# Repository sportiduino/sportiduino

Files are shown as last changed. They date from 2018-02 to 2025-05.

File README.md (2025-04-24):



Sportiduino logo

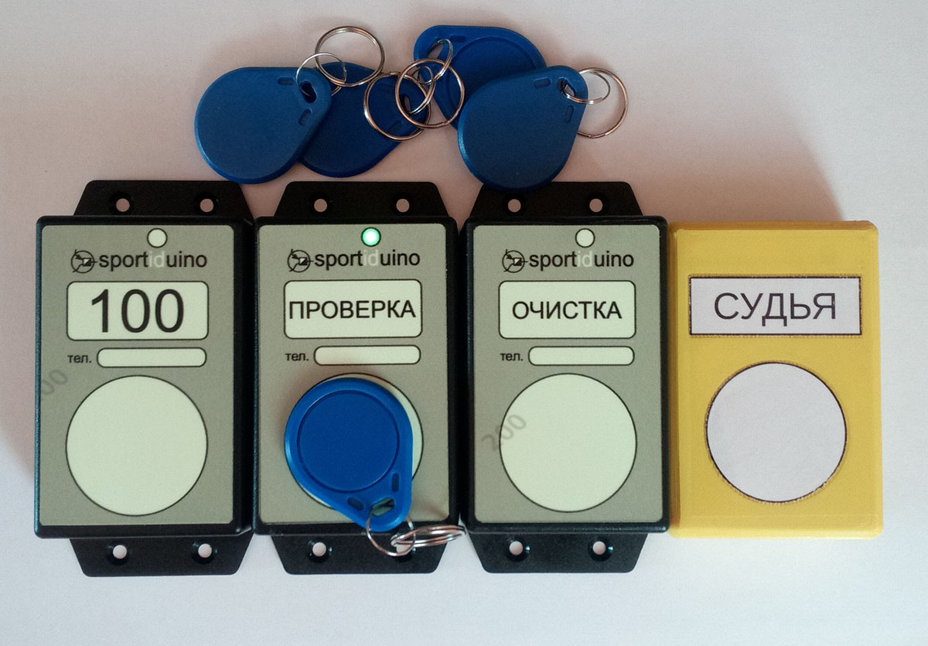
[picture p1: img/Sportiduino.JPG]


[Перейти на русский язык](README.ru.md)

The inexpensive electronic timing system for orienteering, rogaining events, adventure races, trail running and etc.
This resository contains hardware and firmware parts of the timing system.
Links to data processing software are placed [below](#software).

[Download latest release](https://github.com/sportiduino/sportiduino/releases/latest)

[Manual](/docs/en.md)

This project is open and free. Anyone can reproduce it yourself. Just follow the instructions from the Manual.

This development is a hobby.
No guarantees are given, various kinds of problems are possible during reproduction.
Support is also not guaranteed. So, act at your own risk. 

## Version

The version consists of three numbers. The first number indicates the version of the hardware.
If any changes are made to the circuit or to the PCB, this number is incremented by 1.

The second and third numbers indicates the version of the firmware.
If any new function is added to the firmware, the second number is incremented by 1.
If the firmware just fixes bugs, the third number in the version is incremented by 1.
When a new version of the firmware is released with new functions, the third number is reset to 0.

The base station and the master station have their own versions. The release version is the largest of these two numbers.

**The current base station version is 3.11.0**

**The current master station version is 1.11.0**

[Changelog](/CHANGELOG.md)

Build the firmware of the base station with `#define HW_VERS 1` to install the firmware vX.6.X or greater on the PCB v1 or v2.

## Reporting Issues and Asking for Help

Issues and suggested improvements can be posted on [Issues](https://github.com/sportiduino/sportiduino/issues) page.
Please make sure you provide all relevant information about your problem or idea.

We also have our [Telegram chat](https://t.me/Sportiduino) where you can ask any questions about the system.

## Contributing

You can contribute by writing code.
We welcome software for working with the system on a PC via USB and on Android via Bluetooth or NFC.
The data transfer protocol and commands are described in the [Manual](/docs/en/MasterStation.md).
With pleasure we will add a link to your developments working with Sportiduino.

Pull requests, creation of forks, developing any new ideas are welcome.

You can also help by improving documentation and its translation.

# Parts of the system

## Cards

The system uses cards NTAG213/215/216.
Memory of these cards can keep 32, 120 and 216 marks, respectively.

Also it is possible to use Mifare Classic 1K and 4K cards.
Cards 1K are also cheap and come bundled with the RC522 module.
The memory of these chips is enough for 42 marks. They work a little slower than NTAG.

The system automatically detects the type of used cards.

[Read more](/docs/en/Cards.md)

## Base stations

The main components of the station are the ATmega328P-AU microcontroller and the MFRC522 module,
which operates at a frequency of 13.56 MHz, real-time clock DS3231SN.
All powered by 3 AA batteries through the MCP1700T-33 stabilizer.
The capacity of the kit of three alkaline AA batteries should be enough for a year of active use.
Tested at ambient temperatures from -20 to +50 degrees Celcius.

[Read more](/docs/en/BaseStation.md)

## Master station

With the master station you can read and write tags and configure base stations.
It is simpler than the base station.
It consists of Arduino Nano, RFID module, LED and buzzer.
It connects with a PC via USB. 

[Read more](/docs/en/MasterStation.md)

There is also a wireless station with the Bluetooth module. 

## Software

### Prepare cards and stations

#### [SportiduinoPQ](https://github.com/sportiduino/SportiduinoPQ)

PC software (Windows or Linux).

It is written on Python, based on PyQt5 and [SportiduinoPython module](https://github.com/sportiduino/sportiduinoPython).

#### [SportiduinoApp](https://github.com/sportiduino/sportiduinoapp)

Android application for smartphones with NFC.

### For event management

Reading cards is implemented in [SportOrg](https://github.com/sportorg/pysport) and [SportOrgPlus](https://github.com/sembruk/sportorg-plus).

Also you can use software for SPORTident (MeOS, WinOrient, Rogain Manager etc).

***********

This system and its variants have been used in Russia at a number of events
up to approx. 1400 participants and approx. 70 check points.

***********

Available from:  https://github.com/sportiduino/sportiduino

License:         [GNU GPLv3](/LICENSE)

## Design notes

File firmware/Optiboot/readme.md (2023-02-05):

## Building Optiboot for Base station

```sh
cd <Optiboot-local-repo>/optiboot/bootloaders/optiboot

# Bootloader without LED flashes
make AVR_FREQ=8000000L BAUD_RATE=38400 LED_START_FLASHES=0 LED=D4 atmega328
mv optiboot_atmega328.hex optiboot_38400_sportiduino.hex

# Bootloader with LED starting flashes
make AVR_FREQ=8000000L BAUD_RATE=38400 LED_START_FLASHES=3 LED=D4 atmega328
mv optiboot_atmega328.hex optiboot8_38400_sportiduino_led.hex
```

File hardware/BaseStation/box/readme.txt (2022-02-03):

sportiduino-base.FCStd is FreeCAD 3D model of the Base station box for PCB v3b with Li-pol battery and 5.5x2.1mm DC power jack.

Файл sportiduino-base.FCStd — FreeCAD 3D модель корпуса базовой станции для платы v3b с литий-полимерным аккумулятором и разъёмом зарядки 5,5х2,1 мм.

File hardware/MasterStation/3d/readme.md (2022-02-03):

В папке print содержатся 3D-модели корпуса для USB судейской станции.
Данные модели предназначены для печати на 3D-принтере.
Корпус рассчитан на судейскую станцию, собранную без печатной платы.
Arduino Nano подключается к модулю RC522 проводом типа МГТФ-0.12.
Тем же проводом согласно схеме к Arduino Nano подключаются светодиод и буззер.
При сборке станции Arduino Nano крепится внутри корпуса термоклеем на соответствующие площадки.
Модуль RC522 плотно прижимается стойками корпуса и дополнительного крепления не требует. Крышки корпуса после сборки скручиваются саморезами 3.5х16.

В папке src находится проект корпуса в формате opensource редактора FreeCad.

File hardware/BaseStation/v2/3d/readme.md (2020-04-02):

This 3d-model is only to understand the placement of electronics inside a box. Use FreeCad to view. In print catalog there is a 3d model of a substrate for electronics. You can print it and use in an assembly process to fix electronics inside a box.

3д-модель сделана в опен-сорс редакторе FreeCad. Данная 3д-модель служит только для понимания расположения электроники в корпусе G1020BF и понимания как используется пространство корпуса. Эта модель не предназначена для печати на 3д-принтере. Но в папке print содержится файл подложки под модуль RC522. Эта деталь печатается на 3д-принтере. Затем она используется при сборке. Сверху на эту деталь термоклеем крепится модуль RC522. Далее эта подложка с модулем приклеивается внутри корпуса. Конструкция получается более-менее разборной. В случае если надо снять электронику, то термоклей плавится паяльным феном и электроника легко достаётся из корпуса.

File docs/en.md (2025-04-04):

# Sportiduino documentation

This project is devoted to building an electronic timing system for orienteering and similar outdoor sports events on Arduino.

The English translation is rough, there may be some unclear moments. Create an [Issue](https://github.com/sportiduino/sportiduino/issues) if you have any questions.

* [User manual](en/UserManual.md)
* [Cards](en/Cards.md)
* [Base station](en/BaseStation.md)
* [Master station](en/MasterStation.md)
* [Wireless master station](en/WirelessMasterStation.md)
* [Equipment and materials](en/Equipment.md)
* [Arduino IDE setup](en/ArduinoIde.md)
* [Base station assembly](en/BaseStationAssembly.md)
* [Master station assembly](en/MasterStationAssembly.md)
* [Software](en/DataProcessing.md)

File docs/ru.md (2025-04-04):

# Документация Sportiduino

Этот проект посвящен построению системы электронной отметки для спортивного и туристического ориентирования с помощью Arduino.

* [Руководство пользователя](ru/UserManual.md)
* [Чипы отметки](ru/Cards.md)
* [Станция отметки](ru/BaseStation.md)
* [Станция сопряжения](ru/MasterStation.md)
* [Беспроводная станция сопряжения](ru/WirelessMasterStation.md)
* [Оборудование и материалы для сборки](ru/Equipment.md)
* [Настройка Arduino IDE](ru/ArduinoIde.md)
* [Сборка станции отметки](ru/BaseStationAssembly.md)
* [Сборка станции сопряжения](ru/MasterStationAssembly.md)
* [Программы для работы с системой отметки](ru/DataProcessing.md)

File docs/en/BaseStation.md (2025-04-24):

# Base station

### Scheme

The main components of the station: microcontroller ATmega328P-AU, RFID module RC522, real-time clock DS3231SN.
It is powered by 3 x AA batteries via the MCP1700T-33 linear regulator.
The scheme and PCB are made in KiCad program.

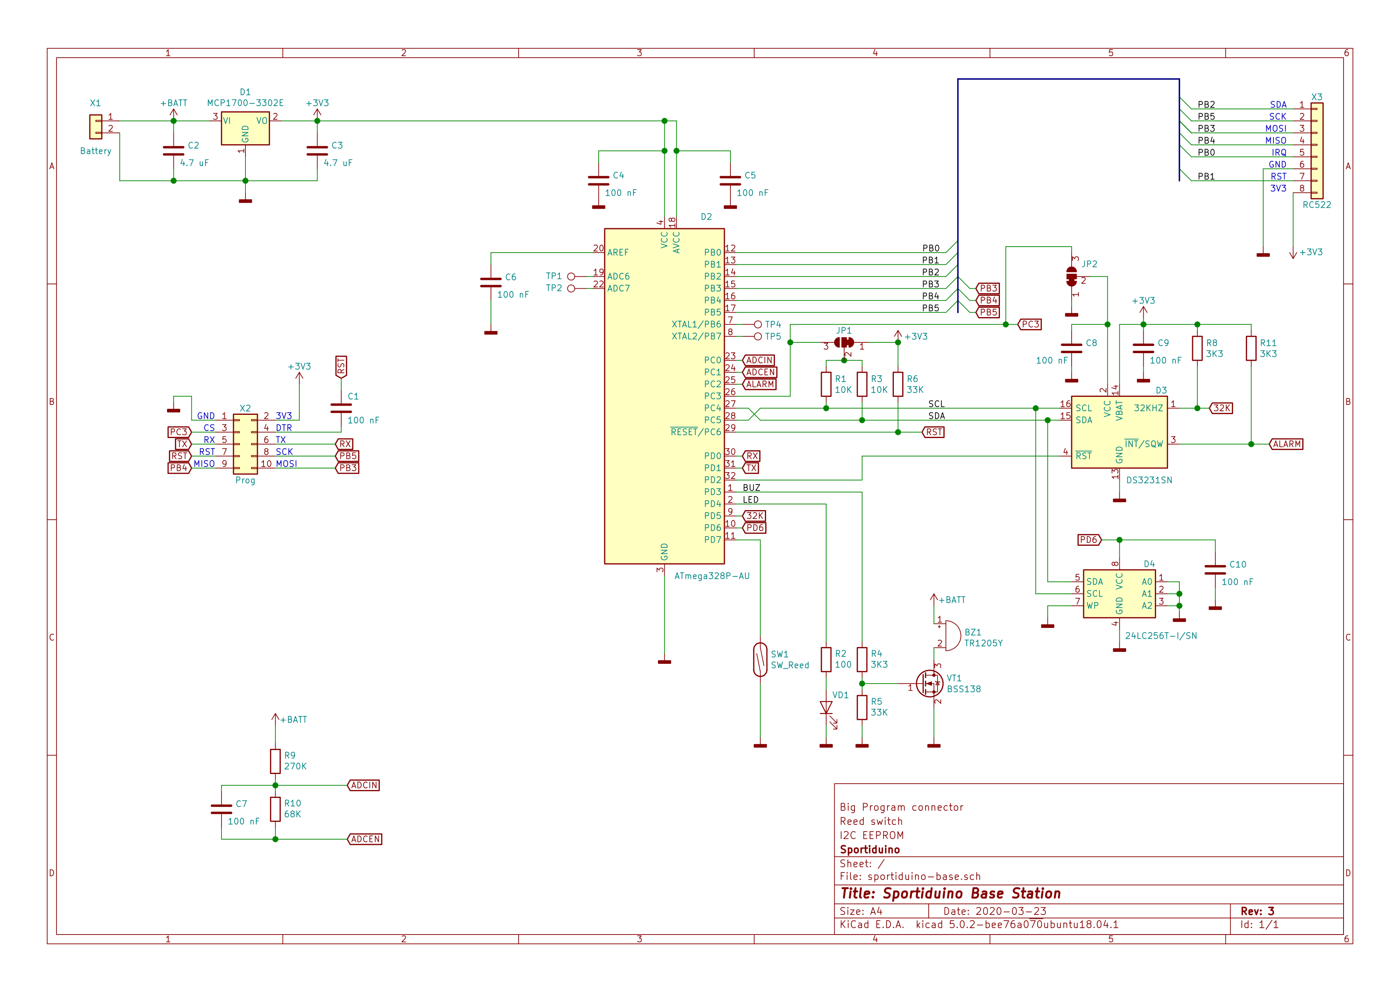
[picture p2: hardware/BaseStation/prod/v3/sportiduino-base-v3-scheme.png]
Scheme


The components are mounted on a printed circuit board.
Connection with an RFID board is via soldered connection with a pin connector.
You can order the manufacture of PCB in China (e.g. [JLCPCB](https://jlcpcb.com/)).

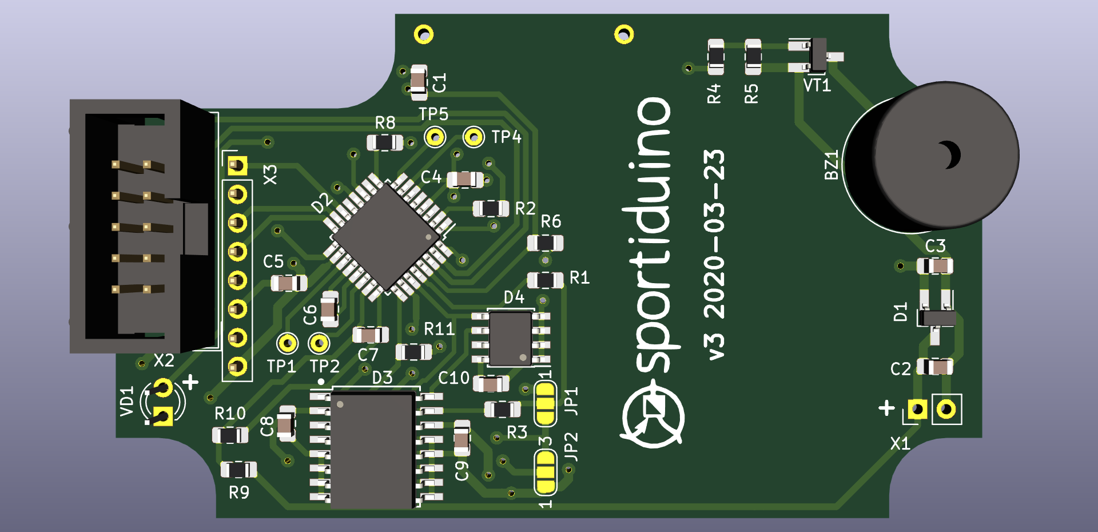
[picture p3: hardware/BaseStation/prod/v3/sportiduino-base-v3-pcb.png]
PCB


To upload firmware to the station one needs another Arduino with ArduinoAsIsp firmware or any 
AVR microcontroller programming device such as Pickit2.

The outer shell is G1020BF.
Moisture protection is achieved by covering all the PCB electronics with a liquid silicone compound.

About the assembly and the initial setting of the station written in [the assembly manual](BaseStationAssembly.md).

### Consumption

By default the station starts in Wait (standby) mode.
In this case, the cards are read once per second.
Total consumption is up to 0.5 mA.
Fully charged batteries last for 160 days.
While RFID module is powered up to 20 mA (up to 40 mA during the read-write) is consumed.

After the first card is brought (by the station installer or the first athlete),
the station goes into the Active mode.
By default after 2 hours of inactivity it returns to the Wait mode.
The time in Active mode can be changed using the Config card.

In the Active mode standby occurs every 250 ms.
Thus during operation an integral consumption of about 1.7 mA can be expected.
Fully charged batteries last for 45 days of continuous operation.

To reduce consumption while waiting for the competition, the Sleep mode is implemented.
Consumption is about 15 µA.
Fully charged batteries last for 5 years.
To achieve this, on the RFID board the LED and pull-up resistors must be accurately removed (see [Base Station Assembly](BaseStationAssembly.md)).

### Initial setting

Station is configured by Master cards (any card can be written as a Master card) or by USB-to-TTL converter.

[More details in the User manual](UserManual.md).

### Station operation algorithm

After power on or reboot the station checks the internal clock setup.
If it is incorrect, it beeps accordingly (see below).
Then it loads from EEPROM the settings (station number, password, etc.).
Then the battery charge is checked.
LED is powered for 3 seconds.
If the charge level is ok or low, it beeps accordingly (see below).
After the init stage the station enters the Wait mode.
In the Wait mode the station wakes up every second and searches for a card (RFID tag).
When a card is found, it goes into Active mode with a card polling every 0.25 seconds.
At the card punch, the station reads the first card block, where the card number or the master card code is stored. 
If it is a master card, its instruction is being processed.
If the card is normal, then the last recorded page is searched for (using binary search) 
and the station number is read from the last record.
If the station number is the same, the station beeps twice.
If the number is different, then the punch is written to the next block after the recorded one.
If successful, the station signal (a beep and a LED blink),
and also records the fact of the punch in the internal EEPROM memory of the station (into the bit corresponding to the card number).
If the station PCB has EEPROM IC, the punch is written in one.

Search and record time depend on the card volume:

- 32 marks - 60 .. 120 ms
- 64 marks - 60 .. 140 ms
- 120 marks - 60 .. 160 ms
- 220 marks - 60 .. 180 ms

Factor in the Wait or Active mode delay - up to 1000 or 250 ms accordingly.

A Fast Punch mode exists.
The last station number is always recorded into the sixth page on a card.
It reduced the card lifetime.

During operation, a watch-dog is running which restarts the station should the system hang up.

### Station configuration 

Using the Config master card, you can set:

- the duration of the Active mode,
- Start as Check mode,
- checking the initialization time of the cards,
- Fast Punch mode,
- antenna gain,
- password.

With Start as Check mode, the Start station (number 240) will only accept cleared cards.

By default all special modes are disabled, the password is 0-0-0.

### The Clearing station

This station clears cards.
To set up the station as Clearing station, you need to specify station number 249.
This station clears all pages of the card except the page with the card number.
The new time is recorded in the initialization time page
which is used to calculate the results, so it is important that the time at the station is correct.

When the card is presented, the LED lights up on the station and blinks during the cleaning (about 4 seconds).
If the cleaning is successful, the station beeps, the LED goes out, the card needs to be removed.
If there was no signal, the cleaning was not completed, you need to repeat the procedure.

### The Check station

To set up the station as the Check station, you need to specify station number 248.
This station does not write any data to the card but only checks it.
If the card contains punches or the time of initialization exceeds the time at the station for more than a month
the station does not beep.
If everything is ok then it beeps once.
The time of checking is approximately the same as the time of punching, so participants can practice the punching at this station.

### Password system

A password system is used to protect against unauthorized resetting of installed stations.

The password consists of three numbers from 0 to 255 (three bytes).
The default password is 0-0-0.
All master cards work only with the correct password in the first data block.
A Config master card is used to send the password to the base station.
The password is stored in the EEPROM memory.

### Signals

Errors:

| Repetitions | Duration in ms | Meaning |
| --- | --- | --- |
| 2 |  80 | DS3231 broken or not connected
| 3 | 100 | The clock is not right
| 4 | 100 | The master card password is wrong
| 5 | 100 | The battery is low
| 4 |  50 | Unknown master card
| 2 | 250 | Master card error
| 2 | 250 | Serial error

Normal behavior:

| Repetitions | Duration in ms | Meaning |
| --- | --- | --- |
| 1 | 1000 | Battery is ok
| 1 |  500 | Card punching, clearing or checking is ok
| 2 |  250 | Card is already punched
| 1 |  250 | Master card read
| 4 |  500 | Sleep mode is enabled
| 1 |  250 | Serial is ok

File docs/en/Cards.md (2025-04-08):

# Cards

The system supports these cards (RFID tags):

- [Mifare Ultralight C](http://www.nxp.com/documents/data_sheet/MF0ICU2.pdf) for 36 punches
- [Mifare Classic 1K](https://www.nxp.com/docs/en/data-sheet/MF1S50YYX_V1.pdf) for 42 punches
- [Mifare Classic 4K](https://www.nxp.com/docs/en/data-sheet/MF1S70YYX_V1.pdf) for 90 punches 
- [NTAG213/215/216](https://www.nxp.com/docs/en/data-sheet/NTAG213_215_216.pdf) for 32/120/216 punches

Card type is detected automatically.
One station can work with various cards simultaneously
without any changes in firmware or hardware.

One is advised to use NTAG213/215/216.

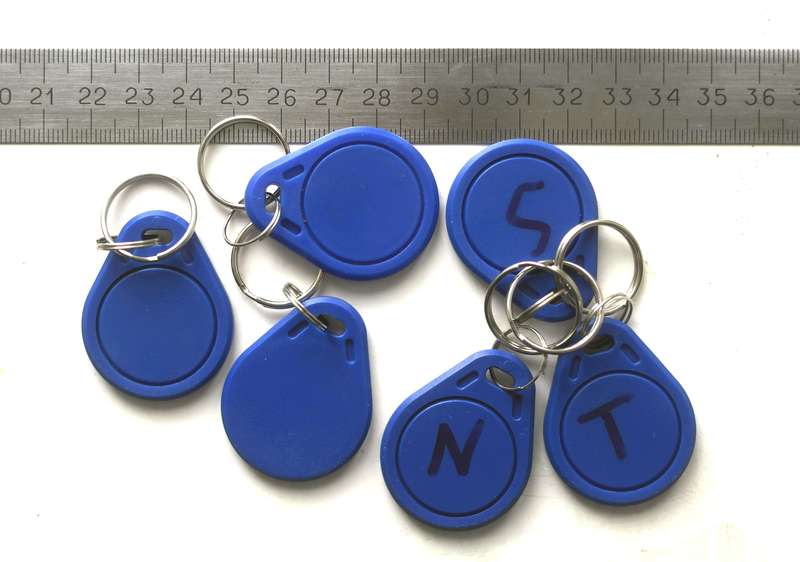
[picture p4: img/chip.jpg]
Key fobs tags


**Important!**
For reliable operation with these cards which have a small antenna area
it is necessary to replace the inductors with the more powerful ones in the RFID RC522 module (see [Base station assembly](BaseStationAssembly.md)).

Mifare Classic 1K cards come bundled with the RC522 module.
The memory of these cards is enough for 42 marks. They work a little slower than NTAG. 
Only a quarter of the Mifare cards memory is used due to page size of 16 bytes (compared with 4 bytes for NTAG).
With more dense recording there is a risk of data loss.
The structure of the record is similar to NTAG.

The memory of the NTAG213/215/216 cards is structurally divided into 45/135/231 pages, each containing 4 bytes.
The first 4 pages contain UID and other service information.
Also the service information is contained in the last 5 pages.
Thus, 36/126/222 pages are available.

### The structure of the records

Page numbers start from 0.
Pages 4-7 are reserved, the rest of the pages are for the punches.
In the 4th page, the first two bytes contain the programmable card number.
In the 4th byte, the station firmware version (e.g. 8 for v3.8.0, 9 for v3.9.1).
On the 5th page, the initialization time of the card in Unixtime UTC format.
Then two pages are reserved.
Each station punch takes a separate page,
the first byte of which contains the station number, in the remaining three bytes - the lower bytes of the current time in Unixtime UTC.
Time is then restored using the initialization time recorded in the 5th page.

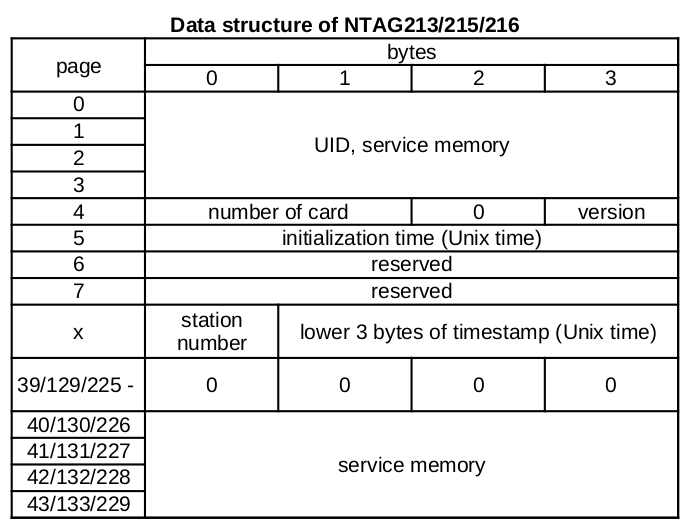
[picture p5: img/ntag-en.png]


Master cards which set up the stations have a different structure.
The station recognizes them by the number 255, recorded in the 3rd byte of the 4th page.
There are 8 different master cards: Time, Number, Sleep, Config, Password, Auth password, Backup and State.
Their structure is below.

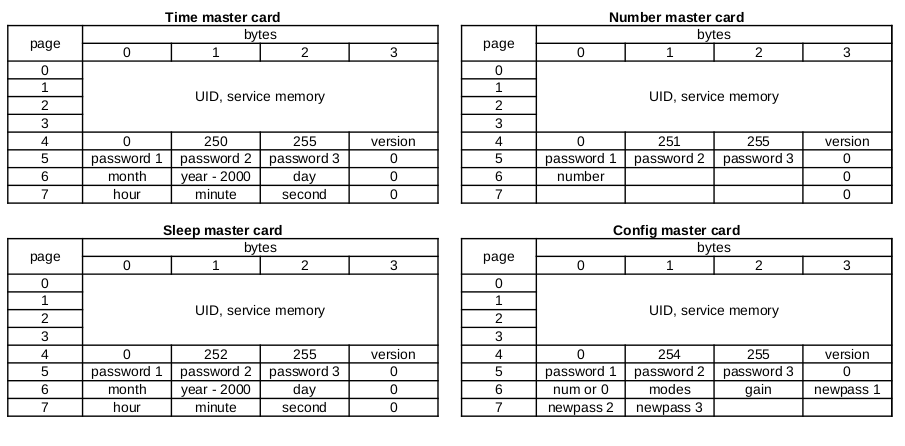
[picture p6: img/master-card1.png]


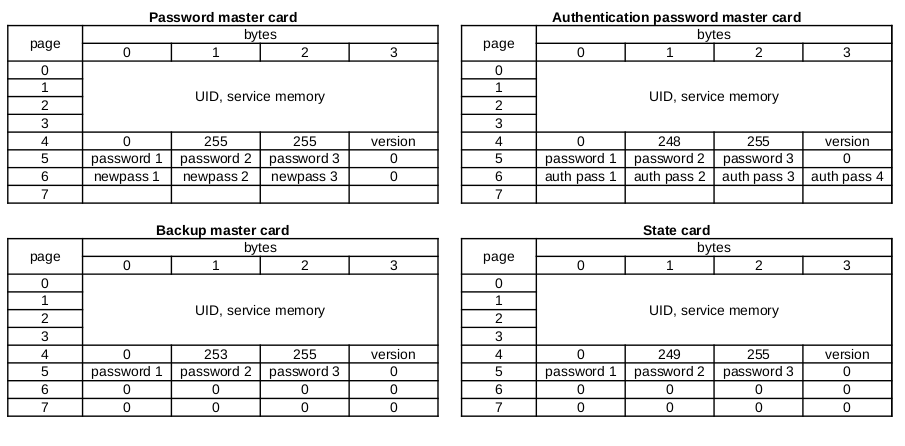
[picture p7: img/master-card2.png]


#### Time Master Card

Writes the date and time to the station (in real time clock).

This card is one-shot.
After reading information from the card, page 4 is erased on it
to prevent accidental reuse.

#### Number Master Card

Writes the number to the station if it is greater than 0.

This card is one-shot.

#### Sleep Master Card

Writes the date and time of waking up to the station and puts it into Sleep mode.
When waking up by timer, the station goes into active mode.

This card is reusable.

#### Config Master Card

Writes the number (if > 0), settings byte, antenna gain (if ≥ 2 and ≤ 7) and new password to the station.

This card is reusable.

#### Password Master Card

Writes the new password to the station.

This card is reusable.

#### Authentication Password Master Card

Writes the password (4 bytes) for Ntag authentication to the station.

This card is reusable.

#### Backup Master Card

The station writes a log of punches to this card.
If the station saves a log with time stamps, then a log for the last 12 days is recorded in ascending order of card numbers.
Since the capacity of the card may not be enough to record the entire time-stamped log.
Then for a complete reading of the log, it is necessary to attach the card to the station several times with an intermediate reading of the contents of the card.

This card is reusable.

#### State Master Card

The station writes to this card:
- firmware version number (3 bytes) to page 4;
- station number, settings byte, antenna gain in page 5;
- battery voltage (mV / 20, 1 byte) and mode (1 byte) in page 6;
- current time in Unix format to page 7;
- wake-up time in Unix format to page 8;

This card is reusable.

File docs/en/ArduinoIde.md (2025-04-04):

# Arduino IDE setup

### Setup location for sketches and url for boards manager

In the menu `Arduino IDE->Preferences` change sketchbook location to `[/path/to/project]/firmware`.

Then add new additional boards manager url
`https://raw.githubusercontent.com/sportiduino/BoardsManagerFiles/master/package_sportiduino_index.json`

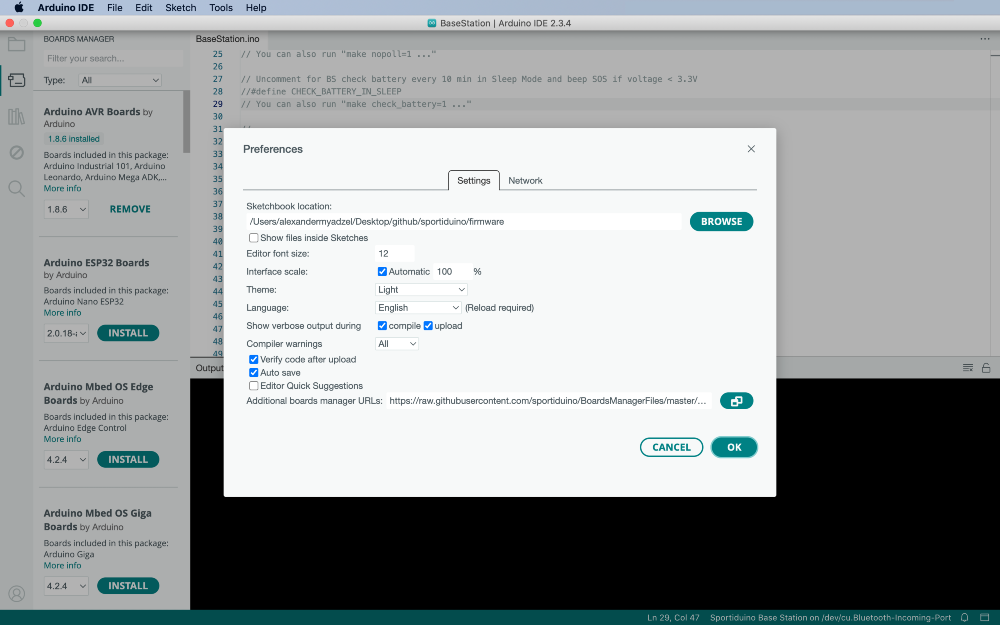
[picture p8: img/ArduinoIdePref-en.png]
Preferences


### Install boards

Select `Boards Manager` in the left panel and type `sportiduino` in the search bar.
Click `Install`.

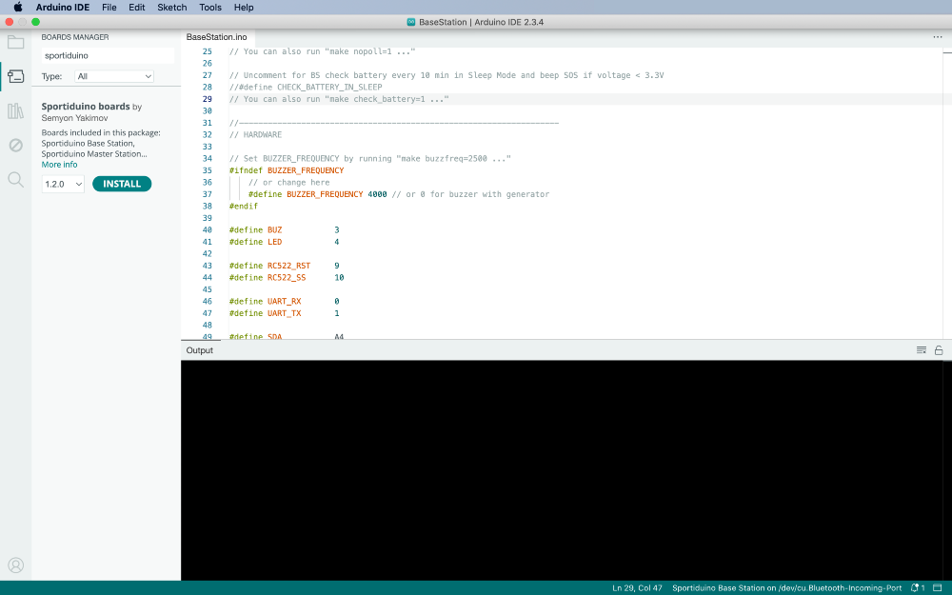
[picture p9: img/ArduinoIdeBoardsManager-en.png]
Boards manager


### Select board to upload firmware

In the menu `Tools` for the base station, select the "Sportiduino Base Station" board.
For the master station, select the "Sportiduino Master Station (Arduino Nano)" board.

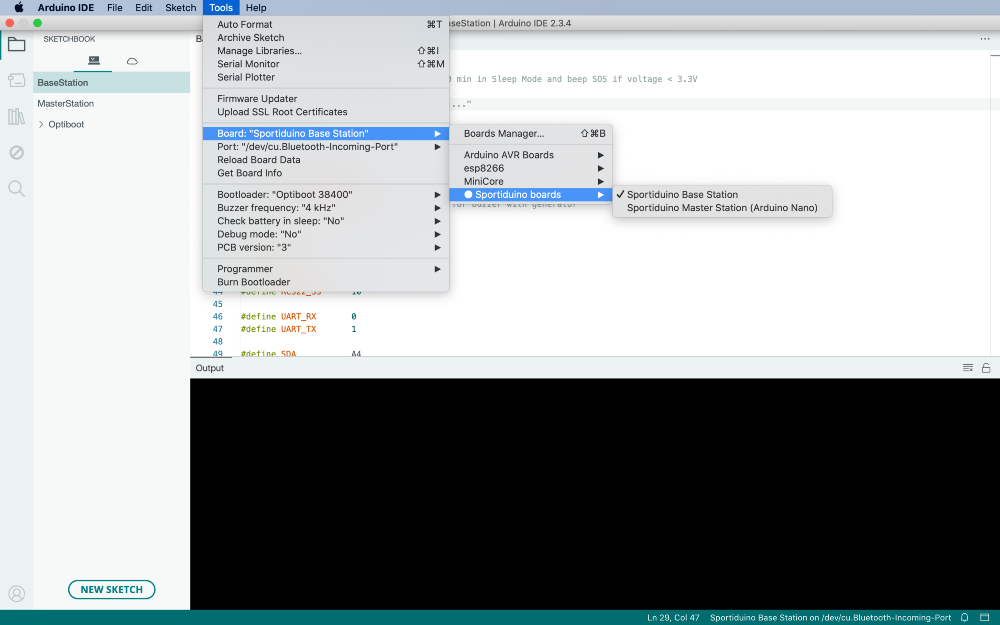
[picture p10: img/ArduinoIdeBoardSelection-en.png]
Board selection


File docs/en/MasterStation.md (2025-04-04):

# Master station

The Master station can be made in various boxes.

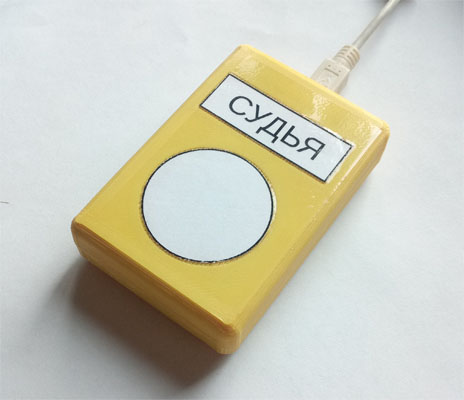
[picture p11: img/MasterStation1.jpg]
Master station in the box made on a 3D printer


or

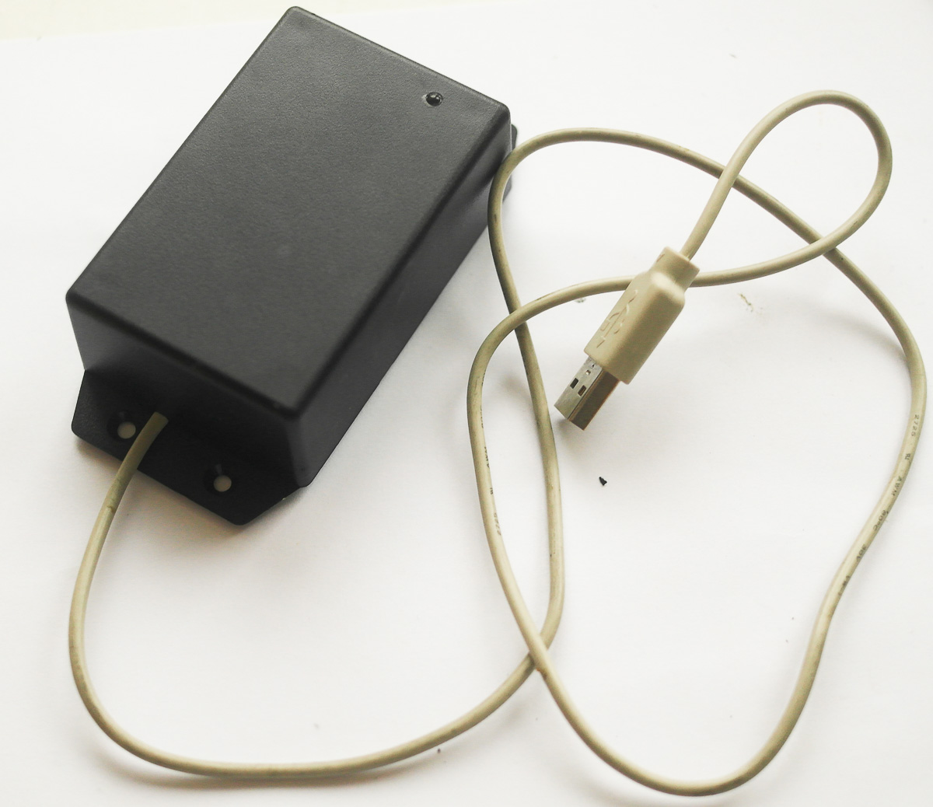
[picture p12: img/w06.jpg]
Master station in the G1020BF box


The circuit and board are available in Upverter ([variant 1](https://upverter.com/AlexanderVolikov/3fc0efdb2586988d/Sportiduino-reading-stantion/) or [variant 2](https://upverter.com/design/syakimov/4f7ec0e2d3b9c4e9/sportiduino-master-station/)).

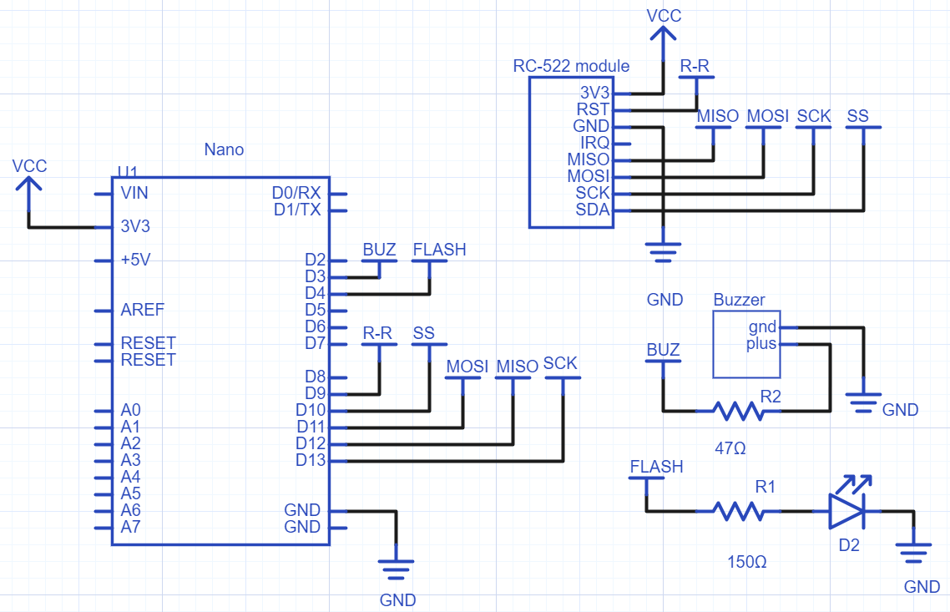
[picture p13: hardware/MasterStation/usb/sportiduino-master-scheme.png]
Scheme


All components of the circuit can be placed on a PCB or soldered to the Arduino by a ordinary wires.
The electronics of the master station can be placed in the Gainta G1020BF box or in a specially designed box that can be printed on a 3D printer.
[More about the assembly](MasterStationAssembly.md).

The station is connected to the computer using a USB port.
The Arduino Nano already has a built-in Serial-to-USB converter, so no additional converters are needed.
The station will be displayed in the connected devices as a COM port or /dev/ttyUSBx in Linux.

### Serial data protocol

The transmission of information between PC and Master Station occurs sequentially by sending up to 32-byte packets.

| | Value | Byte address in the packet |
| --- | --- | --- |
| Start | 0xFE | 0 |
| Function | | 1 |
| The length of the data or packet number + 0x1E | | 2 |
| Data array | | 3..x (x<31) |
| Checksum | x+1 |

The packet starts with byte 0xFE.

The command is specified by the byte with address 1.
Then in byte 2 the data length follows, if the transmitted packet is the last packet or its number + 30, if multipacket transmission is in progress.

Next comes an array of transmitted data up to 28 bytes.

At the end of the packet contains a checksum: the remainder of dividing by 256 the sum of bytes 1..x.
Commands pass only with the correct value of the checksum and start byte.

#### List of commands sent to the station

| Code | Command | Length | Array of data bytes (offset) |
| --- | --- | --- | --- |
| 0x41 | Write the time to the master card | 6 | year-2000 (0), month (1), day (2), hour (3), minute (4), second (5)
| 0x42 | Write the station number to the master card | 1 | number (0)
| 0x44 | Initialize the card | 14 | card number (0-1), current time (2-5), information in 6-7 pages (6-13)
| 0x45 | Write 6,7 pages | 8 | 6-7 pages data (0-7)
| 0x46 | Ask version of the master station | 0 |
| 0x47 | Create Backup master card | 0 |
| 0x48 | Read the Backup master card | 0 |
| 0x4A | Write settings to the master station | 1 | antenna gain (0)
| 0x4B | Read the card | 0 |
| 0x4C | Read raw data from the card | 0 |
| 0x4D | Read settings of the master station | 0 |
| 0x4E | Write a Sleep master card | 6 | year-2000 (0), month (1), day (2), hour (3), minute (4), second (5)
| 0x4F | Set the current password | 3 | password (0-2)
| 0x50 | Create State master card | 0 |
| 0x51 | Read card type | 0 |
| 0x58 | Beep error (three short beeps) | 0 |
| 0x59 | Beep OK (long beep) | 0 |
| 0x5A | Create Config master card | 6 | base station configuration

#### List of station responses

| Code | Command | Length | Array of data bytes (offset) |
| --- | --- | --- | --- |
| 0x61 | Data from Backup master card | N packages | (the first packet is the station number (0)), the number of the marked card 1 (1-2), the number of the marked card 2 (3-4), etc.
| 0x63 | Card punches data | N packages | (the first package - the card number (0-1), information in the 6-7 pages of the card (2-9),) number CP0 (10), time CP0 (11-14), number CP1 (15), time CP1 (16-19), etc.
| 0x65 | Raw data from the card | N packets | page number 4 (0), page 4 bytes (1-4), page number 5 (5), page bytes 5 (6-9), etc.
| 0x66 | Version of the master station firmware | 3 | version (0-2)
| 0x67 | Setting of the master station | 1 | antenna gain (0)
| 0x70 | Card type | 1 | card type(0)
| 0x78 | Error | 2 | error code (0), card type (1)
| 0x79 | OK | 1 | card type (0)

#### Error Codes

| Code | Error |
| --- | --- |
| 0x01 | Serial communication error
| 0x02 | Card writing error
| 0x03 | Card reading error
| 0x04 | EEPROM reading error
| 0x05 | Card not found
| 0x06 | Unknown command

### SPORTident emulation

Firmware of Master station v1.8.0 or greater has support of reading card by the SPORTident data transfer protocol.
All RFID tags are read as SI-Card (192 punch mode).
Communication tested with SPORTident Reader, Rogain Manager, SportOrg, MeOS 3.8.1277 and WinOrient 2.0a (2014 - 2020) software.

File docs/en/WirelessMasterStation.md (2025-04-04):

# Wireless master station

A wireless master station is implemented in the system. Schematic diagram and board is in [Upverter](https://upverter.com/AlexanderVolikov/55b140a993222192/Sportiduino-BTstantion/).

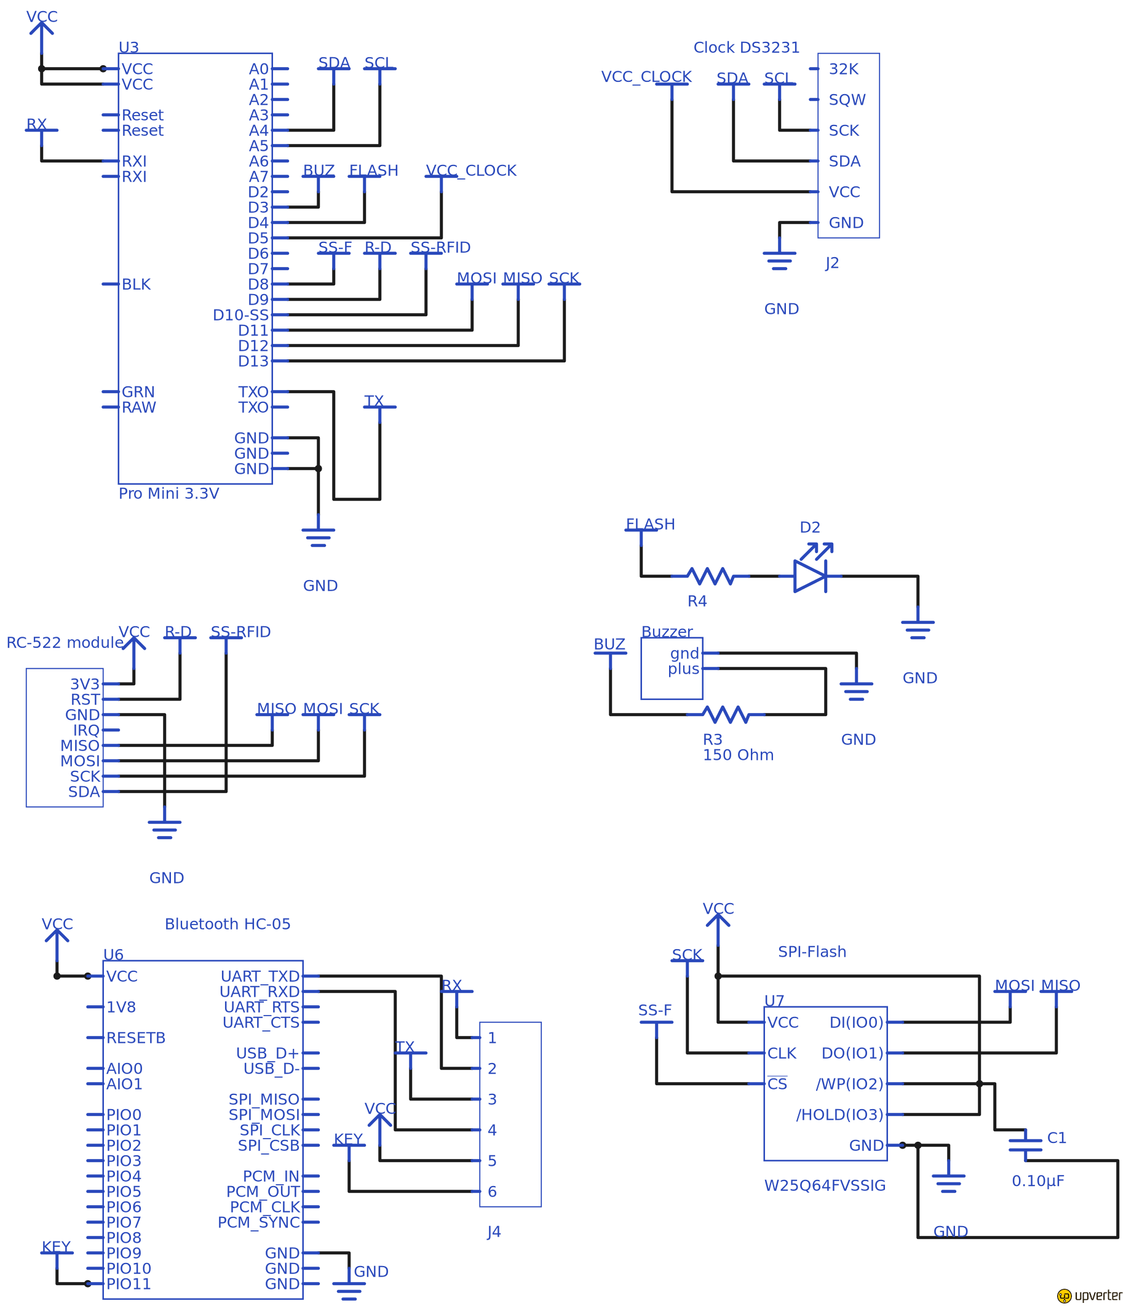
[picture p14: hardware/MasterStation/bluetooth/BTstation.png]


The circuit uses Arduino Pro mini, DS3231, RC522 and Bluetooth HC-05 boards.
In addition, there is space for SPI-flash memory, in this repository it is not used and the space can be left blank, but if someone wants to implement additional functionality, you can use this memory.
Similarly, the DS3231 clock is not used and their space can be left blank.

Gerber for ordering the board is placed in the [`hardware/MasterStation/bluetooth`](https://github.com/sportiduino/sportiduino/tree/master/hardware/MasterStation/bluetooth).

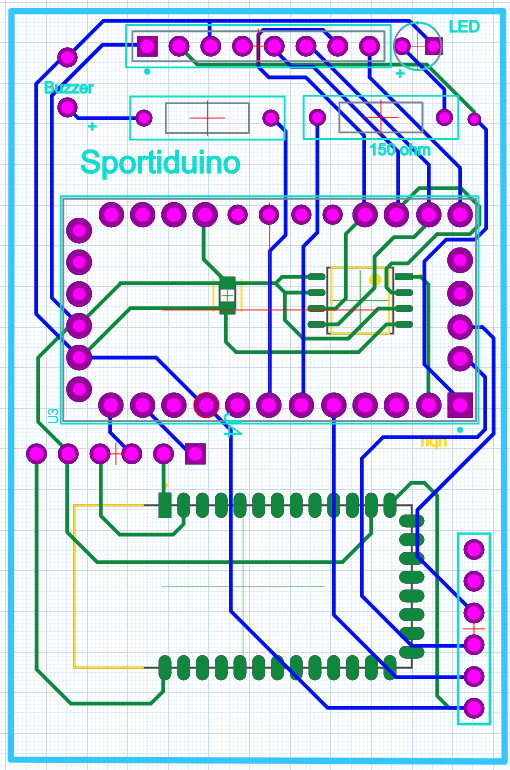
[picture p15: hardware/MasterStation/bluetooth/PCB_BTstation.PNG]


The principle work of the station does not differ from a regular master station,
but the data exchange is via Bluetooth, which allows you to implement the work with the system through Android devices.

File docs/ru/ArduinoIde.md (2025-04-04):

# Настройка Arduino IDE

### Настройка путей для скетчей и менеджера плат

В меню `Файл->Настройки` изменяем размещение папки скетчей на `[Проект]/firmware`.

Далее добавляем в `Дополнительные ссылки для Менеджера плат` после запятой строку
`https://raw.githubusercontent.com/sportiduino/BoardsManagerFiles/master/package_sportiduino_index.json`

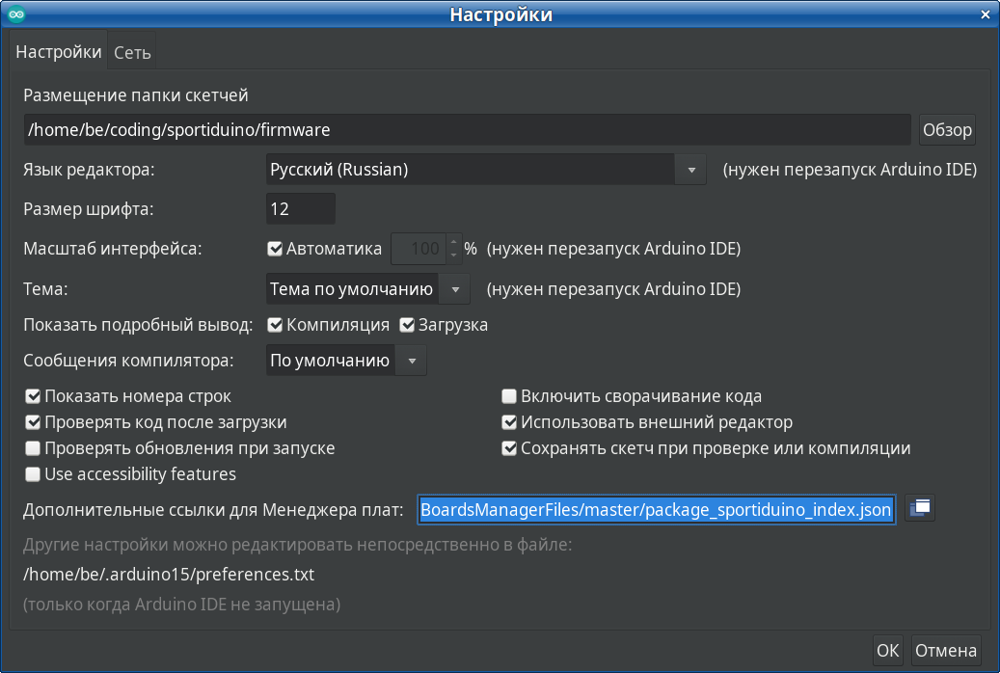
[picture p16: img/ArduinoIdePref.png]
Настройка Arduino IDE


### Установка плат

Открываем `Инструменты->Плата:[...]->Менеджер плат...` и вводим в поиске `sportiduino`.
Нажимаем `Установка`.

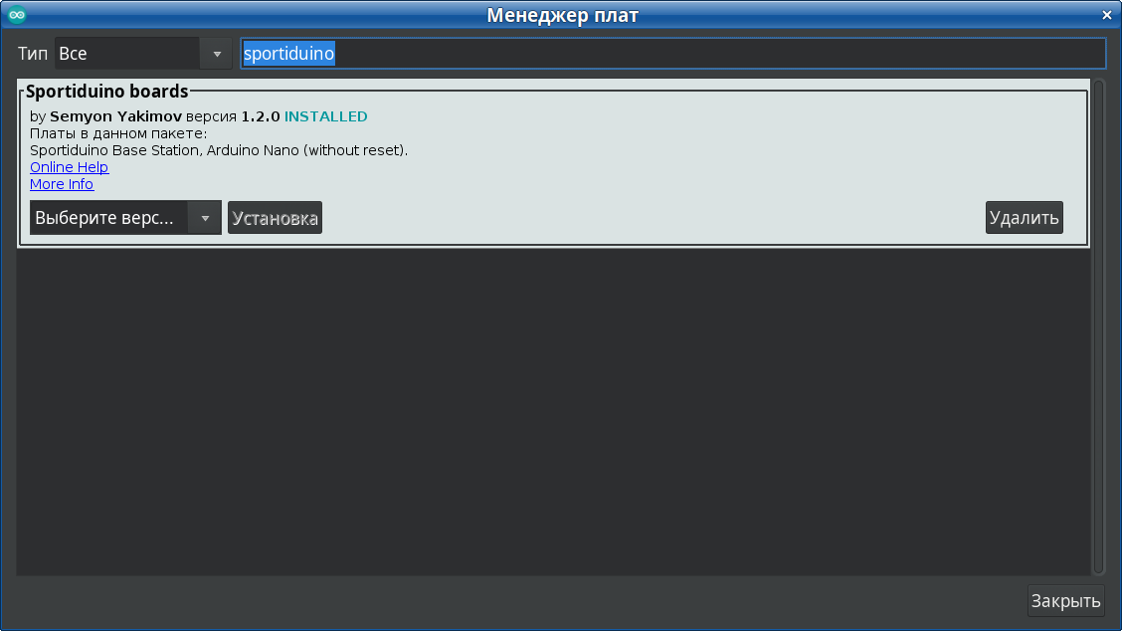
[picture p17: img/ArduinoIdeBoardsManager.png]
Менеджер плат


### Выбор платы для загрузки прошивки

Для станции отметки выбираем плату "Sportiduino Base Station".
Для станции сопряжения выбираем плату "Sportiduino Master Station (Arduino Nano)".

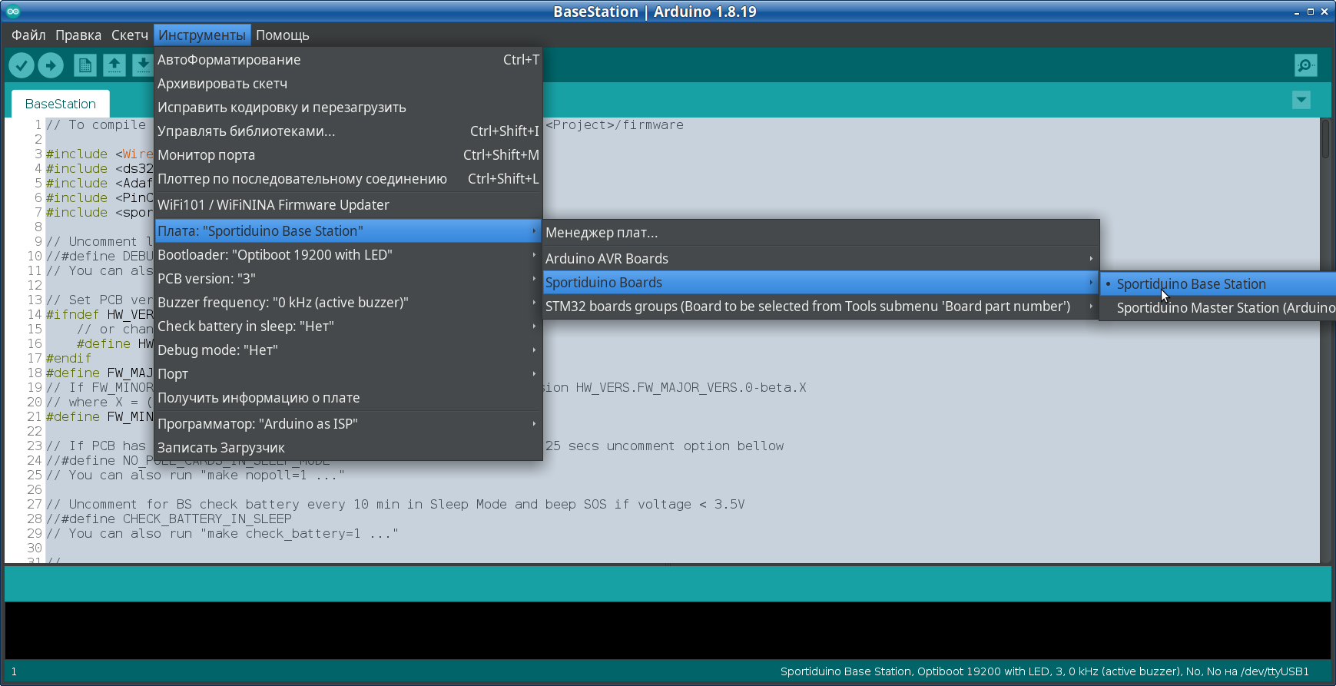
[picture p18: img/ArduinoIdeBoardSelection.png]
Выбор платы


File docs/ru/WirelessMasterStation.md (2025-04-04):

# Беспроводная станция сопряжения

В системе реализована беспроводная станция сопряжения. Принципиальная схема и плата есть в [Upverter](https://upverter.com/AlexanderVolikov/55b140a993222192/Sportiduino-BTstantion/).



В схеме используются модули Arduino Pro mini, DS3231, RC522 и Bluetooth-плата HC-05. Дополнительно есть место для SPI-flash памяти, в данном репозитории она никак не используется и место можно оставить пустым, но если кто-то хочет реализовать дополнительный функционал, можно задействовать эту память. Аналогично, часы DS3231 не задействованы и их место можно оставить пустым.

Gerber-файлы для заказа платы находятся в директории [`hardware/MasterStation/bluetooth`](https://github.com/sportiduino/sportiduino/tree/master/hardware/MasterStation/bluetooth).



Принципиальная работа данной станции не отличается от обычной станции сопряжения, но обмен данных осуществляется через Bluetooth, что позволяет реализовать работу с системой через Android-устройства. Сборка осуществляется, в основном, навесным монтажом и не представляет сложности.

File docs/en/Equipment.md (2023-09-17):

# Equipment and materials

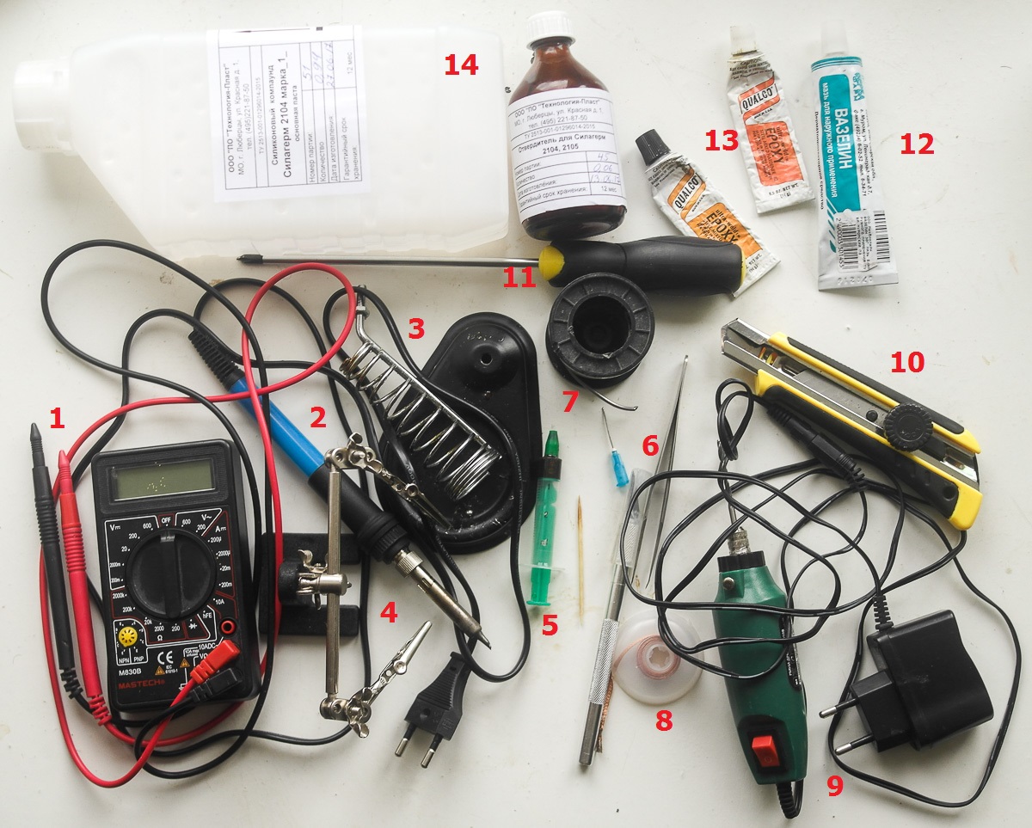
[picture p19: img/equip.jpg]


1. The multimeter. Optional.

2. Soldering iron with temperature regulator or soldering station (e.g. 8586).

3. Stand for soldering iron.

4. "The Third Hand" tool. It is necessary to solder SMD elements.

5. Flux and brush. It is recommended fluxes for SMD (RMA-218, NC-559).

6. Tweezers (is required for soldering small parts), the cut off needle from under a syringe for cleaning the hammered holes, a knife.

7. Solder Sn63Pb37.

8. Braid to remove excess solder, as well as to strip the board in case of resoldering individual elements.

9. Drill, 3 mm for the hole for the LED.

10. Stationery knife for cutting the box.

11. Phillips screwdriver for twisting the box.

12. Vaseline to smear contacts in the battery box against corrosion. Optional.

13. Epoxy adhesive for gluing the LED.

14. Silicon compound. Optional.

To upload bootloader, you will additionally need another Arduino (Nano) or programmer Pickit2.

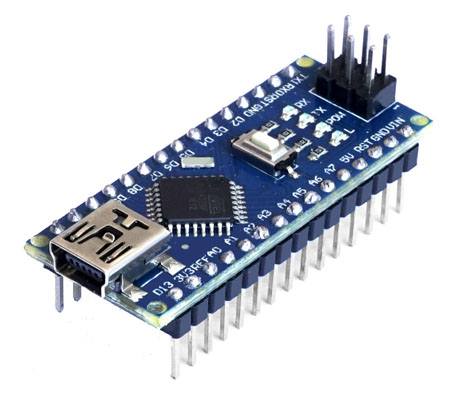
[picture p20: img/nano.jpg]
Arduino Nano


To upload the firmware you need USB-UART converter (USB-to-TTL, USB-SERIAL, etc.).
It is important that one has connected DTR pin (USB-UART with ICs CH340 or CP2102).

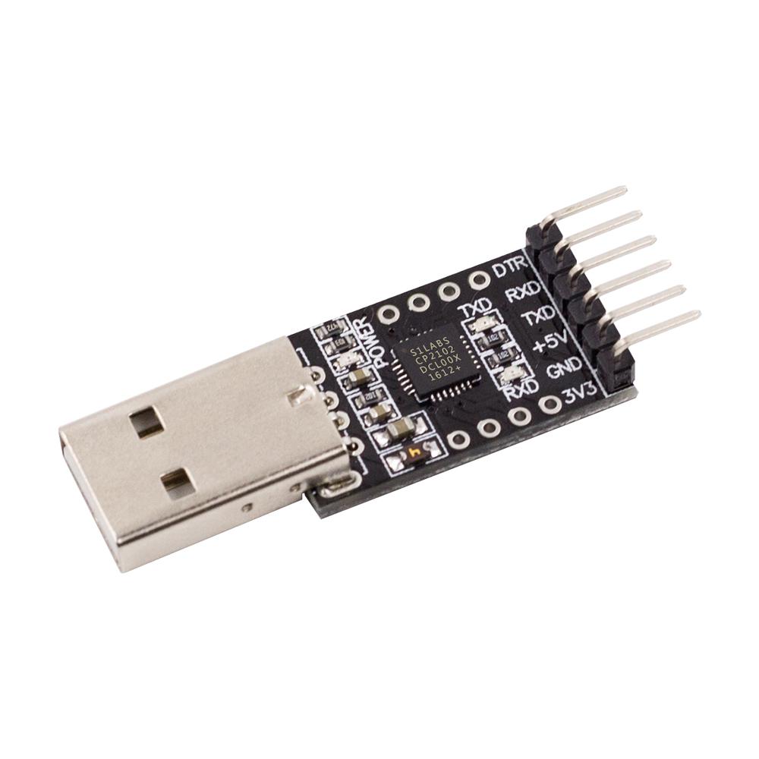
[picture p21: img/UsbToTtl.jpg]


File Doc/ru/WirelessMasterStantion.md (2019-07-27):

В системе реализована беспроводная станция сопряжения. Принципиальная схема и плата есть в [Upverter](https://upverter.com/AlexanderVolikov/55b140a993222192/Sportiduino-BTstantion/)



В схеме используются модули Arduino Pro mini, DS3231, RC522 и Bluettoth плата HC-05. Дополнительно есть место для SPI-flash памяти, в данном репоизитории она никак не используется и место можно оставить пустым, но если кто-то хочет реализовать дополнительный функционал, можно задействовать эту память. Аналогично, часы DS3231 не задействованы и их место можно оставить пустым.

Гербер для заказа платы находит в подпапке bluetooth. Выглядит плата следующим образом:



Принципиальная работа не отличается от простой станции сопряжения, но обмен данных осуществляется через Bluetooth, что позволяет реализовать работу с системой через Android устройства. Сборка осуществляется, в основном, навесным монтажом и не представляет сложности.

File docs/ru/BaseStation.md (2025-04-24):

# Станция отметки

### Варианты станции отметки

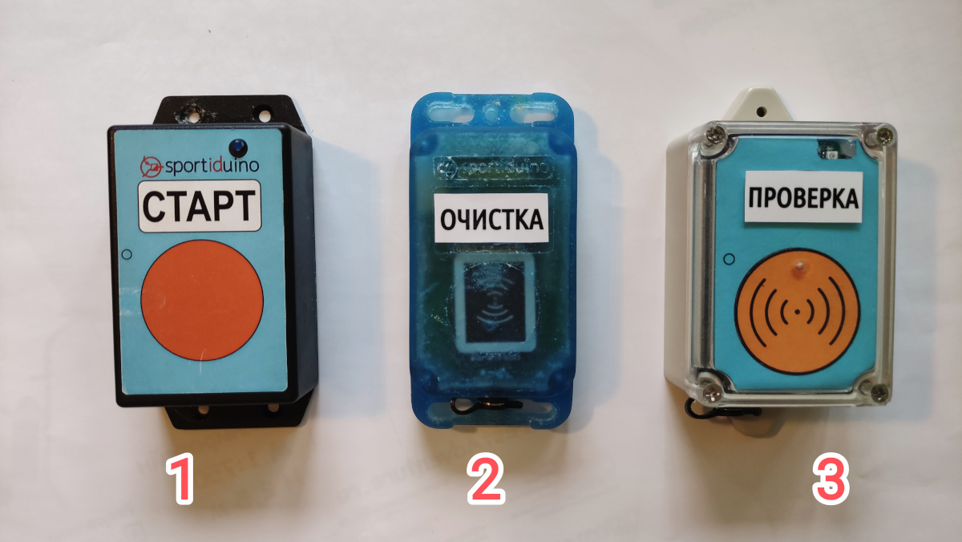
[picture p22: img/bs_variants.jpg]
Варианты станции отметки


#### Станция в корпусе G1020BF (номер 1 на рисунке)

Плата v1, v2, v3 или v3b.
Питание от 3-х батареек АА (ААА), либо литий-полимерного аккумулятора.
Если планируется использовать аккумулятор, то в корпус для плат v1-v3 необходимо установить и подключить плату зарядки
на микросхеме TP4056 (в версии v3b микросхема зарядки уже интегрирована в плату), а также разъём для зарядки 5.5х2.1.

#### Станция в оригинальном корпусе (номер 2 на рисунке)

Плата v3b.
Питание от литий-полимерного аккумулятора емкостью 800-950 мАч (например, 603443 или Robiton&nbsp;LP683440 900 мАч).
Разъём зарядки — 5.5х2.1.

[3D модель корпуса.](/hardware/BaseStation/box/sportiduino-base.FCStd)

Корпуса производятся методом литья в силиконовые формы.
Проверенный двухкомпонентный пластик для литья — Smooth-On&nbsp;TASK&nbsp;9.
Силикон для форм — Полидел&nbsp;MOLD&nbsp;S20.

#### Станция в китайском корпусе 85x58x33 (номер 3 на рисунке)

Плата v3b.
Питание от литий-полимерного аккумулятора емкостью 800-950 мАч (например, 603443 или Robiton&nbsp;LP683440 900 мАч).
Разъём зарядки — 5.5х2.1.
Рекомендуется заменить болты крепления крышки на нержавеющие (подойдут с резьбой М3, длиной 16 мм и диаметром шляпки не более 5,5 мм).

### Схема и монтаж

Основные компоненты станции отметки: микроконтроллер ATmega328P-AU, RFID-модуль RC522-mini или RC522, часы DS3231SN.
Питание через линейный стабилизатор MCP1700T-33.
Схема и плата выполнены в программе KiCad.

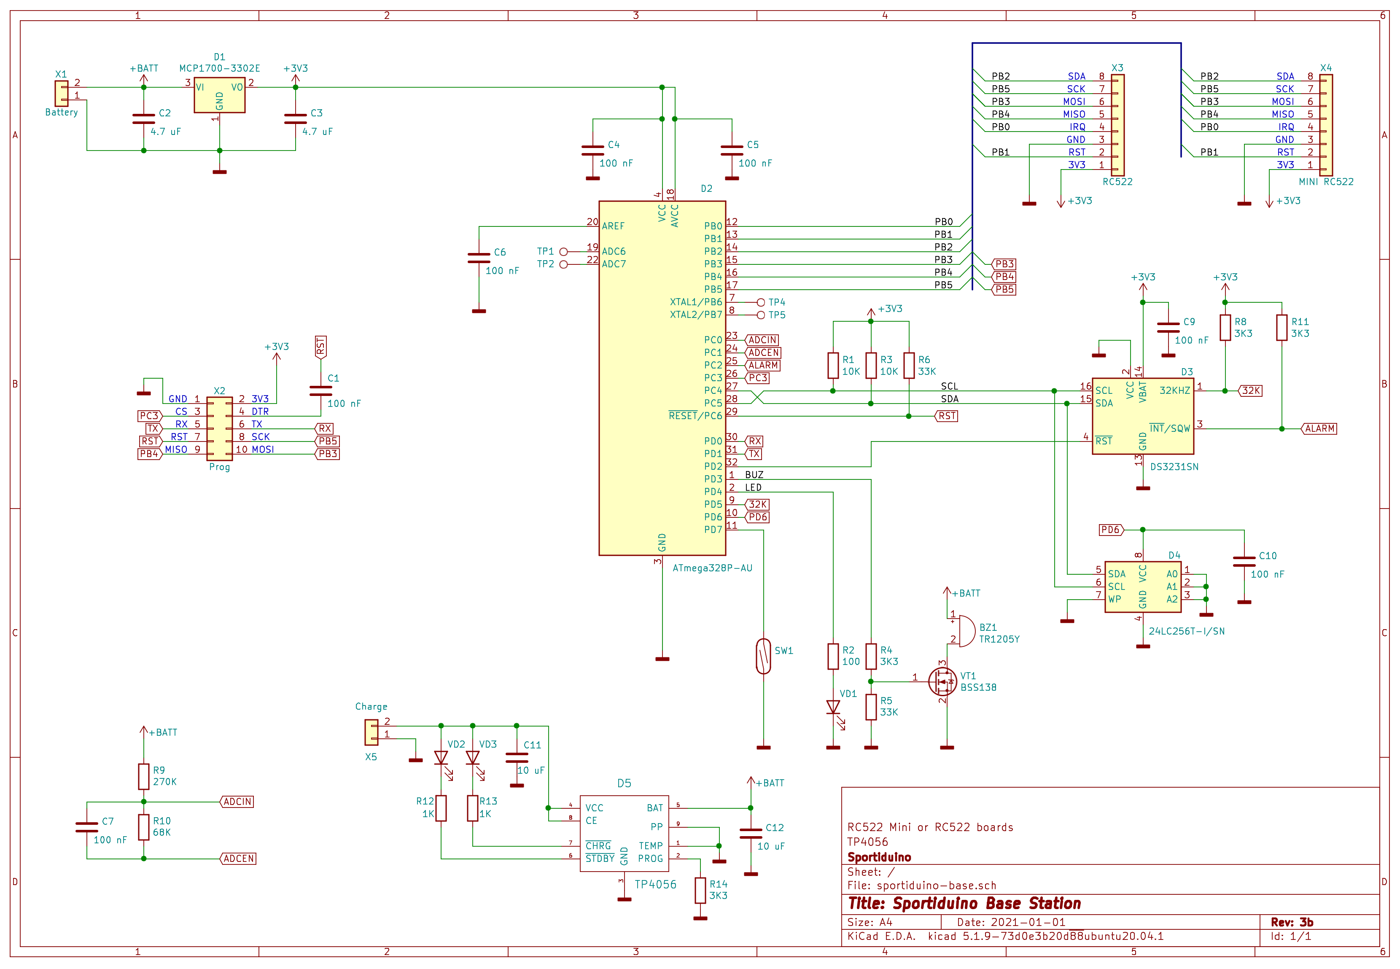
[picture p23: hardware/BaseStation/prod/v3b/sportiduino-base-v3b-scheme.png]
Принципиальная схема платы v3b


Монтаж компонентов производится на печатной плате, с платой RFID соединение пайкой через штыревой разъём.
Можно заказать изготовление плат в Китае. Например, на [JLCPCB](https://jlcpcb.com/).

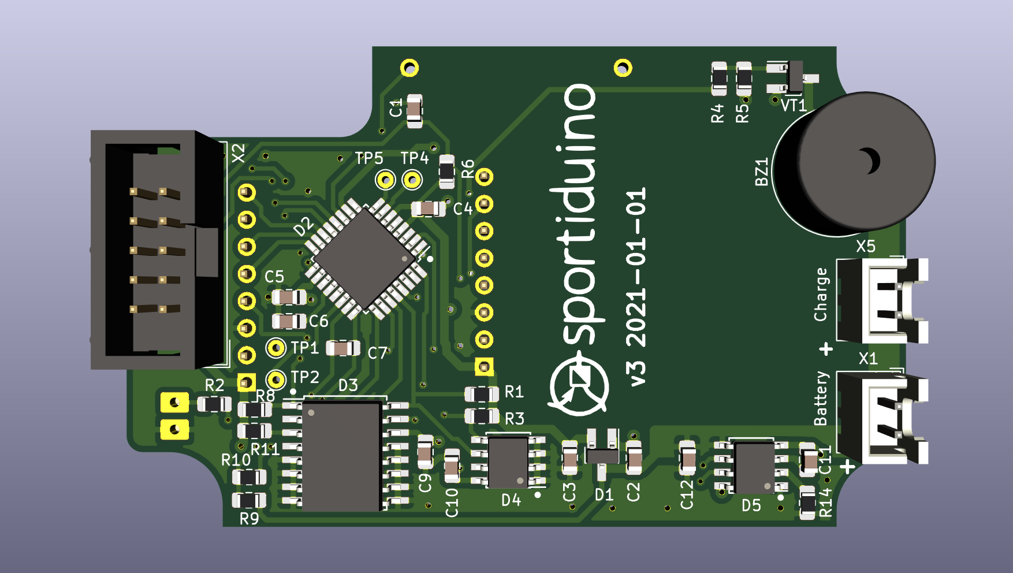
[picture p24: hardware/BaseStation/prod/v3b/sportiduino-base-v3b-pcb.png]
Расположение компонентов на плате v3b


Для прошивки микроконтроллера потребуется Arduino с установленной прошивкой ArduinoAsIsp
или любой программатор для микроконтроллеров AVR, например, Pickit2.

Печатные платы и батарейный отсек размещаются в пластиковом корпусе.
Для защиты электроники от осадков и конденсата внутрь корпуса после сборки заливается компаунд.
Про сборку станции и прошивку более подробно написано в [Инструкции по сборке](BaseStationAssembly.md).

### Потребление

По умолчанию станция запускается в режиме ожидания.
При этом происходит считывание чипов раз в секунду.
Интегральное потребление до 0,5 мА.
Во время работы RFID потребляется до 20 мА (до 40 мА в момент считывания-записи).
Полностью заряженных батарей хватит примерно на 160 дней.

При поднесении чипа (это делает судья-постановщик или первый спортсмен) станция переходит в рабочий режим.
По умолчанию после 2 часов бездействия станция возвращается в режим ожидания.
Рабочее время задаётся с помощью настроек.

В рабочем режиме реализовано вхождение в сон каждые 250 мс.
Таким образом, во время работы можно ожидать интегральное потребление порядка 1,7 мА.
Полностью заряженных батарей хватит примерно на 45 дней непрерывной работы.

Для уменьшения потребления во время хранения станций реализован режим сна (Sleep mode).
В этом режиме станция потребляет около 15 мкА.
Полностью заряженных батарей хватит на 5 лет.

На плате RFID необходимо обязательно выпаять светодиод и подтягивающий резистор к линии RST, иначе потребление будет на порядки больше.

### Настройка

Настройка станции отметки производится мастер-чипами или через преобразователь USB-to-TTL.
См. [Руководство пользователя](UserManual.md).

### Алгоритм работы станции

После подачи питания или перезагрузки станция проверяет настройку часов.
Если часы настроены неправильно, то станция издаёт соответствующий сигнал.
Затем станция загружает из энергонезависимой памяти настройки (номер станции, пароль и др.).
Проверяется уровень заряда батареи (в это время на несколько секунд включается светодиод).
Если уровень заряда соответствует норме, станция издаёт один длинный сигнал. Если уровень низкий, то станция издаёт серию коротких (см. ниже).
После инициализации станция переходит в режим ожидания.
В режиме ожидания станция просыпается каждую секунду и ищет чип.
При обнаружении чипа переходит в рабочий режим с опросом чипа каждые 250 миллисекунд.
При поднесении чипа, станция считывает 1-й блок, где хранится номер чипа или признак мастер-чипа.
Если чип является обычным, то происходит поиск последней записанной страницы и считывание номера станции в последней отметке.
Если номер станции совпадает с последней отметкой, то станция издает двойной сигнал.
Если номер отличный, то производится запись отметки в блок следующий после записанного.
В случае успеха, станция подает одиночный сигнал, а также записывает факт отметки во внутреннюю энергонезависимую память станции (в бит, соответствующий номеру чипа).
Если на плате (v3 или v3b) установлена микросхема внешней энергонезависимой памяти EEPROM, в неё записывается отметка времени и номер чипа.
По умолчанию последняя отметка ищется методом бинарного поиска и его скорость зависит от максимального объема чипа.
Поиск и запись занимает для разного объема:

- 32 отметки - от 60 до 120 мс
- 64 отметки - от 60 до 140 мс
- 120 отметок - от 60 до 160 мс
- 220 отметок - от 60 до 180 мс

Также к этому времени добавляется период опроса.
То есть, в режиме ожидания добавляется от 0 до 1000 мс, в рабочем режиме от 0 до 250 мс.

Для ускорения записи отметки предусмотрен опциональный режим быстрой отметки.
В этом режиме номер последней отметки всегда записывается в 6-ю страницу чипа.
Таким образом не требуется длительный поиск последней страницы.
Но при этом сокращается время службы чипа, потому что 6-я страница чипа будет перезаписываться при каждой отметке.

На протяжении всего времени работы станции запущен сторожевой таймер, который при зависании системы её перезагружает.

### Настройки станции

С помощью мастер-чипа настроек можно задать:

- продолжительность рабочего режима;
- режим проверки на старте;
- режим проверки времени инициализации чипов;
- режим быстрой отметки;
- усиление антенны;
- пароль.

Во включенном режиме проверки на старте станция старта (номер 240) будет принимать только очищенные чипы.

По умолчанию все специальные режимы выключены, пароль — 0-0-0.

### Станция очистки

Для перевода станции в режим очистки нужно задать станции номер 249.
В режиме очистки станция проводит очистку всех страниц чипа кроме страницы с номером чипа.
В страницу времени инициализации записывается новое время,
которое используется при подсчёте результатов, поэтому важно чтобы время на станции было корректным.

При поднесении чипа, на станции загорается светодиод и мигает до тех пор пока не закончится очистка (около 4 секунд).
При успешной очистке станция издает сигнал, светодиод гаснет, чип нужно убрать.
Если сигнала не было, очистка не была завершена, нужно повторить процедуру.

### Станция проверки

Для перевода станции в режим проверки нужно задать станции номер 248.
В режиме проверки станция не записывает данные на чип, а только проверяет его.
Если чип содержит отметки или время инициализации превышает время на станции более чем на 180 дней, станция молчит.
Если всё в порядке, то станция издаёт один короткий сигнал.
Время проверки примерно совпадает со временем отметки поэтому участники могут на этой станции потренировать отметку.

### Система паролей

Для защиты от несанкционированного перепрограммирования установленных станций используется система паролей.

Пароль состоит из трех чисел от 0 до 255 (трех байт).
Пароль по умолчанию — 0-0-0.
Все мастер-чипы содержат пароль, и работают только при условии совпадения паролей на чипе и на станции.
Для передачи пароля на станцию отметки используется мастер-чип настроек.
Пароль станции хранят в энергонезависимой памяти (EEPROM). 

### Сигналы

Ошибки:

| Число сигналов | Продолжительность сигнала, мс | Значение |
| --- | --- | --- |
| 2 |  80 | Микросхема DS3231 неисправна или не подключена
| 3 | 100 | Неверно идут часы
| 4 | 100 | Неверный пароль на мастер-чипе
| 5 | 100 | Низкий заряд батареи
| 4 |  50 | Неизвестный мастер-чип
| 2 | 250 | Ошибка мастер-чипа
| 2 | 250 | Ошибка последовательного интерфейса

Нормальное поведение:

| Число сигналов | Продолжительность сигнала, мс | Значение |
| --- | --- | --- |
| 1 | 1000 | Батарея в норме, конец загрузки станции
| 1 |  500 | Успешная отметка, проверка или очистка
| 2 |  250 | Отметка уже записана на чип
| 1 |  250 | Прочитан мастер-чип
| 4 |  500 | Вход в режим сна
| 1 |  250 | Подтверждение для последовательного интерфейса

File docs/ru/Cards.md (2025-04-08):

# Чипы отметки

Система отметки поддерживает следующие типы чипов:
- [Mifare Ultralight C](http://www.nxp.com/documents/data_sheet/MF0ICU2.pdf) на 36 отметок
- [Mifare Classic 1K](https://www.nxp.com/docs/en/data-sheet/MF1S50YYX_V1.pdf) на 42 отметки
- [Mifare Classic 4K](https://www.nxp.com/docs/en/data-sheet/MF1S70YYX_V1.pdf) на 90 отметок
- [NTAG213/215/216](https://www.nxp.com/docs/en/data-sheet/NTAG213_215_216.pdf) на 32/120/216 отметок

Тип используемых чипов система определяет автоматически и может одновременно работать с разными типами чипов.

Рекомендуется использовать чипы NTAG213/215/216.

Чипы в виде брелков

**Важно!** Для надежной работы с данными чипами, которые обладают небольшой по площади антенной,
необходимо заменить индуктивности на более мощные в плате RFID RC522 (см. [Сборка станции отметки](BaseStationAssembly.md)).

Чипы Mifare Classic 1K идут в комплекте с модулем RC522.
Памяти данных чипов хватает на 42 отметки. Работают чуть медленнее NTAG.
Память чипов Mifare используется лишь на четверть, так как в их структуре реализованы страницы длиной 16 байт.
И при более плотной записи есть риск потери данных. Структура записи аналогичная NTAG.

Память чипов NTAG213/215/216 разделена структурно на 45/135/231 страниц, в каждой из которых содержится по 4 байта.
В первых 4-х страницах содержится UID и другая служебная информация.
Также служебная информация содержится в последних 5 страницах.
Таким образом, для записи остается 36/126/222 страниц.

### Структура данных

Страницы 4-7 зарезервированы, остальные страницы для отметки.
В 4-й странице в первых двух байтах содержится программируемый номер чипа.
В 4-м байте версия прошивки (8 для v3.8.0, 9 для v3.9.1 и т. д.).
В пятой странице время инициализации чипа в формате Unixtime
С помощью него восстанавливается первый байт времени в отметки.
Далее две страницы резерва для реализации дополнительных функций на отдельных стартах.
Запись отметки на станции занимает отдельную страницу,
в первый байт которой записывается номер станции, в остальные три байта - младшие байты текущего времени в Unixtime.

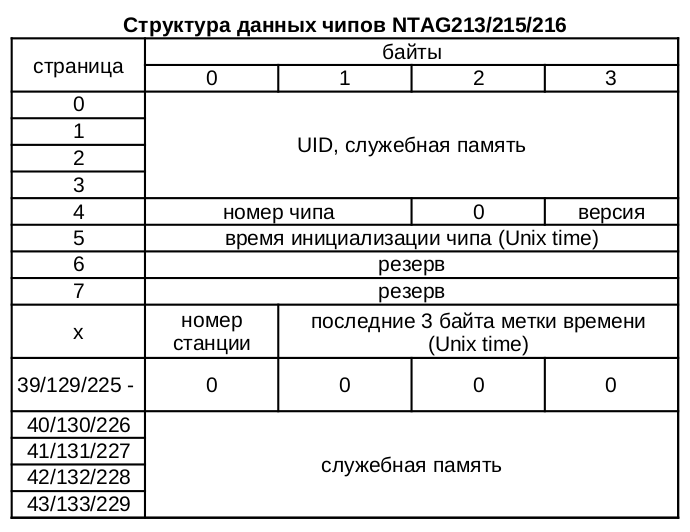
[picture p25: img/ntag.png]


У мастер-чипов для программирования станций структура отличается.
Станция определяет их по числу 255, записанному в третий байт 4-й страницы.
Существует 8 разных мастер-чипов: времени, номера, сна, настроек, пароля, пароля аутентификации, лога и состояния.
Ниже представлена структура мастер-чипов.





#### Мастер-чип установки времени на станции

Записывает дату и время в станцию (в часы реального времени).

Данный чип однократного действия. 
То есть после считывания информации с чипа на нём стирается страница 4
для предотвращения случайного повторного его использования.

#### Мастер-чип установки номера на станции

Записывает номер в станцию, если он больше 0.

Данный чип однократного действия. 

#### Мастер-чип перевода в спящий режим

Записывает в станцию дату и время пробуждения и переводит её в режим сна.
При пробуждении по таймеру станция переходит в активный режим.

Данный чип многократного действия. 

#### Мастер-чип установки настроек

Записывает номер (если > 0), байт настроек, усиление антенны (если ≥ 2 и ≤ 7) и новый пароль в станцию.

Данный чип многократного действия. 

#### Мастер-чип установки пароля

Записывает новый пароль в станцию.

Данный чип многократного действия. 

#### Мастер-чип установки пароля аутентификации

Записывает пароль аутентификации (4 байта) чипов Ntag в станцию.

Данный чип многократного действия.

#### Мастер-чип получения лога

В данный чип станция записывает лог отметок.
Если станция сохраняет лог с временными метками, то записывается лог за последние 12 дней в порядке возрастания номеров чипов.
Так как ёмкости чипа может быть недостаточно для записи всего лога с временными метками,
то для полного считывания лога необходимо несколько раз приложить чип к станции с промежуточным считыванием содержимого чипа.

Данный чип многократного действия. 

#### Мастер-чип чтения состояния станции

В данный чип станция записывает:
- номер версии прошивки (3 байта) в страницу 4;
- номер станции, байт настроек, усиление антенны в страницу 5;
- напряжение батареи (мВ/20, 1 байт) и режим (1 байт) в страницу 6;
- текущее время в формате Unix в страницу 7;
- время пробуждения в формате Unix в страницу 8;

Данный чип многократного действия.

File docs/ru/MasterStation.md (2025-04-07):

# Станция сопряжения

Станция сопряжения может быть выполнена в различных корпусах.

Станция сопряжения в корпусе, распечатанном на 3D-принтере

или

Станция сопряжения в корпусе G1020BF

Схема и плата доступны в Upverter ([вариант 1](https://upverter.com/AlexanderVolikov/3fc0efdb2586988d/Sportiduino-reading-stantion/) и
[вариант 2](https://upverter.com/design/syakimov/4f7ec0e2d3b9c4e9/sportiduino-master-station/)).

Принципиальная схема

Все компоненты схемы можно разместить на печатной плате или припаять к Arduino навесным монтажом обычными проводами (рекомендуется провод МГТФ-0,12).
Электронику мастер-станции можно разместить в корпусе Gainta G1020BF или в специально разработанном корпусе, который можно распечатать на 3D-принтере.
[Подробнее про сборку](MasterStationAssembly.md).

Станция подключается к компьютеру с помощью USB соединения.
В Arduino Nano уже встроен Serial-USB преобразователь, поэтому дополнительных конвертеров не нужно.
Станция отобразится в подключенных устройствах как COM-порт. 

### Протокол передачи данных

Передача и получение информации происходит последовательно с помощью передачи пакетов длиной до 32 байт.
Если размер передаваемых данных больше 28 байт, то данные передаются в нескольких пакетах.

| | Значение | Адрес байта в пакете |
| --- | --- | --- |
| Старт | 0xFE | 0 |
| Функция | | 1 |
| Длина данных или номер пакета+0x1E, если пакетов несколько | | 2 |
| Массив данных | | 3 … x (x<31) |
| Контрольная сумма | | x+1 |

Пакет начинается со стартового байта 0xFE.

Команда задается байтом с адресом 1.
Затем в байте 2 следует длина пакета, если передаваемый пакет последний либо его номер+30, если идёт многопакетная передача.

Далее идёт массив передаваемых данных до 28 байтов.

В конце пакета содержится контрольная сумма: остаток от деления на 256 суммы байтов 1 … x.
В случае неверного значения стартового байта или контрольной суммы пакет отбрасывается.

#### Список команд, передаваемых на станцию

| Код | Команда | Длина | Массив данных по байтам (в скобах адрес в массиве) |
| --- | --- | --- | --- |
| 0x41 | Записать время на мастер-чип | 6 | год-2000(0), месяц(1), день(2), час(3), минута(4), секунда(5)
| 0x42 | Записать номер станции на мастер-чип | 1 | номер(0)
| 0x44 | Инициализировать чип | 14 | номер чипа (0-1), текущее время (2-5), информация в 6-7 страницы (6-13)
| 0x45 | Передать параметры страниц 6 и 7 | 8 | информация в 6-7 страницы (0-7)
| 0x46 | Запрос версии прошивки мастер-станции | 0 |
| 0x47 | Записать мастер-чип лога | 0 |
| 0x48 | Считать мастер-чип лога | 0 |
| 0x4A | Записать настройки станции сопряжения | 1 | усиление антенны(0)
| 0x4B | Считать чип | 0 |
| 0x4C | Считать сырые данные с чипа | 0 |
| 0x4D | Считать настройки станции сопряжения | 0 |
| 0x4E | Записать мастер-чип сна | 6 | год-2000(0), месяц(1), день(2), час(3), минута(4), секунда(5)
| 0x4F | Установить текущий пароль | 3 | пароль (0-2)
| 0x50 | Создать мастер-чип для чтения состояния станции | 0 |
| 0x51 | Считать тип чипа | 0 |
| 0x58 | Сигнал ошибки (три коротких) | 0 |
| 0x59 | Сигнал ОК (длинный) | 0 |
| 0x5A | Записать настройки на мастер-чип | 6 | конфигурация станции

#### Список ответов от станции

| Код | Ответ | Длина | Массив данных по байтам (в скобах адрес в массиве) |
| --- | --- | --- | --- |
| 0x61 | Лог | N пакетов | (первый пакет - номер станции (0)), номер отметившегося чипа 1(1-2), номер отметившегося чипа 2(3-4) и т. д.
| 0x63 | Данные с чипа отметки | N пакетов | (первый пакет - номер чипа (0-1), информация в 6-7 страницах чипа (2-9)), номер КП0 (10), время КП0 (11-14), номер КП1 (15), время КП1 (16-19) и т. д.
| 0x65 | Сырые данные с чипа | N пакетов | номер страницы 4(0), байты страницы 4(1-4), номер страницы 5(5), байты страницы 5(6-9) и т. д.
| 0x66 | Версия прошивки мастер-станции | 3 | версия прошивки(0-2)
| 0x67 | Настройки мастер-станции | 1 | усиление антенны(0)
| 0x70 | Тип чипа | 1 | тип чипа(0)
| 0x78 | Ошибка | 2 | код ошибки(0), тип чипа (1)
| 0x79 | ОК | 1 | тип чипа (0)

#### Коды ошибок

| Код | Ошибка |
| --- | --- |
| 0x01 | Ошибка передачи данных через COM-порт
| 0x02 | Ошибка записи чипа
| 0x03 | Ошибка чтения чипа
| 0x04 | Ошибка чтения EEPROM
| 0x05 | Чип не найден
| 0x06 | Неизвестная команда

### Эмуляция протокола SPORTident

В прошивке станции сопряжения начиная с версии 1.8.0 реализовано чтение чипов по протоколу передачи данных системы отметки SPORTident.
Все чипы определяются как SI-Card 6 (192 отметки).
Проверялась работа станции сопряжения с программами SPORTident Reader, Rogain Manager, SportOrg, MeOS 3.8.1277, WinOrient 2.0a (2011 - 2020).

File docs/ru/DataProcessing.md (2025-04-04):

# Программы для работы с системой отметки

### Запись чипов, настройка станций

#### [SportiduinoPQ](https://github.com/sportiduino/SportiduinoPQ)

Программа для ПК (Windows или Linux).

Написана на Python с использованием PyQt5 и [модуля SportiduinoPython](https://github.com/sportiduino/sportiduinoPython).

#### [SportiduinoApp](https://github.com/sportiduino/sportiduinoapp)

Android приложение для смартфонов с модулем NFC.

### Для проведения соревнований

Чтение чипов реализовано в программах [SportOrg](https://github.com/sportorg/pysport) и [SportOrgPlus](https://github.com/sembruk/sportorg-plus).

Также можно использовать программы для работы со SPORTident (MeOS, WinOrient, Rogain Manager и др.).

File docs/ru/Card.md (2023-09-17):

# Чипы

Система отметки поддерживает следующие типы чипов:
- [Mifare Ultralight C](http://www.nxp.com/documents/data_sheet/MF0ICU2.pdf) на 36 отметок
- [Mifare Classic 1K](https://www.nxp.com/docs/en/data-sheet/MF1S50YYX_V1.pdf) на 42 отметки
- [Mifare Classic 4K](https://www.nxp.com/docs/en/data-sheet/MF1S70YYX_V1.pdf) на 90 отметок
- [NTAG213/215/216](https://www.nxp.com/docs/en/data-sheet/NTAG213_215_216.pdf) на 32/120/216 отметок

Тип используемых чипов система определяет автоматически и может одновременно работать с разными типами чипов.

Рекомендуется использовать чипы NTAG213/215/216.
В виде наклеек данные чипы стоят 6/12/20 рублей, в виде брелков в два раза дороже.

Чипы в виде брелков

**Важно!** Для надежной работы с данными чипами, которые обладают небольшой по площади антенной,
необходимо заменить индуктивности на более мощные в плате RFID RC522 (см. [Сборка станции отметки](BaseStationAssembly.md)).

Чипы Mifare Classic 1K идут в комплекте с модулем RC522.
Памяти данных чипов хватает на 42 отметки. Работают чуть медленнее NTAG.
Память чипов Mifare используется лишь на четверть, так как в их структуре реализованы страницы длиной 16 байт.
И при более плотной записи есть риск потери данных. Структура записи аналогичная NTAG.

Память чипов NTAG213/215/216 разделена структурно на 45/135/231 страниц, в каждой из которых содержится по 4 байта.
В первых 4-х страницах содержится UID и другая служебная информация.
Также служебная информация содержится в последних 5 страницах.
Таким образом, для записи остается 36/126/222 страниц.

### Структура данных

Страницы 4-7 зарезервированы, остальные страницы для отметки.
В 4-ой странице в первых двух байтах содержится программируемый номер чипа.
В 4-ом байте версия прошивки (8 для v3.8.0, 9 для v3.9.1 и т. д.).
В пятой странице время инициализации чипа в формате Unixtime
С помощью него восстанавливается первый байт времени в отметки.
Далее две страницы резерва для реализации дополнительных функций на отдельных стартах.
Запись отметки на станции занимает отдельную страницу,
в первый байт которой записывается номер станции, в остальные три байта - младшие байты текущего времени в Unixtime.



У мастер-чипов для программирования станций структура отличается.
Станция определяет их по числу 255, записанному в третий байт 4-ой страницы.
Существует 6 разных мастер чипов: времени, номера, сна, настроек, лога и информации.
Ниже представлена структура мастер-чипов.



#### Мастер-чип установки времени на станции

Записывает дату и время в станцию (в часы реального времени).

Данный чип однократного действия. 
То есть после считывания информации с чипа на нём стирается страница 4
для предотвращения случайного повторного его использования.

#### Мастер-чип установки номера на станции

Записывает номер в станцию, если он больше 0.

Данный чип однократного действия. 

#### Мастер-чип перевода в спящий режим

Записывает в станцию дату и время пробуждения и переводит её в режим сна.
При пробуждении по таймеру станция переходит в активный режим.

Данный чип многократного действия. 

#### Мастер-чип установки настроек

Записывает номер (если > 0), байт настроек, усиление антенны (если ≥ 2 и ≤ 7) и новый пароль в станцию.

Данный чип многократного действия. 

#### Мастер-чип получения лога

В данный чип станция записывает лог отметок.
Если станция сохраняет лог с временными метками, то записывается лог за последние 12 дней в порядке возрастания номеров чипов.
Так как ёмкости чипа может быть недостаточно для записи всего лога с временными метками,
то для полного считывания лога необходимо несколько раз приложить чип к станции с промежуточным считыванием содержимого чипа.

Данный чип многократного действия. 

#### Мастер-чип чтения состояния станции

В данный чип станция записывает:
- номер версии прошивки (3 байта) в страницу 4;
- номер станции, байт настроек, усиление антенны в страницу 5;
- напряжение батареи (мВ/20, 1 байт) и режим (1 байт) в страницу 6;
- текущее время в формате Unix в страницу 7;
- время пробуждения в формате Unix в страницу 8;

Данный чип многократного действия.

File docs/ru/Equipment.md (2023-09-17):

# Оборудование и материалы для сборки



1. Мультиметр. Опционально.

2. Паяльник с регулятором температуры или паяльная станция (например, 8586).

3. Подставка под паяльник.

4. Подставка для пайки "третья рука". Нужно, чтобы было удобно паять SMD компоненты.

5. Флюс с кисточкой. Рекомендуются флюсы для пайки SMD (RMA-218, NC-559).

6. Пинцет (необходим при пайке мелких деталей), обрезанная игла из под шприца для чистки забитых отверстий при пререпайке, ножик.

7. Припой ПОС-61.

8. Оплётка для удаления лишнего припоя, а также для зачистки платы в случае перепайки отдельных элементов.

9. Сверло на 3 мм и шуруповёрт для сверления в корпусе отверстия под светодиод.

10. Канцелярский нож для обрезки корпуса.

11. Крестовая отвертка для закручивания корпуса.

12. Вазелин для смазывания контактов в батарейном отсеке против коррозии. Опционально.

13. Эпоксидный клей для приклеивания светодиода. Опционально.

14. Силиконовый компаунд. Опционально.

Для прошивки загрузчика (bootloader) дополнительно понадобится плата Arduino Nano или программатор Pickit2.

Arduino Nano
Pickit2

Для загрузки основной прошивки понадобится USB-UART преобразователь (USB-to-TTL, USB-Serial).
Важно, чтобы преобразователь имел подключённый вывод DTR (преобразователь с чипом CH340 или CP2102)



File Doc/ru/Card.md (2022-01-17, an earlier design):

# Чипы

Система отметки поддерживает следующие типы чипов:
- [Mifare Ultralight C](http://www.nxp.com/documents/data_sheet/MF0ICU2.pdf) на 36 отметок
- [Mifare Classic 1K](https://www.nxp.com/docs/en/data-sheet/MF1S50YYX_V1.pdf) на 42 отметки
- [Mifare Classic 4K](https://www.nxp.com/docs/en/data-sheet/MF1S70YYX_V1.pdf) на 90 отметок
- [NTAG213/215/216](https://www.nxp.com/docs/en/data-sheet/NTAG213_215_216.pdf) на 32/120/216 отметок

Тип используемых чипов система определяет автоматически и может одновременно работать с разными типами чипов.

Рекомендуется использовать чипы NTAG213/215/216.
В виде наклеек данные чипы стоят 6/12/20 рублей, в виде брелков в два раза дороже.

Чипы в виде брелков

**Важно!** Для надежной работы с данными чипами, которые обладают небольшой по площади антенной,
необходимо заменить индуктивности на более мощные в плате RFID RC522 (см. [Сборка станции отметки](/Doc/ru/BaseStationAssembly.md)).

Чипы Mifare Classic 1K идут в комплекте с модулем RC522.
Памяти данных чипов хватает на 42 отметки. Работают чуть медленнее NTAG.
Память чипов Mifare используется лишь на четверть, так как в их структуре реализованы страницы длиной 16 байт.
И при более плотной записи есть риск потери данных. Структура записи аналогичная NTAG.

Память чипов NTAG213/215/216 разделена структурно на 45/135/231 страниц, в каждой из которых содержится по 4 байта.
В первых 4-х страницах содержится UID и другая служебная информация.
Также служебная информация содержится в последних 5 страницах.
Таким образом, для записи остается 36/126/222 страниц.

### Структура данных

Страницы 4-7 зарезервированы, остальные страницы для отметки.
В 4-ой странице в первых двух байтах содержится программируемый номер чипа.
В 4-ом байте версия прошивки (8 для v3.8.0, 9 для v3.9.1 и т. д.).
В пятой странице время инициализации чипа в формате Unixtime
С помощью него восстанавливается первый байт времени в отметки.
Далее две страницы резерва для реализации дополнительных функций на отдельных стартах.
Запись отметки на станции занимает отдельную страницу,
в первый байт которой записывается номер станции, в остальные три байта - младшие байты текущего времени в Unixtime.



У мастер-чипов для программирования станций структура отличается.
Станция определяет их по числу 255, записанному в третий байт 4-ой страницы.
Существует 6 разных мастер чипов: времени, номера, сна, настроек, лога и информации.
Ниже представлена структура мастер-чипов.



#### Мастер-чип установки времени на станции

Записывает дату и время в станцию (в часы реального времени).

Данный чип однократного действия. 
То есть после считывания информации с чипа на нём стирается страница 4
для предотвращения случайного повторного его использования.

#### Мастер-чип установки номера на станции

Записывает номер в станцию, если он больше 0.

Данный чип однократного действия. 

#### Мастер-чип перевода в спящий режим

Записывает в станцию дату и время пробуждения и переводит её в режим сна.
При пробуждении по таймеру станция переходит в активный режим.

Данный чип многократного действия. 

#### Мастер-чип установки настроек

Записывает номер (если > 0), байт настроек, усиление антенны (если ≥ 2 и ≤ 7) и новый пароль в станцию.

Данный чип многократного действия. 

#### Мастер-чип получения лога

В данный чип станция записывает лог отметок.
Если станция сохраняет лог с временными метками, то записывается лог за последние 12 дней в порядке возрастания номеров чипов.
Так как ёмкости чипа может быть недостаточно для записи всего лога с временными метками,
то для полного считывания лога необходимо несколько раз приложить чип к станции с промежуточным считыванием содержимого чипа.

Данный чип многократного действия. 

#### Мастер-чип чтения состояния станции

В данный чип станция записывает:
- номер версии прошивки (3 байта) в страницу 4;
- номер станции, байт настроек, усиление антенны в страницу 5;
- напряжение батареи (мВ/20, 1 байт) и режим (1 байт) в страницу 6;
- текущее время в формате Unix в страницу 7;
- время пробуждения в формате Unix в страницу 8;

Данный чип многократного действия.

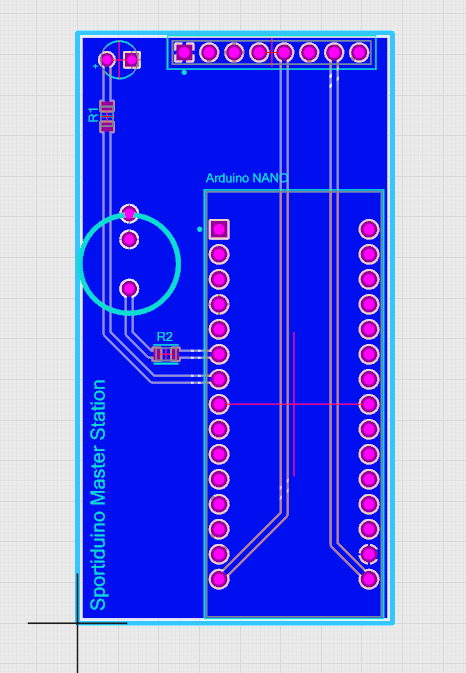
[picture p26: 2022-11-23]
hardware/MasterStation/usb/sportiduino-master-pcb.png

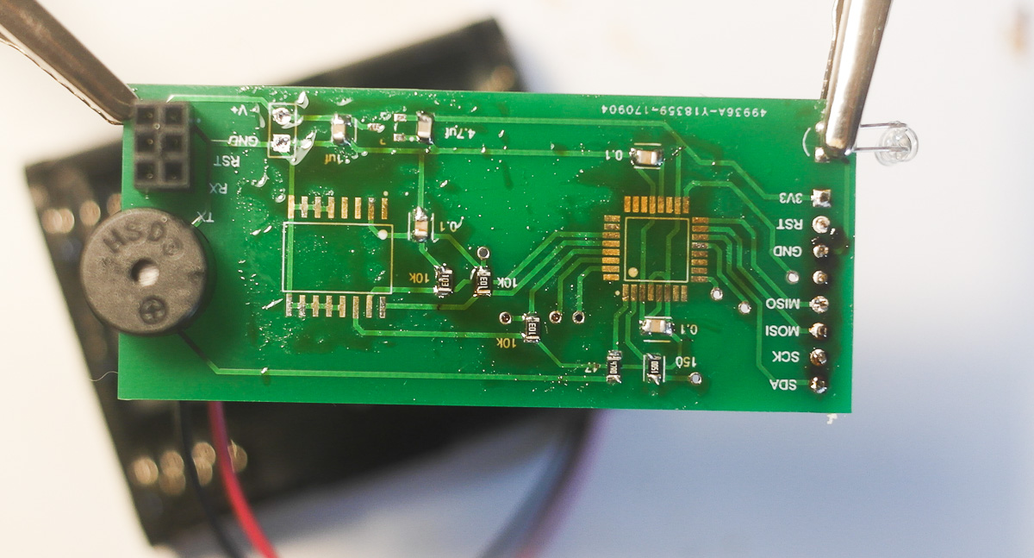
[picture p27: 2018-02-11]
img/s08.jpg

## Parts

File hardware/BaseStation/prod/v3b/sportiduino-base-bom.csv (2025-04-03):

Comment | Designator | Footprint | LCSC
Passive Buzzer 12085 (12x8.5mm) 16 ohm | BZ1 | Passive Buzzer 12085 (12x8.5mm) 16 ohm
10 uF | C11,C12 | Capacitor_SMD:C_0805_2012Metric_Pad1.18x1.45mm_HandSolder
4.7 uF | C2,C3 | Capacitor_SMD:C_0805_2012Metric_Pad1.15x1.40mm_HandSolder
100 nF | C1,C4,C5,C6,C7,C9,C10 | Capacitor_SMD:C_0805_2012Metric_Pad1.15x1.40mm_HandSolder
MCP1700-3302E | D1 | Package_TO_SOT_SMD:SOT-23_Handsoldering
ATmega328P-AU | D2 | Package_QFP:TQFP-32_7x7mm_P0.8mm
DS3231SN | D3 | SOIC-16W_7.5x10.3mm_P1.27mm
24LC256T-I/SN | D4 | SOIC-8_3.9x4.9mm_P1.27mm
TP4056 | D5 | SOP-8-PP
10K | R1,R3 | Resistor_SMD:R_0805_2012Metric_Pad1.15x1.40mm_HandSolder
68K | R10 | Resistor_SMD:R_0805_2012Metric_Pad1.15x1.40mm_HandSolder
1K | R12,R13 | Resistor_SMD:R_0805_2012Metric_Pad1.20x1.40mm_HandSolder
3K | R14 | Resistor_SMD:R_0805_2012Metric_Pad1.20x1.40mm_HandSolder
100 | R2 | Resistor_SMD:R_0805_2012Metric_Pad1.15x1.40mm_HandSolder
3K3 | R4,R8,R11 | Resistor_SMD:R_0805_2012Metric_Pad1.15x1.40mm_HandSolder
33K | R5,R6 | Resistor_SMD:R_0805_2012Metric_Pad1.15x1.40mm_HandSolder
270K | R9 | Resistor_SMD:R_0805_2012Metric_Pad1.15x1.40mm_HandSolder
Reed Switch Normally Open 2x14mm | SW1 | Reed Switch Normally Open 2x14mm
EMPTY | TP1,TP2,TP4,TP5
1210 3528 BLUE 3.5*2.8*1.9mm | VD1 | LED_SMD:LED_1210_3528Metric
0805 GREEN | VD2 | LED_SMD:LED_0805_2012Metric_Pad1.15x1.40mm_HandSolder
0805 RED | VD3 | LED_SMD:LED_0805_2012Metric_Pad1.15x1.40mm_HandSolder
BSS138 | VT1 | SOT-23_Handsoldering
Battery | X1 | Connector_JST:JST_XH_B2B-XH-A_1x02_P2.50mm_Vertical
Prog | X2 | Connector_IDC:IDC-Header_2x05_P2.54mm_Vertical
EMPTY | X3
MINI RC522 | X4 | Connector_PinHeader_2.54mm:PinHeader_1x08_P2.54mm_Vertical
EMPTY | X5

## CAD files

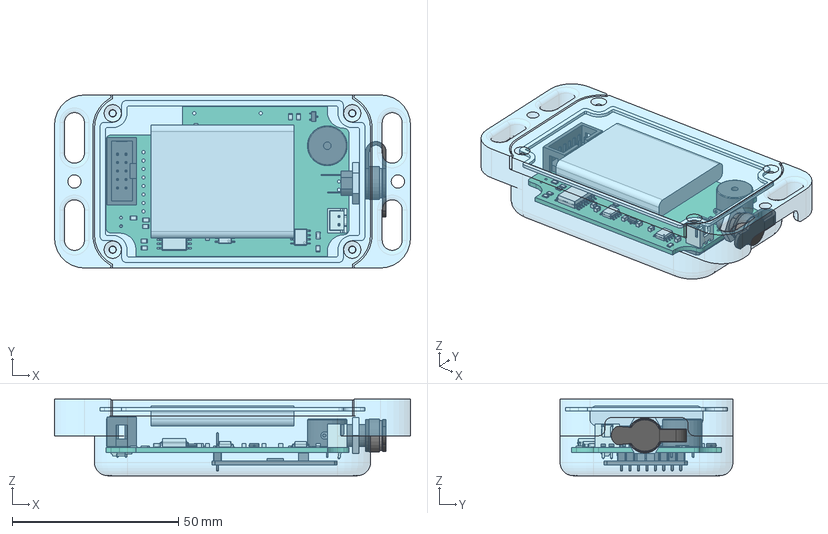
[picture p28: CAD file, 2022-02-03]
hardware/BaseStation/box/sportiduino-base.FCStd
107.0 x 52.0 x 23.0 mm
Pcb_861c
D4_SOIC_8_39x49mm_P127mm_5DF20882
D5_SOIC_8_39x49mm_P127mm_5FF3883E
D2_TQFP_32_7x7mm_P08mm_5DF01D7F
D3_SOIC_16W_75x103mm_P127mm_5FF3C078
X1_JST_B2B_XH_A_5DFEA55E
R14_R_0805_2012Metric_5FF389CF
C12_C_0805_2012Metric_5FF3870A
C11_C_0805_2012Metric_5FF386F9
C1_C_0805_2012Metric_5DEFE525
C6_C_0805_2012Metric_5DFEE111
C7_C_0805_2012Metric_5E413289
BZ1_MagneticBuzzer_ProSignal_ABT_410_RC_5DFE1DD3
C2_C_0805_2012Metric_5DF01F27
C3_C_0805_2012Metric_5DF01EF7
C4_C_0805_2012Metric_5DF01EC7
C5_C_0805_2012Metric_5DF01E97
C9_C_0805_2012Metric_5DF01E37
D1_SOT_23_5DF01DFF
R6_R_0805_2012Metric_5FF3C2A1
R2_R_0805_2012Metric_5DF01C8D
R1_R_0805_2012Metric_5DF01C5D
R4_R_0805_2012Metric_5DF01C2D
R5_R_0805_2012Metric_5DF01BFD
R3_R_0805_2012Metric_5DF01BCD
VT1_SOT_23_5DF01B95
R8_R_0805_2012Metric_5DF01B22
C10_C_0805_2012Metric_5DEFE558
R9_R_0805_2012Metric_5DEFE5B6
R10_R_0805_2012Metric_5DEFE5C7
R11_R_0805_2012Metric_5DFEAD10
X2_IDC_Header_2x05_P254mm_Vertical_5DF215F8
VD1_LED_1210_3225Metric_5FF3CBF2
VD3_LED_0805_2012Metric_5FF2D7A5
VD2_LED_0805_2012Metric_5FF2D792
R13_R_0805_2012Metric_5FF34CE9
R12_R_0805_2012Metric_5FF34CD8
X3_PinHeader_1x08_P254mm_Vertical_5DF01A04
Mini RC522
Заглушка
Nut001
Gasket

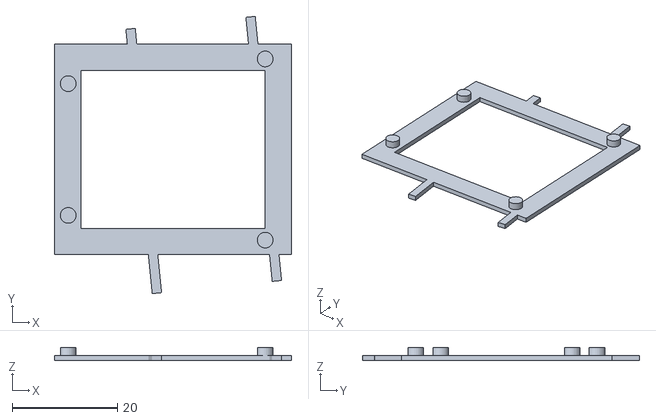
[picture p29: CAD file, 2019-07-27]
hardware/BaseStation/v2/3d/print/sportduino-base-rc522-substrate.stl
45.0 x 52.6 x 2.50

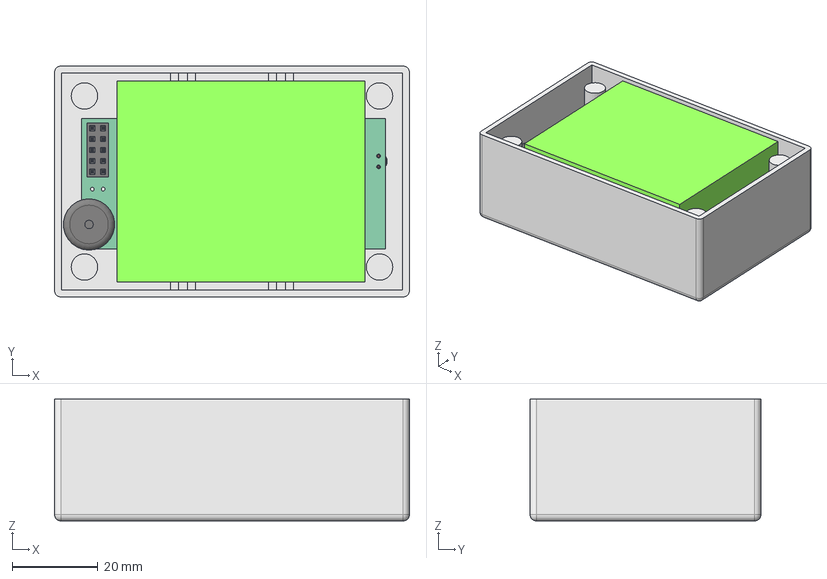
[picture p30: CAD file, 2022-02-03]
hardware/BaseStation/v2/3d/src/sportduino-base.FCStd
83.0 x 54.0 x 28.5 mm
g1020bf-top-lid
Pcb001
X2_PinSocket_2x05_P254mm_Vertical_5DEFE63F
BZ1_Buzzer_12x95RM76_5DFEA26B
C2_C_0805_2012Metric_5DF01F27
C3_C_0805_2012Metric_5DF01EF7
C4_C_0805_2012Metric_5DF01EC7
C5_C_0805_2012Metric_5DF01E97
C6_C_0805_2012Metric_5DFEE111
C9_C_0805_2012Metric_5DF01E37
D1_SOT_23_5DF01DFF
D2_TQFP_32_7x7mm_P08mm_5DF01D7F
D3_SOIC_16W_75x103mm_P127mm_5DF01D01
R6_R_0805_2012Metric_5DF01CBD
R2_R_0805_2012Metric_5DF01C8D
R1_R_0805_2012Metric_5DF01C5D
R4_R_0805_2012Metric_5DF01C2D
R5_R_0805_2012Metric_5DF01BFD
R3_R_0805_2012Metric_5DF01BCD
VT1_SOT_23_5DF01B95
R8_R_0805_2012Metric_5DF01B22
VD1_LED_D3.0mm_5DF01AEE
C1_C_0805_2012Metric_5DEFE525
C7_C_0805_2012Metric_5DF04787
C8_C_0805_2012Metric_5DEFE547
C10_C_0805_2012Metric_5DEFE558
R7_R_0805_2012Metric_5DFECC22
R9_R_0805_2012Metric_5DEFE5B6
R10_R_0805_2012Metric_5DEFE5C7
R11_R_0805_2012Metric_5DFEAD10
VD2_SOT_23_5DEFE61D
REF_D_SMA_5E19B2C2
REF_REF_D_SMA_5E19B321
battery-v2

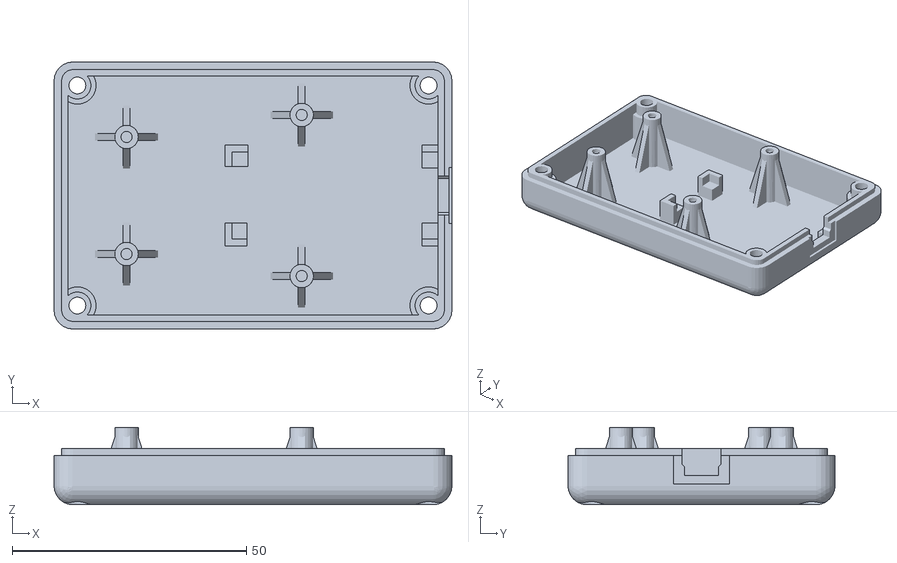
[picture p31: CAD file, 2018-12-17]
hardware/MasterStation/3d/print/sportduino-master-bottom-lid.stl
85.0 x 57.0 x 16.5

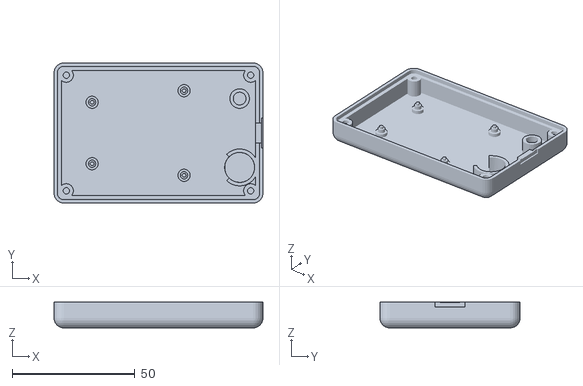
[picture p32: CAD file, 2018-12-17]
hardware/MasterStation/3d/print/sportduino-master-top-lid.stl
85.0 x 57.0 x 10.5

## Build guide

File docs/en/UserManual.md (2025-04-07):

# User manual

This manual contains general information about the system and it is intended for users.
More information about the system including assembling instructions are available on page https://github.com/sportiduino/sportiduino/

[General information](#general-information)

[Instructions for participants](#instructions-for-participants)

[Instructions for course installers](#instructions-for-course-installers)

[Preparing participant cards](#preparing-participant-cards)

[Preparing base stations](#preparing-base-stations)

[Checking base stations](#checking-base-stations)

[Reading cards and preparing results](#Reading-cards-and-preparing-results)

## General information

### Cards

The system supports following types of RFID tags:
- [Mifare Ultralight C](http://www.nxp.com/documents/data_sheet/MF0ICU2.pdf) for 36 punches 
- [Mifare Classic 1K](https://www.nxp.com/docs/en/data-sheet/MF1S50YYX_V1.pdf) for 42 punches 
- [Mifare Classic 4K](https://www.nxp.com/docs/en/data-sheet/MF1S70YYX_V1.pdf) for 90 punches 
- [NTAG213/215/216](https://www.nxp.com/docs/en/data-sheet/NTAG213_215_216.pdf) for 32/120/216 punches

This tags are produced in different form factors (cards).
Cards with small antenna may not work well.
NTAG cards are recommended for use.

### Base stations

Base stations are small boxes with flanges, weighing about 150 grams.
It powered by 3 AA batteries.
Depending on the mode of operation the battery life time is from 45 days to 2 years.
There are no buttons and no other interface at the station.
All information is exchanged contactlessly.
The optimum response area is 0.5 - 2 cm above the station.

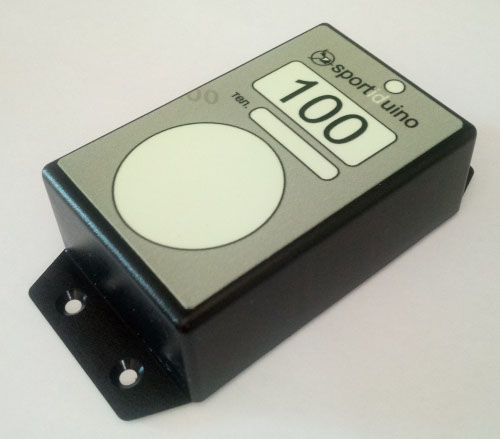
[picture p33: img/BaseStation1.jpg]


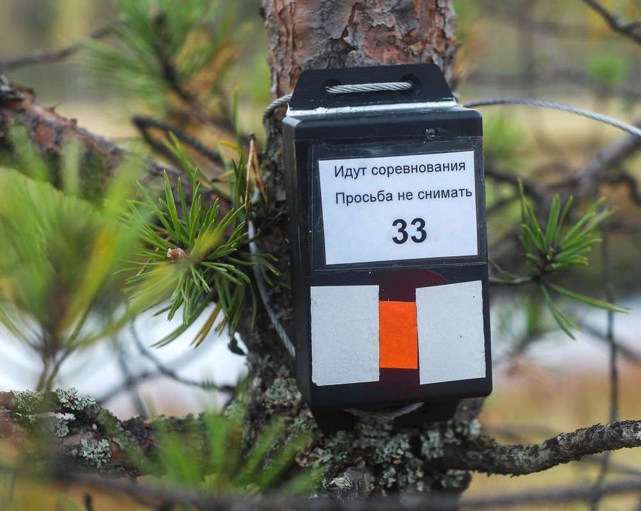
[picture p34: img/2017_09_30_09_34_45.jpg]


A real-time clock IC is installed in the station.
Clock has a small accuracy error,
but the stations are not an accurate time device.
The time needs to be regularly adjusted.

To ensure longer battery life, base stations can operate in three modes:

* **Sleep mode.**
To store stations between competitions.
Card is polled once every 25 seconds. Practically do not consume energy.
Battery will last for more than 2 years.
To enable this mode special Sleep master card are used.
Awakening is carried out by applying any card or card with a magnet for instantaneous operation.
The magnet must be applied to the middle of the left edge of the station front side.
Also at awakening the internal memory is cleared.
* **Wait mode.**
Card is polled every 1 second.
Battery will last for a half of year.
* **Active mode.**
Card is polled every 0.25 seconds.
Fastest punch mode. Battery will last for 45 days.

Base stations, depending on the number assigned to them (from 1 to 255), can perform different functions:

- 1 - 239 — Regular punching station.
When you put down a card, the base station writes new data into it and gives a signal.
When re-presenting the card, the base station does not record the punch again, it just gives a double signal.
In the start/finish checking mode station does not punch and does not signal for cards which don't contain corresponding punches.
- 240 — Start station.
In the start/finish checking mode station does not punch and does not signal if the card is not empty.
In regular mode it works like regular punching stations.
- 245 — Finish station.
Works like a regular punching station.
- 248 — Check station.
If the card is empty and the initialization time is not more than a month behind the current one,
the station picks up once, otherwise it is silent.
The station does not write anything on the card and works as normal in speed so that participants can train in punching.
- 249 — Clear station.
Erases the entire card leaving the number unchanged.
Also it updates the initialization time on the card.
The LED blink all the time of the cleaning procedure.
A beep indicates the success of the procedure.

### Master station

A station with a USB connector for connecting to a computer.
It is needed to configure base stations, write and read cards.



## Instructions for participants

* For punching, you should to bring the card to the center of the white circle on the front side of the station.
* In case of successful punching the station will emit a sound signal and blink once with the LED.
* Optimum response range 0.5 — 2 cm. If the card is far from the station, the punch may not work the first time.
* When punching, you do not need to move the card from side to side, this makes it difficult to read and write the card.
* If you fail to punch remove the card and bring it up again, slowly lowering it to the center of the white circle at the station.
* Time of punching is from 0.06 to 0.4 seconds if the station is in Active mode.
* If you came to the control point (CP) first it may need to be woken up station. The time of punching in this case will be from 0.06 to 1.2 seconds.
* When you try to re-punch, the station will emit two short beeps without recording a new punch.
If you are not sure whether you punched in the first time, it’s worth repeating.
* If you came to the CP at the same time as another participant then you need to punch one at a time.
It is impossible to simultaneously bring two or more cards to the station. In this case the punch will be recorded only on one of the cards.

## Instructions for course installers

To work with stations you should use programs:
* SportiduinoPQ for preparing the participants' cards, setting up the stations.
* SportOrg for reading cards and competition results counting.

SportiduinoPQ can be downloaded [at page](https://github.com/sportiduino/SportiduinoPQ/releases).
In the release there is an portable exe file for Windows that does not require installation.
When the program is running, the entire log is saved to the log subfolder.

The SportOrg program is available at https://github.com/sportorg/pysport
There is also a user manual.

### Connecting the master station

To connect the station, click the `Connect` button.
If the connection is successful the message `Master station is connected` is displayed in the log area.

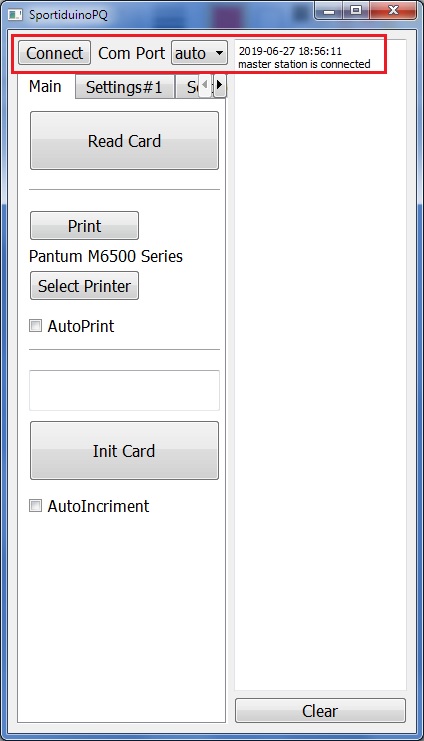
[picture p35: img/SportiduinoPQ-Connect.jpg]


If you cannot connect the station, check the connection.
Problems may arise if used another device connected via serial port.
In this case open Device Manager in Control Panel of Windows, find out the Com port number assigned to the station and select it instead of "auto".
Also for station based on Arduino Nano with CHG340 chips you should install the appropriate driver.

### Preparing participant cards

Empty cards must be initialized (write the number and the current time).
To do this in the `Main` tab, you should enter the card number.
Next bring the card to the station and press the `Init Card` button.
Depending on the card type the initialization process takes from 3 to 7 seconds.
If successful the station will beep once.
If the `Autoincrement` box is checked the number in the input field will increase by 1.
If the process failed (series of short beeps) try the procedure again.

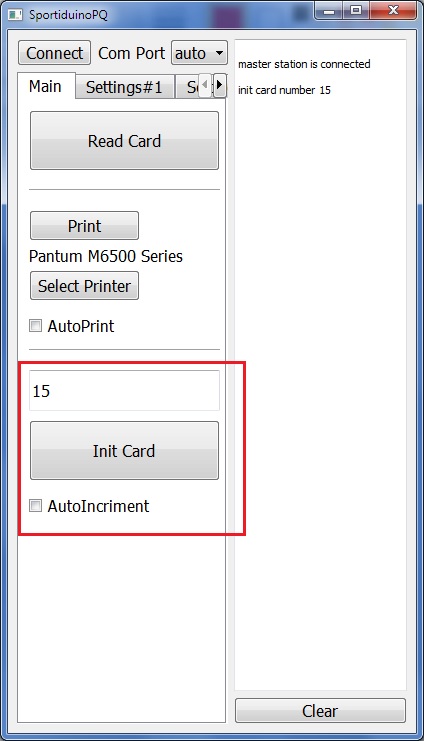
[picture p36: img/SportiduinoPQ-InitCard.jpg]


The card number can be set in the range from 1 to 65535.
But base stations will not backup punches for cards with the number over 4000.
Therefore it is recommended to limit numbers up to 4000.

During initialization in addition to the card number the initialization time is also recorded.
This time is necessary for the reading of the card.
If more than six months have passed since the initialization or cleaning the data will be incorrect.
Therefore it is recommended to initialize the cards not long before the competition.

Already initialized cards can be cleared at Clear station with keeping the card number.

## Preparing base stations

### Quick preparing base stations

For quick preparing the base station by UART using USB-to-TTL converter.

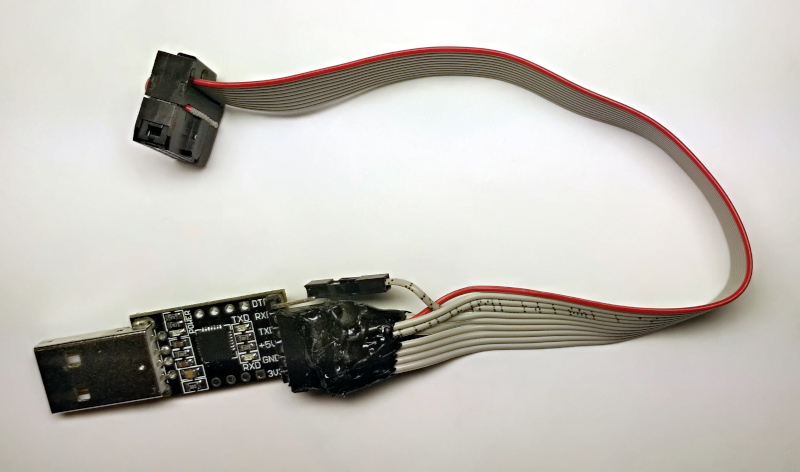
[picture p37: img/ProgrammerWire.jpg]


Connect it to the base station Prog connector. DTR pin must be disconnected.

If the station is sleeping, then it is not necessary to wake up it.
In the SportduinoPQ program, in the `Config` tab, in the `Config by UART` section
set the number of serial port corresponding the USB-to-TTL converter and click the `Write` button.
The current time and all other settings will be recorded in the base station.

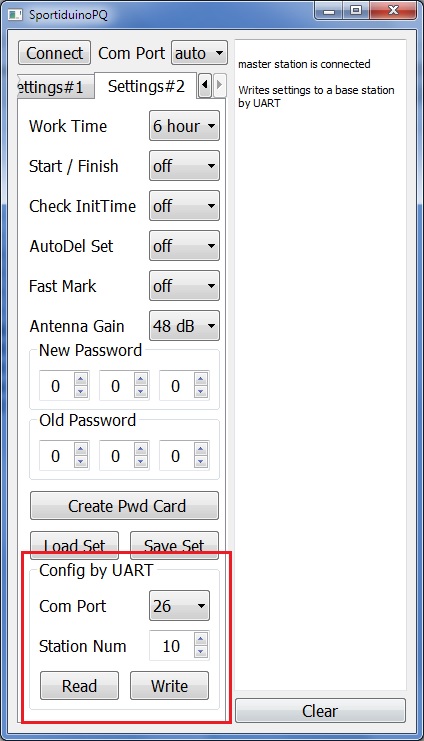
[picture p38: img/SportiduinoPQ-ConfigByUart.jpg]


To make sure that the settings are recorded correctly click on the `Read` button.
After that the current station settings will appear on the screen.
The station will remain in current mode.

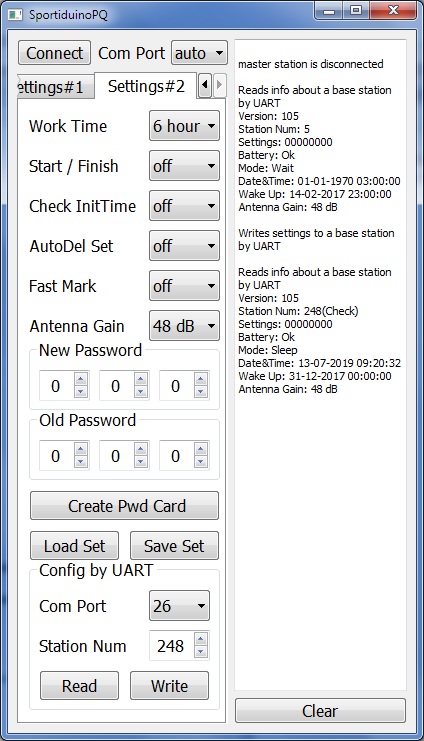
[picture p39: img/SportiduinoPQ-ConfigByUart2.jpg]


**Warning!**
Set the current password correctly in the SportduinoPQ program.
After the station is assembled the default password is 0-0-0.
If you do not correctly set the password, the base station will not accept settings from the master card.
You can reset password by writing new settings by UART.

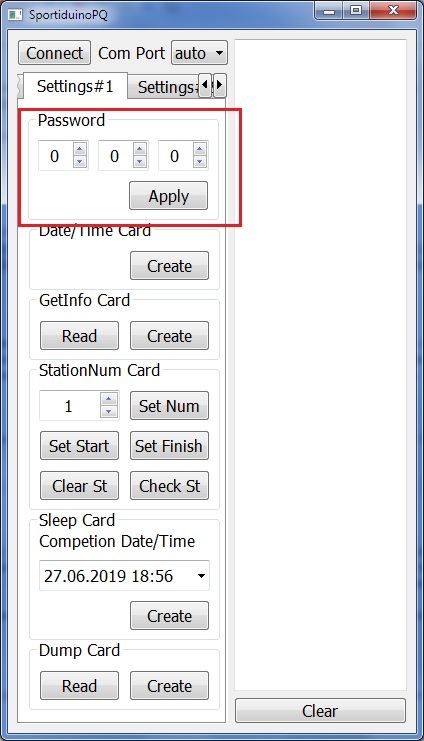
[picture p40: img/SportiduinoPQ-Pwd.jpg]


### Master cards

Another and main way to set up a station is master cards.
The master card is an ordinary card with settings written to it or commands for transmitting them to the base station.
To record a master card you need to bring it to the master station and press the appropriate button on the `Card` tab.
It is recommended to select the cards specifically for using as master and mark it
to avoid getting it in a heap of participants' cards.

To set up the stations, if they are in Sleep mode, you must wake up them first.
To do this, bring any card for up to 30 seconds.
After 3 seconds of LED lighting the station will beep once (the battery Ok) or beep 4 times (the battery is low).

### Station time setting

To set the time you need to bring card to the master station and click `Create` in the `Date/Time Card` section in the `Card` tab.

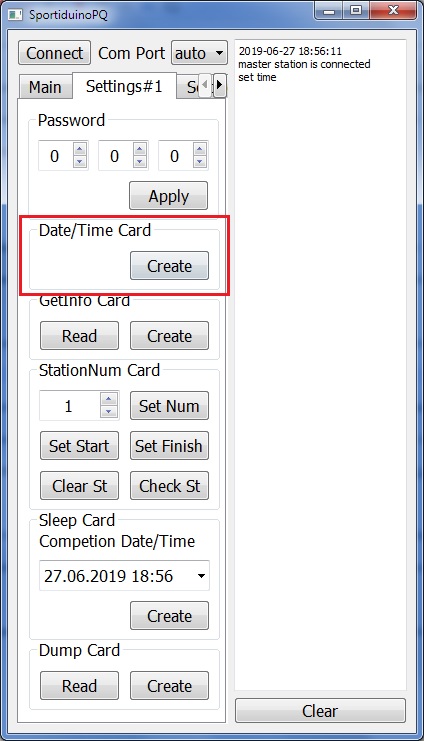
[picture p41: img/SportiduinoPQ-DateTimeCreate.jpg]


The station will beep 4 times.
After the third signal bring the card to the base station.
The station will beep once.
If the last beep of the master station and the beep of the base station have merged into one then the time is set accurately.
Process the time setting in the Active mode due to the shorter card poll period.

The accuracy of the clock is 1 second per week.
For the Start and Finish stations it is recommended to update the time on the day of the competition.

### Assigning Station Number

In the SportiduinoPQ program in the `Card` tab set the station number (from 1 to 239),
bring the card to the master station and press the `Set Num` button.
Then bring this card to the base station.
The station will beep once.

There are separate buttons for special stations (Start, Finish, Clear and Check).

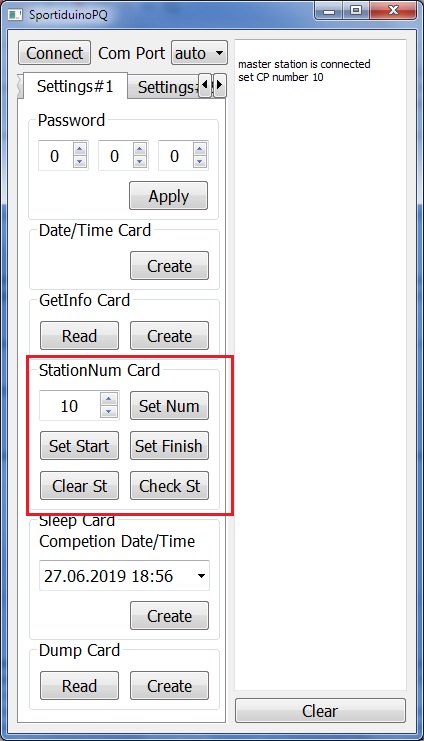
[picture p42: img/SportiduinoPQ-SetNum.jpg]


### Put stations into Sleep mode

After the competition it is recommended to put all stations into Sleep mode to extend battery life.
To do this bring the cart to the master station.
In the SportiduinoPQ program in the `Card` tab click `Create` in the `Sleep Card` section.
Then bring the created master card to the base station.
The station will beep 4 times and will go into Sleep mode.
To awakening stations you need to bring a participant card to it for up to 30 seconds.

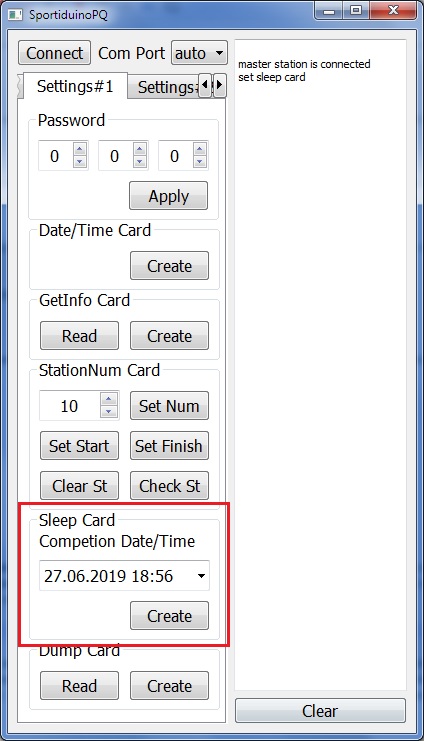
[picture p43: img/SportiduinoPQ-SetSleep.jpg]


When creating a Sleep card you can specify the date the station automatically wakes up in the `Wake Up Time` field.
At this time the base station will automatically switch to Active mode and the first participant will not have to wait a second for punching.
If you want to put the base stations into Sleep mode for a long time then set any past date and time.

### Other base station settings

The duration of the Active mode, additional checks and antenna gain of the base station can be set on the tab `Config`,
and record to the station using the master card.

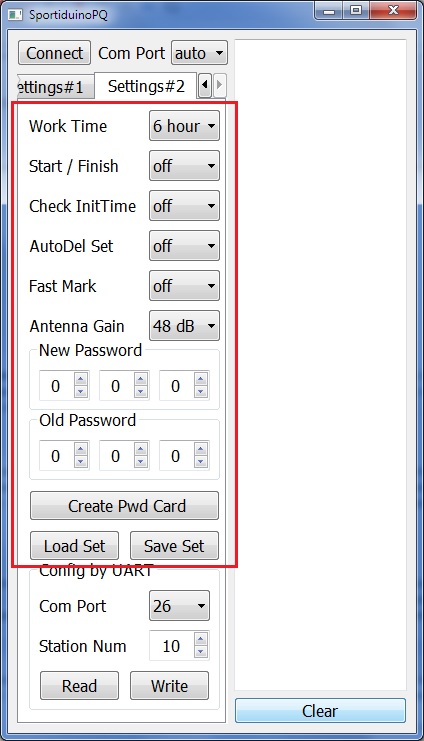
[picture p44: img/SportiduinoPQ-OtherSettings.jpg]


Using passwords protects unauthorized change of the stations settings.
After the build, the default password is 0-0-0.
If you set a new password and forget it then to reset the password you will need to update the settings by UART.
It is recommended that you keep your password in a safe place.

Settings details:
- `Active Time` — the working time in active mode.
If during this time no one punch at the station the station will go to the Waiting mode.
- `Start as Check` — enables checking no punches before start on participants' cards.
- `Check InitTime` — enables checking the initialization time of card.
- `Fast Punch` — enables quick punching mode.
This reduces the time spent by the participant when the base station records the punch on the participant's card.
But it also reduces the resource life of the cards and its will fail faster.
- `Antenna Gain` - gain of MFRC522 module.

### Reading Station Backup Memory

During the work, the base station reads punches to the internal memory.
It is true only for cards with numbers up to 4000.
Using this function, it is possible to recover of the data in case of card lost, check of controversial situations, and also in the search for lost participants.

To read the backup you need to create the master card.
Bring the card to the master station and in the SportiduinoPQ program click `Create` button in the `Dump Card` section in the `Card` tab.
Then bring the master card to the base station.
The process is long, you need to carefully keep the card in the optimal recording area above the center of the white circle.
After successful bring the card to the master station and click `Read` button in the `Dump Card` section.
The result will be displayed in the log area.

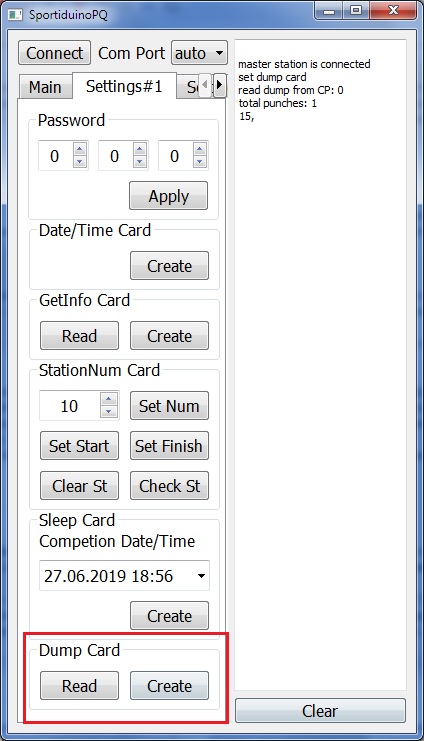
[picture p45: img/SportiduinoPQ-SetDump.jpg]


### Checking base stations

To check the settings of the base station, the battery charge level and its current operation mode
create the State master card in the SportiduinoPQ program.
In the `Card` tab click `Create` button in the `State Card` section and after that bring the created master card to the base station.
If the base station is in Sleep mode, you will need to wait for 30 seconds.
The base station will turn on the LED for 3 seconds and beep once,
after that the master card should be removed.
If the base station was in Sleep mode, then it will remain so in it, it does not need to be transferred again to Sleep mode.
If within 30 seconds the base station does not respond to the card then it is broken or the battery is low or the master card should be recreated.
After the base station has recorded the information on the master card
bring the master card to the master station and in the SportidunoPQ program click `Read` in the `State Card` section.
After that all information about the base station will be displayed in the log area.
Also the field values in all tabs of the SportiduinoPQ will changed in accordance with the current settings of the base station.

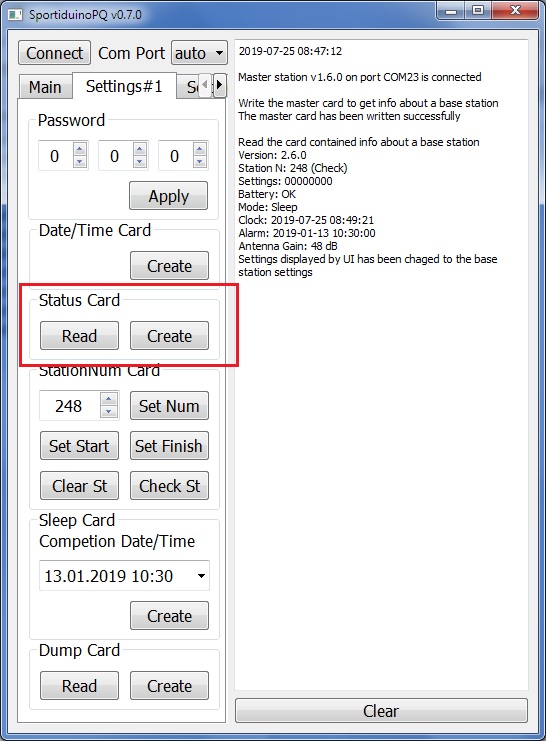
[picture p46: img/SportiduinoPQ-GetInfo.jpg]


## Reading cards and preparing results

It is recommended to use the SportOrg program for reading cards and generating results.
The peculiarity of using this program is that it is necessary to use the Start station (240) and the Finish station (245),
otherwise an error will occur when reading.

You can also use SportiduinoPQ to quickly view punches from cards.
To do this bring the card to the station and in the `Main` tab, click `Read Card` button. 
The result will be displayed in the log area.

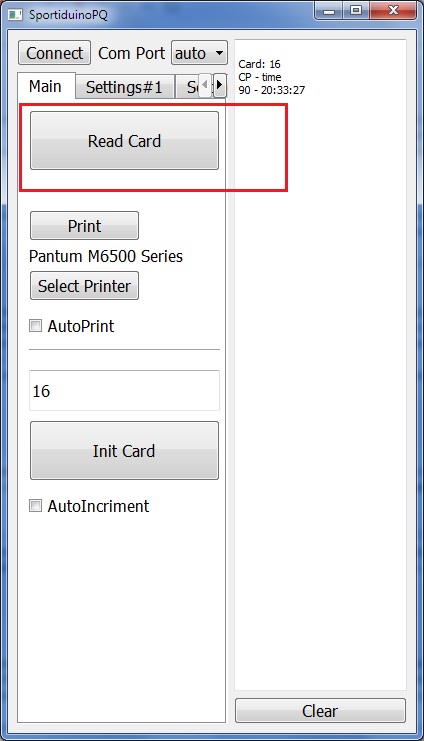
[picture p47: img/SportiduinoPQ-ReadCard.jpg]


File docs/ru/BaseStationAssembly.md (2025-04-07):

# Сборка станции отметки

Инструкция по сборке станции v3 с питанием от 3-х элементов АА (ААА) в корпусе Gainta G1020BF
(архивные инструкции для версий плат [v2](https://github.com/sportiduino/sportiduino/blob/v2.6.3/Doc/ru/BaseStationAssembly.md) и [v1](https://github.com/sportiduino/sportiduino/blob/1.3.7/Doc/ru/BaseStationAssembly.md)).

### Компоненты станции отметки

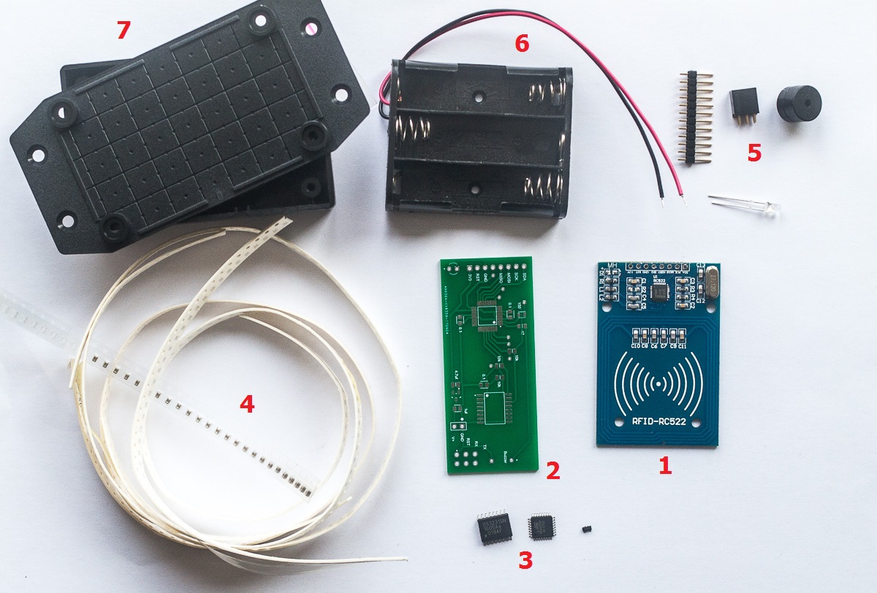
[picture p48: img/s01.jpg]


1. RFID-модуль RC522.
2. Печатная плата. Можно заказать через [EasyEDA](https://easyeda.com/order), [JLCPCB](https://jlcpcb.com/) или AliExpress.
Gerber-файлы находятся в папке `hardware/BaseStation/prod/v3`. *На фото представлена печатная плата версии 1.*
3. Микросхемы
   - Микроконтроллер ATmega328P-AU 
   - Часы DS3231SN 
   - Память 24LC256T-I/SN (опционально, нет на фото)
   - Стабилизатор напряжения MCP1700T-33. 
   - Транзистор BSS138 в корпусе SOT-23.
4. Пассивные компоненты в формате 0805. 
   - Резистор 100 Ом, 1 шт.
   - Резистор 3,3 кОм, 2 шт.
   - Резистор 10 кОм, 2 шт.
   - Резистор 33 кОм, 2 шт.
   - Резистор 68 кОм, 1 шт.
   - Резистор 270 кОм, 1 шт.
   - Конденсатор 0,1 мкФ, 7 шт.
   - Конденсатор 4,7 мкФ, 2 шт.
   - Индуктивность 2,2 мкГн, ток насыщения > 500 mA (например, LQH32MN2R2K), 2 шт, опционально.
5. Выводные компоненты
   - Разъём 8 контактов PLS-8 на плату ("гребёнка"). Идёт в комплекте с RFID-платой.
   - Разъём 10 контактов BH-10 (DS1013-10S или IDC-10MS). Можно заменить любой вилкой на плату 2x5 с шагом 2,54 мм.
   - Разъём 2 контакта JST XH с шагом 2,54 мм, вилка на плату.
   - Светодиод 3 мм.
   - Пассивный зуммер 12085 16 Ом, TR1205Y или HCM1203A.
   - Геркон замыкающий 2x14 мм (опционально, нет на фото).
6. Батарейный отсек 3xAA или 3xAAA (тогда корпус будет закрываться проще).
7. Корпус Gainta G1020BF.

Оборудование, которое пригодится при сборке, приведено [на отдельной странице](Equipment.md).

### Подготовка RFID-модуля

У модуля необходимо выпаять светодиод D1 и резисторы R1 и R2, иначе потребление тока во время его работы будет выше.

Также рекомендуется заменить индуктивности L1 и L2 на аналогичные 2,2 мкГн,
но с большим рабочим током для усиления антенны. Например, Murata LQH32MN2R2K (Спасибо за совет Александру Якимову).

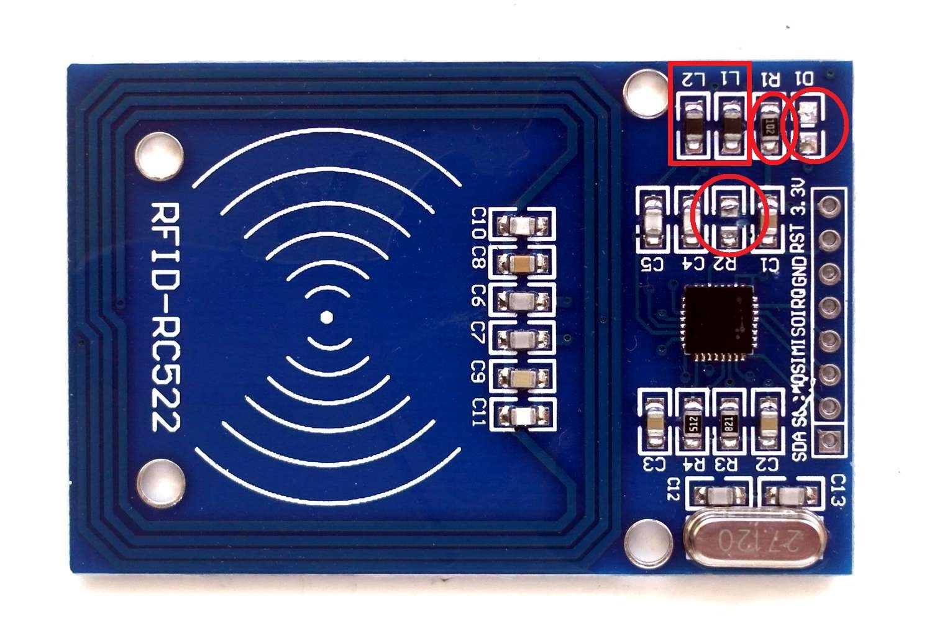
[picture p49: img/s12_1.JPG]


### Пайка основной платы

Принципиальная схема

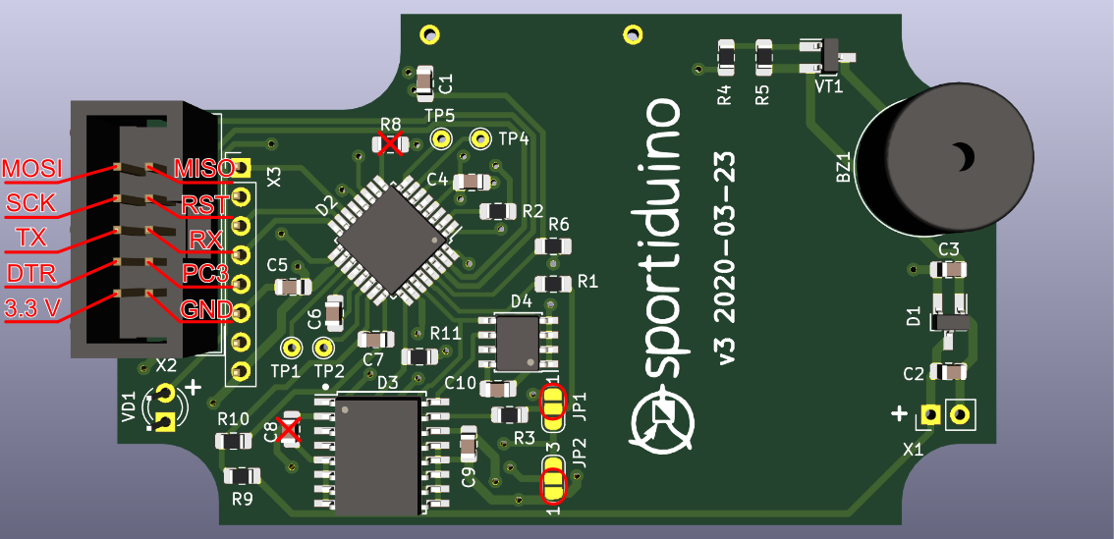
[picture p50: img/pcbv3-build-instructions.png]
Расположение компонентов


Обильно промазываем флюсом все места будущей пайки.
Далее припаиваем микросхемы.
После микросхем припаиваем транзистор, стабилизатор напряжения, резисторы и конденсаторы.
Резистор R8 и конденсатор C8 можно не припаивать, так как они сейчас не используются и зарезервирован для будущих версий.
Контактные площадки JP1 и JP2 замыкаем каплей припоя или перемычками, как показано на принципиальной схеме (контакты 1 и 2).
В конце припаиваем светодиод, зуммер, "гребёнку" и батарейный отсек.
Светодиод припаиваем с обратной стороны платы.
Вместо выводного светодиода можно припаять SMD-светодиод от RFID-модуля.
Модуль RC522 пока не припаиваем.

**Внимание!** Не перепутайте при пайке полярность у светодиода и зуммера.

### Программатор

Для загрузки на микроконтроллер bootloader потребуется программатор.
Если у вас нет программатора, то его можно сделать из Arduino Nano.

#### Программатор из Arduino Nano

Для его изготовления потребуется шлейф на 10 проводов длиной 25 см и разъём IDC-10F (DS1016-10).
Вместо этого разъёма можно использовать любой другой типа розетка 2x5 с шагом 2,54 мм.

На конце шлейфа устанавливается разъём.
Другой конец шлейфа припаиваем к плате Arduino Nano в соответствии со схемой.
При этом пока не устанавливаем конденсатор 10 мкФ 16В.

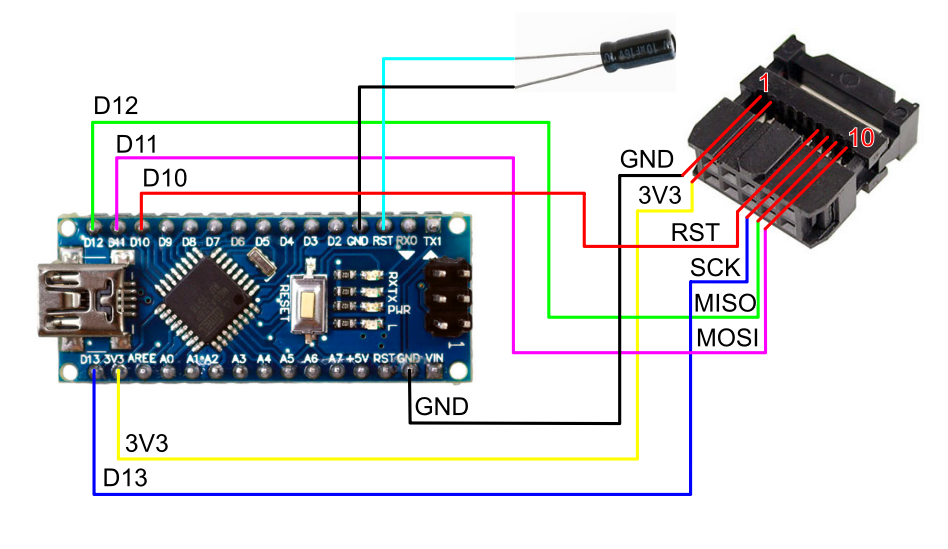
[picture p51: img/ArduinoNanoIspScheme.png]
Схема программатора из Arduino Nano


Далее подключаем Arduino Nano к ПК через USB и запускаем Arduino IDE.
Открываем скетч ArduinoISP из примеров Arduino (Файл->Примеры->ArduinoISP).
Далее в меню `Инструменты` выбираем плату `Arduino Nano`, процессор `ATmega328P (Old Bootloader)` и соответствующий порт.

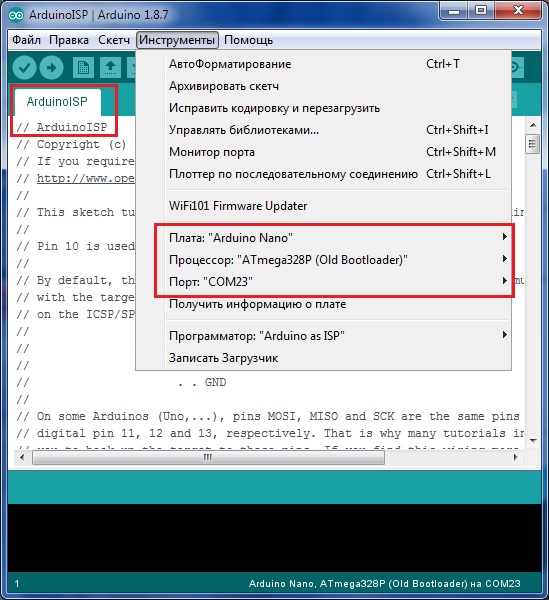
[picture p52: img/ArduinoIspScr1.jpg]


Выполняем Скетч->Загрузка.
После этого припаиваем конденсатор на 10 мкФ 16В между GND и RST как на схеме выше.
Если не припаять конденсатор, то при программировании постоянно будет появляться сообщение об ошибке:
`avrdude: stk500_getsync() attempt 1 of 10: not in sync: resp=0x15`.
Программатор готов.

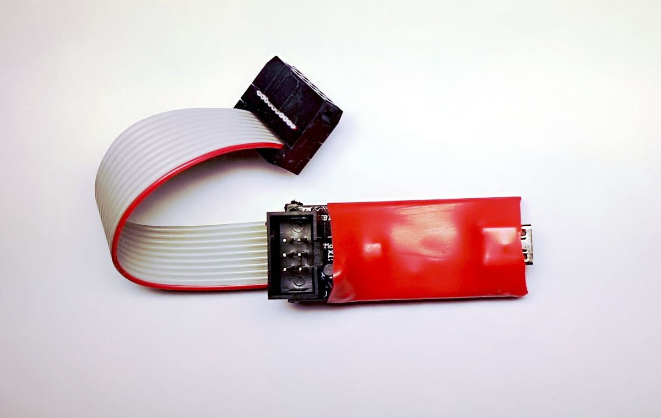
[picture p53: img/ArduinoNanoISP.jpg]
Программатор из Arduino Nano


### Преобразователь USB-UART

Для загрузки на микроконтроллер основной прошивки потребуется USB-UART преобразователь.
У преобразователя обязательно должен быть сигнал DTR.
Для его подключения к плате станции также нужен шлейф на 10 проводов и разъём IDC-10F.

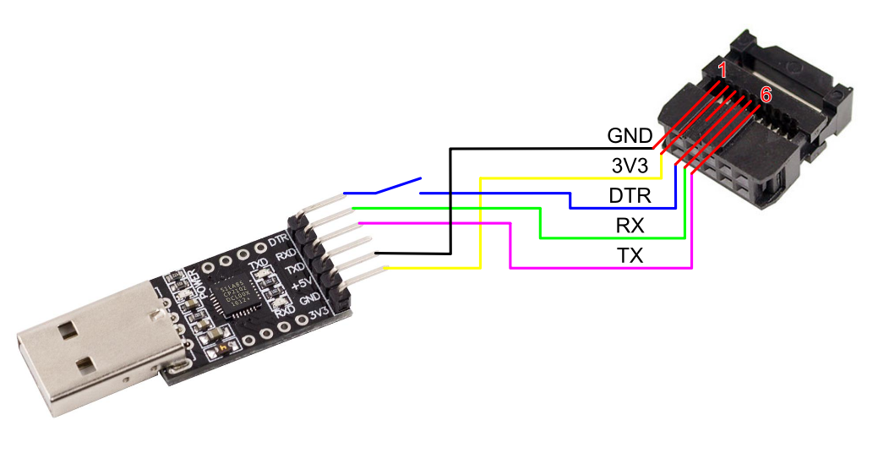
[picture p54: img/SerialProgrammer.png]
Схема подключения USB-UART


Если помимо загрузки прошивки преобразователь будет использоваться также для настройки станции и для чтения её состояния,
то при подключении шлейфа к преобразователю нужно предусмотреть возможность отключения проводника от вывода DTR.

Преобразователь USB-UART

### Прошивка микроконтроллера

Выполняем предварительную [настройку Arduino IDE](ArduinoIde.md).

В Arduino IDE открываем скетч BaseStation (Файл->Папка со скетчами->BaseStation).
В меню Инструменты->Плата выбираем `Sportiduino Base Station`.
Далее в меню Инструменты->Программатор выбираем `Arduino as ISP`. 



Рекомендуется выбрать загрузчик "Optiboot 19200 with LED" в меню Инструменты.

Если на плате установлен активный зуммер, то выбираем "Buzzer frequency: 0 kHz (active buzzer)" в меню Инструменты->Программатор.

Подключаем наш программатор к плате Sportiduino и вставляем батарейки в батарейный отсек для более стабильной записи загрузчика и прошивки.

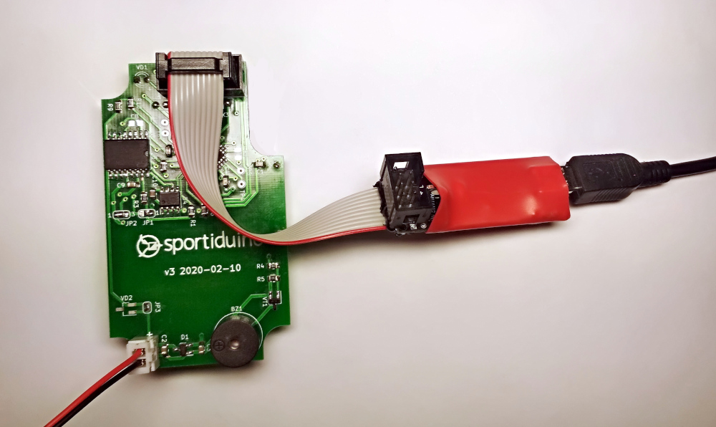
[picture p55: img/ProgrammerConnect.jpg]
Подключение программатора


Выполняем Инструменты->Записать загрузчик.
Если появилось сообщение об ошибке в логе, то проверяем сборку программатора и его подключение к плате, проверяем сборку самой платы.
Если всё прошло успешно, то отключаем программатор.

Подключаем преобразователь USB-UART.

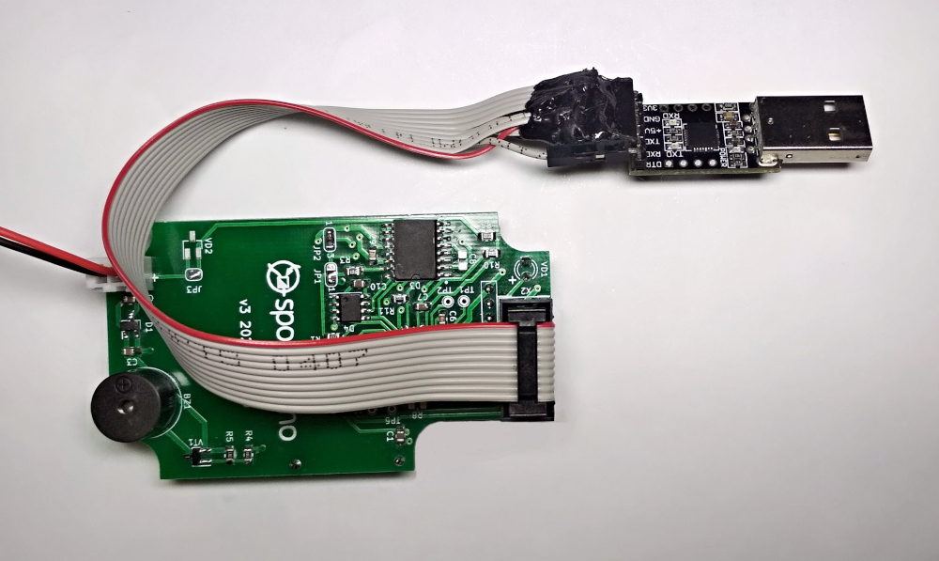
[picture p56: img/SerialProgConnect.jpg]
Подключение преобразователя USB-UART


Выполняем Скетч->Загрузить.
После завершения загрузки станция должна подать три коротких сигнала и через 3 секунды один длинный.
Если этого не произошло, то необходимо проверить пайку платы.

### Пайка RFID-модуля и проверка

После прошивки микроконтроллера припаиваем RFID-модуль и геркон (опционально) к нашей плате.

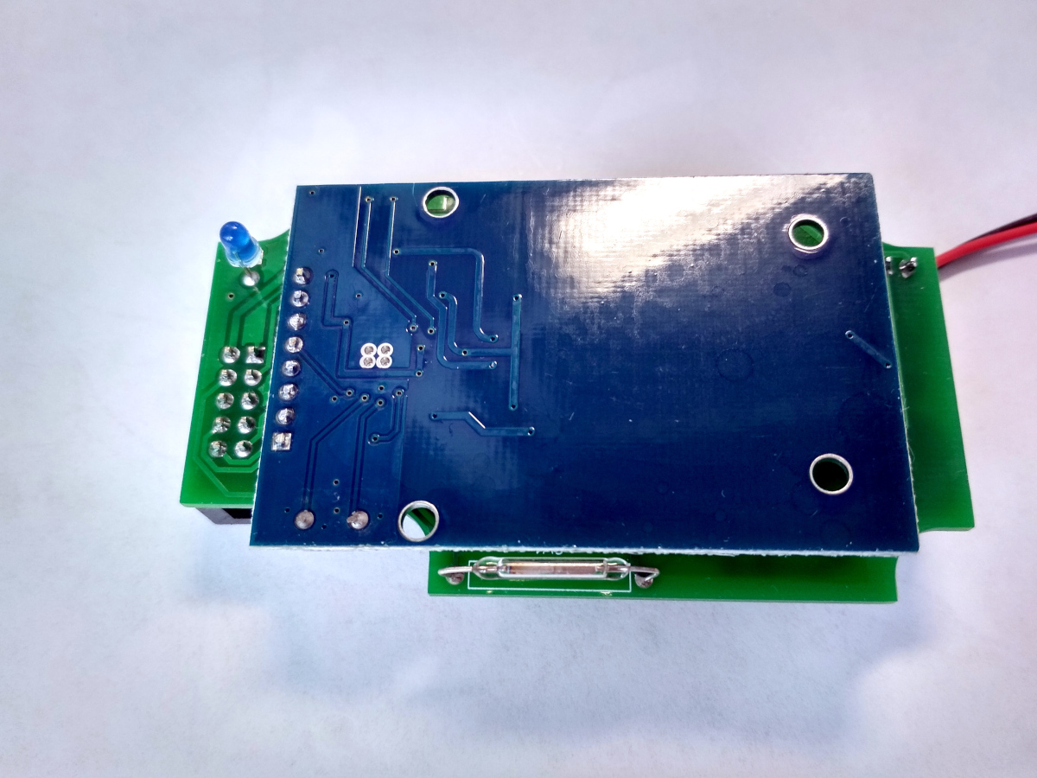
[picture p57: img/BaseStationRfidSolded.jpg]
Плата с припаянным RFID-модулем и герконом
 

Затем проверяем работу станции.
Предварительно стоит записать мастер-чипы номера станции, времени и несколько обычных чипов.
После подачи питания станция подаст три коротких сигнала, что говорит о том, что часы не выставлены.
Затем через несколько секунд будет длинный сигнал, сигнализирующий, что питание в норме и программа вошла в цикл работы.
По умолчанию станция работает в режиме ожидания и проверяет наличие чипа в рабочей зоне раз в секунду.
Приложите мастер-чип номера станции. Станция запишет новый номер и теперь уже способна реагировать на обычные чипы.
Далее необходимо настроить часы.
Подносим мастер-чип времени и после установки подносим второй обычный чип.
Считываем его на станции сопряжения и убеждаемся в корректной работе.

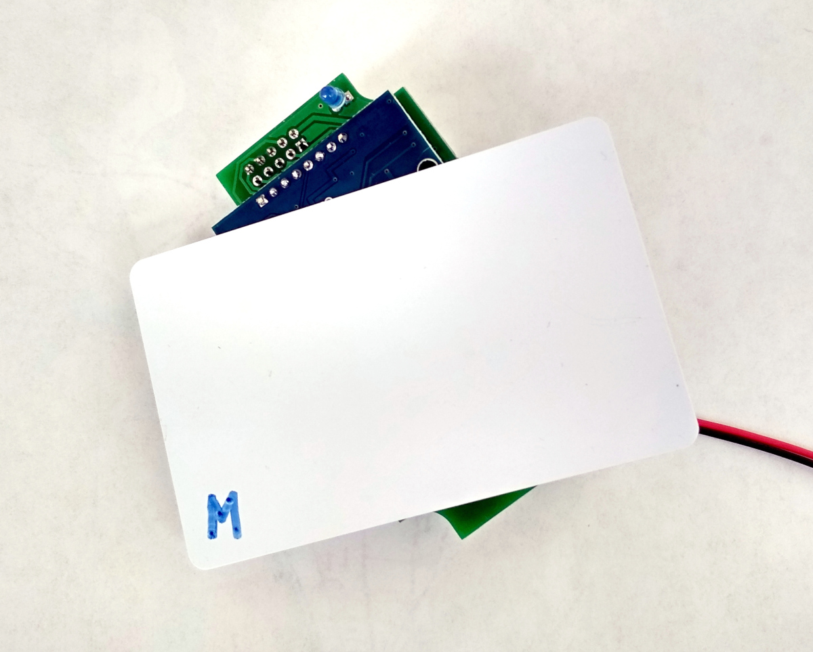
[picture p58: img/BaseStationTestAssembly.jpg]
Проверка работы старции


Для проверки работоспособности геркона нужно подготовить специальный чип,
который будет использоваться для быстрого пробуждения станций.
Для этого приклеиваем магнит с краю чипа.

Усыпляем станцию чипом сна и пробуждаем чипом с магнитом.

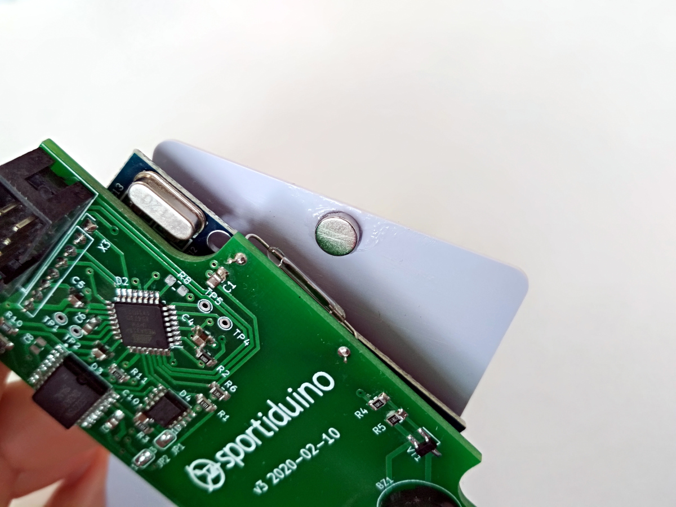
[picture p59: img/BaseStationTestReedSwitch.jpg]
Проверка работы геркона


Если станция прошла проверку, то плату желательно отмыть от остатков флюса изопропиловым спиртом
или специальным средством (например, FluxOff).
Если плата не работает, то нужно проверить прежде всего пайку микросхем и соединение с RFID-модулем.

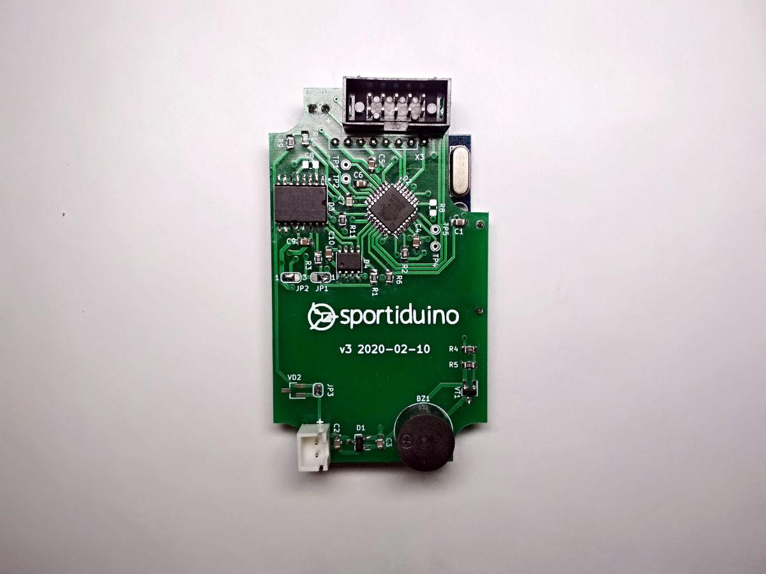
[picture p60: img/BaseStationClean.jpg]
Готовая плата после отмывки


### Установка в корпус

В корпусе сначала нужно просверлить отверстие для светодиода 3 мм.
Координаты отверстия показаны на рисунке ниже.
Чтобы влага не попадала внутрь через это отверстие,
его необходимо заклеить с обратной стороны скотчем, а с другой стороны залить термо- или эпоксидным клеем.

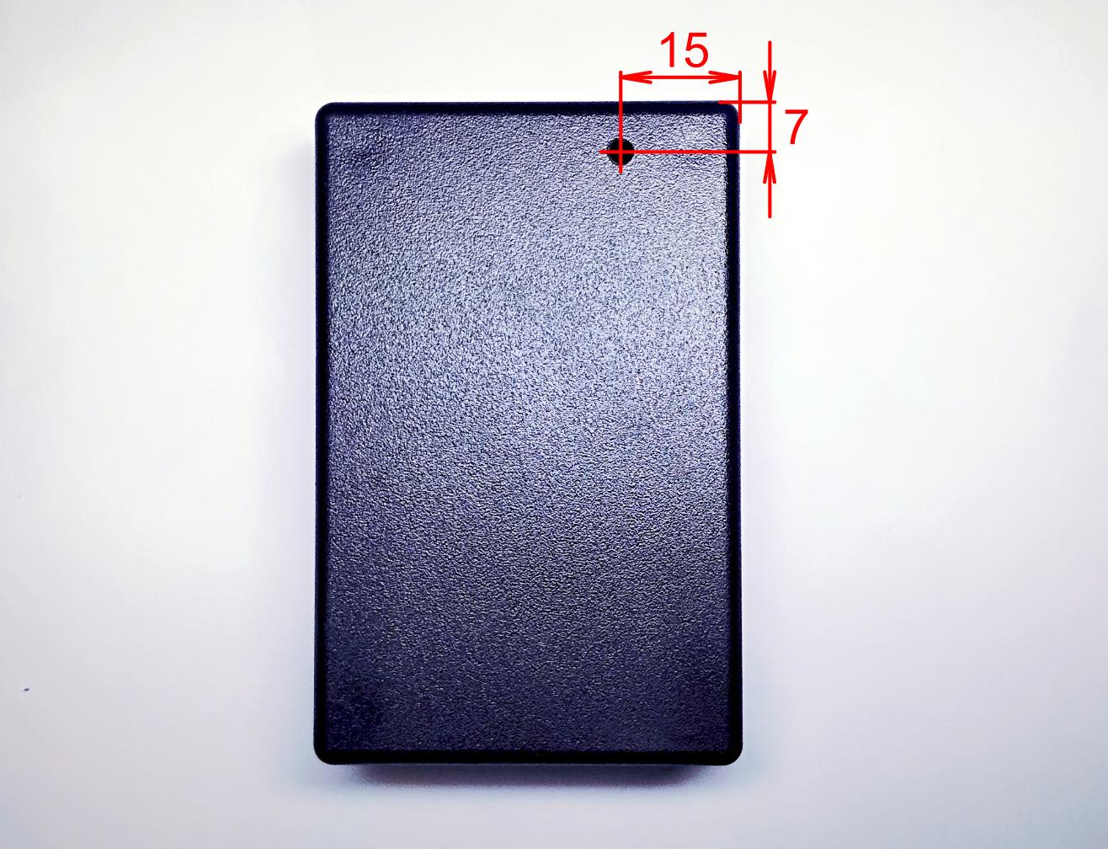
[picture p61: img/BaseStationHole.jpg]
Положение отверстия


Далее можно приклеить батарейный отсек к крышке корпуса.

После этого устанавливаем плату так, чтобы светодиод попадал в центр просверленного отверстия.

Закрепляем плату термоклеем.
*На фото плата версии 2.*

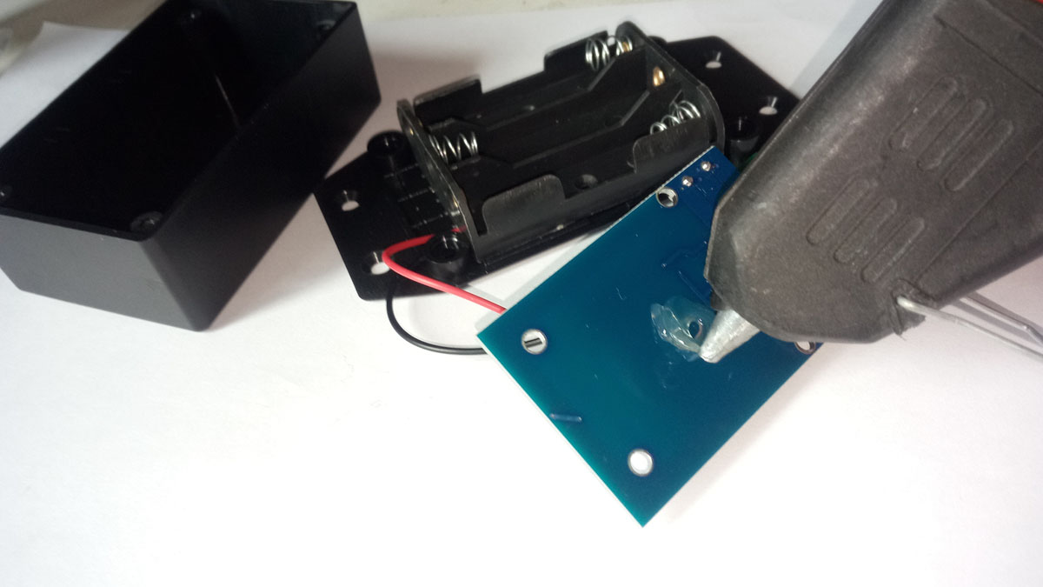
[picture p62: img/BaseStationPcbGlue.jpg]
Закрепляем плату термоклеем


Плата в корпусе

После этого можно залить корпус компаундом.
Или можно обойтись и без него. Например, если промазать стык корпуса силиконовым герметиком или приклеить крышку к корпусу.

*На фотографиях ниже показана плата версии 1.*

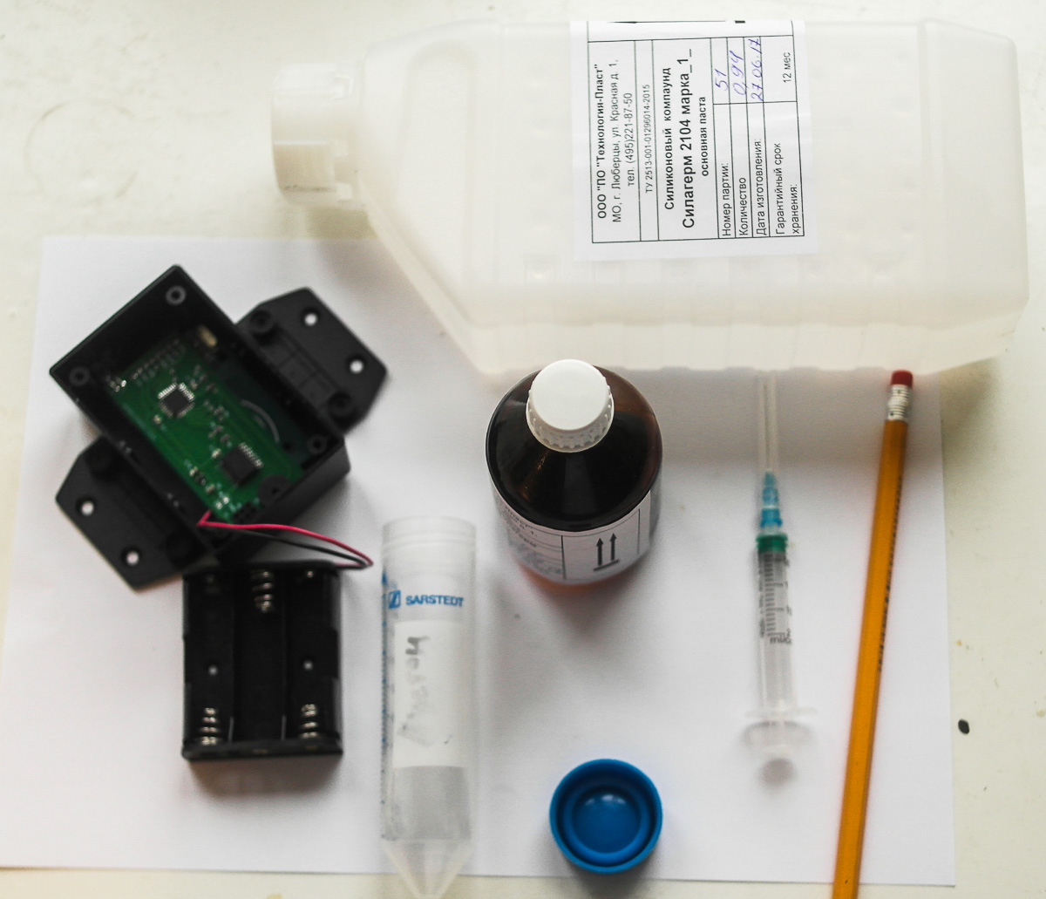
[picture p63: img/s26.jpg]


На 1 станцию отмеряем 30 мл компаунда

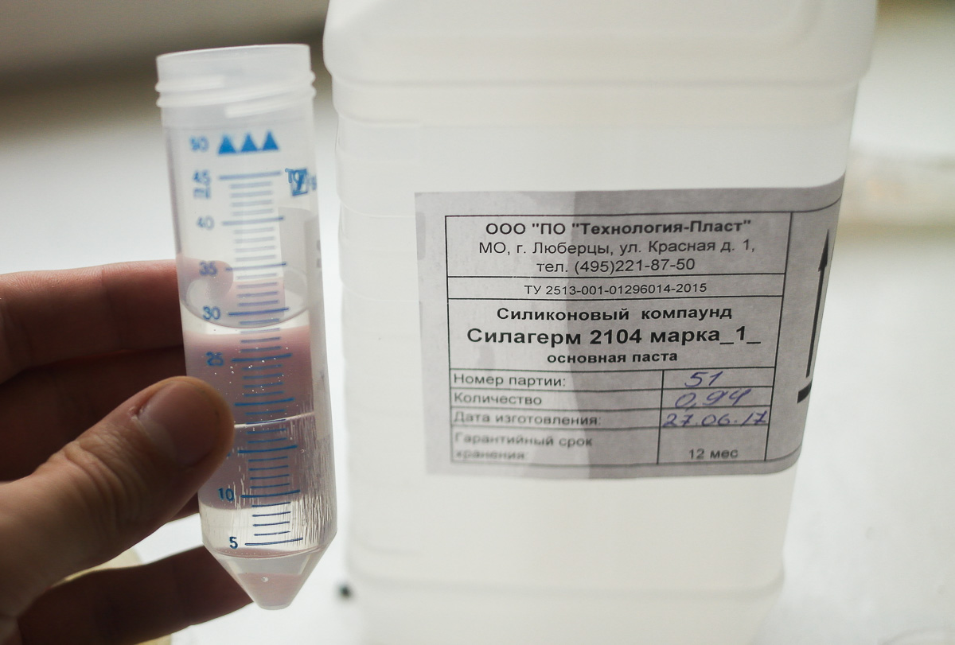
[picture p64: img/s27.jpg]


и 1 мл отвердителя. Перемешиваем отвердитель с компаундом.

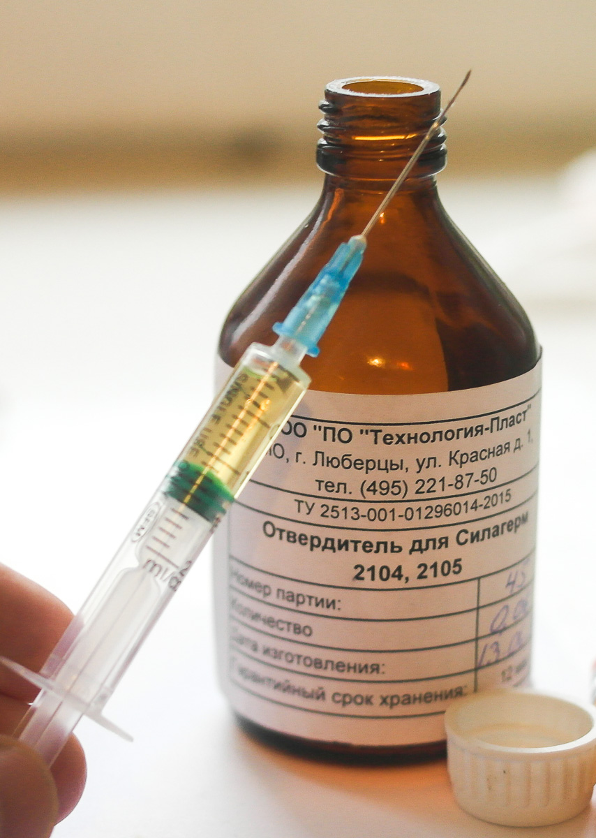
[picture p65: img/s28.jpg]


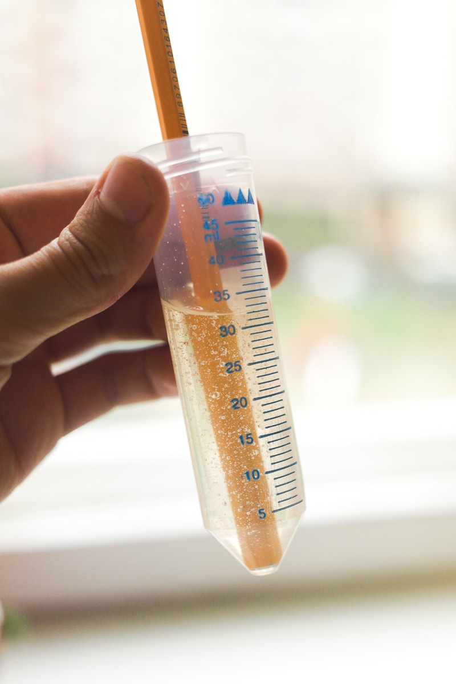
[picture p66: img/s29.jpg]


И заливаем нашу плату.
Должно получиться так, что все контакты залиты силиконом.
Выходят только разъём для программирования и зуммер.

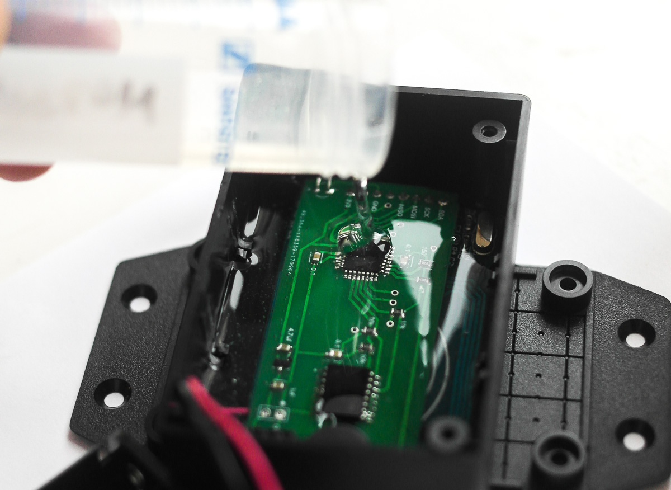
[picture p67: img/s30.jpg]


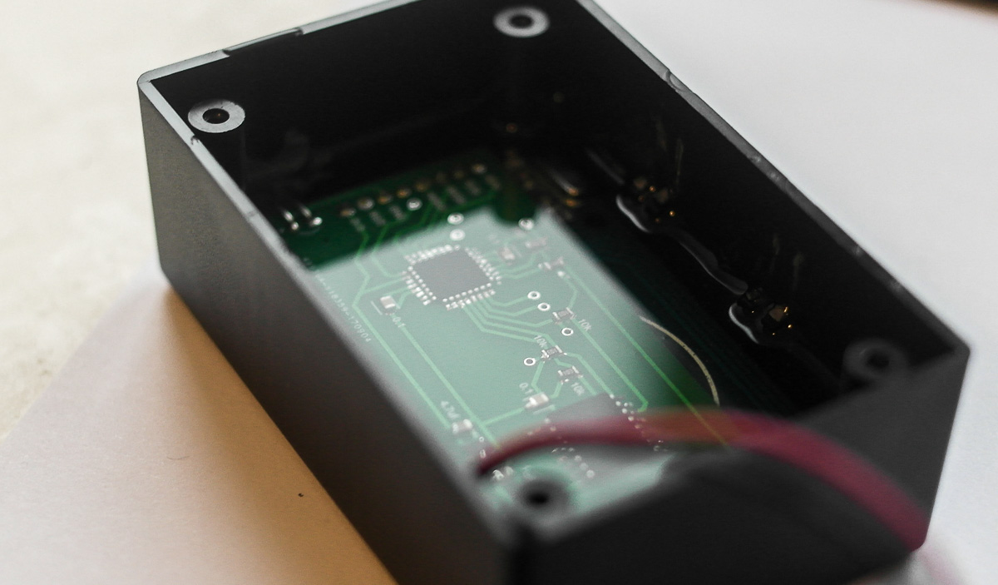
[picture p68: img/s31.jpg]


Через сутки компаунд полностью затвердевает.
При этом все детали хорошо видно. В случае необходимости ремонта компаунд можно легко частично удалить.

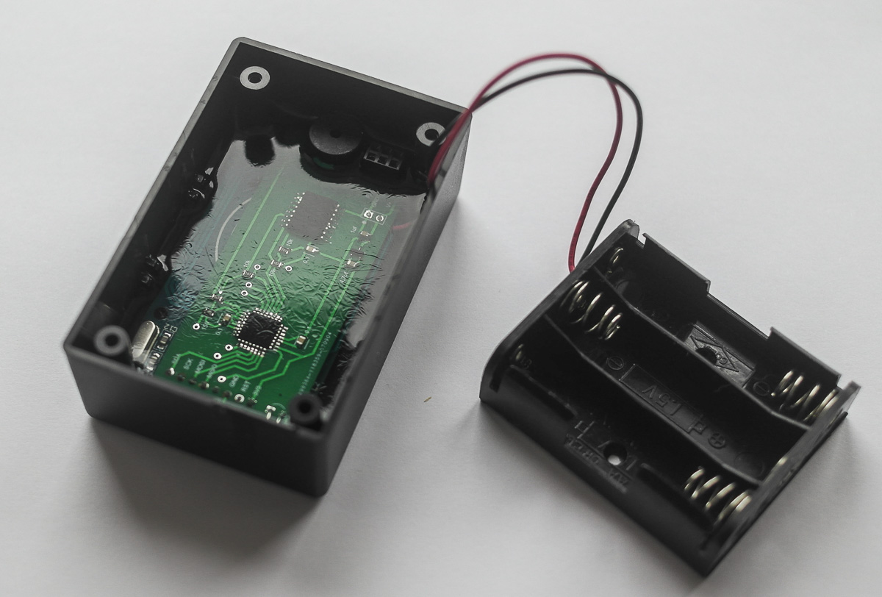
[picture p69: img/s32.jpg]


Батарейный отсек промазываем вазелином или другим густым гидрофобным маслом и вставляем батарейки.

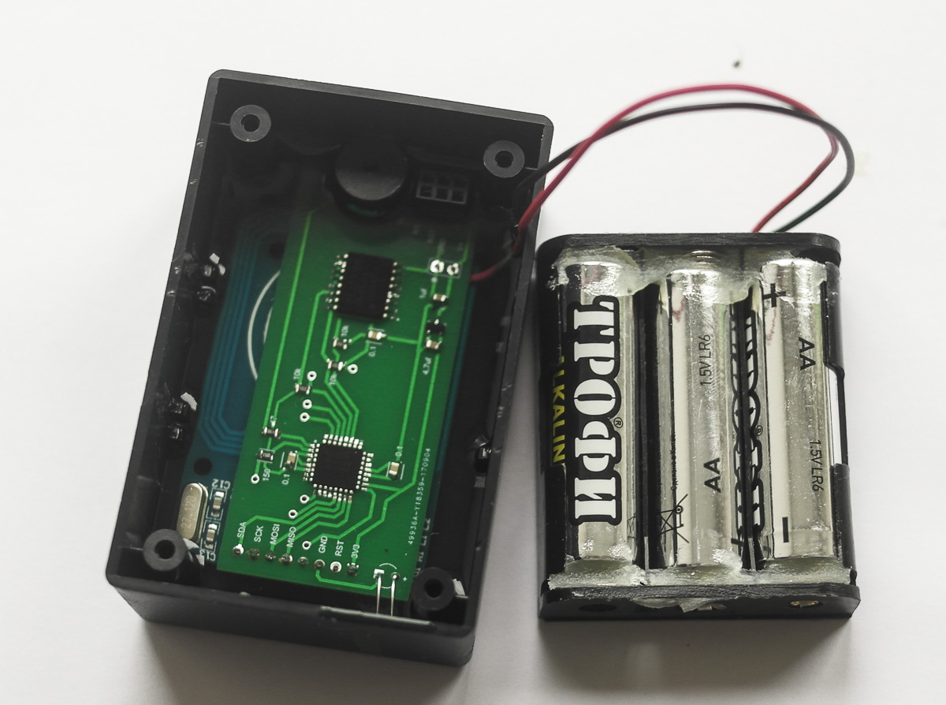
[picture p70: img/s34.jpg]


И закручиваем наш корпус. Детали лежат туго, может понадобиться небольшое усилие, чтобы закрыть корпус.

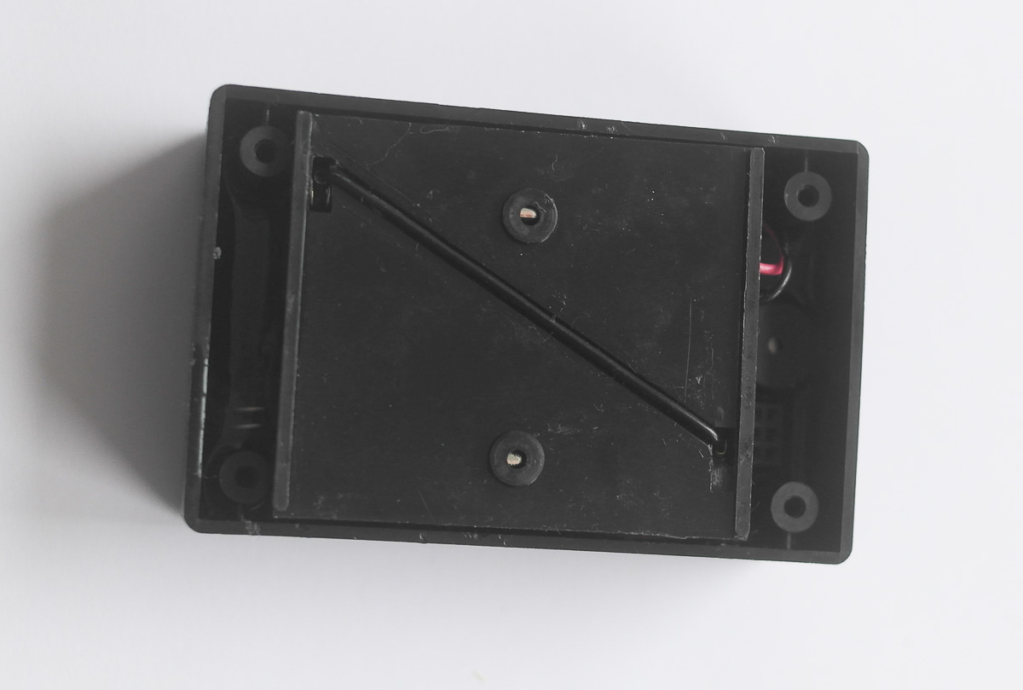
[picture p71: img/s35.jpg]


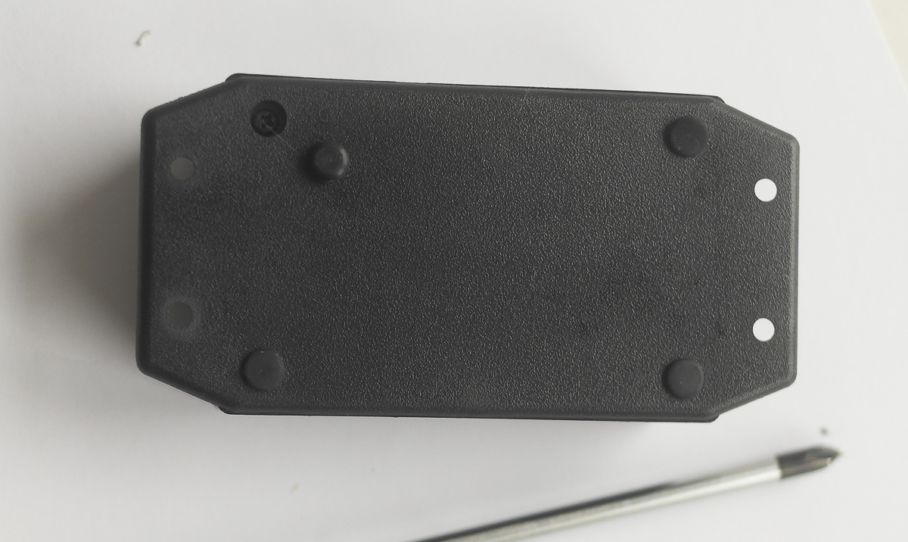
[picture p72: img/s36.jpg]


Печатаем на принтере наклейки из папки `hardware/BaseStation/2d`.
Наклейки выполнены в программе Inkscape.
Можно заказать печать наклеек на светоотражающей или светонакопительной плёнке.
Приклеиваем наклейку и сверху ламинируем её скотчем, если наклейка из простой бумаги.
Станция готова!





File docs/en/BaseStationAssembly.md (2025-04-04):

# Base station assembly

This instruction for assembling Base station v3.

### Base station components



1. RFID module RC522.
2. PCB. Can be ordered via [EasyEDA](https://easyeda.com/order), [JLCPCB](https://jlcpcb.com/) or AliExpress.
Gerber files are placed in the folder `hardware/BaseStation/prod/v3`.
*It is not in the photo PCB v1.*
3. Chips
   - Microcontroller ATmega328P-AU.
   - DS3231SN clock.
   - Memory 24LC256T-I/SN (optional, not in the photo).
   - Voltage regulator MCP1700T-33.
   - Transistor BSS138 SOT-23.
4. Passive components in the 0805 format.
   - Resistor 100 ohm, 1 pc.
   - Resistor 3.3 kOhm, 2 pcs.
   - Resistor 10 kOhm, 2 pcs.
   - Resistor 33 kOhm, 2 pcs.
   - Resistor 68 kOhm, 1 pc.
   - Resistor 270 kOhm, 1 pc.
   - Capacitor 0.1 uF, 7 pcs.
   - Capacitor 4.7 uF, 2 pcs.
   - Inductor 2.2 uH, max current > 500 mA (e.g. LQH32MN2R2K) 2 pcs, optional.
5. Through-hole components
   - Connector 8 pins PLS-8. Come with RFID board.
   - Connector 10 pins BH-10 (aka DS1013-10S or IDC-10MS). It can be replaced by any male connector 2x5 pins 2.54 mm.
   - Connector 2 pins JST XH 2.54 mm.
   - LED 3 mm. Any color for your choice.
   - Passive buzzer 12085 16 ohm, TR1205Y or HCM1203A.
   - Reed switch normally open 2x14 mm (optional, not in the photo).
   - Connector 1x2 pins 2.54 mm for battery (optional, not in the photo).
6. Battery box 3xAA or 3xAAA.
7. The Gainta G1020BF case.

Equipment which is useful for assembly is given [on a separate page](Equipment.md)

### RFID module preparing

Remove LED D1, resistors R1 and R2 to reduce module power consumption.

Replace inductors L1 and L2 by similar 2.2 uH, but with a large operating current to increase the antenna power (e.g. Murata LQH32MN2R2K).



### Soldering the main board

Scheme

PCB with instructions

Grease flux all places of future soldering.
Next solder chips.
After chips solder the transistor, voltage stabilizer, resistors and capacitors.
Resistor R8 and capacitor C8 can not be soldered, since they are not used now and reserved for future versions.
Contact pads JP1 and JP2 are closed with a drop of solder or jumpers, as shown in the circuit scheme (pins 1 and 2).
At the end solder buzzer, RFID connector and battery box (or connector 1x2 pins).
Solder a LED on the back of the board.
Instead of the output LED, you can solder the SMD LED from the RFID module.
The RC522 module is not soldered yet.

**Warning!** Do not confuse the polarity of the LED and the buzzer when soldering.

### Programmer

To upload the bootloader to the microcontroller, you need a programmer.
If you do not have a programmer then it can be made from Arduino Nano.

#### Arduino Nano based programmer 

To make it, you will need a flat cable for 10 wires 25 cm long and an IDC-10F connector (aka DS1016-10).
Instead of this connector, you can use any other type of 2x5 pin 2.54 mm female connector.

A connector is installed at the end of the cable.
Solder the other end of the cable to the Arduino Nano board in accordance with the scheme below.
We do not yet install a 10 μF 16V capacitor.

Arduino Nano programmer scheme

Connect the Arduino Nano to the PC via USB and launch the Arduino IDE.
Open the ArduinoISP sketch from Arduino examples (File -> Examples -> ArduinoISP).
In the `Tools` menu, select the `Arduino Nano` board, the `ATmega328P (Old Bootloader)` processor, and the corresponding port.



Perform Sketch -> Upload.
After that, solder the 10 uF 16V capacitor between GND and RST as in the scheme above.
If the capacitor is not soldered, an error message will constantly appear during programming:
`avrdude: stk500_getsync() attempt 1 of 10: not in sync: resp=0x15`.
The programmer is ready.

Arduino Nano Programmer

### Serial programmer

To upload the main firmware to the microcontroller, a USB-UART converter is required.
The converter must have a DTR pin.
To connect it to the station board, you also need a 10-wire flat cable and IDC-10F connector.

Serial programmer scheme

If the converter will also be used to configure the station and to read its state
then necessary to provide the possibility of disconnecting the DTR pin.

Serial programmer

### Arduino IDE Setting

In the File->Settings menu change the location of the sketch folder to `path/to/project/firmware`.

Next, create a description of Sportiduino board.
Open the file `path/to/Arduino/hardware/arduino/avr/boards.txt`
and add file `path/to/project/firmware/boards.txt` contents to the end of this file.

After that copy files \*.hex from the folder `path/to/project/firmware/Optiboot` to the folder `path/to/Arduino/hardware/arduino/avr/bootloaders/optiboot`.

Restart the Arduino IDE. In the Tools->Board menu our Sportiduino board should appear.

### Bootloader and firmware upload

In Arduino IDE, open the BaseStation sketch (File->Sketchbook->BaseStation).
In the Tools->Board menu select `Sportiduino`.
Next in the Tools->Programmer menu select `Arduino as ISP`.



Connect programmer to the board. Power on board.

Programmer connection

Execute Tools->Burn Bootloader.
If an error message appears in the log then check the assembly of the programmer and its connection to the board, check the assembly of the board itself.
If everything went well then turn off the programmer.

Connect the serial programmer.

Serial programmer connection

Execute Sketch->Upload.
After the upload is complete the station should beeps three times and beeps one long time after 3 seconds.
If this does not happen then check the soldering of the board.

### Soldering RFID to the board and testing 

After uploading the firmware to the microcontroller solder the RFID module and the reed switch (optional) to the board.

PCB with RFID and reed switch 

Then test the operation of the station.
Create master cards of the station number, time, and several regular cards.
After power-up, the station will give three short beeps, which indicates that the clock is not set.
Then after a few seconds there will be a long beep, indicating that the power is normal and the program has entered the work loop.
By default, the station operates in Wait mode and checks for the presence of a chip in the working area once per second.
Bring the Station number master card to the station.
The station will record a new number and is now able to respond to regular cards.
Next, configure the clock.
Bring the Time master card and after beep bring the second regular card.
Read it at the master station and make sure that base station clock works correctly.

Station testing

If the station passed the test, then the board can be washed off the flux residues, for example, in a bath with isopropyl alcohol.
If the board does not work then check first the soldering of chips and the connection to the RFID module.

Готовая плата после отмывки

### Installation in the case

In the case drill a 3 mm diameter hole for a LED.
The hole coordinates are shown in the figure below.
To prevent moisture from entering through this hole,
it must be sealed with adhesive tape on the reverse side, and on the other hand, filled with hot or epoxy glue.

Hole coordinates

Next, glue the battery box to the cover of the case (optional).

After that install the board so that the LED falls into the center of the drilled hole.

Fix the board with hot glue.
*In the photo show the PCB v2.*

Fix the board with hot glue

PCB in case

After that fill the compound (optional).
Or blur the joint of the housing with a silicone sealant, or glue the cover to the case.

*In the photos below show the PCB v1.*



At a station measure 30 ml of compound



and 1 ml of hardener. Mix the hardener with the compound.





And fill the board.
Silicone should fill all contacts.
There are only programmer connector and buzzer.





In a day the compound solidifies completely.
In this case, all the details can be seen, in which case the compound can easily be removed for repairing.



The battery box is smeared with petroleum jelly or other thick hydrophobic thick oil and insert batteries.
 


Close the case with the cover.
Parts lie tight, you may need a little effort to close the case.





Print stickers form the folder `hardware/BaseStation/2d`.
Glue the sticker on top of the station.

The station is ready!





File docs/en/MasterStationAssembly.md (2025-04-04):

# Master station assembly

### Master station components



1. RFID module RC522.
2. Arduino Nano.
You can connect directly to the computer.
There are variations on which chip USB-Serial is implemented: more expensive FT232RL or cheaper CHG340.
To connect the second you need to install the driver on Windows.
3. The PCB for soldering ([variant 1](https://upverter.com/AlexanderVolikov/3fc0efdb2586988d/Sportiduino-reading-stantion/) or
[variant 2](https://upverter.com/design/syakimov/4f7ec0e2d3b9c4e9/sportiduino-master-station/)).
You can order the manufacture of PCB in China (e.g. [JLCPCB](https://jlcpcb.com/)).
It is advisable to order boards for the master station simultaneously with the PCB for the base stations.
4. Pins, LED and buzzer. 
5. The case is Gainta 1020BF or 1015. Sold in Russia. 
6. USB-lace.
USB type depends on the port used in Arduino Nano (micro- or mini-USB).

### Arduino Nano preparation

First solder Arduino Nano.
ISP (2x3 connector) can not be soldered.



#### Arduino Nano preparation for SPORTident emulation

Remove capacitor at line DTR-Reset from Arduino Nano board.
It is located next to the USB controller chip.
After that burn fixed Optiboot bootloader (optiboot8_atmega328_38400_without_reset.hex)
using the ISP programmer.

### Station with PCB variant 1 and the G1020BF case

Solder Arduino Nano in the main board.
Also in the main board we solder a 1x8 connector, a angle-bent LED,
a buzzer and resistors 0805 47 ohm (to the buzzer) and 150 ohm (to the LED).



Solder the RFID module.
Then connect the master station via a USB wire to the computer.
 


Open the Arduino IDE program on the computer (see [Arduino IDE Setting](BaseStationAssembly.md#Arduino-IDE-Setting)).
In the settings specify the board type `Arduino Nano`, processor `ATmega328P (Old Bootloader)`
(`ATmega328P (without reset)` for SPORTident emulation).
Select the appropriate serial port and upload MasterStation sketch onto the board.

For USB cable cut off a s small groove in the case.
The LED is greased with epoxy glue.
 


After that close the case.
The master station is ready for use.



### Station without PCB

The master station can be assembled without a PCB.
The LED, buzzer and RFID module are soldered by wiring to the Arduino Nano according to the scheme.



The station case is designed for 3D-printing.
Files for 3D-printer placed in the folder `hardware/MasterStation/3d/print`.







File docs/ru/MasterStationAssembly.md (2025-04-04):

# Сборка станции сопряжения

Компоненты станции сопряжения



1. RFID-модуль RC522.
2. Arduino Nano.
Можно подключать напрямую к компьютеру.
Платы от разных производителей различаются чипом USB интерфейса: более дорогой FT232RL или более дешевый CHG340.
Для подключения второго нужно установить драйвера в Windows.
3. Плата для спайки ([вариант 1](https://upverter.com/AlexanderVolikov/3fc0efdb2586988d/Sportiduino-reading-stantion/) и
[вариант 2](https://upverter.com/design/syakimov/4f7ec0e2d3b9c4e9/sportiduino-master-station/)).
Можно заказать изготовление плат в Китае. Например, на [JLCPCB](https://jlcpcb.com/).
Целесообразно заказывать платы для станции сопряжения одновременно с платами для станций отметки. 
4. Штыревой разъём "гребёнка", светодиод и зуммер (электромагнитный или прьезоизлучатель).
5. Корпус Gainta 1020BF или 1015. Продаются в России.
6. USB-шнур.

### Подготовка Arduino Nano

Если гребёнки идут отдельно от платы, впаиваем их.
Разъём ISP (2x3) можно не паять. 



#### Доработка Arduino Nano для режима эмуляции SPORTident

Необходимо удалить с платы Arduino Nano конденсатор на линии DTR-Reset.
Он расположен рядом с микросхемой контроллера USB.
После этого нужно залить на плату доработанный загрузчик Optiboot (optiboot8_atmega328_38400_without_reset.hex)
с помощью программатора.

### Вариант 1 с печатной платой в корпусе Gainta 1020BF

Впаиваем Arduino Nano в основную плату.
Также в основную плату впаиваем разъём 1x8, согнутый углом светодиод,
зуммер и резисторы типоразмера 0805 на 47 Ом (к зуммеру) и 150 Ом (к светодиоду).



Затем припаиваем модуль RFID. Подключаем через провод USB к компьютеру.



Открываем программу Arduino IDE на компьютере (см. [Настройка Arduino IDE](ArduinoIde.md)). 

В меню `Инструменты->Плата` выбираем плату `Sportiduino Master Station`.

Для активного зуммера изменяем частоту на 0 кГц ("Buzzer frequency: 0 kHz (active buzzer)").

Выбираем нужный COM-порт и заливаем скетч MasterStation на плату (Файл->Папка со скетчами->MasterStation).



**Важно!** Без конденсатора на линии DTR-Reset не работает привычная процедура заливки прошивки.
Обязательно нужно обновить загрузчик с помощью программатора (`Инструменты->Записать Загрузчик`).
Обновлённый загрузчик ждёт 2 секунды после подачи питания по USB на плату, после чего загружает основную прошивку.
То есть для обновления прошивки (заливки скетча) нужно:
- отключить-подключить плату к USB;
- сразу после подать команду на обновление прошивки.

Примеряем корпус. Для провода вырезается небольшая канавка в корпусе. Светодиод промазывается эпоксидным клеем.



После чего корпус закрывается крышкой и готов к использованию.



### Вариант станции без печатной платы

Можно собрать станцию сопряжения без печатной платы. Светодиод, зуммер и RFID-модуль припаиваются проводками к Arduino Nano согласно схеме.



Рекомендуется использовать провод типа МГТФ-0,12.
Далее для такого варианта сборки разработан свой корпус, который можно распечатать на 3D-принтере.
Файлы для печати корпуса на 3D-принтере находятся в папке `hardware/MasterStation/3d/print`.







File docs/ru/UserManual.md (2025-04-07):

# Руководство пользователя

Данная инструкция имеет общий характер и предназначена для пользователей системы отметки.

* [Общая информация](#общая-информация)
* [Инструкция для участников](#инструкция-для-участников)
* [Инструкция для организатора](#инструкция-для-организатора)
    * [Подключение мастер-станции](#подключение-мастер-станции)
    * [Подготовка чипов участников](#подготовка-чипов-участников)
    * [Чтение чипов и формирование результатов](#чтение-чипов-и-формирование-результатов)
    * [Подготовка базовых станций](#подготовка-базовых-станций)
    * [Настройка мастер-станции](#настройка-мастер-станции)

## Общая информация

### Чипы

Поддерживаемые типы чипов:
- [Mifare Ultralight C](http://www.nxp.com/documents/data_sheet/MF0ICU2.pdf) на 36 отметок
- [Mifare Classic 1K](https://www.nxp.com/docs/en/data-sheet/MF1S50YYX_V1.pdf) на 42 отметки
- [Mifare Classic 4K](https://www.nxp.com/docs/en/data-sheet/MF1S70YYX_V1.pdf) на 90 отметок
- [NTAG213/215/216](https://www.nxp.com/docs/en/data-sheet/NTAG213_215_216.pdf) на 32/120/216 отметок

Данные типы чипов производятся в разном форм-факторе.
Рекомендуются для использования чипы NTAG как более ёмкие.

### Базовые станции

Базовая станция представляет собой электронное изделие в небольшом корпусе с фланцами.
Вес одной станции от 100 до 150 грамм.
Питание от литий-полимерного аккумулятора 900 мАч.
В старых версиях питание от 3 батареек АА, в зависимости от режима работы батареек хватает от 45 дней до 2 лет.
Кнопок и другого интерфейса на станции нет.
Весь обмен информацией и запись чипов происходит в бесконтактном режиме
по стандарту бесконтактных пассивных карт ближнего радиуса действия ISO 14443A.
Оптимальная зона срабатывания 0,5 — 2 см над станцией.



В станции установлена микросхема часов реального времени, обладающая малой погрешностью хода,
но станции не являются прибором точного времени, время нужно регулярно корректировать.

Для обеспечения более длительной работы от батареи базовые станции могут работать в трех режимах:

* **Спящий режим.**
Для хранения станций между соревнованиями.
Опрос чипа происходит раз в 25 секунд. Практически не потребляют энергию.
Батарей AA хватит более чем на 2 года.
Для перевода в данный режим используются специально записанные мастер-чипы.
Вывод осуществляется прикладыванием любого чипа или чипа с магнитом для мгновенного срабатывания.
Магнит при этом нужно прикладывать к середине левого края лицевой стороны станции.
Также при выводе из сна происходит очистка внутренней памяти.
* **Режим ожидания.**
Опрос чипа раз в 1 секунду. Батарей хватит примерно на полгода.
* **Рабочий режим.**
Опрос чипа раз в 0,25 секунд. Самый быстрый режим отметки. Батарей AA хватит на 45 дней.

Базовые станции в зависимости от заданного им номера (от 1 до 255) могут выполнять разные функции:

- **Обычные станции отметки** с номерами 1 - 239.
При поднесении чипа записывают в него отметку и подают сигнал.
При повторном поднесении чипа не производят запись, подают двойной сигнал.
- **Станция старта (номер 240)**.
В режиме проверки станцией старта/финиша не производят отметку и не сигналят, если чип не пустой.
В обычном режиме записывает отметку как обычные базовые станции.
- **Станция финиша (номер 245)**.
Записывает отметку как обычная базовая станция.
- **Станция проверки (номер 248)**.
Если чип пустой и время его инициализации/очистки не отстает более чем на месяц от текущего, станция подаёт одиночный сигнал, иначе – молчит.
Станция ничего не записывает на чип и работает по скорости как обычная, так что на ней участники могут потренироваться в отметке перед стартом.
- **Станция очистки (номер 249)**.
Стирает все данные на чипе, оставляя неизменным номер, а также обновляет время инициализации на чипе.
При поднесении чипа загорается светодиод и мигает все время процедуры очистки, звуковой сигнал говорит об успешности процедуры.

### Мастер-станция

Также называется станцией сопряжения или станцией считывания.
Это станция с разъемом mini USB для подключения к компьютеру.
Нужна для настройки базовых станций, записи и считывания чипов.



## Инструкция для участников

С данной инструкцией очень желательно ознакомить участников до начала соревнований.

* Для отметки нужно поднести чип к центру цветного круга на лицевой стороне станции.
* В случае успешной отметки станция издаст звуковой сигнал и мигнёт один раз светодиодом.
* Оптимальный диапазон срабатывания 0,5 — 2 см. Если чип находится дальше, отметка может сработать не с первого раза.
* При отметке не нужно двигать чип из стороны в сторону, это затрудняет чтение и запись чипа.
* Если не получилось отметиться, уберите чип и вновь поднесите его к центру цветного круга на станции.
* Время отметки составляет от 0,06 до 0,4 секунды, если станция находится в рабочем режиме.
* Если вы пришли на контрольный пункт (КП) первым, станция может находиться в режиме сна, время отметки в таком случае составит до 1,2 секунды.
* При попытке повторной отметки станция издаст два коротких сигнала без записи новой отметки.
Если вы не уверены, что отметка записалась с первого раза, приложите чип повторно.
* Если вы пришли на КП одновременно с другим участником, то отмечаться нужно по очереди.
Нельзя одновременно приложить к станции отметки два и более чипа, в этом случае отметка будет записана только на один из чипов.

## Инструкция для организатора

Для работы со станциями необходимо использовать программы:
* [SportiduinoPQ](https://github.com/sportiduino/SportiduinoPQ/releases) для подготовки чипов участников и настройки станций;
* [SportiduinoApp](https://github.com/sportiduino/SportiduinoApp/releases) для тех же целей на Android-смартфоне с NFC;
* [SportOrgPlus](https://github.com/sembruk/sportorg-plus/blob/master/docs/index.md) для чтения чипов и подсчёта результатов соревнований.

Программу SportiduinoPQ можно скачать [на странице релизов](https://github.com/sportiduino/SportiduinoPQ/releases).
В релизе присутствует портативный исполняемый EXE файл для Windows, не требующий установки.
При работе программы весь лог сохраняется в подпапку log.

Программа SportOrgPlus является адаптацией [SportOrg](https://sportorg.readthedocs.io/ru/latest/),
и предназначена для подсчёта результатов соревнований как по ориентированию, так и по рогейну.

*Далее описана процедура работы со станциями и чипами с помощью программы SportiduinoPQ.*

### Подключение мастер-станции

_Перед первым подключением мастер-станции в ОС Windows нужно поставить драйвер.
[Установщик драйвера](http://wiki.amperka.ru/_media/articles:driver-ch340:ch340ser-wimdows.zip) для станции на микросхеме CH340._

Подключить мастер-станцию по USB.
Запустить программу SportiduinoPQ.

Для подключения станции нужно нажать кнопку `Подключить` (`Connect`).



Если подключение удалось, в логе отобразится `Подключена станция сопряжения <...>`, станция подаст звуковой сигнал.



Если подключить станцию не удаётся, проверьте правильность соединения.
Проблемы могут возникнуть, если в системе есть другое подобное устройство, не являющееся станцией.
В таком случае нужно через Диспетчер устройств в Панели управления Windows выяснить номер Com порта, присваиваемый станции и выбрать его вместо "авто".
Также для станции на Arduino Nano с чипом CHG340 необходимо установить соответствующий драйвер.

### Подготовка чипов участников

Пустые чипы необходимо инициализировать (записать на них номер и текущее время).
Для этого во вкладке `Осн` (`Main`) надо ввести номер чипа в поле `Чип №`.
Далее поднести чип к станции и нажать кнопку `Подготовить чип` (`Init Card`).
Процесс инициализации занимает в зависимости от чипа от 3 до 7 секунд.
В случае успеха станция издаст один сигнал.
Если стоит галочка `Автоувеличение` (`Autoincrement`), то число в поле ввода увеличится на 1.
Если процесс прошел неудачно (несколько коротких сигнала), попробуйте повторить процедуру.



Номер чипа можно задать в диапазоне от 1 до 65535.

При инициализации помимо номера чипа записывается время инициализации,
которое необходимо для последующего считывания чипа.
Если с момента инициализации или очистки прошло более полугода, данные будут некорректными.
Поэтому желательно инициализировать чипы незадолго до соревнований.

Уже ранее инициализированные чипы можно очистить с сохранением номера на станции очистки.

### Чтение чипов и формирование результатов

Для чтения чипов и формирования результатов рекомендуется использовать программы SportOrgPlus или SportOrg.

Для быстрого просмотра результатов по отдельным чипам можно также использовать SportiduinoPQ.
Для этого поднести чип к станции и во вкладке `Осн` (`Main`) нажать `Прочитать чип` (`Read Card`).
Результат отобразится в окне лога.



### Подготовка базовых станций

Краткий порядок действий для подготовки станции к соревнованиям:

1. Разбудить станцию.
1. Наклеить стикер с номером, записать номер на станции, если ещё не записан.
1. Настроить время на станции, если оно не настроено или настраивалось давно.
1. Считать состояние станции для проверки заряда батареи (опционально).
1. Отправить станции в сон с временем пробуждения перед стартом первых участников.

#### Пробуждение станции

Для настройки станций, если они находятся в состоянии сна, необходимо их разбудить.
Для моментального пробуждения станции нужно приложить чип с магнитом.
Если такого нет, нужно приложить любой чип участника на время до 30 секунд.
При пробуждении загорится светодиод на 3 секунды,
после чего станция подаст длинный сигнал (батарея в норме) или серию коротких (необходимо зарядить).



#### Мастер-чипы

Станции настраиваются с помощью так называемых мастер-чипов.
Мастер-чип – это чип с записанными на него настройками или командами для передачи их на базовую станцию.
Чтобы записать мастер-чип, нужно поднести его к мастер-станции и нажать нужную кнопку на вкладке `Чип` (`Card`) в зависимости от задачи.
Рекомендуется отобрать несколько чипов для использования в качестве мастер-чипов и пометить их,
чтобы избежать их смешивания с чипами участников или использовать чипы другого цвета или форм-фактора.

Перед подготовкой мастер-чипов установите текущий пароль в программе SportduinoPQ.
После сборки станции имеют пароль по умолчанию 0-0-0.
Если вы неправильно установите пароль, то базовая станция не примет настройки с мастер-чипа.

Введённый пароль сохраняется между сеансами работы SportduinoPQ,
таким образом для работы с одним комплектом станций пароль понадобиться указать только один раз.



#### Присвоение номера станции

В программе SportiduinoPQ на вкладке `Чип` (`Card`) указать номер станции (от 1 до 239),
поднести чип к мастер-станции и нажать кнопку `Создать`.
После чего данный чип поднести к станции.
Станция издаст один длинный сигнал подтверждения. 

Для задания специальных станций выделены отдельные кнопки.



#### Настройка времени станции

Для настройки времени нужно приложить любой чип к мастер-станции и нажать `Создать` (`Create`) в разделе `Мастер-чип "Часы"` (`Date/Time Card`) на вкладке `Чип` (`Card`).



Станция подаст четыре сигнала с интервалом в секунду.
После третьего сигнала нужно приложить чип к базовой станции.
При этом станция издаст длинный сигнал.
Если последний сигнал мастер-станции и сигнал базовой станции слились в один, то время настроено достаточно точно.
Настройку времени лучше проводить в активном режиме станции в виду более короткого периода опроса чипов.

*Погрешность хода часов составляет порядка 1 секунды в неделю.
Для критически важных станций старта и финиша рекомендуется обновлять время в день соревнований.*

#### Перевод станций в спящий режим

После соревнований нужно перевести все станции в спящий режим для продления работы от батарей.
Для этого нужно поднести чип к мастер-станции.
В программе SportiduinoPQ на вкладке `Чип` (`Card`) нажать `Создать` в разделе `Мастер-чип "Сон"` (`Sleep Card`).
Затем поднести созданный мастер-чип к базовой станции.
Станция подаст 4 сигнала и войдёт в спящий режим.



При создании мастер-чипа для перевода базовой станции в режим сна,
вы можете указать дату автоматического пробуждения станции в поле `Время пробуждения`.
В это время базовая станция автоматически перейдёт в активный режим и отметка у первого участника сработает быстрее.
Если вы хотите перевести базовые станции в режим сна для хранения, то укажите любую прошедшую дату и время.

#### Изменение пароля

Использование паролей защищает станции от возможности несанкционированного их перепрограммирования.
После сборки пароль по умолчанию 0-0-0.



**Внимание!**
*Если вы установите новый пароль и забудете его, то для сброса пароля понадобится разборка станции и перезапись настроек по UART.
Рекомендуется сохранить пароль в надёжном месте.*

#### Другие настройки базовой станции

Продолжительность активного режима, дополнительные проверки и усиление антенны базовой станции можно задать на вкладке `Конф.` (`Config`),
и записать на станцию с помощью мастер-чипа.



Настройки подробнее:
- `Актив. время (ч)` — время работы в активном режиме (1, 2, 4, 8, 16, 32, "никогда" или "всегда").
Если в течение этого времени на станции никто не отметится, то станция перейдёт в режим ожидания (не в сон).
Если указано "никогда", станция находится в режиме ожидания с опросом 1 секунда и не переходи в активный режим.
Если указано "всегда", станция находится в активном режиме и самостоятельно не переходит в режим ожидания или сна.
- `Старт как Проверка` — включает проверку на станции старта отсутствие отметок в чипе.
Если отметки есть (чип не очищен), станция не отмечает старт и не подаёт сигнал.
- `Пров. вр. чипа` — включает проверку времени инициализации чипа участника.
Если после инициализации чипа прошло больше 180 дней, станция не делает отметку и не подаёт сигнал.
- `Автосон` — включает переход станции в режим сна через 48 часов после последней отметки.
- `Быст. отметка` — включает запись метки быстрой отметки в чип на станции очистки.
- `Усил. антенны` — коэффициент усиления антенны модуля MFRC522.

Усиление антенны по умолчанию 33 дБ.
Если задать максимальное усиление, то в некоторых станциях чипы перестают отмечаться при поднесении их вплотную.
Для станций с этой проблемой нужно постепенно уменьшать усиление до достижения оптимального срабатывания.

#### Снятие лога станции

В ходе работы базовая станция ведет лог – записывает номера чипов и время отметки.
С использованием этой функции возможно восстановление данных в случае утери чипов, проверки спорных ситуаций, а также в поиске сошедших или потерявшихся участников.

Для снятия лога нужно записать мастер-чип.
Для этого поднести чип к мастер-станции и в программе SportiduinoPQ нажать `Создать` в разделе `Мастер-чип "Лог отм."` (`Dump Card`) на вкладке `Чип` (`Card`).
После чего поднести мастер-чип к базовой станции.
Процесс займёт до 10 сек, нужно неподвижно держать чип в оптимальной области записи (0,5 — 2 см над центром круга антенны).
После успешного снятия лога поднести чип к мастер-станции и нажать `Читать` в разделе `Мастер-чип "Лог отм."` (`Dump Card`).
Результат появится в логе программы.



#### Чтение состояния станции

Чтобы проверить настройки базовой станции, уровень заряда батареи, время и текущий режим её работы,
создайте в программе SportiduinoPQ мастер-чип для чтения состояния станции.

Для этого во вкладке `Чип` (`Card`) нажмите `Создать` в разделе `Мастер-чип Состояние` (`State Card`).
После этого поднесите созданный мастер-чип к базовой станции.
Если базовая станция находится в режиме сна, то нужно будет подождать в течение 30 секунд (или использовать чип с магнитом).
Базовая станция включит светодиод на 3 секунды и издаст одиночный звуковой сигнал, после чего мастер-чип следует убрать.
Если базовая станция находилась в режиме сна, то она в нём останется, её не нужно переводить заново в режим сна.
Если в течение 30 секунд базовая станция не реагирует на чип, то либо она неисправна, либо батарея разряжена, либо следует пересоздать мастер-чип.
После того как базовая станция записала информацию на мастер-чип, приложите мастер-чип к станции сопряжения и в программе SportidunoPQ нажмите `Читать` в том же разделе.
После этого в логе отобразится вся информация о базовой станции.
Также изменятся значения полей во всех вкладках SportiduinoPQ в соответствии с текущими настройками базовой станции.



#### Быстрая подготовка базовой станции

До того, как базовая станция закрыта в корпусе возможна быстрая подготовка станции по UART с использованием преобразователя USB-to-TTL.



Подключите преобразователь к разъёму Prog базовой станции (без подключения DTR).

Не имеет значение находится станция в активном режиме или режиме сна.
Если станция спит, то будить её не надо.
В программе SportduinoPQ во вкладке `Конф.` (`Config`) в разделе `Настройка по UART` (`Config by UART`)
установите номер COM-порта преобразователя USB-to-TTL и нажмите кнопку `Записать` (`Write`).
При этом в базовую станцию будет записано текущее время и все остальные настройки.



Чтобы убедиться, что настройки записались правильно нажмите на кнопку `Читать` (`Read`).
После чего на экране появятся текущие настройки станции. При этом режим станции не изменится.



### Настройка мастер-станции

Во вкладке `МС` (`MS`) доступны для изменения следующие опции:
* `Усил. антенны` — усиление антенны RFID модуля станции; значение по умолчанию 33 дБ;
* `Часовой пояс` — необходимо указать часовой пояс для корректной работы мастер-станции в режиме эмуляции SPORTident (например, с программой Winorient).



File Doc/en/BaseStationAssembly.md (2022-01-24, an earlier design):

# Base Station Assembly

This instruction for assembling Base station v3.

### Base station components



1. RFID module RC522.
2. PCB. Can be ordered via [EasyEDA](https://easyeda.com/order) or [JLCPCB](https://jlcpcb.com/).
Gerber files are placed in the folder `hardware/BaseStation/prod/v3`.
*It is not in the photo PCB v1.*
3. Chips
   - Microcontroller ATmega328P-AU.
   - DS3231SN clock.
   - Memory 24LC256T-I/SN (optional, not in the photo).
   - Voltage regulator MCP1700T-33.
   - Transistor BSS138 SOT-23.
4. Passive components in the 0805 format.
   - Resistor 100 ohm, 1 pc.
   - Resistor 3.3 kOhm, 2 pcs.
   - Resistor 10 kOhm, 2 pcs.
   - Resistor 33 kOhm, 2 pcs.
   - Resistor 68 kOhm, 1 pc.
   - Resistor 270 kOhm, 1 pc.
   - Capacitor 0.1 uF, 7 pcs.
   - Capacitor 4.7 uF, 2 pcs.
   - Inductor 2.2 uH, max current > 500 mA (e.g. LQH32MN2R2K) 2 pcs, optional.
5. Through-hole components
   - PLS-8 pins. Come with RFID board.
   - Connector BH-10 (aka DS1013-10S or IDC-10MS). It can be replaced by any male connector 2x5 pins 2.54 mm.
   - LED 3 mm. Any color for your choice.
   - Passive buzzer 12085 16 ohm, TR1205Y or HCM1203A.
   - Reed switch normally open 2x14 mm (optional, not in the photo).
   - Connector 1x2 pins 2.54 mm for battery (optional, not in the photo).
6. Battery box 3xAA or 3xAAA.
7. The Gainta G1020BF case.

Equipment which is useful for assembly is given [on a separate page](/Doc/en/Equipment.md)

### RFID module preparing

Remove LED D1, resistors R1 and R2 to reduce module power consumption.

Replace inductors L1 and L2 by similar 2.2 uH, but with a large operating current to increase the antenna power (e.g. Murata LQH32MN2R2K).



### Soldering the main board

Scheme

PCB with instructions

Grease flux all places of future soldering.
Next solder chips.
After chips solder the transistor, voltage stabilizer, resistors and capacitors.
Resistor R8 and capacitor C8 can not be soldered, since they are not used now and reserved for future versions.
Contact pads JP1 and JP2 are closed with a drop of solder or jumpers, as shown in the circuit scheme (pins 1 and 2).
At the end solder buzzer, RFID connector and battery box (or connector 1x2 pins).
Solder a LED on the back of the board.
Instead of the output LED, you can solder the SMD LED from the RFID module.
The RC-522 module is not soldered yet.

**Warning!** Do not confuse the polarity of the LED and the buzzer when soldering.

### Programmer

To upload the bootloader to the microcontroller, you need a programmer.
If you do not have a programmer then it can be made from Arduino Nano.

#### Arduino Nano based programmer 

To make it, you will need a flat cable for 10 wires 25 cm long and an IDC-10F connector (aka DS1016-10).
Instead of this connector, you can use any other type of 2x5 pin 2.54 mm female connector.

A connector is installed at the end of the cable.
Solder the other end of the cable to the Arduino Nano board in accordance with the scheme below.
We do not yet install a 10 μF 16V capacitor.

Arduino Nano programmer scheme

Connect the Arduino Nano to the PC via USB and launch the Arduino IDE.
Open the ArduinoISP sketch from Arduino examples (File -> Examples -> ArduinoISP).
In the `Tools` menu, select the `Arduino Nano` board, the `ATmega328P (Old Bootloader)` processor, and the corresponding port.



Perform Sketch -> Upload.
After that, solder the 10 uF 16V capacitor between GND and RST as in the scheme above.
If the capacitor is not soldered, an error message will constantly appear during programming:
`avrdude: stk500_getsync() attempt 1 of 10: not in sync: resp=0x15`.
The programmer is ready.

Arduino Nano Programmer

### Serial programmer

To upload the main firmware to the microcontroller, a USB-UART converter is required.
The converter must have a DTR pin.
To connect it to the station board, you also need a 10-wire flat cable and IDC-10F connector.

Serial programmer scheme

If the converter will also be used to configure the station and to read its state
then necessary to provide the possibility of disconnecting the DTR pin.

Serial programmer

### Arduino IDE Setting

In the File->Settings menu change the location of the sketch folder to `path/to/project/firmware`.

Next, create a description of Sportiduino board.
Open the file `path/to/Arduino/hardware/arduino/avr/boards.txt`
and add file `path/to/project/firmware/boards.txt` contents to the end of this file.

After that copy files \*.hex from the folder `path/to/project/firmware/Optiboot` to the folder `path/to/Arduino/hardware/arduino/avr/bootloaders/optiboot`.

Restart the Arduino IDE. In the Tools->Board menu our Sportiduino board should appear.

### Bootloader and firmware upload

In Arduino IDE, open the BaseStation sketch (File->Sketchbook->BaseStation).
In the Tools->Board menu select `Sportiduino`.
Next in the Tools->Programmer menu select `Arduino as ISP`.



Connect programmer to the board. Power on board.

Programmer connection

Execute Tools->Burn Bootloader.
If an error message appears in the log then check the assembly of the programmer and its connection to the board, check the assembly of the board itself.
If everything went well then turn off the programmer.

Connect the serial programmer.

Serial programmer connection

Execute Sketch->Upload.
After the upload is complete the station should beeps three times and beeps one long time after 3 seconds.
If this does not happen then check the soldering of the board.

### Soldering RFID to the board and testing 

After uploading the firmware to the microcontroller solder the RFID module and the reed switch (optional) to the board.

PCB with RFID and reed switch 

Then test the operation of the station.
Create master cards of the station number, time, and several regular cards.
After power-up, the station will give three short beeps, which indicates that the clock is not set.
Then after a few seconds there will be a long beep, indicating that the power is normal and the program has entered the work loop.
By default, the station operates in Wait mode and checks for the presence of a chip in the working area once per second.
Bring the Station number master card to the station.
The station will record a new number and is now able to respond to regular cards.
Next, configure the clock.
Bring the Time master card and after beep bring the second regular card.
Read it at the master station and make sure that base station clock works correctly.

Station testing

If the station passed the test, then the board can be washed off the flux residues, for example, in a bath with isopropyl alcohol.
If the board does not work then check first the soldering of chips and the connection to the RFID module.

Готовая плата после отмывки

### Installation in the case

In the case drill a 3 mm diameter hole for a LED.
The hole coordinates are shown in the figure below.
To prevent moisture from entering through this hole,
it must be sealed with adhesive tape on the reverse side, and on the other hand, filled with hot or epoxy glue.

Hole coordinates

Next, glue the battery box to the cover of the case (optional).

After that install the board so that the LED falls into the center of the drilled hole.

Fix the board with hot glue.
*In the photo show the PCB v2.*

Fix the board with hot glue

PCB in case

After that fill the compound (optional).
Or blur the joint of the housing with a silicone sealant, or glue the cover to the case.

*In the photos below show the PCB v1.*



At a station measure 30 ml of compound



and 1 ml of hardener. Mix the hardener with the compound.





And fill the board.
Silicone should fill all contacts.
There are only programmer connector and buzzer.





In a day the compound solidifies completely.
In this case, all the details can be seen, in which case the compound can easily be removed for repairing.



The battery box is smeared with petroleum jelly or other thick hydrophobic thick oil and insert batteries.
 


Close the case with the cover.
Parts lie tight, you may need a little effort to close the case.





Print stickers form the folder `hardware/BaseStation/2d`.
Glue the sticker on top of the station.

The station is ready!





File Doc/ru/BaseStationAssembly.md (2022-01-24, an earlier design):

# Сборка станции отметки

Данная инструкция для сборки станции версии 3.

[Сборка станции отметки v2](https://github.com/sportiduino/sportiduino/blob/v2.6.3/Doc/ru/BaseStationAssembly.md)

[Сборка станции отметки v1](https://github.com/sportiduino/sportiduino/blob/1.3.7/Doc/ru/BaseStationAssembly.md)

### Компоненты станции отметки



1. RFID-модуль RC522.
2. Печатная плата. Можно заказать через [EasyEDA](https://easyeda.com/order) или [JLCPCB](https://jlcpcb.com/).
Gerber файлы находятся в папке `hardware/BaseStation/prod/v3`. *На фото представлена печатная плата версии 1.*
3. Микросхемы
   - Микроконтроллер ATmega328P-AU 
   - Часы DS3231SN 
   - Память 24LC256T-I/SN (опционально, нет на фото)
   - Стабилизатор напряжения MCP1700T-33. 
   - Транзистор BSS138 в корпусе SOT-23.
4. Пассивные компоненты в формате 0805. 
   - Резистор 100 Ом, 1 шт.
   - Резистор 3,3 кОм, 2 шт.
   - Резистор 10 кОм, 2 шт.
   - Резистор 33 кОм, 2 шт.
   - Резистор 68 кОм, 1 шт.
   - Резистор 270 кОм, 1 шт.
   - Конденсатор 0,1 мкФ, 7 шт.
   - Конденсатор 4,7 мкФ, 2 шт.
   - Индуктивность 2,2 мкГн, ток насыщения > 500 mA (например, LQH32MN2R2K), 2 шт, опционально.
5. Выводные компоненты
   - Разъём PLS-8 на плату ("гребёнка"). Идёт в комплекте с RFID-платой.
   - Разъём BH-10 (DS1013-10S или IDC-10MS). Можно заменить любой вилкой на плату 2x5 с шагом 2,54 мм.
   - Светодиод 3 мм.
   - Пассивный зуммер 12085 16 Ом, TR1205Y или HCM1203A.
   - Геркон замыкающий 2x14 мм (опционально, нет на фото).
6. Батарейный отсек 3xAA или 3xAAA (тогда корпус будет закрываться проще).
7. Корпус Gainta G1020BF.

Оборудование, которое пригодится при сборке, приведено [на отдельной странице](/Doc/ru/Equipment.md).

### Подготовка RFID-модуля

У модуля необходимо выпаять светодиод D1 и резисторы R1 и R2,
иначе потребление тока во время его работы будет выше.

Также рекомендуется заменить индуктивности L1 и L2 на аналогичные 2,2 мкГн,
но с большим рабочим током для увеличения мощности антенны. Например, Murata LQH32MN2R2K (Спасибо за совет Александру Якимову).



### Пайка основной платы

Принципиальная схема

Расположение компонентов

Обильно промазываем флюсом все места будущей пайки.
Далее припаиваем микросхемы.
После микросхем припаиваем транзистор, стабилизатор напряжения, резисторы и конденсаторы.
Резистор R8 и конденсатор C8 можно не припаивать, так как они сейчас не используются и зарезервирован для будущих версий.
Контактные площадки JP1 и JP2 замыкаем каплей припоя или перемычками, как показано на принципиальной схеме (контакты 1 и 2).
В конце припаиваем светодиод, зуммер, "гребёнку" и батарейный отсек.
Светодиод припаиваем с обратной стороны платы.
Вместо выводного светодиода можно припаять SMD-светодиод от RFID-модуля.
Модуль RC-522 пока не припаиваем.

**Внимание!** Не перепутайте при пайке полярность у светодиода и зуммера.

### Программатор

Для загрузки на микроконтроллер bootloader потребуется программатор.
Если у вас нет программатора, то его можно сделать из Arduino Nano.

#### Программатор из Arduino Nano

Для его изготовления потребуется шлейф на 10 проводов длиной 25 см и разъём IDC-10F (DS1016-10).
Вместо этого разъёма можно использовать любой другой типа розетка 2x5 с шагом 2,54 мм.

На конце шлейфа устанавливается разъём.
Другой конец шлейфа припаиваем к плате Arduino Nano в соответствии со схемой.
При этом пока не устанавливаем конденсатор 10 мкФ 16В.

Схема программатора из Arduino Nano

Далее подключаем Arduino Nano к ПК через USB и запускаем Arduino IDE.
Открываем скетч ArduinoISP из примеров Arduino (Файл->Примеры->ArduinoISP).
Далее в меню `Инструменты` выбираем плату `Arduino Nano`, процессор `ATmega328P (Old Bootloader)` и соответствующий порт.



Выполняем Скетч->Загрузка.
После этого припаиваем конденсатор на 10 мкФ 16В между GND и RST как на схеме выше.
Если не припаять конденсатор, то при программировании постоянно будет появляться сообщение об ошибке:
`avrdude: stk500_getsync() attempt 1 of 10: not in sync: resp=0x15`.
Программатор готов.

Программатор из Arduino Nano

### Преобразователь USB-UART

Для загрузки на микроконтроллер основной прошивки потребуется USB-UART преобразователь.
У преобразователя обязательно должен быть сигнал DTR.
Для его подключения к плате станции также нужен шлейф на 10 проводов и разъём IDC-10F.

Схема подключения USB-UART

Если помимо загрузки прошивки преобразователь будет использоваться также для настройки станции и для чтения её состояния,
то при подключении шлейфа к преобразователю нужно предусмотреть возможность отключения проводника от вывода DTR.

Преобразователь USB-UART

### Настройка Arduino IDE

В меню Файл->Настройки изменяем размещение папки скетчей на `[Проект]/firmware`.

Далее нам необходимо создать описание нашей платы Sportiduino.
Для этого открываем файл `[Program Files]\Arduino\hardware\arduino\avr\boards.txt`
и добавляем в конец файла содержимое файла `[Проект]\firmware\boards.txt`

После этого копируем файлы \*.hex из папки `[Проект]\firmware\Optiboot` в папку `[Program Files]\Arduino\hardware\arduino\avr\bootloaders\optiboot`.

Перезапускаем Arduino IDE. В меню Инструменты->Плата должна появиться наша плата Sportiduino.

### Прошивка микроконтроллера

В Arduino IDE открываем скетч BaseStation (Файл->Папка со скетчами->BaseStation).
В меню Инструменты->Плата устанавливаем `Sportiduino`. Далее в меню Инструменты->Программатор выбираем `Arduino as ISP`. 



Подключаем наш программатор к плате Sportiduino.
Вставляем батарейки.

Подключение программатора

Выполняем Инструменты->Записать загрузчик.
Если появилось сообщение об ошибке в логе, то проверяем сборку программатора и его подключение к плате, проверяем сборку самой платы.
Если всё прошло успешно, то отключаем программатор.

Подключаем преобразователь USB-UART.

Подключение преобразователя USB-UART

Выполняем Скетч->Загрузить.
После завершения загрузки станция должна подать три коротких сигнала и через 3 секунды один длинный.
Если этого не произошло, то необходимо проверить пайку платы.

### Пайка RFID-модуля и проверка

После прошивки микроконтроллера припаиваем RFID-модуль и геркон (опционально) к нашей плате.

Плата с припаянным RFID-модулем и герконом 

Затем проверяем работу станции.
Предварительно стоит записать мастер-чипы номера станции, времени и несколько обычных чипов.
После подачи питания станция подаст три коротких сигнала, что говорит о том, что часы не выставлены.
Затем через несколько секунд будет длинный сигнал, сигнализирующий, что питание в норме и программа вошла в цикл работы.
По умолчанию станция работает в режиме ожидания и проверяет наличие чипа в рабочей зоне раз в секунду.
Приложите мастер-чип номера станции. Станция запишет новый номер и теперь уже способна реагировать на обычные чипы.
Далее необходимо настроить часы.
Подносим мастер-чип времени и после установки подносим второй обычный чип.
Считываем его на станции сопряжения и убеждаемся в корректной работе.

Проверка работы старции

Для проверки работоспособности геркона нужно подготовить специальный чип,
который будет использоваться для быстрого пробуждения станций.
Для этого приклееваем магнит с краю чипа.

Усыпляем станцию чипом сна и пробуждаем чипом с магнитом.

Проверка работы геркона

Если станция прошла проверку, то плату можно отмывать от остатков флюса, например, в ванне с изопропиловым спиртом или специальным средством (например, FluxOff).
Если плата не работает, то нужно проверить прежде всего пайку микросхем и соединение с RFID-модулем.

Готовая плата после отмывки

### Установка в корпус

В корпусе сначала нужно просверлить отверстие для светодиода 3 мм.
Координаты отверстия показаны на рисунке ниже.
Чтобы влага не попадала внутрь через это отверстие,
его необходимо заклеить с обратной стороны скотчем, а с другой стороны залить термо- или эпоксидным клеем.

Положение отверстия

Далее можно приклеить батарейный отсек к крышке корпуса.

После этого устанавливаем плату так, чтобы светодиод попадал в центр просверленного отверстия.

Закрепляем плату термоклеем.
*На фото плата версии 2.*

Закрепляем плату термоклеем

Плата в корпусе

После этого можно залить корпус компаундом.
Или можно обойтись и без него. Например, если промазать стык корпуса силиконовым герметиком или приклеить крышку к корпусу.

*На фотографиях ниже показана плата версии 1.*



На 1 станцию отмеряем 30 мл компаунда



и 1 мл отвердителя. Перемешиваем отвердитель с компаундом.





И заливаем нашу плату.
Должно получиться так, что все контакты залиты силиконом.
Выходят только разъём для программирования и зуммер.





Через сутки компаунд полностью затвердевает.
При этом все детали хорошо видно. В случае необходимости ремонта компаунд можно легко частично удалить.



Батарейный отсек промазываем вазелином или другим густым гидрофобным маслом и вставляем батарейки.



И закручиваем наш корпус. Детали лежат туго, может понадобиться небольшое усилие, чтобы закрыть корпус.





Печатаем на принтере наклейки из папки `hardware/BaseStation/2d`.
Наклейки выполнены в программе Inkscape.
Можно заказать печать наклеек на светоотражающей или светонакопительной плёнке.
Приклеиваем наклейку и сверху ламинируем её скотчем, если наклейка из простой бумаги.
Станция готова!





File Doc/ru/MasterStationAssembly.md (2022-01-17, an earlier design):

# Сборка станции сопряжения

Компоненты станции сопряжения



1. RFID-модуль RC522.
2. Arduino Nano.
Можно подключать напрямую к компьютеру.
Платы от разных производителей различаются чипом USB интерфейса: более дорогой FT232RL или более дешевый CHG340.
Для подключения второго нужно установить драйвера в Windows.
3. Плата для спайки ([вариант 1](https://upverter.com/AlexanderVolikov/3fc0efdb2586988d/Sportiduino-reading-stantion/) и
[вариант 2](https://upverter.com/design/syakimov/4f7ec0e2d3b9c4e9/sportiduino-master-station/)).
Можно заказать изготовление плат в Китае. Например, на [JLCPCB](https://jlcpcb.com/).
Стоимость зависит от партии, минимальное число 5.
Целесообразно заказывать платы для станции сопряжения одновременно с платами для станций отметки. 
4. Штыревой разъём "гребёнка", светодиод и зуммер (электромагнитный или прьезоизлучатель).
5. Корпус Gainta 1020BF или 1015. Продаются в России.
6. USB-шнур.

### Подготовка Arduino Nano

Если гребёнки идут отдельно от платы, впаиваем их.
Разъём ISP (2x3) можно не паять. 



#### Доработка Arduino Nano для режима эмуляции SPORTident

Необходимо удалить с платы Arduino Nano конденсатор на линии DTR-Reset.
Он расположен рядом с микросхемой контроллера USB.
После этого нужно залить на плату доработанный загрузчик Optiboot (optiboot8_atmega328_38400_without_reset.hex)
с помощью программатора.

### Вариант 1 с печатной платой в корпусе Gainta 1020BF

Впаиваем Arduino Nano в основную плату.
Также в основную плату впаиваем разъём 1x8, согнутый углом светодиод,
зуммер и резисторы типоразмера 0805 на 47 Ом (к зуммеру) и 150 Ом (к светодиоду).



Затем припаиваем модуль RFID. Подключаем через провод USB к компьютеру.



Открываем программу Arduino IDE на компьютере (см. [Настройка Arduino IDE](/Doc/ru/BaseStationAssembly.md#Настройка-Arduino-IDE)). 
В настройках указываем тип платы `Arduino Nano`, процессор `ATmega328P (Old Bootloader)`
(или `ATmega328P (without reset)` для режима эмуляции SPORTident).
Выбираем нужный COM порт и заливаем скетч MasterStation на плату (Файл->Папка со скетчами->MasterStation).

**Важно!** Без конденсатора на линии DTR-Reset не работает привычная процедура заливки прошивки.
Обязательно нужно обновить загрузчик на `ATmega328P (without reset)`.
Он ждёт 2 секунды после подачи питания по USB на плату, после чего загружает основную прошивку.
То есть для обновления прошивки (заливки скетча) нужно:
- отключить-подключить плату к USB;
- сразу после подать команду на обновление прошивки.

Примеряем корпус. Для провода вырезается небольшая канавка в корпусе. Светодиод промазывается эпоксидным клеем.



После чего корпус закрывается крышкой и готов к использованию.



### Вариант станции без печатной платы

Можно собрать станцию сопряжения без печатной платы. Светодиод, зуммер и RFID-модуль припаиваются проводками к Arduino Nano согласно схеме.



Рекомендуется использовать провод типа МГТФ-0,12.
Далее для такого варианта сборки разработан свой корпус, который можно распечатать на 3D-принтере.
Файлы для печати корпуса на 3D-принтере находятся в папке `hardware/MasterStation/3d/print`.







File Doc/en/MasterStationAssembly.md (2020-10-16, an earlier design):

# Master Station Assembly

### Master station components



1. RFID module RC522.
2. Arduino Nano.
You can connect directly to the computer.
There are variations on which chip USB-Serial is implemented: more expensive FT232RL or cheaper CHG340.
To connect the second you need to install the driver on Windows.
3. The PCB for soldering ([variant 1](https://upverter.com/AlexanderVolikov/3fc0efdb2586988d/Sportiduino-reading-stantion/) or
[variant 2](https://upverter.com/design/syakimov/4f7ec0e2d3b9c4e9/sportiduino-master-station/)).
You can order the manufacture of PCB in China (e.g. [JLCPCB](https://jlcpcb.com/)).
The cost depends on the lot, the minimum number is 5.
It is advisable to order boards for the master station simultaneously with the PCB for the base stations.
4. Pins, LED and buzzer. 
5. The case is Gainta 1020BF or 1015. Sold in Russia. 
6. USB-lace.
USB type depends on the port used in Arduino Nano (micro- or mini-USB).

### Arduino Nano preparation

First solder Arduino Nano.
ISP (2x3 connector) can not be soldered.



#### Arduino Nano preparation for SPORTident emulation

Remove capacitor at line DTR-Reset from Arduino Nano board.
It is located next to the USB controller chip.
After that burn fixed Optiboot bootloader (optiboot8_atmega328_38400_without_reset.hex)
using the ISP programmer.

### Station with PCB variant 1 and the G1020BF case

Solder Arduino Nano in the main board.
Also in the main board we solder a 1x8 connector, a angle-bent LED,
a buzzer and resistors 0805 47 ohm (to the buzzer) and 150 ohm (to the LED).



Solder the RFID module.
Then connect the master station via a USB wire to the computer.
 


Open the Arduino IDE program on the computer (see [Arduino IDE Setting](/Doc/en/BaseStationAssembly.md#Arduino-IDE-Setting)).
In the settings specify the board type `Arduino Nano`, processor `ATmega328P (Old Bootloader)`
(`ATmega328P (without reset)` for SPORTident emulation).
Select the appropriate serial port and upload MasterStation sketch onto the board.

For USB cable cut off a s small groove in the case.
The LED is greased with epoxy glue.
 


After that close the case.
The master station is ready for use.



### Station without PCB

The master station can be assembled without a PCB.
The LED, buzzer and RFID module are soldered by wiring to the Arduino Nano according to the scheme.



The station case is designed for 3D-printing.
Files for 3D-printer placed in the folder `hardware/MasterStation/3d/print`.







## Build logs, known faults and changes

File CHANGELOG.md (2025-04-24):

## v3.11.0 - 2025-04-24

- Added write and read protection for NTAG 21x cards by 4 bytes password.
- Documentation update

Base station firmware **v3.11.0**:
- Reduced clearing time for NTAG cards by about 2 times
- Check RTC IC on waking up from sleep (beep 2 times if error)
- Card expiration time now is 180 days after initialization or clearing
- Don't wake up by Sleep master card
- Don't wait at measuring battery voltage when writing State master card
- Blink LED at reed switch triggering

Master station firmware **v1.11.0**:
- Added NTAG authentication password to config
- Fixed reading a card as empty in the SPORTident emulation mode

For working with this firmware version use [SportiduinoPQ](https://github.com/sportiduino/sportiduinopq/releases/latest) >= 0.13, [SportiduinoApp](https://github.com/sportiduino/sportiduinoapp/releases/latest) >= 1.6 and [SportOrgPlus](https://github.com/sembruk/sportorg-plus/releases/latest).

[All changes](https://github.com/sportiduino/sportiduino/compare/v3.10.0...v3.11.0)

---

- Добавлена защита паролем (4 байта) от записи и чтения для NTAG 213/215/216
- Обновлена документация

Прошивка базовой станции **v3.11.0**:
- Сокращено время очистки чипов NTAG 21x до 2-х раз
- Проверка RTC IC при пробуждении станции (двойной короткий сигнал в случае ошибки)
- Срок действия чипа увеличен до 180 дней после инициализации или очистки
- Выключено пробуждение по чипу сна
- Не ждать при измерении напряжения аккумулятора при записи чипа состояния
- Мигание светодиода при срабатывании геркона

Прошивка станции сопряжения **v1.11.0**:
- Добавлена пароль аутентификации NTAG в настройки
- Исправлено ошибочное чтение чипа как пустого в режиме эмуляции SPORTident

Для работы с данной версией прошивок используйте [SportiduinoPQ](https://github.com/sportiduino/sportiduinopq/releases/latest) >= 0.13, [SportiduinoApp](https://github.com/sportiduino/sportiduinoapp/releases/latest) >= 1.6 и [SportOrgPlus](https://github.com/sembruk/sportorg-plus/releases/latest).

[Все изменения](https://github.com/sportiduino/sportiduino/compare/v3.10.0...v3.11.0)

## v3.10.0 - 2022-05-17

Base station firmware **v3.10.0**:
- Added Password master card
- New format of punches log (store timestamp for cards numbers 1...65535, maximum 4000 records)
- Wake up from Sleep mode if RTC alarm doesn't work
- New fast punch mode
- Check battery every ~10 min in Sleep Mode (disabled by default) if voltage < 3.5V beep SOS

Master station firmware **v1.9.0**:
- Write Password master card
- Read Log master card of new format

Added 3D model of the custom box for Base station

For working with this firmware version use [SportiduinoPQ](https://github.com/sportiduino/sportiduinopq/releases/latest) >= 0.11, [SportiduinoApp](https://github.com/sportiduino/sportiduinoapp/releases/latest) >= 1.2 and [SportOrgPlus](https://github.com/sembruk/sportorg-plus/releases/latest).

---

Прошивка базовой станции **v3.10.0**:
- Добавлен мастер-чип пароля
- Новый формат лога отметок (записывается время для чипов от 1 до 65535, максимум 4000 записей)
- Реализован выход из спящего режима, даже если будильник RTC не сработает
- Новый режим быстрой отметки
- Проверка аккумулятора каждые ~10 минут в спящем режиме (по умолчанию отключено), если напряжение < 3,5 В, станция подаёт сигнал SOS

Прошивка станции сопряжения **v1.9.0**:
- Добавлена поддержка мастер-чипа пароля
- Добавлена поддержка мастер-чипа лога отметок нового формата

Добавлена 3D модель корпуса для базовой станции. 

Для работы с данной версией прошивок используйте [SportiduinoPQ](https://github.com/sportiduino/sportiduinopq/releases/latest) >= 0.11, [SportiduinoApp](https://github.com/sportiduino/sportiduinoapp/releases/latest) >= 1.2 и [SportOrgPlus](https://github.com/sembruk/sportorg-plus/releases/latest).

[All changes/Все изменения](https://github.com/sportiduino/sportiduino/compare/v3.9.0...v3.10.0)

## MS-v1.8.4

- Fix SPORTident emulation for card reading

## MS-v1.8.3

- Disable autosend all SI-Card 6 pages for MeOS

## MS-v1.8.2

- SPORTident legacy protocol emulation for WinOrient 2014

## MS-v1.8.1

- Fix beep pause for time card

## [3.9.0] - 2021-05-14
Base station PCB v3b (2021-01-01):
- Added TP4056 with leds for Li-ion battery charging
- RC522 mini or RC522 boards
- Change board length to 73 mm

Base station firmware:
- Autosleep option in Config (go to sleep after ~48h in Wait Mode)
- Docs update

## [3.8.0] - 2020-11-25
Master station firmware:
- Emulation of SPORTident serial protocol ([GH-90](https://github.com/sportiduino/sportiduino/issues/90))
- Change baudrate to 38400 (SportiduinoPQ v0.9 and SportOrg v1.5.0+ >= [bf6c804](https://github.com/sportorg/pysport/commit/bf6c804))

Base station firmware:
- Fix card clearing ([GH-99](https://github.com/sportiduino/sportiduino/issues/99)) and checking ([GH-96](https://github.com/sportiduino/sportiduino/issues/96))
- Check Station: write punch to EEPROM ([GH-95](https://github.com/sportiduino/sportiduino/issues/95))

## [3.7.0] - 2020-04-13
New base station PCB:
- Added battery voltage measurement circuit (GH-63)
- Added EEPROM IC for backuping punches (GH-69)
- Added reed switch for wake up (GH-75)
- New 10-pin slot for programming (GH-68)
- Fixed increased power consumption by DS3231 (GH-61)

Firmware bug fixes and improvements:
- Decreased power consumption (GH-61)
- Fix overwriting last mark in full card (GH-84)
- Signal battery state at wake-up (GH-81)
- Card clearing accelerated
- New 3-bytes version format
- Deinitialize time and station number master cards by BS
- Simplified signal system
- Don't check password at serial BS communication
- Added makefiles for building and firmware uploading
- Refactoring

## [2.6.3] - 2020-01-20
- Fix NTAG cards detection (GH-73)
- Fix increased power consumption in sleep mode for PCB v2 (GH-61)

## [2.6.2] - 2019-12-12
- Fix increased power consumption in sleep mode for PCB v1 (GH-61)
- Changed default antenna gain to 33 dB

## [2.6.1] - 2019-08-26
- Fixed working with SportOrg
- Changed algorithm to work with Serial in BaseStation
- Added wake-up function for BaseStation v1

## [2.6.0] - 2019-07-26
- Base station - DS3231-Pin3 (Interrupt) has been connected to MCU-Pin26 (PC3)
- Base station - DS3231-Pin4 (Reset) has been connected to MCU-Pin32 (PD2)
- Base station - DS3231-Pin2 (VCC) has been disconnected from MCU-Pin9 (PD5) and connected to +3V3 directly (as single-supply scheme from datasheet)
- Base station - DS3231-Pin1 (32 kHz) has been connected to MCU-Pin9 (PD5)
- Base station - RC522-IRQ has been connected to MCU-Pin10 (PD6)
- Base station - BC847 (bipolar) has been changed to BSS138 (mosfet)
- Base station - The value of I2C pull-up resistors has been reduced from 10 kOm to 3.3 kOm
- Base station - New pcb board design
- Firmware of a base station has been fully refactored
- Firmware of a master station has been fully refactored
- Added wake-up function
- Added an ability to config a base station by UART
- Added GetInfo master-chip
- Added fast-mark setting
- Added antenna-gain setting
- Added an ability to determine a participant card type. And now the system can work with various card types simalteniously
- Designed a box for a master station to print on 3d-printer

## [1.4.2] - 2018-10-23
Delete antenna gain from setting-byte

## [1.4.1] - 2018-10-17
Mark beep change, reduce power for master station

## [1.4.0] - 2018-10-03
Added the ability to reduce the power of the antenna to choose the optimal range of the station

## [1.3.8] - 2018-06-25
### Added the program for work with the system
- The program is available at [separete rep](https://github.com/sportiduino/SportiduinoPQ). It is
based on [a python module](https://github.com/sportiduino/sportiduinoPython) and also on the PyQt package for creating window applications

## [1.3.7] - 2018-06-25
### Fix dump uploading
- Fix dump uploading

## [1.3.6] - 2018-06-23
### Mifare Bug fixes
- Fix setting bag fix for Mifare Base Station

## [1.3.5] - 2018-06-19
### Bug fixes
- The Check station signals the master chips
- The Clear station can clear a repeatedly non-empty chip with the same number
- Resetting the station settings with entering to sleep mode is configurable

## [1.3.4] - 2018-06-13
### Some changes
- reset station config with sleep entering
- fix sounds
- remove auto reading mode at master station

## [1.3.3] - 2018-06-10
### Added the capacitor to the battery power of the clock
- In some parts of the station, a problem arose with the hours rushing for 2-5 minutes per day. It turned out that the problem consists in unstabilized power supply, the output capacitor after the stabilizer does not cope. We need to add one more closer to clock. In new gerber files that problem is fixed. In older boards, the bug is easily corrected by soldering the capacitor directly to the clock's power outputs.

## [1.3.2] - 2018-06-08
### Add check station
- To simplify the procedure for checking the chips before the start, a check station mode was added. Also Since it does not record anything on the chip, participants can be trained in the marking chip on the base station

## [1.3.1] - 2018-06-06
### Speeded up the mark, changes in the settings of the base stations
- Due to optimization of chip reading, the time of the mark is reduced by 40 ms
- Added the ability to limit the maximum possible number of marks on the chip and, thereby, further reduce the time of the mark at the base stations
- In the cleaning station mode, the problem of re-cleaning the chip is solved.

## [1.3.0] - 2018-04-11
### Bug fix and new features
- Bug fix with set settings to station
- Add clear station mode
- Sound of the station is amplified by adding transistor to scheme
- Firmware for working with Mifare Classic S50 cards moved to the main repository

## [1.2.0] - 2018-02-17
### Changed the master station communication protocol
- The fixed packet up to 32 bytes is changed to a variable length packet with a maximum length of 32 bytes.
- Added functions to request the firmware version of the master station
- Added the function of transferring the station to automatic regime of cards reading

## [1.1.0] - 2018-02-13
### Delete regime station-page, bug fix
- To unify the work with the system, the mode in which the label was written to the page equal to the station number was deleted. A sequential mode is left with the search for the last blank page.
- Fixed the bug that occurs when initializing ntag 213 card
- Fixed the bug that occurs with transmitting log from base station

## [1.0.0] - 2018-02-11
### First stable version

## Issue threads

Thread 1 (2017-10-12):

Сделать перевернутый режим работы - у спортсменов станции, на кп метки

alexandervolikov, 2017-10-12:

Evgen-F, 2020-09-03:
Почему отказались от данной идеи?

alexandervolikov, 2020-09-03:
> Почему отказались от данной идеи?

Получается не очень удобно в современных реалях. Станции довольно массивные для ношения.

Evgen-F, 2020-09-03:
> > Почему отказались от данной идеи?
>
> Получается не очень удобно в современных реалях. Станции довольно массивные для ношения.

Тем не менее в определенных случаях оно имеет смысл. Мне например на тренировках в черте города значительно спокойнее повесить метки NTAG/MiFare на контрольные пункты - они нафиг никому не сдались, а в качестве чипов использовать станции - не такие они и большие выходят. Зато вероятность убытков от кражи станции стремится к нулю, и появляется возможность использовать эту систему электронной отметки на каждой тренировке.

mforis, 2020-09-03:
Оно то может и так, но участник может упасть и разбить базу, пусть вероятность мала, но так может быть. Да и от вибрации может что-нибудь повредиться. Я думаю, стоило бы подумать над бесконтактными базами, например, на финиш, чтобы участник просто пробегал через финишную арку и отметка уже в чипе.

Closed 2018-01-08.

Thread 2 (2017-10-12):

Сделать более легкособираемый вариант станции

alexandervolikov, 2017-10-12:
На материнской плате собирается навесным монтажом из блоков: Arduino pro mini, Ds3231, RC522.
Большая герметичная коробка, например, G203CMF

burunduk, 2017-11-21:
Про вариант: У китайцев популярна плата часов с батарейкой CR2032 и штырями.
это не увеличит автономность?

alexandervolikov, 2017-11-22:
Да, причем в плате с часами и батарейкой есть уже епром на 4к. Её и буду использовать для данного варианта. Платы для сборки из модулей уже приехали, скоро соберу, выложу что получилось.

alexandervolikov, 2019-01-11:
Поэкспериментировав, решил отказаться от этой идеи. С учетом необходимых доработок готовых плат (удаление лишних диодов и пр.), большего объема пайки (каждую ножку платы), проще и быстрее использоваться отдельные микросхемы как это реализовано сейчас в основном варианте.

Closed 2019-01-11.

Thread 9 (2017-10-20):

Заливка прошивки в Atmega.

mforis, 2017-10-20:

mforis, 2017-10-20:
Можно ли залить прошивку через Arduino Uno без программатора?

alexandervolikov, 2017-10-20:
Наверное, как-то это можно осуществить, если сделать прошивку совмещенную с буатлоадером, который умеет обрабатывать корректно прерывания от watchdog. Если заливать как есть просто через ArduinoAsISP, то она не работает, уходит в bootloop.

mforis, 2017-10-20:
Блииииннн... Очень плохо... Необходимо где-то срочно искать программатор...

mforis, 2017-10-20:
А что у вас за программатор?

alexandervolikov, 2017-10-20:
Я пользуюсь самым дешевым USB TTL-UART на чипе CHG340
https://ru.aliexpress.com/store/product/CH340G-5V-USB-to-TTL-UART-Serial-Converter/1950989_32524218818.html

Сейчас глянул, да можно обойтись и Arduino UNO для заливки прошивки, но из UNO нужно вытащить чип Atmega, если это возможно и замкнуть Reset на землю (https://forum.arduino.cc/index.php?topic=146258.0)
Тогда Arduino UNO превраиться в USB to UART и можно залить прошивку.

Но перед этим всё-равно надо залить правильный буатлодер - Optiboot
(https://github.com/Optiboot/optiboot)
пользуясь ArduinoAsISP на UNO.

mforis, 2017-10-20:
Александр, еще вопрос, а если у меня копия Arduino Uno с чипом CH340G? Могу ли я сразу прошить или тоже необходимо выполнять указания выше. Спасибо и извините за назойливость)))

alexandervolikov, 2017-10-20:
Сначала  залить прошивку ArduinoAsISP на Arduino UNO
(File - Examlpes - ArduinoAsISP). На Arduino UNO разместить конденсатор 10 мкФ между RST и GND. Подключить к программируемой плате пины 11,12,13 к MOSI, MISO, SCK соответственно. Пин 10 подключить к RST программируемой платы и запитать плату.

Далее установить Optiboot в IDE:
вставить URL-адресс:
https://github.com/Optiboot/optiboot/releases/download/v6.2/package_optiboot_optiboot-additional_index.json
в  "Additional Boards Manager URLs" в File-Prefernces
После этого прошивки станут ддоступны через меню Tools-Board
Для прошивки  нужно выбрать:
Board: Optiboot on 32 pins
Processor: ATmega328p
CPU Speed: 8Mhz (int)
Programmer: Arduino As ISP

Нажать Burn bootloader
Если всё нормально, появиться надпись
Done burning boatloader
Если нет, то где допущена ошибка, проверить правильность подключения, пайки и т.п.

Дальше отключаем UNO от программируемой платы. В IDE меняем программатор на "AVRISP mkII". Замыкаем на UNO пины  RST и GND. Подключаемм UNO к программируемой плате: RX-TX, TX-RX. Вроде как, если использовать UNO в качестве USB-UART, то пин RST на программируемой плате придётся нажимать (заземление для перезагрузки платы) вручную. Говорят, это нужно сделать в нужный момент во время загрузки прошивки, который определяется опытным путем.
С отдельным USB-UART, в котором есть DTR проще. Стоит он недорого, в том числе и в России.

alexandervolikov, 2017-10-20:
Но, если хочется залить прошивку просто для теста. То можно из Stantion.ino удалить строчки:
sleep(work);
//Power down regime: sleep 24 s
  if (deepsleep) {
    for (uint8_t i = 0; i<3; i++){
      sleep8s();
    }
  }
Это отключит вход в энергосберегающие режимы, будет кушать значительно больше батарейку, но проверить функциональность можно. И залить через ArduinoAsISP.

mforis, 2017-10-20:
Спасибо ОГРОМНОЕ! Если не сложно закиньте эту инструкцию в Wiki.

mforis, 2017-10-22:
Нашел у себя Arduino Nano с чипом CH340G, как с помощью неё прошить Atmega? По той же инструкции или как-то по другому?

alexandervolikov, 2017-10-22:
Да, с Arduino Nano всё тоже самое. Только нужно ещё нужно установить драйвера на Windows для схемы CHG340, чтобы Windows видела эти устройства.
Да, с платой версии 0.41 всё будет работать. Сейчас и в прошивке по-умолчанию внешняя eeprom выключена, за включение/выключение отвечает строчка:
const boolean extEeprom = false;

mforis, 2017-11-19:
Александр, пришли мне Atmegи и я впаял, начал заливать бутлоадер, но он не прошивается с такой ошибкой. Как решить проблему???
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

alexandervolikov, 2017-11-19:
Вероятно, схема плохо пропаялась. Проверьте с лупой или тестером все контакты.

mforis, 2017-11-19:
Блин, я всё уже по пять раз проверил, даже вторую плату собрал, но такая-же фигня...

alexandervolikov, 2017-11-19:
А конденсатор 10 мкФ на uno между rst и gnd стоит?

mforis, 2017-11-19:
Да, сейчас взял Нано, и выбило другую ошибку...
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

alexandervolikov, 2017-11-19:
У меня такая ошибка, обычно, выходит когда я плохо припаял. Казалось бы, всё делал четко и последовательно, все контакты пропаяны, но ошибка. Тогда ещё раз проходился паяльников по контактам и оно начинало работать. Худший вариант что может быть не так: атмега сгорела, например, если передержать паяльник на контактах.

Можете сделать следующее: снять с uno (или nano) конденсатор. Загрузить вот эту прошивку:
https://yadi.sk/d/aYVpiodu3PqAwH
И открыть Serial-port в IDE Arduino при подключенной программируемой плате. Это прошивка проводит диагностику и должна выдать то, что видит на SPI контактах.

mforis, 2017-11-19:
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

mforis, 2017-11-19:
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

mforis, 2017-11-19:
Капец как я расстроился, нифига не получается, ничего не работает! И не могу понять в чем косяк.
Пайку проверил, пропоял еще раз и ничего...

alexandervolikov, 2017-11-19:
Да, соединения с микроконтроллером нет. А как Вы соединялись платы? Можете прислать фото?
Не расстраивайтесь, я тоже бывало по нескольку часов сидел над платами в поисках ошибки

mforis, 2017-11-19:
Да, сейчас скину фотки....

mforis, 2017-11-19:
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

mforis, 2017-11-19:
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

alexandervolikov, 2017-11-19:
У Вас rst контроллера не подключен, это тот который уходит в другой конец платы (там где два ряда по три дырки, сейчас он у Вас не распаян). Тот rst, который подключен к Вас относится к rc522 и при прошивке он не задействован.
Если не получится, еще можно попробовать прошить при 5в (переставить в uno соответствующий штырек )

alexandervolikov, 2017-11-19:
Вот сравните с моими фото при прошивке
https://user-images.githubusercontent.com/32615135/32993556-0f472c92-cd6b-11e7-958f-a5bdd66cdeda.jpg
https://raw.githubusercontent.com/alexandervolikov/sportiduino/master/Images/s11.jpg

mforis, 2017-11-19:
Всё бут прошил!
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

mforis, 2017-11-19:
Теперь проблема с заливкой скетча, когда нажимать ресет и где? На ардруине?
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

alexandervolikov, 2017-11-19:
Нет, нажимать нужно на програмируемой плате. Для этого в нужный момент нужно заземлить и отпустить контакт rst (тот же который в двух рядах по три дырки). Сам таким путем никогда не прошивал, поэтому тонкостей не знаю, но читал, что момент нажатия подбирается опытным путем, нужно некоторое число попыток.

alexandervolikov, 2017-11-19:
Момент засеките по прогрессу загрузке в окне ардуино внизу справа, должно быть около 80% заполнения этой полосы. Когда скетч уже откомпилируется

mforis, 2017-11-19:
Хорошо, спасибо. Завтра буду продолжать программирование плат.

mforis, 2017-11-20:
После нажатия заземление RST процесс зависает....
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

mforis, 2017-11-20:
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

alexandervolikov, 2017-11-20:
Попробуйте сделать вот по этой инструкции:
https://www.youtube.com/watch?v=jk-uq3dlvKs
Только выбрав нужную прошивку и программатор.

alexandervolikov, 2017-11-20:
То есть, задача такая же как прошить Arduino Pro Mini. В сети есть инструкции.

mforis, 2017-11-20:
Пока залить скетч не получается....😢

alexandervolikov, 2017-11-20:
Есть так же вероятность, что Rx Tx плохо пропаяны. Ещё также важно подключение попарно Rx-Tx, Tx-Rx. Возможно стоит питание подвести от 5 вольт при прошивке (у меня где-то платы 3 из 50 прошиваются только таким образом)
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
alexandervolikov, 2017-11-20:
Да, кстати, сейчас посмотрел фотографии, что Вы присылали выше. На тех фотографиях у Вас подключен неправильный Reset. Выше я уже писал, что при прошивке микроконтроллера нужно использовать контакт, который находится в разъемах два ряда по три дырки. Reset, который находится ближе к микроконтроллеру относится к плате RC522.

mforis, 2017-11-20:
А может проблема этом?
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

alexandervolikov, 2017-11-20:
Не думаю. У меня при прошивке буатлоадера пишет тоже самое.

mforis, 2017-11-20:
Ясно. Буду капать дальше...

mforis, 2017-11-20:
А в плате RX слева и TX справа? А то шелкография не очень понятна...

alexandervolikov, 2017-11-20:
Rx - ближний к микросхеме контакт, Tx - дальний

mforis, 2017-11-20:
Самое интересное, что бут шьётся без "Б", а скетчи не хотят...

mforis, 2017-11-20:
Уже и МК выпаивал... И чего только не делал...

alexandervolikov, 2017-11-20:
А пришлите фото как Вы с выпаянной МК подключаете платы между собой

mforis, 2017-11-20:
Заработало!!!!!!!!!!!!!!!!!!!

mforis, 2017-11-20:
Прошивал по этой инструкции, только с конденсатором.
https://youtu.be/Rz1tFghOoiQ

alexandervolikov, 2017-11-20:
Поздравляю! :-)

mforis, 2017-11-20:
И опять новая проблема.... База запускается пикает три раза, через какое-то время пикает еще раз... И  всё больше от неё нет реакции...

alexandervolikov, 2017-11-20:
Предварительно стоит записать мастер-чипы номера станции (240 например), обновления времени и пару обычных чипов. После вставления батареек станция три раза пикнет, что говорит и том, что часы выставлены не верно. Затем через 5 секунд будет длинный сигнал, сигнализирующий, что программа вошла в цикл работы. По умолчанию это режим сна, поэтому станция среагирует на чип устаноки номера станции только через 25 секунд после её поднесения, но можно сразу положить станцию на чип перед вставкой батарей. Станция запишет новый номер ,перезагрузится, и теперь уже способна реагировать на обычные чипы. Подносим чип, ждем до 25 секунд, станция переходит в рабочий режим. Но часы по-прежнему сбиты. В рабочем цикле подносим мастер-чип времени и после перезагрузки подносим второй обычный чип. Считываем его на станции сопряжения и убеждаемся в корректной работе. Если всё так, то станцию можно отмывать. Если нет, то нужно поискать возможные ошибки, прежде всего, в спайке модуля RFID.

alexandervolikov, 2017-11-21:
Принципиальную работу модуля ещё можно проверить, если залить туда прошивку из примера DumpInfo библиотеки RC522:
https://github.com/alexandervolikov/sportiduino/blob/master/Libraries/RFID/examples/DumpInfo/DumpInfo.ino

mforis, 2017-11-21:
При подносе мастер чипа база 6 раз пикает, потом пикает  быстро 3 раза и начинает бысро пикать в чем проблема?

alexandervolikov, 2017-11-21:
Возможно, бутлоадер не тот. Вы заливали при прошивке optibut 32pin 8mhz?

mforis, 2017-11-21:
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

mforis, 2017-11-21:
А кстати, вы есть в ВК? Может там будет удобнее общаться?

alexandervolikov, 2017-11-21:
Да, вроде всё верно. Просто признаки - беспрерывное пикание может указывать на то, что вотчдог работает некорректно. Не знаю в чём проблема. А можете скинуть фото спаянной схемы?
В вк я есть, но там общаться не очень удобно. Лучше здесь или по почте:
ab.volikov@gmail.com

mforis, 2017-11-21:
А может это следствие моего метода прошивки?

alexandervolikov, 2017-11-21:
Не, не думаю.
А какую версию прошивки Вы загружали?

mforis, 2017-11-21:
0.43

mforis, 2017-11-21:
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

alexandervolikov, 2017-11-22:
Посмотрел видео по методу заливки прошивки. Да, дело в этом. Таким образом вместе с заливкой прошивки стирается буатлоадер. Поэтому функции связанные с вотчдогом перестают нормально работать.
Так что, предлагаю просто купить и подождать Serial-TTL конвертер. Только нужно обязательно с работающим DTR пином брать. По ссылке выше от Robotdyn работающий.

Если хочется протестировать как всё работает, то можно залить прошивку методом, который у Вас получился. Только в цикле loop оставить лишь одну функцию - rfid():

void loop ()
{
 rfid();
}

Все функции, связанные с вотчдогом в таком случае будут отключены. Всё даже быстрее будет работать, но и энергопотребления будет большим. Комплекта пальчиковых батареек хватит лишь примерно на 5 дней.

mforis, 2017-12-01:
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
Раздобыл такой конвертер, сегодня буду пробовать опять прошить.
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

mforis, 2017-12-01:
Одну базу собрал полностью, ещё 4 прошил, осталось ещё 5))) И буду проводить испытания, а там если всё ок буду заказывать новую партию деталей.
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

Closed 2017-10-20.

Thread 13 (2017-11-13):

Баг с записью чипов

alexandervolikov, 2017-11-13:
С некоторым шансом при плохих условиях прикладывания чипа станция пишет отметку не в последнюю пустую страницу а в какую-то промежуточную.
Вероятно, при считывании с какой-то пустой страницы, на станцию приходит, что она не пустая.
Из-за этого явления возникают критические ошибки с перезаписью уже существующих данных на страницы.
Возможно, при очистке нужно писать в страницы не нули, а какую-то контрольную информацию.
А пока прошивками 0.42.x пользоваться нельзя.

mforis, 2017-11-14:
Скиньте пожалуйста, самую стабильную на данный момент прошивку.

alexandervolikov, 2017-11-14:
Точно стабильная - это 0.37. На ней проводились соревнования, и всё было хорошо. Но она рассчитана на 46 отметок
https://github.com/alexandervolikov/sportiduino/tree/fbe66d3bbb6a0b0fddf518feaf086d0d8c350f17
Если важно именно 92 отметки, то, вероятно, последняя устойчивая версия - 0.41. До введения бинарного поиска.
https://github.com/alexandervolikov/sportiduino/tree/7e51d193c366d96c4dc2d69648cfd7573fe4ffbb

mforis, 2017-11-14:
Спасибо, пока достаточно 46 отметок. Со дня-на-день придут МК и до соберу и буду прошивать. Уже не терпится провести полевые испытания))) фотки:
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

alexandervolikov, 2017-11-15:
Отлично! Если что, пишите. А баг я постараюсь в скором времени ликвидировать.

alexandervolikov, 2017-11-19:
Баг исправил. Проблема возникла из-за того, что функция поиска последней страницы в случае неудачного поиска (если чип был приложен плохо) не вызывала выход из функции записи чипов, в результате чего станция могла записать метку в страницу, которую считала у предыдущего чипа.
Сейчас исправлено. Также решил отказаться от 92 меток и записывать на Mifare Classic только 46 меток, по числу страниц, чтобы повысить надежность записи.

Closed 2017-11-19.

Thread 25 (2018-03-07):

Ошибка при прошивке.

mforis, 2018-03-07:
При попытке залить прошивку версии 0.43.1 выбивает вот такую ошибку: Arduino: 1.8.5 (Windows 7), Плата:"Optiboot on 32-pin cpus, 8MHz (int), ATmega328p"

C:\Users\РњРђРљРЎР?Рњ Р¤РћР Р?РЎР¬\Desktop\sportiduino-master Р’РµСЂСЃРёСЏ 0.43\Mark stantion\Arduino_Scetches\Stantion\Stantion.ino:20:24: warning: multi-line comment [-Wcomment]

In file included from C:\Users\РњРђРљРЎР?Рњ Р¤РћР Р?РЎР¬\Desktop\sportiduino-master Р’РµСЂСЃРёСЏ 0.43\Mark stantion\Arduino_Scetches\Stantion\Stantion.ino:7:0:

C:\Program Files (x86)\Arduino\libraries\RFID/MFRC522.h:408:10: warning: extra qualification 'MFRC522::' on member 'MIFARE_Ultralight_Key' [-fpermissive]

     void MFRC522::MIFARE_Ultralight_Key (byte *arr);

          ^

In file included from C:\Users\РњРђРљРЎР?Рњ Р¤РћР Р?РЎР¬\Desktop\sportiduino-master Р’РµСЂСЃРёСЏ 0.43\Mark stantion\Arduino_Scetches\Stantion\Stantion.ino:8:0:

C:\Program Files (x86)\Arduino\hardware\arduino\avr\libraries\EEPROM\src/EEPROM.h:43:30: warning: type qualifiers ignored on function return type [-Wignored-qualifiers]

     operator const uint8_t() const       { return **this; }

                              ^

C:\Program Files (x86)\Arduino\hardware\arduino\avr\libraries\EEPROM\src/EEPROM.h:92:26: warning: type qualifiers ignored on function return type [-Wignored-qualifiers]

     operator const int() const          { return index; }

                          ^

C:\Users\РњРђРљРЎР?Рњ Р¤РћР Р?РЎР¬\Desktop\sportiduino-master Р’РµСЂСЃРёСЏ 0.43\Mark stantion\Arduino_Scetches\Stantion\Stantion.ino: In function 'void setup()':

Stantion:88: error: 'struct ts' has no member named 'unixtime'

C:\Users\РњРђРљРЎР?Рњ Р¤РћР Р?РЎР¬\Desktop\sportiduino-master Р’РµСЂСЃРёСЏ 0.43\Mark stantion\Arduino_Scetches\Stantion\Stantion.ino: In function 'void i2cEepromWriteTime(unsigned int)':

Stantion:301: error: 'struct ts' has no member named 'unixtime'

C:\Users\РњРђРљРЎР?Рњ Р¤РћР Р?РЎР¬\Desktop\sportiduino-master Р’РµСЂСЃРёСЏ 0.43\Mark stantion\Arduino_Scetches\Stantion\Stantion.ino: In function 'uint32_t i2cEepromReadTime(unsigned int)':

C:\Users\РњРђРљРЎР?Рњ Р¤РћР Р?РЎР¬\Desktop\sportiduino-master Р’РµСЂСЃРёСЏ 0.43\Mark stantion\Arduino_Scetches\Stantion\Stantion.ino:340:41: warning: ISO C++ says that these are ambiguous, even though the worst conversion for the first is better than the worst conversion for the second:

In file included from C:\Users\РњРђРљРЎР?Рњ Р¤РћР Р?РЎР¬\Desktop\sportiduino-master Р’РµСЂСЃРёСЏ 0.43\Mark stantion\Arduino_Scetches\Stantion\Stantion.ino:4:0:

C:\Program Files (x86)\Arduino\hardware\arduino\avr\libraries\Wire\src/Wire.h:64:13: note: candidate 1: uint8_t TwoWire::requestFrom(int, int)

     uint8_t requestFrom(int, int);

             ^

C:\Program Files (x86)\Arduino\hardware\arduino\avr\libraries\Wire\src/Wire.h:61:13: note: candidate 2: uint8_t TwoWire::requestFrom(uint8_t, uint8_t)

     uint8_t requestFrom(uint8_t, uint8_t);

             ^

C:\Users\РњРђРљРЎР?Рњ Р¤РћР Р?РЎР¬\Desktop\sportiduino-master Р’РµСЂСЃРёСЏ 0.43\Mark stantion\Arduino_Scetches\Stantion\Stantion.ino: In function 'uint8_t coun(uint8_t, uint8_t)':

C:\Users\РњРђРљРЎР?Рњ Р¤РћР Р?РЎР¬\Desktop\sportiduino-master Р’РµСЂСЃРёСЏ 0.43\Mark stantion\Arduino_Scetches\Stantion\Stantion.ino:667:9: warning: statement has no effect [-Wunused-value]

C:\Users\РњРђРљРЎР?Рњ Р¤РћР Р?РЎР¬\Desktop\sportiduino-master Р’РµСЂСЃРёСЏ 0.43\Mark stantion\Arduino_Scetches\Stantion\Stantion.ino: In function 'void checkTime()':

Stantion:700: error: 'struct ts' has no member named 'unixtime'

Stantion:700: error: 'struct ts' has no member named 'unixtime'

C:\Users\РњРђРљРЎР?Рњ Р¤РћР Р?РЎР¬\Desktop\sportiduino-master Р’РµСЂСЃРёСЏ 0.43\Mark stantion\Arduino_Scetches\Stantion\Stantion.ino: In function 'void rfid()':

Stantion:866: error: 'struct ts' has no member named 'unixtime'

C:\Users\РњРђРљРЎР?Рњ Р¤РћР Р?РЎР¬\Desktop\sportiduino-master Р’РµСЂСЃРёСЏ 0.43\Mark stantion\Arduino_Scetches\Stantion\Stantion.ino:724:12: warning: unused variable 'code' [-Wunused-variable]

C:\Users\РњРђРљРЎР?Рњ Р¤РћР Р?РЎР¬\Desktop\sportiduino-master Р’РµСЂСЃРёСЏ 0.43\Mark stantion\Arduino_Scetches\Stantion\Stantion.ino: In function 'bool writeTime(int)':

Stantion:1060: error: 'struct ts' has no member named 'unixtime'

Stantion:1069: error: 'struct ts' has no member named 'unixtime'

C:\Users\РњРђРљРЎР?Рњ Р¤РћР Р?РЎР¬\Desktop\sportiduino-master Р’РµСЂСЃРёСЏ 0.43\Mark stantion\Arduino_Scetches\Stantion\Stantion.ino:1050:8: warning: unused variable 'ok' [-Wunused-variable]

C:\Users\РњРђРљРЎР?Рњ Р¤РћР Р?РЎР¬\Desktop\sportiduino-master Р’РµСЂСЃРёСЏ 0.43\Mark stantion\Arduino_Scetches\Stantion\Stantion.ino:1051:11: warning: unused variable 'syndrome' [-Wunused-variable]

C:\Users\РњРђРљРЎР?Рњ Р¤РћР Р?РЎР¬\Desktop\sportiduino-master Р’РµСЂСЃРёСЏ 0.43\Mark stantion\Arduino_Scetches\Stantion\Stantion.ino:1052:12: warning: unused variable 'decode' [-Wunused-variable]

exit status 1
'struct ts' has no member named 'unixtime'
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

alexandervolikov, 2018-03-07:
Похоже, что не установлена библиотека ds3231.
Попробуйте скопировать библиотеку https://github.com/alexandervolikov/sportiduino/tree/master/Libraries/ds3231-master
в папку где они у Вас хранятся, например в
C:\Users\username\Documents\Arduino\libraries

alexandervolikov, 2018-03-07:
Похоже, что вообще все библиотеки слетели и из нужно заново подключить.
Библиотеку Хамминга я удалил из репоизтория, прилагаю.
[Hamming.zip](https://github.com/alexandervolikov/sportiduino/files/1789495/Hamming.zip)

alexandervolikov, 2018-03-07:
Добавил поддержку чипов Mifare S50. Написал отдельные прошивки для работы с ними. Для мастер станции и базовых станций соответственно.

Работают чуть медленнее. Число отметок до 42. Но полностью поддерживается разрабатываемым программным обеспечением. Потом ещё внесу это в основной репозиторий. А пока просто прилагаю тут. Лучше пользоваться данными версиями чем 0.43.1.

[SportiduinoMifare.zip](https://github.com/alexandervolikov/sportiduino/files/1790580/SportiduinoMifare.zip)

sembruk, 2018-03-07:
Есть смысл оформить это в виде ветки. Могу сделать.

alexandervolikov, 2018-03-07:
Да, давай, если не затруднит.

sembruk, 2018-03-07:
Вот
https://github.com/alexandervolikov/sportiduino/tree/mifare_s50

mforis, 2018-03-08:
Ооо, круто, сегодня прошью свои базы на новую прошивку)))

mforis, 2018-03-08:
Как залить прошивку без выпаивания RFID-модуля?

alexandervolikov, 2018-03-08:
Точно так же. Подключить rx, tx, rst usb-uart, запитать, прошить. Модуль rc522 не влияет на этот процесс, его выпаивать не надо.

mforis, 2018-03-08:
Такая проблема, прошил я значит базы на новую прошивку. Но при поднесении любого мастер чипа станция издает три очень быстрых сигнала. В чем проблема?

mforis, 2018-03-08:
Очень срочно нужна помощь!!!

alexandervolikov, 2018-03-08:
Возможно, дело в установленных паролях мастер чипов. Нужно выставить 0, как по умолчанию после прошивки. Но не уверен. Сейчас возможности проверить и протестировать нет, только после праздников.

mforis, 2018-03-08:
//master chips number in the first three bytes of the chip in the first page
const uint8_t timeMaster = 250;
const uint8_t numberMaster = 251;
const uint8_t sleepMaster = 252;
const uint8_t dumpMaster = 253;
const uint8_t passMaster = 254;

Что означают эти строки?

sembruk, 2018-03-08:
Коды мастер чипов
https://github.com/alexandervolikov/sportiduino/blob/master/Doc/ru/Card.md

mforis, 2018-03-08:
Мг... Станции без проблем берут обычные чипы, но с мастер чипами какие-то проблемы... Самое интересное, что в воскресенье мне нужно будет проводить соревнования с ними... А я тут обновление прошивки затеял... Завтра попробую что-нибудь, а если нет прошью прошивку версии 0.43.1

sembruk, 2018-03-08:
Нужно проверить, что в ячейках для пароля на мастер чипе нули. Для этого нужно прочитать сырые (raw) данные с чипа. Формат ячеек по ссылке ранее.

sembruk, 2018-03-08:
Или ещё есть мысль, что в пароль на станции просочился мусор из EEPROM от прошлой прошивки. Если так, то стирание EEPROM должно помочь. Это можно сделать с помощью Ардуинки в режиме программатора. Про переходник USB-UART не могу сказать.

mforis, 2018-03-08:
Проверил, в там пароли - нули. А как произвести стирание EEPROM, опишите пожалуйста процесс. После стирания придется заново прошивать базы?

sembruk, 2018-03-08:
https://www.arduino.cc/en/Tutorial/EEPROMClear
Вот нашел ввриант. Залить спецпрошивку, которая сотрет eeprom.

sembruk, 2018-03-08:
Железа у меня сейчас нет, проверить не могу.

alexandervolikov, 2018-03-09:
Нашел источник проблемы. Вот с этой прошивкой должно работать. Железа, чтобы проверить, сейчас тоже нет.
[BaseStation.zip](https://github.com/alexandervolikov/sportiduino/files/1795907/BaseStation.zip)

mforis, 2018-03-09:
Отлично, спасибо. Приду домой проверю, после отпишусь)

mforis, 2018-03-09:
Так, вроде бы всё работает, но как сделать, что-бы после отметки ФИНИШ (245), остальные базы уже не реагировали на этот чип, до отчистки?

mforis, 2018-03-09:
Что-то мне эта новая версия софта не очень нравиться... Время за которое участник прошел дистанцию не отображается, не удобно

mforis, 2018-03-09:
Убив два часа, я понял что зря обновил свои станции, правду говорят: - "Старый друг - лучше новых двух.", так и получилось. Я несколько раз до дыр прочитал инструкцию к программе, но так ничего и не понял! Старая версия в сто раз лучше!

Closed 2018-03-12.

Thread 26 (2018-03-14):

Поднять скорость обмена по UART до 115200

sembruk, 2018-03-14:
Проверил. Работает.

alexandervolikov, 2018-03-15:
Тоже пробовал. У меня почему-то не работает. Но да это вроде и не особо принципиально, скорость передачи ограничена скоростью чтения чипа - порядка 20 мс на чтение одной страницы чипа, то есть, порядка 2000 бауд.

sembruk, 2018-03-16:
Да, в таком случае смысла поднимать скорость пока нет.

Closed 2018-03-20.

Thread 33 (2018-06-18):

Нюансы в прошивке 1.3.4

mforis, 2018-06-18:
Доброго времени суток! Обновил я прошивки в своих базах, но нашел некоторые недороботки(по моему мнению):
1. Станция проверки не выполняет свою функцию. Например, я взял чип, чтобы "усыпить" базы, через компьютер его не очищаю, очищаю с помощью базы очистки - всё прошло успешно, прикладываю к базе проверки - успешно, выдаю участнику и опа - чип не отмечается на старте.
2. К примеру, я очистил чип базой очистки, решил проверить работоспособность базовых станций, прикладываю чип к базе очистке - очистка не происходит!
3. Зачем при входе в сон сбрасывать настройки, ведь неудобно, перед каждыми соревнованиями выставлять, что-бы старт был обязательным.

mforis, 2018-06-19:
Хорошо, с этим понятно. Но вот заметил ещё одну проблему, одна из баз, среди ночи начала издавать периодические длинные сигнала, до тех пор, пока не отключил питание.  ли это быть потому, что я временно заменил стабилизатора на AMS1117?

alexandervolikov, 2018-06-19:
Обновил прошивки. в 1.3.5. постарался исправить всё это. Но пока не тестировал.

На счёт издавания длинных сигналов - это станция зависает и перезагружается по кругу. Да, возможно, какие-то проблемы с питанием.

mforis, 2018-06-19:
Александр, еще такой вопрос, а можно ли подпаять электролит к часам? или только керамика?

alexandervolikov, 2018-06-19:
Думаю, что можно. Удобно smd конденсатор впаивать, там по сути между соседними ножками, вот как я впаивал
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

mforis, 2018-06-19:
Протестировал версию 1.3.5.
1. Настройки не сбивается.
2. Мастер-чипы по прежнему работают некорректно.
3. С базой очистки всё идеально!
4. При прикладывании чипа к базе проверки она издает три сигнала и так на все чипы, в т. ч. мастер-чипы, только- что очищенные и (или) инициализированные.

mforis, 2018-06-20:
Да, нет, обновлял время несколько раз.

alexandervolikov, 2018-06-20:
Да, не учёл один ньюанс для Mifare карт. Сейчас поправил, протестировал, вроде работает корректно.

mforis, 2018-06-20:
Ведь можно же обновить прошивку только в базе проверки, чтобы все не прошивать?

alexandervolikov, 2018-06-20:
Да, конечно. Если использовать станции как базовые, ничего не поменялось с 1.3.0.

mforis, 2018-06-22:
Александр, не могли бы вы скинуть мне файл settings.csv? А то поменял setst на 44, а настройки всё равно сбиваются...

mforis, 2018-06-22:
Хотя... Оказалось, что проблема только в одной базе, наверное не обновил прошивку

mforis, 2018-06-22:
Блин, нет, всё-же скиньте

alexandervolikov, 2018-06-22:
Вот. Только 44 для Mifare тоже что и 12.
[settings.zip](https://github.com/alexandervolikov/sportiduino/files/2129038/settings.zip)

mforis, 2018-06-23:
К сожалению, не помогло. Может проблема в прошивке?

alexandervolikov, 2018-06-23:
Да, проверил, действительно, не работает. Попробую разобраться в чем дело.
А пока просто используйте для базовых станций пошивку 1.3.0, а для станции очистки и проверки 1.3.5.

alexandervolikov, 2018-06-23:
Нашёл источник ошибки. Исправил в 1.3.6. Протестировал, работает, настройки не сбрасываются.
Также для Mifare не работает проверка времени инициализации чипа в режиме базовой станции.

Closed 2018-06-19.

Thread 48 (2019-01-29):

Non-blocking i2c

fimich1, 2019-01-29:
Библиотека не может быть запущена, потому что пробелы в названии не допускаются
нужно к, примеру так: Non-blocking_i2c

alexandervolikov, 2019-01-29:
Эту библиотеку не совсем обычная. Нужно скопировать папку "Wire" из ней сюда:
C:\Program Files (x86)\Arduino\hardware\arduino\avr\libraries\

fimich1, 2019-01-29:
Перепрошить уже прошитую станцию удается только после заново залитого бутлоадера. По другому - никак не удалось. Возможно ли в PQ кнопку спец режима для перепрошивки сделать?

alexandervolikov, 2019-01-29:
Прошить станцию можно только в течение 5 секунд после подачи питания. После чего она входит в цикл с режимами сна, в которых прошивка невозможна.
Для этого в ардуино нажимаем прошить, ждём пока пройдёт компиляция (где-то 3/4 полосы загрузки) и до загрузки втыкаем usb-uart и питанием в порт.

mars2860, 2019-01-29:
А я бы отказался от UART-бутлоадера. Не вижу в нём смысла. Вот если бы можно было залить новую прошивку на мастер-чип и обновить станцию - тогда да. А так проще купить себе программатор простой Pickit2 или usbasp и шить новую прошивку без бутлоадера.

fimich1, 2019-01-29:
---Прошить станцию можно только в течение 5 секунд после подачи питания. После чего она ---входит в цикл с режимами сна, в которых прошивка невозможна.
Для этого в ардуино нажимаем прошить, ждём пока пройдёт компиляция (где-то 3/4 полосы загрузки) и до загрузки втыкаем usb-uart и питанием в порт.

вот именно этим способом на своем компе прошить ни разу не удалось, пробовал много

halny123, 2019-01-29:
Изначально у меня тоже была проблема с прошивкой .
Как я ее решил написал тут https://github.com/halny123/sportiduino/tree/master/NRFstation
в разделе О ПРОШИВКЕ.
Теперь шьется без проблем в любой момент.
А чем прошиваете и схема подключения станция - USB-UART какая можно узнать ? И какой преобразователь  USB-UART ?

fimich1, 2019-01-29:
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
Все подключено как у Александра, и первый раз все шьется и работает. Не срабатывает именно если нужно перепрошить. 75% компиляции скетча может не смог поймать... Если залить оптибут через ардуино (у меня уно) то все стирается и прошивается. Но если станция залита компаундом, то заново влить бутлоадер еже без расковырки никак. В общем будет проблема в будущем, как придет время менять прошивку.
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

alexandervolikov, 2019-01-29:
Попробуйте прошить, подключив пин DTR вместо RST (они вроде как раз и отличаются наличием дополнительного конденсатора).
Ну а так да, ещё от схемы в USB-UART зависит гладкость процесса. Я в итоге перешел на схему CP2102, с ним шьётся лучше.

halny123, 2019-01-29:
По первой фото, если у Вас плата Алексея, то насколько я вижу ПЕРЕПУТАНО питание!!!
Не погорел ли после этого стабилизатор 3,3В ?
И остальное подключение не верно.

UART - цвет - Плата Sportiduino
GND -  красный - +5V                    ОШИБКА !!!
+5v -  коричневый - GND              ОШИБКА !!!
RXD    - серый  -RX                         ОШИБКА - нужно взять сигнал с TXD UART
 DTR  - фиолетовый  -TX                 ОШИБКА - нужно взять сигнал с RXD UART
reset - черный - Reset                     ОШИБКА - нужно взять сигнал с DTR  UART

еще у меня китайская плата преобразователя формирует на DTR низкий уровень постоянно при программировании, а должен формироваться импульс сброса. Поэтому проверьте во время программирования какой уровень на ножке Reset . Если там присутствует постоянный 0 то последовательно с линией сброса паяем конденсатор 0,1мк.

И еще на какой скорости происходит программирование ?

fimich1, 2019-01-29:
Фото под таким углом просто, подключено правильно, так как первый раз прошивка проходит: (done)/ станция сигналит. Тут же пытаюсь прошить второй раз - отключаю, нажимаю шить - жду секунд 5 (75 процентов у меня нет, сначала 0 потом сразу 100) - нет
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

. DTR вместо RST пробовал, станция не сигналит второй раз после подачи питания, но все равно не шьется. Конденсатор межу RST и GND тоже не привел к успеху, правда он 10мкф.
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

halny123, 2019-01-29:
Давайте попробуем сначала:
Мне кажется мы запутались в терминологии есть два этапа прошивки.
1-й этап -  Загрузка бутлоадера через програматор по SPI интерфейсу - то что у вас на второй картинке, где конденсатор. НО ОН ТАМ НЕНУЖЕН !!
На этом этапе загружается прошивка которая в дальнейшем позволить прошивать МК через UART интерфейс.
Дальше то что делаю я !!!!!
ДЕЙСТВИЯ ОТЛИЧАЮТСЯ ОТ ОПИСАННЫХ АЛЕКСЕЕМ ИЗ ЗА РАЗНЫХ СБОРОК БУТЛОАДЕРОВ !!!

(Можете взять мою прошивку бутлоадера
https://github.com/halny123/sportiduino/blob/master/NRFstation/Bootloader_Optiboot/bootloaders/myoptiboot/optiboot_atmega328_8M_38K400_D4_3flash.hex
если прошивка пройдет удачно то после подачи питания станция 3раза мигнет светодиодом
 )
Давайте пройдем этот этап.
Прошиваем, подаем питание - и видим мигание 3 раза светодиодом.

Если все будет так переходим ко второму этапу.

2-й этап
Прошивка через UART
Для нее нужно правильно настроить среду Ардуино (но это после прохождения 1-ого этапа)

fimich1, 2019-01-29:
Да, картинки не в той последовательности загрузились. Если сначала то так:
1 этап нармально проходит
2 этап нормально проходит.
Станции работают.
В качестве эксперимента предполагаю что в будущем нужно будет поменять прошивку.
Пытаюсь ещё раз прошить. Только 2 этап, так как станция, допустим, залита компаундом.
Вот этот второй этап не проходит.

alexandervolikov, 2019-01-29:
Ещё как вариант. Можно попробовать прошивать станцию во время её работы в "рабочем режиме".  Должно пройти и с залитой компаундом платой. Принцип тот, что в каждом цикле станция засыпает на 250 мс, но время поиска страницы для отметки в начале чипа составляет порядка 160 мс + время сигнала, что чип уже отмечен 1000 мс. Поэтому с вероятностью  80% мы попадаем в режим, когда станция может прошиться.
1. Подсоединить станцию к компьютеру через USB-UART
2. Перевести станцию в рабочий режим - поднести пустой чип.
3. Положить чип под станцию так, чтобы она пробовала сделать туда повторную отметку. Пускай пикает.
4. Пробовать прошить. Если не получилось - повторить.

halny123, 2019-01-29:
Думаю это не выход. Если сигнал сброса правильно формируется то не важно в каком режиме находится станция, после сброса  управление передастся бутлоадеру, а он подождет некоторое время данных от UART.
Изначально нужно смотреть формируется ли сброс правильно.

fimich1, 2019-02-01:
вариант с мигающим чипом не прошел, альтернативный оптибут пробую

halny123, 2019-02-01:
Мой оптибут требует настройки среды Arduino !!!! Я у себя описал какой.
Если нужно подскажу что непонятно.
Но хотелось бы все таки узнать, формируется ли у вас сигнал сброса ?
Что происходит на плате SportIduino на выводе Reset  , до - во время попытки программирования ?
Изначально там должен висеть высокий уровень 3,3В во время начала программирования формируется кратковременно импульс сброса - 0В. Есть ли это ?

fimich1, 2019-02-04:
----На Reset станции подключаем DTR UART. Измерить напряжение на ножке Reset на станции до прошивки и во время прошивки.
Результаты озвучить > до прошивки 3.3.V, во время прошивки 0,   если подключал не DTR a RST то там был логический 1 все время.

---Проверить подключение RX-TX на плате станции и UART. Если правильно подписано все то должно подключаться перекрестно. Но на всякий случай поменять местами и проверить повторно.
> менял конечно

---Ситуация с непрошивкой наблюдается на 1-ой станцией или нескольких ?
> все станции. были сначала на mifare, пришли чипы - перепрошил только опять подключив через spi

fimich1, 2019-02-04:
осцилографа нет..04.02.2019, 11:26, "Виталий" <notifications@github.com>:На DTR видим формируется сигнал низкого уровня при прошивке, но  постоянный, а должен быть импульс - это хорошо но требует доработки.
На RST мы не увидели ничего если измеряли цифровым мультиметром - импульс достаточно короткий цифровой прибор может не успевать отработать.  Поэтому пока делать вывод формируется на нем сброс или нет не можем (пока не посмотрим осцилографом).
Далее делаем небольшую доработку схемы:
(UART) DTR -----||-----Reset (Sportiduino)
^ Конденсатор 0.1мк
Таким образом формируем короткий импульс сброса МК во время начала программирования.
Пробуем прошивать.
Если не получилось повторяем с инверсией RX-TX
Если не получается то дальше мои предложения будут пробовать мой оптибут под скорость 38к.
А можно ссылку на файлик который прошиваете через SPI первый раз ?

—You are receiving this because you authored the thread.Reply to this email directly, view it on GitHub, or mute the thread.

-- С уважением,Ефим Долгов,Оренбург,

sembruk, 2020-01-15:
> Библиотека не может быть запущена, потому что пробелы в названии не допускаются
> нужно к, примеру так: Non-blocking_i2c

Исправлено в v2.6.2

Closed 2020-01-15.

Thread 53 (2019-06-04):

Версионирование

askn80, 2019-06-04:
Добрый день!
Прошу помощи:
11 апреля качал здесь gerber-файлы для станций отметки, сейчас по ним изготовлены платы - архив файлов и фото см. по адресу https://cloud.mail.ru/public/3gr6/3nRrjCe8S
В самом архиве gerber-файлы датированы 9 января 2019 года.
Сейчас здесь не могу найти уже ни этих файлов, ни того, что было с ними связано.
А для сборки нужны схема и pcb.

mars2860, 2019-06-04:
Всё на [месте](https://github.com/alexandervolikov/sportiduino/tree/master/Base%20station/hardware/prod)
Также почитайте [тему](https://github.com/alexandervolikov/sportiduino/issues/51)

askn80, 2019-06-04:
Не похоже что на месте - изготовленные платы по моей ссылке и выложенный там pcb (https://github.com/alexandervolikov/sportiduino/blob/master/Base%20station/hardware/prod/old/PCB.JPG) визуально отличаются

alexandervolikov, 2019-06-04:
Вы смотрите в папке old, нужно смотреть в корневом каталоге:
https://github.com/alexandervolikov/sportiduino/blob/master/Base%20station/hardware/prod/sportiduino-base-assembly.jpg
https://github.com/alexandervolikov/sportiduino/blob/master/Base%20station/hardware/prod/sportiduino-base-scheme.jpg

askn80, 2019-06-05:
Спасибо за информацию, яснее.
Следующий вопрос:
как следует из обсуждения https://github.com/alexandervolikov/sportiduino/issues/51 на сегодняшний день актуальной инструкции по сборке нет, поэтому отталкиваюсь от старой - https://github.com/alexandervolikov/sportiduino/blob/master/Doc/ru/BaseStationAssembly.md
В этой старой инструкции указано, что:
а) спайку изготовленного блока с RFID-модулем следует выполнять ПОСЛЕ прошивки блока
б) а на самом RFID-модуле перед спайкой
> "необходимо выламать/выпаять светодиод и подтягивающий резистор к линии RST, иначе всё это будет сильно потреблять ток во время работы устройства. Также нужно заменить индуктивности L1 и L2 на аналогичные 2.2 мкГн но с большим рабочим током для увеличения мощности антены, например Murata LQH32MN2R2K (Спасибо за совет Александру Якимову)"

Актуальны ли эти рекомендации сейчас - для указанной мной версии станции отметки (под чипы Mifare 1K)?
Допустимо ли будет перепрошивать уже собранные станции (после спайки с RFID-модулем)?

alexandervolikov, 2019-06-05:
Если использовать только чипы Mifare, то выламывать и менять индуктивности не нужно.

Прошивать/перепрошивать можно уже собранные станции (после спайки с RFID модулем). Я давал этот совет с той точки зрения, что, если что-то пойдёт не так, проще отлаживать, перепаивать отдельные компоненты.

askn80, 2019-06-06:
Спасибо, следующий вопрос:
В прежней инструкции по сборке станции отметки https://github.com/alexandervolikov/sportiduino/blob/master/Doc/ru/BaseStationAssembly.md указано:

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

В обсуждении https://github.com/alexandervolikov/sportiduino/issues/51 указано лаконично:

> С этой платой работает новая версия прошивки - https://github.com/alexandervolikov/sportiduino/blob/master/Base%20station/firmware/MifareBaseStation/MifareBaseStation.ino.standard.hex. Прошивать её нужно программатором. Никаких бутлоадеров до и после прошивать не надо.

Расшифруйте, пожалуйста, доступнее порядок прошивки (что все-таки изменилось - что из прежней инструкции делать, что не делать).

mars2860, 2019-06-06:
Сделайте как в обсуждении #51 - в станцию отметки залейте программатором прошивку без бутлоадера

mforis, 2019-07-27:
Я так понимаю, что в старые станции новую прошивку нельзя прошить. Так?

mars2860, 2019-07-27:
Можно, только надо в тексте программы заменить #define HW_VERS 2 на #define HW_VERS 1. Скажу, что на старой плате не тестировал. Если вы можете, то испытайте. Также новая прошивка должна одновременно работать как с чипами ntag так и mifare. Если у вас есть чипы ntag, то также просьба потестировать

mforis, 2019-07-27:
Ооо, отлично. Протестирую сегодня или завтра и отпишусь. Прошивать через ARDUINO? И потом будет действовать новая программа SportiduinoPQ?

mforis, 2019-07-27:
Единственное, что у меня чипы mifare, к сожалению, но есть и ntag, могу ими тоже проверить

mars2860, 2019-07-27:
Да, через ардуино

mars2860, 2019-07-27:
И чипами ntag, пожалуйста, проверьте, если есть возможность

mforis, 2019-07-27:
Странно, но в релизе только версия 0.6.0, а 0.7.0 нету в exe. Может сбросите?
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

mars2860, 2019-07-27:
опубликовал, можно скачивать

mforis, 2019-07-27:
Спасибо, но теперь в мастер станции звук не идет

mars2860, 2019-07-27:
Наверное, у вас установлен буззер без генератора. В прошивке найдите строчку

`// the third parameter should be the frequency of your buzzer if you solded the buzzer without a generator else 0
#define beep(ms,n) beep_w(LED,BUZ,0,ms,n)`

И замените её на

`#define beep(ms,n) beep_w(LED,BUZ,3000,ms,n)`

mforis, 2019-07-27:
В общем, не все базы читают чипы после прошивки, наверное, из-за того, что усиление антенны очень большее. И еще базы не видят чипы MIFARE Ultralight, но мастер станция их видит. А вот дату инициализации база очистки не меняет?

mforis, 2019-07-27:
У меня в базах эта прошивка. Может можно как-то в файле прошивки поменять усиление антенны. Сделать его таким же как и в этой.
[MifareBaseStation.zip](https://github.com/alexandervolikov/sportiduino/files/3438527/MifareBaseStation.zip)

mars2860, 2019-07-28:
В базы надо также новую прошивку поставить из репозитория. Усиление антенны тогда через sportiduinopq можно будет менять и чипы ultralight и ntag тогда база будет понимать

mforis, 2019-07-28:
Конечно, я поставил, но говорю, что после установки в некоторых базах чипы вообще не считываются. Можно перед установкой прошивки поменять усиление антенны?

mars2860, 2019-07-29:
Можно. Открываете [Мои документы]\Arduino\sportiduino\sportiduino.h и меняте `#define DEFAULT_ANTENNA_GAIN MAX_ANTENNA_GAIN
` меняете DEFAULT_ANTENNA_GAINT на какой нужно. Также усиление антенны можно через sportiduinopq поменять

mforis, 2019-07-29:
Странно, но не все работают с UART:

> Записываю новый пароль и настройки в базовую станцию по UART
Ошибка: Не совпадает контрольная сумма в ответе <

mforis, 2019-07-29:
И когда прошил она не пикала.

mars2860, 2019-07-29:
Ещё раз прочитайте про прошивку в инструкции по сборке. Там есть обновления. Возможно у вас сейчас не правильно фьюзы выставлены.

mars2860, 2019-07-29:
И если не пикала, то точно также как и для мастер станции надо изменить строчку #define beep(ms,n) beep_w(LED,BUZ,3000,ms,n)

mforis, 2019-07-29:
Она потом пикает, когда отсоединяю UART.

mars2860, 2019-07-29:
Я запутался. Давайте вернемся к усилению антенны и чипам. После изменения усиления антенны, станции по-прежнему не работают с ntag и ultralight?

mforis, 2019-07-29:
Так, смотрите, я прошил две базы со старыми настройками в Arduino IDE (прикладываю скрин)
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, в одной базе только карточки считывались, больше никакие чипы, в другой ничего не считывалось, в одной базе я установил настройки с помощью UART, а во второй выбивает ошибку, там я чипом изменил усиление, в обоих выставил 23 dB и они считывают всё и вроде нормально работают, а вот третья база прошилась, но не запищала, поэтому я не знаю, что сделать. Эта прошивка по моему мнению лучше чем старая, тут на много громче пищит, вот ну единственное поменялся сигнал повторной отметки.
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
mforis, 2019-09-10:
Вообще не хочет загружаться

mforis, 2019-09-10:
Arduino: 1.8.9 (Windows 10), Плата:"Sportiduino"

avrdude: verification error, first mismatch at byte 0x7e00
         0x00 != 0x11
avrdude: verification error; content mismatch
Ошибка при записи загрузчика.

Этот отчёт будет иметь больше информации с
включенной опцией Файл -> Настройки ->
"Показать подробный вывод во время компиляции"

mars2860, 2019-09-11:
Либо atmega умерла либо программатор неправильно подключен

mforis, 2019-10-20:
В общем, разобрался в чем была проблема: был плохой контакт. Загрузчик заливается хорошо, без каких-либо проблем. Но вот при прошивке Arduino IDE зависает на загрузке. Все библиотеки установлены, другие прошивки без проблем заливаются, а эта нет... Может что-то нужно сделать?

mforis, 2019-10-21:
Прошил на старый загрузчик, в общем, всё нормально, но нужно как-то полностью отключить усиление антенны, чтобы оно было как в старых прошивках. Можете изменить это в прошивке и скинуть сюда?

mforis, 2019-10-24:
@mars2860,  можете отключить усиление? Или нет возможности этим заниматься?

mars2860, 2019-10-24:
Откройте файл sportiduino.h и в 9 строчке поставьте самостоятельно усиление антенны по умолчанию какое вам нужно.

`#define DEFAULT_ANTENNA_GAIN  MAX_ANTENNA_GAIN`

mforis, 2019-10-24:
К сожалению, это не помогает. Нужно полностью его отключить. В прошивке 1.4.0 уже был такой баг. И в 1.4.1 полностью отключили усиление.

mforis, 2019-10-25:
@halny123, жалениюсожалению, это не помогает (((

Evgen-F, 2019-11-01:
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

У меня такая же фигня, только замена на выложенный файл boards.txt от mars2860 ничего не дала.

_Arduino: 1.8.10 (Windows 7), Плата:"Sportiduino"

loading hardware from C:\Program Files\Arduino\hardware: loading package arduino: loading platform release: Error reading file (C:\Program Files\Arduino\hardware\arduino\avr\boards.txt:0): Invalid line format, should be 'key=value'

Ошибка компиляции для платы Sportiduino._

Прилагаю файл C:\Program Files\Arduino\hardware\arduino\avr\boards.txt и скрин с ошибкой. Сможете подсказать, что не так?
image.png

mars2860, 2019-11-01:
Выкладывайте свой файл boards.txt прямо из папки C:\Program Files\Arduino\hardware\arduino\avr\

Evgen-F, 2019-11-01:
> Выкладывайте свой файл boards.txt прямо из папки C:\Program Files\Arduino\hardware\arduino\avr\
Так это он и есть. Я не знаю как его выложить непосредственно на Github, без файлхостинга

mars2860, 2019-11-01:
Причина вашей проблемы точная такая же как и у mforis. И файл, то что вы выложили не соответствует тому файлу, что выкладывал я в посте.
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

Значит вы как-то неправильно заменили файл boards.txt на тот, что я выкладывал. Есть два варианта решений. Первый - скачайте нормальный текстовый редактор Notepad++. Создайте в Notepad++ новый чистый boards.txt и скопируйте в него содержимое старого boards.txt. Либо скачайте снова тот файл boards.txt, который я выкладывал и замените им свой файл boards.txt

mforis, 2019-11-01:
@mars2860, а по поводу полного отключения усиления сподвижек нет?

Evgen-F, 2019-11-01:
@mars2860, скомпилилось. Походу я по ошибке не ваш файл скачал, а @mforis, поэтому он и не заработал. Не туда тыкнул походу, когда скачивал, сори.

mars2860, 2019-11-01:
>
>
> @mars2860, а по поводу полного отключения усиления сподвижек нет?

Могу предположить, что для изменения усиления антенны вы редактируете не тот файл sportiduino.h. После того как вы установили sportiduino библиотеку для изменения усиления антенны по умолчанию надо перейти в папку C:\Users\user\Documents\Arduino\libraries\sportiduino. Открыть там sportiduino.h и заменить
`#define DEFAULT_ANTENNA_GAIN  MAX_ANTENNA_GAIN`
на (что соответствует усилению 18 dB)
`#define DEFAULT_ANTENNA_GAIN  MIN_ANTENNA_GAIN`
или среднее значение (что соответствует усилению 33 dB)
`#define DEFAULT_ANTENNA_GAIN  4<<4`

Чтобы параметр antennaGain вообще никак не влиял на систему, надо в той же папке открыть sportiduino.cpp и закомментировать строки 112,113,114
`mfrc522.PCD_AntennaOff();`
`mfrc522.PCD_SetAntennaGain(antennaGain);`
`mfrc522.PCD_AntennaOn();`
Тогда модуль RC522 всегда будет работать с усилением по умолчанию 33dB согласно даташиту. Повторюсь, что надо редактировать файлы в папке C:\Users\user\Documents\Arduino\libraries\sportiduino а не в папке проекта.

mforis, 2019-11-02:
Огромное спасибо! Отключил параметр antennaGain и всё начало прекрасно работать. Единственное, а на что влияет усиление? И почему отключили сигнал при пробуждении?

mars2860, 2019-11-03:
1. Теоретически усиление должно влиять на дальность срабатывания чипа.
2. Так вроде и не было раньше сигнала при переходе из режима сна в активный режим

Closed 2022-01-28.

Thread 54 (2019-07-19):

Медленная работа станций

SergeyZaboev, 2019-07-19:
Здравствуйте!

Столкнулся с тем, что купив комплект запчастей, собрал вторую партию из 10 базовых станций отметки (Mifare, ver. 105), прошил их прошивкой что и в первой партии (всё работает исправно, организую спортивный лабиринт постоянно), а вновь собранные станции работают, будто наелись каши-тормозянки. Станции читают мастер-чипы очень медленно, но исправно, ставят отметку исправно, но капец как долго. Издают очень протяжённый сигнал диодом и звуковой также.

Проверил все smd-элементы - разложены в соответствии со схемой сборки.

Я не разбираюсь в тонкостях, но у меня на новых станция одно отличие: маркировка пьезоизлучателя HC0903A D8J, а в предыдущих HC0903A D6G. Остальные smd-компоненты из прошлой партии.

mars2860, 2019-07-19:
Сейчас готовится новая версия прошивки, до 31.07.2019 собираюсь выложить апдейт

mars2860, 2019-07-27:
Доступна новая версия прошивки. Также обновилась инструкция по сборке станции. Прочитайте ещё раз про процесс заливки прошивки. Скорее всего у вас сейчас проблема из-за неверно выставленных фьюзов.

Closed 2022-01-28.

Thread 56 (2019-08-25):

Проблема с мастер станцией.

Turaev58, 2019-08-25:
Здравствуйте!
Мастер станция с прошивкой 1,6 при подключении к SportOrg начинает постоянно мигать и сигналить. В чем причина?

mars2860, 2019-08-26:
Это баг. Исправил проблему в прошивке мастер-станции. Обновитесь.

Turaev58, 2019-08-26:
Спасибо! Все работает.

Closed 2019-09-09.

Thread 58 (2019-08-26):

SportiduinoPQ

Turaev58, 2019-08-26:
Здравствуйте!
Ноутбук 10", не помещается нижняя часть "Настройки#1" и "Настройки#2". Не могу настроить Мастер-чип "Сон" и настройка по UART. Возможно ли прикрутить ползунок сбоку для прокрутки?
Спасибо.

mars2860, 2019-08-28:
Прикрутил

Turaev58, 2019-08-30:
Спасибо!

Closed 2019-09-09.

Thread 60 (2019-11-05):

Проблема с программированием времени и даты включения на станциях первой версии

Phylosof, 2019-11-05:
Залил новую прошивку на станции версии 1. В целом все работает нормально, кроме программирования времени пробуждения станции. Например:
- если задать время и дату 17.01.2020 2:40, на самом деле в станцию пишется будильник на 31.12. 2019 2:40
- если задать время и дату 30.12.2019 00:00 на самом деле в станцию пишется будильник на 30.11.2019 02:00.

mars2860, 2019-11-06:
Все станции работают по времени UTC. При установке времени, местное время конвертируется во время UTC. Отметка на чип записывается в формате UTC, а при чтении на стороне PC конвертируется в местное время

Phylosof, 2019-11-06:
Но ведь время UTC отличает от местного на 2 часа, Почему тогда разница в 2 недели, а то и в месяц?

mars2860, 2019-11-08:
Не получается у меня воспроизвести подобную ошибку на плате v2, платы v1 нет. На плате v2 всё нормально работает. По теории и на плате v1 тоже должно работать, потому что код записи, хранения и чтения времени будильника одинаковый как для платы v1 так и для платы v2. Как вы смотрите время будильника, записанное в станцию отметки - через SportiduinoPQ и чип чтения состояния?

Phylosof, 2019-11-08:
Да, смотрю через чип состояния. При этом текущее время станции показывает правильно.

mars2860, 2019-11-08:
Возможно проблема из-за библиотеки DS3231. Попробуйте скачать из репозитория библиотеку [DS3231](https://github.com/alexandervolikov/sportiduino/tree/master/Libraries/ds3231-master) и замените этими файлы ваши файлы в папке C:\Users\User\Documents\Arduino\libraries\DS3231. Затем перекомпелируйте проект и обновите прошивку на станции

Phylosof, 2019-11-11:
Проблема не в библиотеке. Я изначально именно эту библиотеку использую.

Closed 2019-12-08.

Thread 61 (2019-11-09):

Прошивка 2.6.1 - Возросшее потребление в MODE_SLEEP

halny123, 2019-11-09:
Решил перейти с прошивки 1.4.0 на последнюю. Заметил неприятную особенность.
В последней прошивке 2.6.1 потребление станций в SLEEP MODE на порядок выше .
Старая прошивка <0.020mA
Новая прошивка ~0.300mA

Плюс не происходит очистка мастер-чипов после отработки команды. Что может привести к плачевным последствиям, если какой то мастер-чип попадет на дистанцию.

mforis, 2019-11-09:
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
Да, да так и есть. Потребление возрасло...

mars2860, 2019-11-10:
Понятно. По потреблению пока ничего не могу подсказать, потому что у меня нет платы v1. Постараюсь изготовить и решить проблему.

mforis, 2019-11-10:
@mars2860, а это может быть из-за загрузчика? Я бы обновил загрузчик, но в него не хочет заливаться прошивка.

halny123, 2019-11-10:
Думаю дело не в версии платы.  И на платах версии 2 должна наблюдаться такая же картина.
В прошлой версии использовалась другая библиотека для перевода в сон. А в коде перед переходом в сон все ножки мк переключались на выход, отключалось АЦП и схема контроля питания.
//Low all pin for power save
  for (uint8_t i = 0; i <= A5; i++)
  {
    pinMode(i, OUTPUT);
    digitalWrite (i, LOW);  //
  }
ADCSRA = 0;
 MCUSR = 0;
В последней прошивке этого явно нет, и при переходе в режим сна - все это работает и потребляет.

mforis, 2019-11-10:
М-да, даже не знаю, что делать. Обновил во всех базах прошивку и вот не знаю, надолго ли хватит батареек...

halny123, 2019-11-10:
при таком потреблении дней 100

mars2860, 2019-11-10:
В начале кода все неиспользуемые ноги настраиваются как INPUT_PULLUP. АЦП только включается и выключается при проверке уровня заряда батареи и на момент перехода в сон он итак выключен. Плата v2 у меня 90 мкА потребляет. Скорее проблема в настройках портов ввода-вывода. Или плата v1 с этой прошивкой совсем не переходит в режим сна из-за этого условия
`if(rtcAlarmFlag || Serial.available() > 0 || serialWakeupFlag)
    return;
`
Чтобы проверить, переходит плата в режим сна или нет, добавьте в начале кода директиву #define DEBUG.

halny123, 2019-11-10:
Сейчас добавив в наглую " костыль " в
 void sleep(uint16_t ms)
-------
 for (uint8_t i = 0; i <= A5; i++)
  {
    pinMode(i, OUTPUT);
    digitalWrite (i, LOW);  //
  }

 pinMode(DS3231_IRQ,INPUT);  // Оставляем вход для срабатывания прерывания от геркона
// disable ADC
  ADCSRA = 0;
 ---------------
имею 20-30мкА потребления без выключения схема контроля питания.
но вижу что это неправильно т.к. не до конца понимаю работу новой прошивки .

halny123, 2019-11-10:
Плата в режим сна переходит, это хорошо видно прибором по потреблению.

mars2860, 2019-11-10:
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

Если помогло, то можно и так оставить. Нельзя только будет прочитать настройки платы по UART, когда она в режиме MODE_SLEEP

mforis, 2019-11-10:
Хорошо, а это не принесет новые баги? И не могли бы сбросить скетч для платы v1 без геркона?

mforis, 2019-11-10:
И вообще стоит ли сейчас прошивать, может лучше дождаться обновления?

halny123, 2019-11-10:
да нет так оставлять нельзя есть баги которые проявляются но объяснить не могу пока. Нужно что то думать. Прошивку пробовать начал только вчера,  Максим а у вас старая прошивка сколько потребляла ?

mforis, 2019-11-10:
В режиме сна 75-120 мкА

halny123, 2019-11-10:
ого (.
Ребята  может создать в телеграмме канал для быстрого общения ?

mforis, 2019-11-10:
Да, кстати, можно. Плюс, я сейчас прошью одну базу на старую прошивку и замерю еще раз, для большей уверенности.

halny123, 2019-11-10:
Вот попробовал в телеграмме канал Sportiduino. Кому интересно попробуйте зайти.

mforis, 2019-11-10:
Я подписался, только пока писать ничего не могу...

halny123, 2019-11-10:
в телеграме выложил видео потребления с двумя прошивками стандартной - 320мкА  , и без АЦП - ~40мкА

mforis, 2019-11-15:
@mars2860 , ну что никаких сподвижек нету? Если нужно, я могу прошивку на своих базах тестировать.

mars2860, 2019-11-15:
Пока этим не занимался. Мне лучше, чтобы плата была под рукой. Постараюсь изготовить ее поскорее

mforis, 2019-11-15:
Ясно, буду ждать...

halny123, 2019-11-16:
Пока такие результаты борьбы с потреблением
Стандартная прошивка - 0,26мА
По аналогии с функцией sleep прошивки 1.6.0
Если перевести перед засыпанием порты на выход и установить 0
потребление падает до 0,12мА

```
 //Low all pin for power save
 for (uint8_t i = 0; i <= A5; i++)
 {
  pinMode(i, OUTPUT);
   digitalWrite (i, LOW);  //
 }
```
если дополнительно выключать АЦП
потребление падает до 0.03mA
```
 // disable ADC
  ADCSRA = 0;
```

отключение системы контроля питания выигрыша не дает (или я не могу замерить <10mkA)

mars2860, 2019-11-16:
Принято. Протестирую ещё с платой версии 2 и добавлю после этого в репозиторий

halny123, 2019-11-17:
Тут на выходных с Максимом потестировали и нашли еще одну неприятность связанную с первой схемой, у меня питание часов немного по другому организованно поэтому проблему не заметил сразу.
Значит по переводу портов в 0. Выяснилось, что все можно и не переводить основное потребление было связано с PD5 через который дополнительно подавалось питание на DS3231. Они и потребляли дополнительно 140мкА. Но после пробуждения 5 порт нужно возвращать в "1", т.к. к нему привязана подтяжка шин SDA SCL.

Сейчас ложим порты с 2 (чтобы оставить возможность конфигурировать станции по UART ) по А5 в ноль и отключаем АЦП - потребление 0,02-0,03мА. После просыпания PD5 возвращаем в 1. Это все для 1 версии платы.

 Где то еще болтаются лишних 10-20мкА (по сравнению со старой прошивкой), но пока больше нет времени искать.  Чтобы отключать brown-out detector нужно немного править используемую библиотеку Adafruit_SleepyDog_Library - но я по крайней мере своим прибором снижения потребления при этом не заметил.
Вечером Максим протестирует на большем количестве плат и режимах и отпишется

halny123, 2019-11-17:
А можно как то лишние посты убрать оставив суть ?

mforis, 2019-11-17:
В общем, протестил, всё работает активный режим, режим ожидания, режим сна. В режиме сна потребление 0.02 мА, но в старой прошивке потребление было 7-10 мкА. Из сна выходят нормально, но как-то долговато, может кажется. Единственное, что смутила одна база потребляет в режиме сна 0.13 мА, возможно проблема в компонентах. Завтра обновлю прошивку во всех базах и тогда уже будет полностью видно, есть ли проблемы.

mars2860, 2019-11-22:
У меня получилось на плате v2 добиться вот такого результата в 6 мкА.
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

Но при этом пришлось отпаять ножки VBAT и VCC у DS3231 и сделать VBAT = 3V3, VCC = 0. Часы работают. Если сделать VCC = 3V3, VBAT = 0, то потребление становится 90 мкА. Обидно, кажется в плате v2 я накосячил с расключением питания DS3231, в плате v1 было по-другому. Перелистал весь даташит DS3231 в поисках ответа чем отличатся режим питания по VCC от режима питания по VBAT, что работает дополнительно в VCC и что не работает в VBAT и почему в VCC оно при этом потребляет больше чем в VBAT? Вроде логика, схема термокомпенсации, I2C работают как в VBAT так и в VCC, но почему при этом VCC потребляет больше - не понятно. Ответа в даташите не нашёл

mforis, 2019-11-22:
@mars2860, А без отпайки ножек DS3231 на новой прошивке, вторая версииюя платы сколько потребляет?

halny123, 2019-11-23:
Ребята если хотите переделать плату v2 прошу немного подождать. Сейчас тестирую схему измерения напряжения на батарейках . деталей 2 резистора 1-2 диода и конденсатор, потребление во сне 0 - при 3.3в,  3-5мкА - 5В. Но можно свести и к 0. Если посчитаете актуальным можно будет внести в схему. А то надоело быть в неведении.

mars2860, 2019-11-23:
>
>
> @mars2860, А без отпайки ножек DS3231 на новой прошивке, вторая версия платы сколько потребляет? А то я сейчас 10 баз новой версии буду собирать.
88-90 мкА. У меня год станции пролежали и батарейки разрядились в некоторых

sembruk, 2019-12-11:
Протестировал на плате v1. Если переводить ноги перед засыванием в INPUT_PULLUP, потребление в режиме сна 130 мкА (c47822e). Если переводить в OUTPUT-LOW — 11 мкА (9ade4bb).

Closed 2020-04-02.

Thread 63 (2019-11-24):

Предложение по измерению напряжения на батарее

halny123, 2019-11-24:
Как обещал, результаты экспериментов с измерением напряжения на батарее.
Схема
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

Как проводились теоретически расчеты
[vccl.xlsx](https://github.com/alexandervolikov/sportiduino/files/3883342/vccl.xlsx)
Результаты - теория и практика при одном диоде (при двух - паразитный ток отсутствует во всем диапазоне возможных входных напряжений от4,8В)
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
При питании 5,1В паразитный ток через вход АЦП на практике составил 8мкА (при одном диоде с падением на нем 0,45В)

Скетч
переменные

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

Функция

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

halny123, 2019-11-24:
Просьба в помощи то что я не в состоянии буду сделать.
Изменить программу конфигурации SportiduinoPQ
1. Внести возможность при замене батареи сохранять дату замены.
2. Внести возможность вводить и передавать реальное напряжение на батарее для вычисления корректировочного коэффициента.
3. При считывании мастер чипа состояния - выводить показания батареи без и с нагрузкой.

То что смогу сделать в прошивке и как для себя вижу реализацию

4. Замерять напряжение при каждом задействии бузера - и при просадке ниже 3,8В переводить станцию в режим отметки без звукового сигнала и выставлять флаг о необходимости замены батареи. (Это на любителя - но у себя в прошивке я это точно сделаю т.к. это позволит более-менее гарантированно завершить нормально соревнования если батарея начнет садится в лесу)
5. При выставленном флаге о необходимости замены батареи - при использовании любого мастер чипа - трезвонить "хоть бесконечно" о необходимости ее замены.

Где то так.
Что думаете ?

mars2860, 2019-11-24:
Мне нравится. Могу расширить SportiduinoPQ под данный функционал. И всё другое, что потребуется

mforis, 2019-11-24:
Было бы очень круто)))

mforis, 2019-11-24:
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
Я тут уже маленькую платку сделал, чтобы добавить данную функцию в старые станции.

mars2860, 2019-11-26:
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

1. Исправил схему подключения питания для DS3231
2. Добавил схему halny123 для измерения напряжения на батарее
3. Добавил фильтр на ножку RESET, а то при подключении UART переходника станция перезагружается

Просьба проверить и написать замечания

mforis, 2019-11-26:
@mars2860 , а что там с программой Sportiduino PQ?

halny123, 2019-11-26:
R1\R3 наверное можно посадить на +3.3V, а Vcc часов на землю. Все равно он большую часть времени там и находится для уменьшения потребления. + Не нужно будет дергать лишний раз при просыпании ногу.
И предложение - когда будете новую печатку делать предусмотреть отводы хотя бы от некоторых неиспользуемых пинов МК и закончить их переходным отверстием. Тогда в случае доработок легче будет подключаться.

halny123, 2019-11-26:
Антон проверь если есть возможность падение на диодах при малых токах порядка 10мкА. Как в делителе. Последний раз я пробовал делитель 270к\68к падение на диодах было порядка 0,4В , ставил что под руку попалось - 2n4148. Интересно на сколько стабильно будет это падение при малых токах. Может вообще их выбросить пожертвовав ~2мкА потребления.
Критично при измерении было выдержать время после переключения в режим измерения не менее 25мс, иначе первое измерение идет с большой ошибкой, пока порты переключались.

mars2860, 2019-11-26:
Думаю диоды не стоит выбрасывать и на печатной плате сделать под них посадочные места. Тогда если с диодами будет плохо, то вместо них можно будет просто впаивать перемычки. Также по питания DS3231 добавил перемычек для выбора питания шины I2C от 3.3В или порта МК, также перемычка для выбора питания DS3231 от порта МК или без питания VCC. Также решил объединить разъём для программатора и разъём для UART в один разъём. А то когда 2 разъёма, то можно запутаться куда подсоединять UART переходник, а куда программатор. С одним разъёмом проще будет понять, просто разные жгуты будут для программатора и переходника UART. В итоге получается такая схема. Печатка по габаритам будет как версия 1. Если есть ещё предложения и замечания, то говорите.

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

halny123, 2019-11-27:
Вроде все так.

mforis, 2019-12-01:
@mars2860, Антон, может всё-таки подскажите когда планируется обновление Sportiduino PQ, а то хочется узнать прошивать базы на новую прошивку или нет

mars2860, 2019-12-02:
>
>
> @mars2860, Антон, может всё-таки подскажите когда планируется обновление Sportiduino PQ, а то хочется узнать прошивать базы на новую прошивку или нет

Наверное, ближе к НГ или в период праздников, когда будет свободное время.

mforis, 2019-12-05:
@mars2860, а можете скинуть схему в электронном виде? Желательно целым проектом...

mars2860, 2019-12-05:
>
>
> @mars2860, а можете скинуть схему в электронном виде? Желательно целым проектом...

Залил в репозиторий. Смотрите ветку develop. Печатную плату тоже уже поправил.

mforis, 2019-12-05:
@mars2860, а что поменяли в прошивке? И будет ли работать новая прошивка на плате версии 3?

mars2860, 2019-12-05:
Пока не будет. Работа ещё в процессе. В 3 версии пришлось поменять некоторые пины для удобства разводки ПП. В прошивку данные изменения ещё не внес.

mforis, 2019-12-05:
@mars2860, Хорошо, а какие изменения? Стоит ли обновлять прошивку перед проведением соревнований?

mars2860, 2019-12-05:
Изменения касаются энергосбережения в режиме сна, то что здесь обсуждали. Обновлять не стоит, так как плохо протестировано.

halny123, 2019-12-06:
Антон, по поводу печатки новой. Вы сделали размер полностью под корпус и залили все сплошной землей. Это очень негативно скажется на дальности обнаружения меток вплоть до 0, т.к. будет экранировать поле катушки.
В самой первой версии я на такие грабли наткнулся.

halny123, 2019-12-06:
Я заказал уже платки, размер полностью под корпус (мне так удобно), но можно и уменьшить в два раза, если после тестирования все будет нормально выложу у себя может кому пригодится.
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

mars2860, 2019-12-06:
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

Спасибо! Убрал области металлизации

mars2860, 2019-12-06:
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

Хорошее расположение компонентов. Действительно надо идти в ширину, а не длину, чтобы под антенной не было компонентов и проводников. Единственное, только номер версии указать не 2.6.1, а как-нибудь sportiduino hardware v3a, чтобы не возникла путаница. Первая цифра порядковый номер желаза, вторая порядковый номер прошивки. И как будет подключаться программатор?

halny123, 2019-12-06:
Программатором после запайки всего кроме RFID,  сажусь на контакты RFID - это однократная операция, далее все шью через UART.
Плату для себя делал, версию ставил равную версии прошивке на момент разработки. Для меня не принципиально. Есть партия первой версии - это будет вторая. Для нашего клуба 50 станций будет более чем достаточно - запутаться будет тяжело.
В этой версии пришлось на низ вынести немного компонентов
https://easyeda.com/burenko/sportiduino_v2-6-1 - вот то что сейчас получается.

Антон, вопрос хоть и не по теме - в новой прошивке переработали процедуру очистки чипа ?
А то на старой прошивке очистка идет 5-7с (NTAG215) , а на новой 1-2с. Заметив это сильно удивился но не посмотрел что происходит при очистке в новой прошивке.

mars2860, 2019-12-06:
По сравнению с версией 1.4 - да. По сравнению с версией 2.6.0 - нет.

Closed 2020-04-02.

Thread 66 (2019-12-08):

Optiboot не хочет заливать прошивку

sembruk, 2019-12-08:
Проблема на этапе заливки прошивки через USB-UART. Проявляется всех трёх платак, которые спаял.
Первый байт от avrdude проходит. Второй только иногда.
Пробовал разные Optiboot-ы: и hex из этого репозитория, самосборный из мастера, и v8.0
USB-UART на чипе CP2102.
Плата v1 собственной разводки. Наверное, дело в ней.
Может кто сталкивался с похожей проблемой?

sembruk, 2019-12-08:
```
/opt/arduino-1.8.10/hardware/tools/avr/bin/avrdude -C/opt/arduino-1.8.10/hardware/tools/avr/etc/avrdude.conf -patmega328p -carduino -P/dev/ttyUSB0 -b115200 -D -Uflash:w:/tmp/arduino_build_613570/BaseStation.ino.hex:i -v -v -v -v
<…>
avrdude: Send: 0 [30]   [20]
avrdude: Send: 0 [30]   [20]
avrdude: Send: 0 [30]   [20]
avrdude: ser_recv(): programmer is not responding
avrdude: stk500_recv(): programmer is not responding
avrdude: stk500_getsync() attempt 1 of 10: not in sync: resp=0x00
avrdude: Send: 0 [30]   [20]
avrdude: ser_recv(): programmer is not responding
avrdude: stk500_recv(): programmer is not responding
avrdude: stk500_getsync() attempt 2 of 10: not in sync: resp=0x00
avrdude: Send: 0 [30]   [20]
avrdude: ser_recv(): programmer is not responding
avrdude: stk500_recv(): programmer is not responding
avrdude: stk500_getsync() attempt 3 of 10: not in sync: resp=0x00
avrdude: Send: 0 [30]   [20]
avrdude: Recv: . [14]
avrdude: Recv: . [10]
<…>
avrdude: Send: A [41] . [80]   [20]
avrdude: ser_recv(): programmer is not responding
avrdude: stk500_recv(): programmer is not responding
avrdude: Send: A [41] . [81]   [20]
avrdude: ser_recv(): programmer is not responding
avrdude: stk500_recv(): programmer is not responding
avrdude: Send: A [41] . [82]   [20]
avrdude: ser_recv(): programmer is not responding
avrdude: stk500_recv(): programmer is not responding
avrdude: Send: A [41] . [98]   [20]
avrdude: ser_recv(): programmer is not responding
avrdude: stk500_recv(): programmer is not responding
<…>
avrdude: Send: A [41] . [84]   [20]
avrdude: ser_recv(): programmer is not responding
avrdude: stk500_recv(): programmer is not responding
avrdude: Send: A [41] . [85]   [20]
avrdude: ser_recv(): programmer is not responding
avrdude: stk500_recv(): programmer is not responding
avrdude: Send: A [41] . [86]   [20]
avrdude: ser_recv(): programmer is not responding
avrdude: stk500_recv(): programmer is not responding
avrdude: Send: A [41] . [87]   [20]
avrdude: ser_recv(): programmer is not responding
avrdude: stk500_recv(): programmer is not responding
avrdude: Send: A [41] . [89]   [20]
avrdude: ser_recv(): programmer is not responding
avrdude: stk500_recv(): programmer is not responding
<…>
avrdude: Send: A [41] . [81]   [20]
avrdude: ser_recv(): programmer is not responding
avrdude: stk500_recv(): programmer is not responding
avrdude: Send: A [41] . [82]   [20]
avrdude: ser_recv(): programmer is not responding
avrdude: stk500_recv(): programmer is not responding
avrdude: Send: B [42] . [86] . [00] . [00] . [01] . [01] . [01] . [01] . [03] . [ff] . [ff] . [ff] . [ff] . [00] . [80] . [04] . [00] . [00] . [00] . [80] . [00]   [20]
avrdude: ser_recv(): programmer is not responding
avrdude: stk500_recv(): programmer is not responding
avrdude: initialization failed, rc=-1
         Double check connections and try again, or use -F to override
         this check.

avrdude: Send: Q [51]   [20]
avrdude: Recv: . [14]
avrdude: Recv: . [10]
```

mars2860, 2019-12-08:
А конденсатор последовательный между DTR сигналом USB-UART и ножкой RST микроконтроллера есть?

mforis, 2019-12-08:
@mars2860 , у меня так-же после обновления на загрузчик, который в репозитории. Хотя конденсатор есть... И на старом загрузчике без проблем шьётся. Кстати, чем отличается загрузчик от обычного optiboot?

halny123, 2019-12-08:
Если не шьется никак то смотреть формирование сигнала сброса как написал Антон.
Если нестабильно шьется - я описал у себя как поборол. https://github.com/halny123/sportiduino/tree/master/NRFstation - в самом низу пункт ПО ПРОШИВКЕ OPTIBOOT :

halny123, 2019-12-08:
Если будут вопросы - в телеграмме есть группа https://t.me/Sportiduino , где смогу более менее быстро ответить.

sembruk, 2019-12-08:
О! Спасибо за ответы! Оперативно.
@mars2860 , конденсатор есть, но пользоваться выходом DTR перестал пока. Так как на МК только загрузчик. Собрал Optiboot c индикацией на светодиод (D4). Вижу что, загрузчик перезагружает МК каждую секунду, как и надо.
Залил на плату скетч SerialEvent через программатор. Да, проблема в получении последовательности байтов на МК, если они идут по шине подряд.
Но осциллограф говорит, что всё хорошо.
Может не хватает бита чётности?

sembruk, 2019-12-08:
> Если не шьется никак то смотреть формирование сигнала сброса как написал Антон.
> Если нестабильно шьется - я описал у себя как поборол. https://github.com/halny123/sportiduino/tree/master/NRFstation - в самом низу пункт ПО ПРОШИВКЕ OPTIBOOT :

@halny123 , прошивка заливается! Спасибо огромное! Надо будет эти загрузчики добавить в этот репозиторий.

sembruk, 2019-12-08:
Закрою issue завтра pull request-ом.

Closed 2019-12-09.

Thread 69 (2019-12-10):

Версия платы с внешней памятью

sembruk, 2019-12-10:
Планирую в ближайшее время развести плату v3 с посадочным местом под чип 24LC256.
Ветка ext-eeprom.

mars2860, 2019-12-10:
Насколько понимаю внешняя EEPROM будет использоваться под журнал отметок или есть ещё какие идеи?

sembruk, 2019-12-10:
Да, для этого.

sembruk, 2019-12-10:
Добавил память в схему и переделал подключение разъёма программирования
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

mars2860, 2019-12-11:
Вроде всё норм. Версию можно просто 3 без m, всё равно прошлая схема ещё не вошла в релиз. Тогда эту схему добавим в новый релиз и она будет 3-й версией. И может ещё стоит подумать и как-то привести к общему знаменателю идею Виталия (@halny123) с радиомодулем и текущую схему и создать один официальный релиз. Возможно, вместо NRF радиомодуля использовать bluetooth модуль HC-08. Золотой Маршрут выбрал в качестве отметки систему "Фрактал", там вроде bluetooth. На будущее возможно можно будет сделать совместимость с этой системой. Кто что думает?

sembruk, 2019-12-11:
В Телеграм-чате Максим предложил хорошую идею: пробуждать станцию по геркону. Можно пробуждать по геркону и чипу.
При этом не нужно каждые 25 секунд включать RFID модуль и в режиме сна можно существенно понизить потребление.

sembruk, 2019-12-11:
Я считаю, что совместимость с Фракталом не нужна. По крайней мере пока.

mars2860, 2019-12-11:
Можно сделать так. В схему добавить геркон как у Виталия. На разъёме программирования X2 выкинуть VBAT и вместо него подключить какой-либо порт МК, например, PB0 или PD7 - это будет Chip Select для другого устройства SPI. По желанию, пользователь пусть хочет ставит NRF или Bluetooth или вообще ничего. Радиомодуль будет ставиться дополнительно с торца корпуса и подключаться к разъёму программирования, ведь этот разъём всё равно пустует, когда корпус закрыт. Надо тебе обновить прошивку - открутил крышку, вытащил радиомодуль из разъёма программирования, перепрошил, поставил радиомодуль обратно. Или даже для пользователей с радиомодулем бутлоадер сделать для бесконтактного обновления прошивки. Идей много. И сейчас для этого в принципе надо только геркон добавить и вместо VBAT какой-нибудь порт.

mforis, 2019-12-11:
Семён прав, ни вижу особого смысла использовать радиомодули, так как возастет потребление. Да и вообще не вижу смысла склеивать две системы. А вот геркон вещь хорошая. А по поводу NRF его можно использовать для реализации бесконтактной отметки, то есть сделать активный чип, как вариант, хотя это достаточно дорого + увеличивает потребление

halny123, 2019-12-11:
Ребята может в чат перелезем по обсуждению ? Я могу рассказать что есть у меня сейчас чем доволен чем нет . А сюда уже выложить выжимки из обсуждений. А то в проблемах будет много мусора.
Кратко:
- Герконом доволен полностью не жалею что сделал. Просыпаюсь мгновенно. Если нужно можно сделать засыпание.
- Радиомодуль - как таковой оказался не востребован, побаловался и все. для настройки все же быстрее чипами оказалось. Была задумка использовать для перепрошивки, optiboot позволяет OTA прошивку делать. Но это настолько редко, что легче открутить крышку и нормально перешить. Поэтому отказался от него.
- Внешняя память - не увидел необходимости вообще. Критично только наличие номера чипа - время не критично. Если уж нужно примерно знать время отметки - можно вычислить по соседним чипам. (Отказался)
- Сейчас задумка отказаться от чипов для программирования за счет использования на мастер станции модуля PN532 - который должен поддерживать режим эмуляции чипа. Но пока детали в пути сказать работает или нет задумка не могу. Тогда необходимость в радиомодуле отпадет вообще.
Это все только мое мнение у других требования к отметке могут быть иные.

halny123, 2019-12-11:
> Можно сделать так. В схему добавить геркон как у Виталия. На разъёме программирования X2 выкинуть VBAT
Я бы предложил выбросить Vcc а питание заводить все таки на VBAT.
Не дай бог кто то воткнет что то больше 3.3В. Пусть лучше сгорит стабилизатор чем что то еще.

sembruk, 2019-12-11:
Ещё хочу убрать фильтр с линии Reset Атмеги. Так как сигнал с DTR идёт через конденсатор, то имульс получается очень коротким. Будет ли с фильтром работать обновление прошивки?

mars2860, 2019-12-11:
>
>
> Ещё хочу убрать фильтр с линии Reset Атмеги. Так как сигнал с DTR идёт через конденсатор, то имульс получается очень коротким. Будет ли с фильтром работать обновление прошивки?

Ещё не проверял как эта цепь будет работать, но всё же выбрасывать думаю не стоит. Если это будет мешать программированию, то можно просто не распаивать этот фильтр.

sembruk, 2019-12-12:
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

mars2860, 2019-12-12:
PC3 зарезервирована под управление питанием DS3231. Здесь я уже сделал ошибку, когда VCC была жестко к 3v3. Сейчас мы хотим попробовать VCC=0, R1,R3 = 3V3, но неизвестно пока какое будет потребление, поэтому мной были добавлены печатные джамперы, которые позволяют вернуться к проверенному решению из версии 1. Лучше PB6 или PB7 задействовать. Кварцы ставить точно не будем.

sembruk, 2020-01-16:
> Ещё не проверял как эта цепь будет работать, но всё же выбрасывать думаю не стоит. Если это будет мешать программированию, то можно просто не распаивать этот фильтр.

Да, с LC фильтром на RST не обновляется прошивка. Думаю, всё-таки его убрать с платы. А для предотвращения перезагрузки станции при поключении USB-UART можно физически отключать DTR.

Closed 2020-04-02.

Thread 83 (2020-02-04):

Config by UART

arashipl, 2020-02-04:
I am trying to put together a set of control station on my own PCB's customized to fit cases I used for a different project and use a 16350 Li-Ion cells I have instead of 3x R6 as an option.
I mixed up a different versions of schematics, so my design is slightly different and I faced quite a few complications, but it seems all is on a good way, thanks to Google Translate I found halny123's test app, which helped me diagnose my stations. So I've arrived to the point where I want to configure and prepare stations to be used and I tried to config stations via uart as a part of programming procedure (flash bootloader, use UART to test assembly, then upload basestation sketch and then configure station withuout the hassle of using programming via rfid chips.
But no matter what I try I always get "Error: No response from the base station" info in SportiduinoPQ 0.7.1.
Is this a bug or I missed something? I use the same cable for SportiduinoPQ that I use for programming with ArduinoIDE and for TestStationOK debug communication.  - and there are no problems whatsoever.

mars2860, 2020-02-04:
Don't use a cable for programming with ArduinoIDE because it has DTR signal which resets MPU before programming. You need other cable which has just 3 wire (rx,tx,gnd)

arashipl, 2020-02-04:
Thank you for the answer, I just assumed that DTR is left idle when port is configured with no flow control.
Just for the record - I admire amount of work that went into this system and I offer whatever help I may need. SportIduino is getting a foothold in Poland :)

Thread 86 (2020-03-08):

Проверка записи данных на чипы в 3ей версии прошивки

Phylosof, 2020-03-08:
Порылся недавече в библиотеке rfid (для 3ей версии прошивки) и сравнил функцию ntagWrite из первой версии BaseStation.ino с функцией ntagCardPageWrite в rfid.cpp и заметил существенное отличие. В ntagCardPageWrite нет проверки записи на чип путем считывания и сравнения данных из буфера, что существенно снижает надежность отметки. Может стоило бы сохранить сей полезной момент в новой версии?

halny123, 2020-03-09:
Дим ты просил показать где происходит проверка записи отметки, последние 10 строк
функции

bool ntagWrite (uint8_t *dataBlock, uint8_t pageAdr){

const uint8_t sizePageNtag = 4;
status = (MFRC522::StatusCode) mfrc522.MIFARE_Ultralight_Write(pageAdr,
dataBlock, sizePageNtag);
if (status != MFRC522::STATUS_OK) {
return false;
}

uint8_t buffer[18];
uint8_t size = sizeof(buffer);

status = (MFRC522::StatusCode) mfrc522.MIFARE_Read(pageAdr, buffer, &size);
if (status != MFRC522::STATUS_OK) {
return false;
}

for (uint8_t i = 0; i < 4; i++) {
if (dataBlock[i]!=buffer[i]) return false;
}

return true;

вот функция записи на чип все операции в конце верефицируются чтением - это наша
теперешняя прошивка

  08.03.2020, 19:58, Phylosof <notifications@github.com>

  Порылся недавече в библиотеке rfid (для 3ей версии прошивки) и сравнил
  функцию ntagWrite из первой версии BaseStation.ino с функцией
  ntagCardPageWrite в rfid.cpp и заметил существенное отличие. В
  ntagCardPageWrite нет проверки записи на чип путем считывания и сравнения
  данных из буфера, что существенно снижает надежность отметки. Может стоило бы
  сохранить сей полезной момент в новой версии?

  —
  You are receiving this because you are subscribed to this thread.
  Reply to this email directly, view it on GitHub, or unsubscribe.

Phylosof, 2020-03-09:
> Дим ты просил показать где происходит проверка записи отметки, последние 10 строк функции bool ntagWrite (uint8_t *dataBlock, uint8_t pageAdr){ const uint8_t sizePageNtag = 4; status = (MFRC522::StatusCode) mfrc522.MIFARE_Ultralight_Write(pageAdr, dataBlock, sizePageNtag); if (status != MFRC522::STATUS_OK) { return false; } uint8_t buffer[18]; uint8_t size = sizeof(buffer); status = (MFRC522::StatusCode) mfrc522.MIFARE_Read(pageAdr, buffer, &size); if (status != MFRC522::STATUS_OK) { return false; } for (uint8_t i = 0; i < 4; i++) { if (dataBlock[i]!=buffer[i]) return false; } return true; вот функция записи на чип все операции в конце верефицируются чтением - это наша теперешняя прошивка 08.03.2020, 19:58, Phylosof <notifications@github.com> Порылся недавече в библиотеке rfid (для 3ей версии прошивки) и сравнил функцию ntagWrite из первой версии BaseStation.ino с функцией ntagCardPageWrite в rfid.cpp и заметил существенное отличие. В ntagCardPageWrite нет проверки записи на чип путем считывания и сравнения данных из буфера, что существенно снижает надежность отметки. Может стоило бы сохранить сей полезной момент в новой версии? — You are receiving this because you are subscribed to this thread. Reply to this email directly, view it on GitHub, or unsubscribe.

Благодарю, я уже нашел) В том и дело что аналогичная функция в третьей версии не верифицирует запись данных.

sembruk, 2020-03-10:
@mars2860 , эти изменения произошли в версии 2.6? Была ли для этого какая-то особая причина?

mars2860, 2020-03-10:
Да, в версии 2.6 я не стал делать проверку отметки после записи. Дополнительная операция чтения - увеличивает время работы базы с чипом. К тому же посчитал это излишним, так как чип MFRC522 сам отлавливает сбои при чтении/записи и если будет сбой при записи отметки, то MFRC522 об этом сообщит и выкинет в итоге false

Closed 2020-03-18.

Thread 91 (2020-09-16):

Криптозащита отметок в чипе

alexandervolikov, 2020-09-16:
Навеяно обсуждением в чате одного крупного московского соревнования.

Раньше можно было проткнуть карточку иголкой, эмулируя работу компостера, теперь можно записать отметку в чипе с помощью телефона с NFC и навыков программирования.

Защититься от этого можно, считав дампы со станций после проведения соревнования и сравнить с результатами. Но, обычно, станции снимаются позже, выявить подлог можно сильно позже, ну и дополнительные действия для этого нужно делать.

Как решение, можно вставить хэш от времени и пароля станции в отметку, например, SHA-256.
Сейчас структура отметки в 4 байта: 8бит-номер станции, 24бит - остаток от unixtime. 24бита времени позволяют проводить соревнования в течение 194 дней после инициализации чипа, что, может быть, и несколько излишне. Вполне можно уменьшить этот срок в 2-8 раз, высвободив немного памяти для хэша. Например, сделать так:
8бит-номер станции, 2бит - хэш, 22 бит - остаток от unixtime.

Как вам идея?

halny123, 2020-09-16:
Идея замечательная, т.к. проблема рано или поздно все равно встанет.
Перед забегом очистка чипа - хорошая практика, а месяца должно хватить для проведения мероприятия по любому виду соревнований.
Считывающая станция должна проверять корректность хэша и сигнализировать какой нибудь "свирестелью" в случае обнаружения подделки, не возлагая эту задачу на ПО обработки.

sembruk, 2020-09-16:
Идея хорошая. Нужно проверить, сколько времени займёт вычисление хэша в момент отметки. Если будет долго, можно при инициализации станции один раз вычислить хэш от номера и пароля и держать его в оперативной памяти.

alexandervolikov, 2020-09-16:
Проверил, получается 22 мс. Сложно сказать на сколько критично замедление на эту величину. Но я ещё поизучаю матчасть, и возможности для оптимизации библиотеки.

Использовал вот эту библиотечку: https://github.com/manutenfruits/Arduino-SHA-256
По такому примеру:
```
#include "sha256.h"

void setup() {

  Serial.begin(9600);
  uint8_t temp_hash = 0;
  Sha256.init();

  Serial.println(millis());
  for (uint32_t i = 0; i<100; i++){

    Sha256.print(i);
    temp_hash = Sha256.result()[0];

  }

  Serial.println(millis());

}

void loop() {

}
```

Pavel-Y, 2020-09-16:
Использовать 2 бита от SHA-256 довольно расточительно, если функция долгая. При таком множестве возможных значений верификаторов (аж 4 штуки) можно взять любой самый быстрый хэш.

Pavel-Y, 2020-09-16:
Еще вариант - писать в фиксированное место на чипе что-то вроде XOR(hash(mark1), ..., hash(markN). Тогда этот блок в N=30..50 раз быстрее будет изнашиваться. Не знаю, критично это или нет.
Достоинство - возможна обратная совместимость: станции со старой прошивкой будут "фиксированное место" игнорировать (в протоколе есть незанятое место).

Pavel-Y, 2020-09-16:
> Идея хорошая. Нужно проверить, сколько времени займёт вычисление хэша в момент отметки. Если будет долго, можно при инициализации станции один раз вычислить хэш от номера и пароля и держать его в оперативной памяти.

Если "хэш" не зависит от записываемой на чип информации, взлом протокола = написать чуть больше кода, чем для просто записи фейковых отметок на чип.

Сценарий: чип1 ходит по станциям 1..N/2, чип2 от N/2 до N, потом они встречаются и имеют всю информацию для записи произвольных отметок на оба чипа.

Pavel-Y, 2020-09-16:
Из предыдущего комментария следует, что хэш надо вычислять в том числе от UID'a чипа. Хотя если UID перезаписываемый, тоже защита = "злоум-ку писать еще чуть больше кода".

Pavel-Y, 2020-09-16:
Вообще, SFR до сих пор как-то живет безо всякой защиты для перенастройки станций и перезаписи чипов. Видимо, за счёт закрытого протокола и лени*доброты заинтересованных лиц :)

alexandervolikov, 2020-09-16:
Попробовал SHA-1, считает уже 11 мс. В принципе, на мой взгляд, уже не критично для работы системы. Но может, действительно, попробовать поискать что-то менее мощное раз нам только несколько битов нужно.

Ну или, как предложили в телеграмме, вспомнить про защиту от записи, встроенную в чипе.

ЗЫ. Вот тут более актуальная библиотека, с лицензией:  https://github.com/daknuett/cryptosuite2

alexandervolikov, 2020-09-17:
Протестировал защиту, встроенную в чипы Ntag. Работает, настраивается довольно легко и гибко, вполне надежно. Пароль с чипа не выдрать, можно поставить защиту от брут-форса.
На скорость чтения чипа установка пароля не повлияла (я ставил пароль только на запись), а вот скорость записи, закономерно, возросла с 30 до 40 мс на страницу. То есть, разница во все те же 10 мс на отметку.
В чипы Mifare не лез, но подозреваю, что там примерно тоже самое должно получаться.

Плюс встроенной защиты вижу в том, что довольно легко переделать систему без существенного изменения протоколов записи отметки.  Функция авторизации по паролю реализована в библиотеке RC522, существенной доработки кода не требуется. Минусы вижу в усложнении всей процедуры действий с чипами и станциями, жесткой привязке к паролям. Нужно будет следить за чипами и менять пароли на них вместе со сменой паролей на станциях. Либо, например, очищать чипы от пароля при считывании результатов. Продумать всякие варианты по подобию завалявшихся у кого-то после прошлогодних соревнований чипов или станций со старыми паролями.

В целом, склоняюсь к тому, что правильней реализовать встроенную в чипы защиту.

Pavel-Y, 2020-09-17:
> Протестировал защиту, встроенную в чипы Ntag. Работает, настраивается довольно легко и гибко, вполне надежно. Пароль с чипа не выдрать, можно поставить защиту от брут-форса.
> На скорость чтения чипа установка пароля не повлияла (я ставил пароль только на запись), а вот скорость записи, закономерно, возросла с 30 до 40 мс на страницу. То есть, разница во все те же 10 мс на отметку.
> В чипы Mifare не лез, но подозреваю, что там примерно тоже самое должно получаться.

Чипы Mifare Classic всегда используют защиту паролем. Известен пароль по умолчанию, с которым они приходят с фабрики.

vtararin, 2020-11-14:
Может проще писать время и метку станции шифрованные через 3DES паролем станции и номером чипа. Просто, быстро, на другой чип не перенести.

alexandervolikov, 2020-11-14:
>
>
> Может проще писать время и метку станции шифрованные через 3DES паролем станции и номером чипа. Просто, быстро, на другой чип не перенести.

В этом случае теряется часть возможной функциональности - чтобы получить данные с чипа нужен пароль станции. Соответственно, участник сам уже не сможет считать свой чип. В общем-то, может оно и не надо, но зачем урезать функционал.

Pavel-Y, 2020-11-14:
> > Может проще писать время и метку станции шифрованные через 3DES паролем станции и номером чипа. Просто, быстро, на другой чип не перенести.
>
> В этом случае теряется часть возможной функциональности - чтобы получить данные с чипа нужен пароль станции. Соответственно, участник сам уже не сможет считать свой чип. В общем-то, может оно и не надо, но зачем урезать функционал.

А мне идея понравилась. Не вижу юз кейза, когда участнику нужно было бы считать свой чип - своим телефоном?
Все судьи пароль станции знают. Можно исползовать пароль по умолчанию.

Другое дело, что если в чипы уже встроена защита, то логично использовать ее (и не смешить людей заодно).

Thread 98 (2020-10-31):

Разница между кодом SportIduinoPQ, firmware и протоколом в GitHub'e

sportiduino-lite, 2020-10-31:
Код SportIduinoPQ сейчас реализует не протокол, выложенный в этом же репозитории - https://github.com/sportiduino/sportiduino/blob/master/Doc/ru/Card.md , а какой-то другой. Он не описан в явном виде, только в коде SportIduinoPQ.

Тем, кто пишет код не для SportIduinoPQ, а для других программ, нужен чётко описанный логичный протокол.

sportiduino-lite, 2020-10-31:
Например, вот этот код
`    def init_time_card(self, time=datetime.today()):
        """Initialize card for writing time to base station.
        @param time: Time for base station (default current time).
        """
        params = b''
        params += int2byte(time.year - 2000)
        params += int2byte(time.month)
        params += int2byte(time.day)
        params += int2byte(time.hour)
        params += int2byte(time.minute)
        params += int2byte(time.second)`

скорее всего не соответствует протоколу "месяц год-2000 день 0 час минута секунда 0".

А также запись 0 для MifareClassic1k чипа участника в байт [2], где для NTag 0 означает, что чип очищен, а для участников там 3, 5 или 6, создает неконсистентный протокол. Нужно исправить на ненулевое фиксированное значение, например на 8 (используется в другой программе).

sembruk, 2020-11-05:
Значение 0 записывается не только для MifareClassic1k, но и для всех неNTag чипов.
Этот байт используется только в прошивках старее версии 6. Он оставлен для совместимости, и может быть убран в любой момент (кроме значения 255 для мастер-чипа). Использовать его значение о типе чипа и тем более как индикатор очистки чипа в новом софте нельзя!

sembruk, 2020-11-05:
> Код SportIduinoPQ сейчас реализует не протокол, выложенный в этом же репозитории - https://github.com/sportiduino/sportiduino/blob/master/Doc/ru/Card.md , а какой-то другой. Он не описан в явном виде, только в коде SportIduinoPQ.

С одним частным случаем разобрались. Теперь прошу указать на другие несоответсвия описания протокола, и реального поведения.

Closed 2022-01-28.

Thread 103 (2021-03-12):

В описании сборки BS неверно указан звукоизлучатель HC0903A

KrepakVitaly, 2021-03-12:
В описании сборки Base Station неверно указан звукоизлучатель HC0903A -- аналогом TR1205Y является HCM1203A, который сейчас проще найти в терраэлектронике или чипидипе.

Различие в шаге выводов и направлении излучателя, HC0903A имеет меньший шаг, чем монтажные отверстия, и направлен вбок, что мешает качественно залить блок силиконовым компаундом.

sembruk, 2021-03-29:
Спасибо! Исправлено.

Closed 2021-03-29.

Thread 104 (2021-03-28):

Интерграция с MeOS. Реализация приложена.

vtararin, 2021-03-28:
Отправка прочитанных меток в MeOS по TCP/IP . Реализация приложена.

[drive-download-20210328T184201Z-001.zip](https://github.com/sportiduino/sportiduino/files/6217894/drive-download-20210328T184201Z-001.zip)

PS. MeOS работает со станциями  sportiduino как со  sportiden, но после каждого прочитанного чипа дает ошибку.

vtararin, 2021-03-29:
Упс. Не тот проект

Closed 2021-03-29.

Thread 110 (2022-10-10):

Здравствуйте! Научите,пожалуйста, "прошивать".

mrKamanov, 2022-10-10:
Здравствуйте! Научите,пожалуйста, "прошивать".
Здравствуйте, меня зовут Сергей. Пытаюсь повторить проект для детей в школе. Начал проект со сборки базовой станции- спаял.
Но теперь необходимо ее прошить(так написано в инструкции на этом сайте). Скачал версию arduino ide 1.8.7 как на скриншоте в статье, указал пусть к папкам и скопировал файлы hex как написано, внес изменения в файл board.... Но ничего не появляется? нет в списке платы sportiduino( работа встала,не понимаю, что делать). Прошу помощи. Спасибо.

п.с. У меня есть ардуино нано и програматор, но ими ни разу не пользовался.

sembruk, 2022-10-12:
Проверьте файл board.

mrKamanov, 2022-10-12:
Здравствуйте, В конце файла вставил:
##############################################################

sportiduino.name=Sportiduino

sportiduino.build.mcu=atmega328p
sportiduino.build.f_cpu=8000000L
sportiduino.build.board=AVR_SPORTIDUINO
sportiduino.build.core=arduino
sportiduino.build.variant=standard

sportiduino.upload.tool=avrdude
sportiduino.upload.protocol=arduino
sportiduino.upload.maximum_size=32256
sportiduino.upload.maximum_data_size=2048
sportiduino.upload.speed=38400

sportiduino.bootloader.tool=avrdude
sportiduino.bootloader.low_fuses=0xE2
sportiduino.bootloader.high_fuses=0xDE
sportiduino.bootloader.extended_fuses=0xFF
sportiduino.bootloader.unlock_bits=0x3F
sportiduino.bootloader.lock_bits=0x0F

menu.bootloader=Bootloader

sportiduino.menu.bootloader.optiboot=Optiboot 38400
sportiduino.menu.bootloader.optiboot.bootloader.file=optiboot/optiboot8_38400_sportiduino.hex

sportiduino.menu.bootloader.optiboot_led=Optiboot 38400 with LED
sportiduino.menu.bootloader.optiboot_led.bootloader.file=optiboot/optiboot8_38400_sportiduino_led.hex

##############################################################

nano.name=Arduino Nano

nano.upload.tool=avrdude
nano.upload.protocol=arduino

nano.bootloader.tool=avrdude
nano.bootloader.unlock_bits=0x3F
nano.bootloader.lock_bits=0x0F

nano.build.f_cpu=16000000L
nano.build.board=AVR_NANO
nano.build.core=arduino
nano.build.variant=eightanaloginputs

## Arduino Nano w/ ATmega328P (without reset)
## --------------------------
nano.menu.cpu.atmega328noreset=ATmega328P (without reset)

nano.menu.cpu.atmega328noreset.upload.maximum_size=30720
nano.menu.cpu.atmega328noreset.upload.maximum_data_size=2048
nano.menu.cpu.atmega328noreset.upload.speed=38400

nano.menu.cpu.atmega328noreset.bootloader.low_fuses=0xFF
nano.menu.cpu.atmega328noreset.bootloader.high_fuses=0xDA
nano.menu.cpu.atmega328noreset.bootloader.extended_fuses=0xFD
nano.menu.cpu.atmega328noreset.bootloader.file=optiboot/optiboot8_atmega328_38400_without_reset.hex

nano.menu.cpu.atmega328noreset.build.mcu=atmega328p

##############################################################

mrKamanov, 2022-10-12:
после многократной переустановки sportiduino и ATmega328P (без сброса) появились, видимо, проблема с кэшом была какая-то. Вечером попробую загрузить скетч. Спасибо вам за ответ.

mrKamanov, 2022-10-12:
теперь очередная сложность:
при загрузке скетча "выяснилось" что чип на ардуино нано atmel mega 168. ( переставил процессор на ATmega 168- скетч установился, но с надписью "Недостаточно памяти, программа может работать нестабильно.") Скачал программу SportiduinoPQ , запустил, при подключении пишет
"2022-10-12 17:44:54
Подключена станция сопряжения v1.9.0 на порту COM3"

При попытке записать чип:
"Начинаю подготовку чипа участника
Ошибка: Чип не обнаружен"
( у меня их штук 10 белые карточки, 10 синие брелки, и ни один не видит).

Скачал приложение на телефон NFC Tools - оно видит эти чипы , записывает их и читает.
Скачал приложение Sportiduino Lite на телефон -  при попытке записать чип пишет "Ошибка: Transceive failed"

Что я делаю не так? в чем может быть проблема?

sembruk, 2022-10-12:
1. Стоит проверить правильность подключения платы RC522 к Arduino Nano.
2. На Atmega168 никто пока эти прошивки не проверял.
3. Sportiduino Lite не надо использовать. Это стороннее приложение, актуальные версии прошивок в нём не поддерживаются. Вот правильное приложение — https://github.com/sportiduino/sportiduinoapp

mrKamanov, 2022-10-12:
Не помогло, контакты все перепроверил.
Подключена станция сопряжения v1.9.0 на порту COM3

Начинаю читать чип
Ошибка: Нет ответа

Начинаю подготовку чипа участника
Ошибка: Чип не обнаружен

попробовал несколько других rfid-rc522- чип не видят.

попробую поискать ардуино нано с чипом Atmega328

mrKamanov, 2022-10-15:
Да, видимо дело было именно в чипе. Станция заработала чипы теперь видит, светодиод мигает, но нет звукового сигнала. В чем может быть проблема?

sembruk, 2022-10-15:
> Да, видимо дело было именно в чипе.

Может быть, на плате Nano с Atmega168 выводы расположены по-другому?

> нет звукового сигнала.

Можно прозвонить цепь до буззера и проверить его активное сопротивление.

mrKamanov, 2022-10-15:
А вы не подскажите как это осуществить, моих знаний не хватает.

mrKamanov, 2022-10-15:
я имею ввиду какое сопротивление выставить нужно на мультиметре

mrKamanov, 2022-10-15:
поставил на 20к показывает 0.02

sembruk, 2022-10-15:
Сопротивление в норме. Ещё можно проверить пайку резистора на 47 Ом.

mrKamanov, 2022-10-15:
Спасибо за ответ

mrKamanov, 2022-10-15:
Да, помогло, перепаял резистор, еще раз спасибо!!!

Closed 2025-01-27.

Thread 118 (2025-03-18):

Minimum battery voltage

myadzel, 2025-03-18:
To determine whether to sound a low battery signal (during sleep or startup), a minimum voltage check is used. Currently, this value in the base station code is 3.5 and 3.6 V. It must be brought to a single value.

That is why the second value was chosen.

(In the Android application, it is [also 3.6 V](https://github.com/sportiduino/SportiduinoApp/blob/master/app/src/main/java/org/sportiduino/app/sportiduino/State.java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).)

myadzel, 2025-03-31:
Fixed in [another way](https://github.com/sportiduino/sportiduino/commit/e4331a4c5c4f107f5aa284dc84a6df0933cd0263).

Closed 2025-03-31.

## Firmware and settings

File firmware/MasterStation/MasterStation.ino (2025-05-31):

#include <sportiduino.h>
#include "sportidentprotocol.h"

#ifndef HW_VERS
    #define HW_VERS       1
#endif

#define FW_MAJOR_VERS     11
// If FW_MINOR_VERS more than MAX_FW_MINOR_VERS this is beta version HW_VERS.FW_MINOR_VERS.0-beta.X
// where X is (FW_MINOR_VERS - MAX_FW_MINOR_VERS)
#define FW_MINOR_VERS     0


//-----------------------------------------------------------
// HARDWARE

#define BUZZ_PIN        3
#define LED_PIN         4
#define RC522_RST_PIN   9
#define RC522_SS_PIN    10

// Set BUZZER_FREQUENCY by running "make buzzfreq=2500"
#ifndef BUZZER_FREQUENCY
    // or change here
    #define BUZZER_FREQUENCY 4000 // 0 for buzzer with generator
#endif

//-----------------------------------------------------------
// CONST

#define SERIAL_START_BYTE       0xFE

enum Error {
    ERROR_SERIAL          = 0x01,
    ERROR_CARD_WRITE      = 0x02,
    ERROR_CARD_READ       = 0x03,
    ERROR_EEPROM_READ     = 0x04,
    ERROR_CARD_NOT_FOUND  = 0x05,
    ERROR_UNKNOWN_CMD     = 0x06,
    ERROR_BAD_DATASIZE    = 0x07,
    ERROR_BAD_SETTINGS    = 0x08
};

enum Resp {
    RESP_FUNC_BACKUP      = 0x61,
    RESP_FUNC_MARKS       = 0x63,
    RESP_FUNC_RAW_DATA    = 0x65,
    RESP_FUNC_VERSION     = 0x66,
    RESP_FUNC_SETTINGS    = 0x67,
    RESP_FUNC_MODE        = 0x69,
    RESP_FUNC_CARD_TYPE   = 0x70,
    RESP_FUNC_ERROR       = 0x78,
    RESP_FUNC_OK          = 0x79
};

#define EEPROM_CONFIG_ADDR 0x3EE

const uint8_t NTAG213_PAGE4_FACTORY_DATA[] = {0x01, 0x03, 0xa0, 0x0c};
const uint8_t NTAG215_216_PAGE4_FACTORY_DATA[] = {0x03, 0x00, 0xfe, 0x00};

//-----------------------------------------------------------

using SiProto = SportidentProtocol;

struct __attribute__((packed)) Configuration {
    uint8_t antennaGain;
    int8_t timezone; // timezone in 1/4 hours
    // v1.11 and later
    uint32_t ntagAuthPassword;
};

//-----------------------------------------------------------
// FUNCTIONS

inline void beep(uint16_t ms, uint8_t n) { beep_w(LED_PIN, BUZZ_PIN, BUZZER_FREQUENCY, ms, n); }
inline void beepTimeCardOk() { beep_w(LED_PIN, BUZZ_PIN, BUZZER_FREQUENCY, 500, 3, 500); delay(500); beep(1000, 1); }
inline void beepError() { beep(100, 3); }
inline void beepOk() { beep(500, 1); }

// Declatarions for building by Arduino-Makefile
void signalError(uint8_t error);
void handleCmd(uint8_t cmdCode, uint8_t *data, uint8_t dataSize);
void handleSiCmd(uint8_t cmdCode, uint8_t *data, uint8_t dataSize);
void sieDetectCard();
void sieCardRemoved();
void sieCardReadError();
bool sieSendDataBlock(uint8_t blockNumber);
bool sieSendAllDataBlocks(bool shortFormat);

//-----------------------------------------------------------
// VARIABLES
static Configuration config;
static Rfid rfid;
static uint8_t password[3] = {0, 0, 0};
static SerialProtocol serialProto;
static SiProto siProto;
static bool sieMode = true; // Sportident emulation mode (continuos readout)

void setup() {
    pinMode(LED_PIN, OUTPUT);
    pinMode(BUZZ_PIN, OUTPUT);
    pinMode(RC522_RST_PIN, OUTPUT);
    pinMode(RC522_SS_PIN, OUTPUT);
    
    digitalWrite(LED_PIN, LOW);
    digitalWrite(BUZZ_PIN, LOW);
    digitalWrite(RC522_RST_PIN, LOW);

    readConfig((uint8_t*)&config, sizeof(Configuration), EEPROM_CONFIG_ADDR);
    if(config.antennaGain > MAX_ANTENNA_GAIN || config.antennaGain < MIN_ANTENNA_GAIN) {
        config.antennaGain = DEFAULT_ANTENNA_GAIN;
        config.timezone = 0;
        config.ntagAuthPassword = 0xFFFFFFFF;
    }

    rfid.init(RC522_SS_PIN, RC522_RST_PIN, config.antennaGain);
    rfid.setAuthPassword((uint8_t*)&config.ntagAuthPassword);
    serialProto.init(SERIAL_START_BYTE, 38400);

    digitalWrite(LED_PIN, HIGH);
    delay(50);
    digitalWrite(LED_PIN, LOW);
}

void loop() { 
    if(sieMode) {
        rfid.begin(config.antennaGain);
        sieDetectCard();
        rfid.end();
        delay(50);
    }
}

void serialEvent() {
    bool error = false;
    uint8_t cmdCode = 0;
    uint8_t dataSize = 0;

    uint8_t *data = serialProto.read(&error, &cmdCode, &dataSize);
    if(error) {
        signalError(ERROR_SERIAL);
        return;
    }
    if(data) {
        sieMode = false;
        handleCmd(cmdCode, data, dataSize);
        return;
    }
    data = siProto.read(&error, &cmdCode, &dataSize);
    if(error) {
        siProto.error();
        return;
    }
    if(data) {
        sieMode = true;
        handleSiCmd(cmdCode, data, dataSize);
        return;
    }
    serialProto.dropByte();
}

void signalError(uint8_t error) { 
    serialProto.start(RESP_FUNC_ERROR);
    serialProto.add(error);
    serialProto.add((uint8_t)rfid.getCardType());
    serialProto.send();

    beepError();
}

void signalOK(bool beep = true) {
    serialProto.start(RESP_FUNC_OK);
    serialProto.add((uint8_t)rfid.getCardType());
    serialProto.send();

    if(beep) {
        beepOk();
    }
}

uint8_t writeMasterCard(uint8_t masterCode, byte *data = NULL, uint16_t size = 0) {
    if(!rfid.isCardDetected()) {
        return ERROR_CARD_NOT_FOUND;
    }

    byte head[] = {
        0, masterCode, 255, FW_MAJOR_VERS,
        password[0], password[1], password[2], 0
    };

    if(!rfid.cardWrite(CARD_PAGE_INIT, head, sizeof(head))) {
        return ERROR_CARD_WRITE;
    }

    if(data && size > 0) {
        if(!rfid.cardWrite(CARD_PAGE_INIT + 2, data, size)) {
            return ERROR_CARD_WRITE;
        }
    }

    return 0;
}

void funcWriteMasterTime(uint8_t *serialData, uint8_t dataSize) {
    if(dataSize < 6) {
        signalError(ERROR_BAD_DATASIZE);
        return;
    }

    byte data[] = {
        serialData[1], serialData[0], serialData[2], 0,  // month, year, day, 0
        serialData[3], serialData[4], serialData[5], 0   // hour, minute, second, 0
    };

    uint8_t error = writeMasterCard(MASTER_CARD_SET_TIME, data, sizeof(data));

    if(error) {
        signalError(error);
    } else {
        signalOK(false);
        beepTimeCardOk();
    }
}

void funcWriteMasterNum(uint8_t *serialData, uint8_t dataSize) {
    if(dataSize < 1) {
        signalError(ERROR_BAD_DATASIZE);
        return;
    }

    byte data[] = {serialData[0], 0, 0, 0};     // station num
    
    uint8_t error = writeMasterCard(MASTER_CARD_SET_NUMBER, data, sizeof(data));

    if(error) {
        signalError(error);
    } else {
        signalOK();
    }
}

void funcWriteMasterConfig(uint8_t *serialData, uint8_t dataSize) {
    if(dataSize < 6) {
        signalError(ERROR_BAD_DATASIZE);
        return;
    }

    uint8_t error = writeMasterCard(MASTER_CARD_CONFIG, serialData, dataSize);

    if(error) {
        signalError(error);
    } else {
        signalOK();
    }
}

void funcWriteMasterPassword(uint8_t *serialData, uint8_t dataSize) {
    if(dataSize < 3) {
        signalError(ERROR_BAD_DATASIZE);
        return;
    }

    uint8_t error = writeMasterCard(MASTER_CARD_PASSWORD, serialData, dataSize);

    if(error) {
        signalError(error);
    } else {
        signalOK();
    }
}

void funcApplyPassword(uint8_t *serialData, uint8_t dataSize) {
    if(dataSize < 3) {
        signalError(ERROR_BAD_DATASIZE);
        return;
    }
    memcpy(password, serialData, 3);
    signalOK();
}

void funcReadSettings(uint8_t *, uint8_t ) {
    serialProto.start(RESP_FUNC_SETTINGS);
    // Send first 2 bytes of configuration (without ntagAuthPassword)
    serialProto.add((uint8_t*)&config, 2);
    serialProto.send();
}

void funcWriteMasterAuthPassword(uint8_t *serialData, uint8_t dataSize) {
    if(dataSize < 4) {
        signalError(ERROR_BAD_DATASIZE);
        return;
    }

    uint8_t error = writeMasterCard(MASTER_CARD_AUTH_PASSWORD, serialData, dataSize);
    if(error) {
        signalError(error);
    } else {
        signalOK();
    }
}

void funcWriteSettings(uint8_t *serialData, uint8_t dataSize) {
    if(dataSize != sizeof(Configuration) && dataSize != 2 /*old config format*/) {
        signalError(ERROR_BAD_DATASIZE);
        return;
    }
    Configuration *newConfig = (Configuration*)serialData;
    if(newConfig->antennaGain < MIN_ANTENNA_GAIN || newConfig->antennaGain > MAX_ANTENNA_GAIN
        || newConfig->timezone < -12*4 || newConfig->timezone > 14*4) {
        signalError(ERROR_BAD_SETTINGS);
        return;
    }
    memcpy(&config, newConfig, dataSize);
    writeConfig((uint8_t*)&config, sizeof(Configuration), EEPROM_CONFIG_ADDR);
    rfid.setAntennaGain(config.antennaGain);
    rfid.setAuthPassword((uint8_t*)&config.ntagAuthPassword);
    signalOK();
}

bool clearCard() {
    uint8_t maxPage = rfid.getCardMaxPage();

    // Clear card from last page
    uint8_t c = 0;
    for(uint8_t page = maxPage - 3; page > CARD_PAGE_INIT_TIME; page -= 4) {
        if(c % 10 == 0) {
            digitalWrite(LED_PIN, HIGH);
        } else if(c % 5 == 0) {
            digitalWrite(LED_PIN, LOW);
        }
        ++c;

        if(!rfid.cardErase4Pages(page)) {
            return false;
        }
    }

    uint8_t tail = (maxPage - CARD_PAGE_INIT_TIME)%4;
    // Erase the tail if necessary
    if (tail > 0) {
        // Erase the remaining pages individually
        for (uint8_t i = tail; i > 0; --i) {
            uint8_t pageToErase = CARD_PAGE_INIT_TIME + i;

            // Attempt to erase a single page
            if (!rfid.cardPageErase(pageToErase)) {
                return false;
            }
        }
    }

    return true;
}

void funcInitParticipantCard(uint8_t *serialData, uint8_t dataSize) {
    if(dataSize < 14) {
        signalError(ERROR_BAD_DATASIZE);
        return;
    }
    if(!rfid.isCardDetected()) {
        signalError(ERROR_CARD_NOT_FOUND);
        return;
    }

    bool writeProtection = false;
    bool readProtection = false;
    if(dataSize > 14) {
        uint8_t flags = serialData[14];
        writeProtection = (flags & 1);
        readProtection = (flags & 2);
    }
    if(!rfid.cardEnableDisableAuthentication(writeProtection, readProtection)) {
        signalError(ERROR_CARD_WRITE);
        return;
    }

    digitalWrite(LED_PIN, HIGH);

    if(!clearCard()) {
        signalError(ERROR_CARD_WRITE);
        digitalWrite(LED_PIN, LOW);
        return;
    }

    digitalWrite(LED_PIN, LOW);

    byte data[] = {
        serialData[0], serialData[1], 0, FW_MAJOR_VERS,                 // card num, 0, fw version
        serialData[2], serialData[3], serialData[4], serialData[5],     // unixtime
        serialData[6], serialData[7], serialData[8], serialData[9],     // page6
        serialData[10], serialData[11], serialData[12], serialData[13]  // page7
    };

    if(!rfid.cardWrite(CARD_PAGE_INIT, data, sizeof(data))) {
        signalError(ERROR_CARD_WRITE);
        return;
    }

    signalOK();
}

void funcWritePages6_7(uint8_t *serialData, uint8_t dataSize) {
    if(dataSize < 8) {
        signalError(ERROR_BAD_DATASIZE);
        return;
    }

    if(!rfid.isCardDetected()) {
        signalError(ERROR_CARD_NOT_FOUND);
        return;
    }

    if(!rfid.cardWrite(CARD_PAGE_INFO1, serialData, 8)) {
        signalError(ERROR_CARD_WRITE);
        return;
    }

    signalOK();
}

void funcWriteMasterBackup(uint8_t*, uint8_t) {
    uint8_t error = writeMasterCard(MASTER_CARD_READ_BACKUP);

    if(error) {
        signalError(error);
    } else {
        signalOK();
    }
}

void funcWriteGetInfoCard(uint8_t*, uint8_t) {
    uint8_t error = writeMasterCard(MASTER_CARD_STATE);

    if(error) {
        signalError(error);
    } else {
        signalOK();
    }
}

void funcWriteMasterSleep(uint8_t *serialData, uint8_t dataSize) {
    if(dataSize < 6) {
        signalError(ERROR_BAD_DATASIZE);
        return;
    }
    // wakeup time
    byte data[] = {
        serialData[1], serialData[0], serialData[2], 0,
        serialData[3], serialData[4], serialData[5], 0
    };

    uint8_t error = writeMasterCard(MASTER_CARD_SLEEP, data, sizeof(data));

    if(error) {
        signalError(error);
    } else {
        signalOK();
    }
}

void funcReadBackup(uint8_t*, uint8_t) {
    if(!rfid.isCardDetected()) {
        signalError(ERROR_CARD_NOT_FOUND);
        return;
    }

    byte pageData[] = {0,0,0,0};
    if(!rfid.cardPageRead(CARD_PAGE_INIT, pageData)) {
        signalError(ERROR_CARD_READ);
        return;
    }

    serialProto.start(RESP_FUNC_BACKUP);
    serialProto.add(pageData[0]);   // add station number

    uint8_t maxPage = rfid.getCardMaxPage();
    if(pageData[3] == 1) { // old format with timestamps
        serialProto.add(0xff); // flag: have timestamps
        uint16_t timeHigh12bits = 0;
        uint32_t initTime = 0;
        for(uint8_t page = CARD_PAGE_INFO1; page <= maxPage; ++page) {
            if(!rfid.cardPageRead(page, pageData)) {
                signalError(ERROR_CARD_READ);
                return;
            }

            if(timeHigh12bits == 0) {
                timeHigh12bits = pageData[0] << 8;
                timeHigh12bits |= pageData[1] & 0xf0;
                initTime = ((uint32_t)pageData[1] & 0x0f) << 16;
                initTime |= (uint32_t)pageData[2] << 8;
                initTime |= pageData[3];
                continue;
            }

            uint16_t cardNum = pageData[0] << 8;
            cardNum |= pageData[1] & 0xff;
            cardNum >>= 4;

            if(cardNum == 0) {
                continue;
            }
            serialProto.add(pageData[0] >> 4); // card number first byte
            serialProto.add(pageData[0] << 4 | pageData[1] >> 4); // card number second byte
            uint32_t punchTime = ((uint32_t)pageData[1] & 0x0f) << 16;
            punchTime |= (uint32_t)pageData[2] << 8;
            punchTime |= pageData[3];
            uint16_t currentTimeHigh12bits = timeHigh12bits;
            if(punchTime < initTime) {
                currentTimeHigh12bits += 0x10;
            }
            serialProto.add(currentTimeHigh12bits >> 8);
            serialProto.add((currentTimeHigh12bits&0xf0) | (pageData[1]&0x0f));
            serialProto.add(pageData[2]);
            serialProto.add(pageData[3]);
        }
    } else if(pageData[3] >= 10) { // new format (FW version 10 or greater)
        serialProto.add(0xff); // flag: have timestamps
        uint16_t lastTimeHigh16bits = 0;
        for(uint8_t page = CARD_PAGE_INFO1; page <= maxPage; ++page) {
            if(!rfid.cardPageRead(page, pageData)) {
                signalError(ERROR_CARD_READ);
                return;
            }

            if(pageData[0] == 0 && pageData[1] == 0) {
                uint16_t timeHigh16bits = byteArrayToUint32(pageData) & 0xffff;
                if(timeHigh16bits > 0 && timeHigh16bits != lastTimeHigh16bits) {
                    lastTimeHigh16bits = timeHigh16bits;
                }
                continue;
            }
            serialProto.add(pageData[0]); // card number first byte
            serialProto.add(pageData[1]); // card number second byte
            serialProto.add(lastTimeHigh16bits >> 8);
            serialProto.add(lastTimeHigh16bits & 0xff);
            serialProto.add(pageData[2]); // timestamps
            serialProto.add(pageData[3]); // timestamps
        }
    }

    serialProto.send();
    beepOk();
}

void funcReadCard(uint8_t*, uint8_t) {
    // Don't signal error to prevent discontiniuos beep in the poll mode
    if(!rfid.isCardDetected()) {
        return;
    }

    byte pageData[] = {0,0,0,0};
    if(!rfid.cardPageRead(CARD_PAGE_INIT, pageData)) {
        signalError(ERROR_CARD_READ);
        return;
    }

    if(pageData[2] == 0xff) {
        return;
    }

    uint8_t *cardNumPointer = pageData;
    if(memcmp(pageData, NTAG213_PAGE4_FACTORY_DATA, 4) == 0
            || memcmp(pageData, NTAG215_216_PAGE4_FACTORY_DATA, 4) == 0) {
        // Reset card number
        cardNumPointer[0] = 0;
        cardNumPointer[1] = 0;
    }

    serialProto.start(RESP_FUNC_MARKS);
    // Output the card number
    serialProto.add(cardNumPointer[0]);
    serialProto.add(cardNumPointer[1]);

    if(!rfid.cardPageRead(CARD_PAGE_INIT_TIME, pageData)) {
        signalError(ERROR_CARD_READ);
        return;
    }
    uint8_t timeHighByte = pageData[0];
    uint32_t initTime = pageData[1];
    initTime <<= 8;
    initTime |= pageData[2];
    initTime <<= 8;
    initTime |= pageData[3];

    if(!rfid.cardPageRead(CARD_PAGE_INFO1, pageData)) {
        signalError(ERROR_CARD_READ);
        return;
    }
    // Output page 6
    for(uint8_t i = 0; i < 4; i++) {
        serialProto.add(pageData[i]);
    }

    if(!rfid.cardPageRead(CARD_PAGE_INFO2, pageData)) {
        signalError(ERROR_CARD_READ);
        return;
    }
    // Output page 7
    for(uint8_t i = 0; i < 4; i++) {
        serialProto.add(pageData[i]);
    }

    uint8_t maxPage = rfid.getCardMaxPage();

    for(uint8_t page = CARD_PAGE_START; page <= maxPage; ++page) {
        if(!rfid.cardPageRead(page, pageData)) {
            signalError(ERROR_CARD_READ);
            return;
        }

        if(pageIsEmpty(pageData)) { // no new punches
            break;
        }
        // Output station number
        serialProto.add(pageData[0]);

        uint32_t punchTime = pageData[1];
        punchTime <<= 8;
        punchTime |= pageData[2];
        punchTime <<= 8;
        punchTime |= pageData[3];

        // for example, we have init time 0x00FFFFFF
        // all mark time will be 0x01xxxxxx
        // in this case we have to add 1 to timeHighByte
        if(punchTime < initTime) {
            serialProto.add(timeHighByte + 1);
        } else {
            serialProto.add(timeHighByte);
        }
        // Output time
        serialProto.add(pageData[1]);
        serialProto.add(pageData[2]);
        serialProto.add(pageData[3]);
    }

    serialProto.send();
}

void funcReadRawCard(uint8_t* serialData, uint8_t dataSize) {
    uint8_t error = ERROR_CARD_NOT_FOUND;
    byte pageData[] = {0,0,0,0};

    if(rfid.isCardDetected()) {
        error = ERROR_CARD_READ;
        uint8_t firstPage = CARD_PAGE_INIT;
        uint8_t lastPage = rfid.getCardMaxPage();

        if (dataSize > 1) {
            firstPage = serialData[0];
            uint8_t numPages = serialData[1];
            numPages = max(numPages, 1);
            lastPage = min(firstPage + numPages - 1, lastPage);
        }

        serialProto.start(RESP_FUNC_RAW_DATA);
        for(uint8_t page = firstPage; page <= lastPage; page++) {
            if(!rfid.cardPageRead(page, pageData)) {
                error = ERROR_CARD_READ;
                break;
            }
            error = 0;
            serialProto.add(page);
            for(uint8_t i = 0; i < 4; i++) {
                serialProto.add(pageData[i]);
            }
        }   
    }

    if(error) {
        signalError(error);
    } else {
        serialProto.send();
        beepOk();
    }
}

void funcReadCardType(uint8_t*, uint8_t) {
    serialProto.start(RESP_FUNC_CARD_TYPE);
    serialProto.add((uint8_t)rfid.getCardType());
    serialProto.send();
}

void funcGetVersion(uint8_t*, uint8_t) {
    serialProto.start(RESP_FUNC_VERSION);

    serialProto.add(HW_VERS);
    serialProto.add(FW_MAJOR_VERS);
    serialProto.add(FW_MINOR_VERS);

    serialProto.send();
}

void callRfidFunction(void (*func)(uint8_t*, uint8_t), uint8_t *data, uint8_t dataSize) {
    rfid.begin();
    func(data, dataSize);
    rfid.end();
}

void handleCmd(uint8_t cmdCode, uint8_t *data, uint8_t dataSize) {
    switch(cmdCode) {
        case 0x41:
            callRfidFunction(funcWriteMasterTime, data, dataSize);
            break;
        case 0x42:
            callRfidFunction(funcWriteMasterNum, data, dataSize);
            break;
        case 0x43:
            callRfidFunction(funcWriteMasterPassword, data, dataSize);
            break;
        case 0x5A:
            callRfidFunction(funcWriteMasterConfig, data, dataSize);
            break;
        case 0x5B:
            callRfidFunction(funcWriteMasterAuthPassword, data, dataSize);
            break;
        case 0x44:
            callRfidFunction(funcInitParticipantCard, data, dataSize);
            break;
        case 0x45:
            callRfidFunction(funcWritePages6_7, data, dataSize);
            break;
        case 0x46:
            funcGetVersion(data, dataSize);
            break;
        case 0x47:
            callRfidFunction(funcWriteMasterBackup, data, dataSize);
            break;
        case 0x48:
            callRfidFunction(funcReadBackup, data, dataSize);
            break;
        case 0x4A:
            funcWriteSettings(data, dataSize);
            break;
        case 0x4B:
            callRfidFunction(funcReadCard, data, dataSize);
            break;
        case 0x4C:
            callRfidFunction(funcReadRawCard, data, dataSize);
            break;
        case 0x4D:
            funcReadSettings(data, dataSize);
            break;
        case 0x4E:
            callRfidFunction(funcWriteMasterSleep, data, dataSize);
            break;
        case 0x4F:
            funcApplyPassword(data, dataSize);
            break;
        case 0x50:
            callRfidFunction(funcWriteGetInfoCard, data, dataSize);
            break;
        case 0x51:
            callRfidFunction(funcReadCardType, data, dataSize);
            break;
        case 0x58:
            beepError();
            break;
        case 0x59:
            beepOk();
            break;
        default:
            signalError(ERROR_UNKNOWN_CMD);
            break;
    }
}
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

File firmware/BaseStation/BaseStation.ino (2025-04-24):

// To compile this project with Arduino IDE change sketchbook to <Project>/firmware

#include <Wire.h>
#include <ds3231.h>
#include <Adafruit_SleepyDog.h>
#include <PinChangeInterrupt.h>
#include <sportiduino.h>

// Uncomment line below to compile in DEBUG mode
//#define DEBUG
// You can also set debug mode by running "make debug=1 ..."

// Set PCB version by running "make pcbv=3 ..."
#ifndef HW_VERS
    // or change here
    #define HW_VERS     3
#endif
#define FW_MAJOR_VERS   11
// If FW_MINOR_VERS more than MAX_FW_MINOR_VERS this is beta version HW_VERS.FW_MAJOR_VERS.0-beta.X
// where X = (FW_MINOR_VERS - MAX_FW_MINOR_VERS)
#define FW_MINOR_VERS   0

// If PCB has reed switch and you don't want RC522 powered every 25 secs uncomment option bellow 
//#define NO_POLL_CARDS_IN_SLEEP_MODE
// You can also run "make nopoll=1 ..."

// Uncomment for BS check battery every 10 min in Sleep Mode and beep SOS if voltage < 3.3V
//#define CHECK_BATTERY_IN_SLEEP
// You can also run "make check_battery=1 ..."

//-------------------------------------------------------------------
// HARDWARE

// Set BUZZER_FREQUENCY by running "make buzzfreq=2500 ..."
#ifndef BUZZER_FREQUENCY
    // or change here
    #define BUZZER_FREQUENCY 4000 // or 0 for buzzer with generator
#endif

#define BUZ           3
#define LED           4

#define RC522_RST     9
#define RC522_SS      10

#define UART_RX       0
#define UART_TX       1

#define SDA           A4
#define SCL           A5

// If you added battery voltage measurement circuit, reed switch or I2C EEPROM to your PCB v1 or v2
// you only need define appropriate pins like for PCB v3

#if HW_VERS == 1
    #define DS3231_VCC     5
    #define DS3231_RST     A0
    #define RC522_IRQ      6

    //#define ADC_IN         pin_number
    //#define ADC_ENABLE     pin_number

    //#define I2C_EEPROM_VCC pin_number
    //#define REED_SWITCH    pin_number
#elif HW_VERS == 2
    #define DS3231_VCC     A1
    #define DS3231_IRQ     A3
    #define DS3231_32K     5 // not used, reserved for future
    #define DS3231_RST     2

    #define RC522_IRQ      6

    #define ADC_IN         A0
    #define ADC_ENABLE     A1

    //#define ADC_IN         pin_number
    //#define ADC_ENABLE     pin_number

    //#define I2C_EEPROM_VCC pin_number
    //#define REED_SWITCH    pin_number
#elif HW_VERS == 3
    #define DS3231_VCC     A3
    #define DS3231_IRQ     A2
    #define DS3231_32K     5 // not used, reserved for future
    #define DS3231_RST     2

    #define RC522_IRQ      8

    #define ADC_IN         A0
    #define ADC_ENABLE     A1

    #define I2C_EEPROM_VCC 6
    #define REED_SWITCH    7
#else
    #error Unknown HW_VERS
#endif

//-------------------------------------------------------------------

struct __attribute__((packed)) Configuration {
    uint8_t stationNumber;
// Active Mode duration
//    (xxx) - 2^(bit2:bit0) hours in Active Mode (1 - 32 hours)
//    (110) - always be in Active Mode (check card in 0.25 second period)
//    (111) - always be in Wait Mode (check card in 1 second period)
    uint8_t activeModeDuration: 3;
    uint8_t checkNoPunchesBeforeStart: 1; // Check no punches on a participant card at start station
    uint8_t checkCardInitTime: 1; // Check init time of a participant card
    uint8_t autosleep: 1; // Go to Sleep Mode after AUTOSLEEP_TIME milliseconds in Wait Mode
    uint8_t oldFastPunchMode: 1; // Deprecated
    uint8_t enableFastPunchForCard: 1; // Enable fast punch for card when clear
    uint8_t antennaGain: 3;
    uint8_t _reserved2: 5;
    uint8_t password[3];
};

uint8_t ntagAuthPassword[4];


#ifdef I2C_EEPROM_VCC
    #define USE_I2C_EEPROM
    #define I2C_EEPROM_ADDRESS  0x50
#endif

#define UNKNOWN_PIN 0xFF

// 194.18 days after card initialization or clearing the new punches will have incorrect time
const uint32_t CARD_EXPIRE_TIME = 180UL*24*3600;  // 180 days

#define EEPROM_CONFIG_ADDR  0x3EE
#define EEPROM_AUTH_PASSWORD_ADDR  0x3E2  // EEPROM_CONFIG_ADDR - sizeof(Configuration)*3

#define LOG_RECORD_SIZE 8  // bytes
const uint16_t I2C_EEPROM_MEMORY_SIZE = (uint16_t)32*1024;  // bytes
const uint16_t MAX_LOG_RECORDS = I2C_EEPROM_MEMORY_SIZE/LOG_RECORD_SIZE;

// Poll time in active mode (milliseconds)
#define MODE_ACTIVE_CARD_CHECK_PERIOD     250
// Poll time in wait mode (milliseconds)
#define MODE_WAIT_CARD_CHECK_PERIOD       1000
// Poll time in sleep mode (milliseconds)
#define MODE_SLEEP_CARD_CHECK_PERIOD      25000

const uint32_t AUTOSLEEP_TIME = 48UL*3600*1000;

#define MODE_ACTIVE   0
#define MODE_WAIT     1
#define MODE_SLEEP    2

// It would be better to have MODE_WAIT as default
// If station resets on competition and default 
// mode is SLEEP in this case the participant can't
// do punch fast
#define DEFAULT_MODE                    MODE_WAIT
#define DEFAULT_STATION_NUM             CHECK_STATION_NUM
#define DEFAULT_ACTIVE_MODE_DURATION    1  // 2 hours
#define DEFAULT_ALARM_TIME              946684800  // 2000-01-01 00:00:00

#define SETTINGS_ALWAYS_ACTIVE          0x06
#define SETTINGS_ALWAYS_WAIT            0x07

#define SERIAL_MSG_START            0xFA

#define SERIAL_FUNC_READ_INFO       0xF0
#define SERIAL_FUNC_WRITE_SETTINGS  0xF1
#define SERIAL_FUNC_ERASE_LOG       0xF2

#define SERIAL_RESP_STATUS          0x01
#define SERIAL_RESP_INFO            0x02

#define SERIAL_OK                   0x00
#define SERIAL_ERROR_CRC            0x01
#define SERIAL_ERROR_UNKNOWN_FUNC   0x02
#define SERIAL_ERROR_SIZE           0x03
#define SERIAL_ERROR_PWD            0x04

//--------------------------------------------------------------------
// VARIABLES  

// work time in milliseconds
uint32_t workTimer = 0;
uint16_t sleepCount = 0;
Configuration config;
uint8_t mode = DEFAULT_MODE;
uint16_t activeModePollPeriod = MODE_ACTIVE_CARD_CHECK_PERIOD;
Rfid rfid;
SerialProtocol serialProto;
// date/time
static ts t;
uint32_t alarmTimestamp = DEFAULT_ALARM_TIME;
// This flag is true when it's DS3231 interrupt
uint8_t rtcAlarmFlag = 0;
uint8_t reedSwitchFlag = 0;
// It's true if there are data from UART in sleep mode
uint8_t serialWakeupFlag = 0;
uint16_t logNextRecordAddress = 0;

//--------------------------------------------------------------------
// FUNCTIONS

// the third parameter should be the frequency of your buzzer if you solded the buzzer without a generator else 0
inline void beep(uint16_t ms, uint8_t n) { beep_w(LED, BUZ, BUZZER_FREQUENCY, ms, n); }

inline void beepOk()                    { beep(500, 1); }

inline void beepRtcError()              { beep(80, 2); }
inline void beepTimeError()             { beep(100, 3); }
inline void beepPassError()             { beep(100, 4); }

inline void beepLowBattery()            { beep(100, 5); }
inline void beepBatteryOk()             { beep(1000, 1); }

inline void beepCardCheckOk()           { beepOk(); }

inline void beepCardPunchWritten()        { beepOk(); }
inline void beepCardPunchAlreadyWritten() { beep(250, 2); }
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

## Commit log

2018-02-15 Fix typos and shft
    [BaseStation.ino, MasterStation.ino]
2018-02-18 Fix typos and formating
    [BaseStation.ino]
2018-06-06 fix version at master station
    [MasterStation.ino]
2018-06-20 fix mifare test station
    [BaseStation.ino]
2018-12-15 1. Исправил ошибку постоянной перезагрузки станции при попытке первой настройки после её сборки 2. Добавил настройку для пьезоизлучателя
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2018-12-16 Добавил печатную плату и схему для базовой станции
    [sportduino-base.kicad_pcb, sportduino-base.sch]
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2018-12-17 Немного улучшил трассировку ПП: добавил переходных отверстий GND для увеличения области металлизации
    [sportduino-base.kicad_pcb]
2018-12-17 Добавил 3д-модель базовой станции и модель подложки под модуль RC522 для печати на 3д-принтере
    [sportduino-base-rc522-substrate.stl]
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2018-12-17 Исправил собственную ошибку в схеме: 32кГц надо подключать на счетный вход МК
    [sportduino-base.kicad_pcb, sportduino-base.sch]
2018-12-17 Вернул в репозиторий старую версию схемы и платы для поддержки уже собранных станций
2018-12-17 Добавил 3д-модель корпуса для судейской станции
    [sportduino-master-bottom-lid.stl, sportduino-master-top-lid.stl]
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2018-12-21 1. Исправил ошибку в функции findNewPage 2. Перекомпилировал старую прошивку с правильной библиотекой DS3231
2018-12-21 Исправил ошибку в записи отметок в лог и обработке мастер-чипа для чтения лога
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2018-12-23 1. В схеме подключил выход RST микросхемы DS3231 к MCU 2. Для выхода 32 кГц добавил внешний подтягивающий резистор, потому что с внутренним сильно срезаются фронты
    [sportduino-base.kicad_pcb, sportduino-base.sch]
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2018-12-30 1. Добавил команду изменения текущего пароля для мастер-станции 2. В функцию возврата версии мастер-станции добавил возврат текущего пароля и настроек
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2019-01-09 1. Изменил разъём X4 для подключения преобразователя USB-to-TTL под китайский на FT232RL 2. Поправил диаметры отверстий и размеры контактных площадок
    [sportduino-base.kicad_pcb, sportduino-base.sch]
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2019-01-10 Поправил дизайн наклеек, потому что круг для отметки был расположен в плохом месте и чипы не срабатывали при прикладывании в цент
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2019-07-01 исправление опечаток
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2019-07-10 1. Изменил шрифт на Arial в дизайне наклеек, чтобы можно было сделать экспорт в Corel без потерь 2. Добавил набор наклеек для рогейна
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2019-07-11 Уменьшил толщину пластиковой подложки под модуль RC522 до 1 мм
    [sportduino-base-rc522-substrate.stl]
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2019-07-24 1. Разработал библиотеку sportiduino 2. Зарефакторил прошивку для мастер станции и базовой станции на библиотеку sportiduino 3. Удалил все hex, чтобы народ компилил вручную 4. Добавил hex бутлоадера 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
2019-08-26 Исправил работу мастер-станции с программой SportOrg (Issue#56)
    [MasterStation.ino]
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2019-11-21 Исправил алгоритм проверки уровня заряда батареи. Было при каждом проходе цикла включалось/выключалось АЦП. Теперь АЦП включается 1 раз на процесс измерения заряда
    [BaseStation.ino]
2019-11-25 Решение issue #61 для платы v1, но не работает для платы v2, т.к. в плате v2 аппаратная ошибка
    [BaseStation.ino]
2019-12-02 Схема и плата версия 3: 1. Исправил подключение питания для DS3231 2. UART и SPI для программирования вынес на один разъём 3. Добавил цепь для измерения напряжения на батарее 4. Добавил тестовых точе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
    [sportduino-base.kicad_pcb, sportduino-base.sch]
2019-12-05 Fix project directories structure
    [sportduino-base-rc522-substrate.stl, sportduino-base.kicad_pcb, sportduino-base.sch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]
2019-12-05 Fix documentation Now we change sketchbook dir instead manual libs copying
    [BaseStation.ino]
2019-12-05 Docs: fix path to boards.txt file
    [BaseStation.ino]
2019-12-06 Убрал с печатной платы области металлизации, иначе они экранируют антенну
    [sportduino-base.kicad_pcb]
2019-12-09 Revert my small bad change
    [BaseStation.ino]
2019-12-10 Fix non-blocking wire directory Now we don't need copying our Wire to Arduino install tree
2019-12-10 Base station scheme: added 24LC256 memory
    [sportduino-base.kicad_pcb, sportduino-base.sch]
2019-12-11 Fix for issue #61. Tested on PCB v1
    [BaseStation.ino]
2019-12-11 Updated v3m PCB
    [sportduino-base.kicad_pcb, sportduino-base.sch]
2019-12-12 Updated PCB
    [sportduino-base.kicad_pcb]
2019-12-13 PCB v3m: added 3d view and fixed edge line width
    [sportduino-base.kicad_pcb]
2020-01-14 Base station PCB: updated assembly footprints positions
    [sportduino-base.kicad_pcb]
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2020-01-18 Fix power consumption bag in sleepmode for v3 pcb
    [BaseStation.ino]
2020-01-20 Fix power consumption issue for v2 (#61)
    [BaseStation.ino]
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2020-01-29 Fix problem with ext EEPROM reading and improvements
    [BaseStation.ino]
2020-01-29 MS: fix dump card reading There were bad timestamps in output
    [MasterStation.ino]
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2020-02-06 PCB: merge v3m into v3, remove RC filter from RST line
    [sportduino-base.kicad_pcb, sportduino-base.sch]
2020-02-06 PCB: increased pads length for DS3231
    [sportduino-base.kicad_pcb, sportduino-base.sch]
2020-02-07 Disable RFID module to prevent bad impact on voltage measurements Added 'port' option in makefiles
    [BaseStation.ino]
2020-02-07 Updated BS PCB
    [sportduino-base.kicad_pcb]
2020-02-10 PCB: move battery voltage measurement circuit and remove 3V3-GND loops
    [sportduino-base.kicad_pcb, sportduino-base.sch]
2020-02-10 Updated hardware images (scheme, pcb) and links
    [sportiduino-base.kicad_pcb, sportiduino-base.sch]
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2020-02-22 Prevent continuous waking up by UART RX pin undefined state
    [BaseStation.ino]
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2020-02-26 MS: set RFID antenna gain by serial and store one in EEPROM
2020-02-27 Debug mode and buzzer frequency as additional make options
    [BaseStation.ino]
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2020-03-03 Fix mistakes in PCB gerber files
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2020-03-06 Fix punches backup reading
    [BaseStation.ino, MasterStation.ino]
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2020-03-12 Fix led blinking at writing backup card
    [BaseStation.ino]
2020-03-16 Исправил ошибку питания в плате v2, удалил области металлизации на печатке, в прошивке изменил пин DS3231_VCC для v2
    [sportduino-base.kicad_pcb, sportduino-base.sch]
2020-03-16 Поправил ссылки в документации на схему исправленной платы v2
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2020-03-17 POLL_CARDS_IN_SLEEP_MODE option Power on RC522 every 25 secs as in old firmware if the option enabled (default)
2020-03-18 Fix wake up process "make nopoll" defines NO_POLL_CARDS_IN_SLEEP_MODE option. Tested with PCB v3
    [BaseStation.ino]
2020-03-22 MS: fix participant card reading (fix #89)
    [MasterStation.ino]
2020-03-23 BS PCB v3 2020-03-23: removed dual diode VD2 from measurement circuit
    [sportiduino-base.kicad_pcb, sportiduino-base.sch]
2020-04-01 Ru docs update
    [master-card.ods]
2020-04-05 Fix bag in card init time checking
    [BaseStation.ino]
2020-04-24 Sportident legacy protocol: fix
    [sportidentprotocol.cpp]
2020-04-25 Added hex file of optiboot for MS without DTR This bootloader work 2 secs after power on and doesn't work at external reset https://github.com/sembruk/optiboot/tree/active-only-2s-after-poweron
2020-04-28 SI emulation: beep error if read card data failed
    [MasterStation.ino]
2020-04-30 SI emulation: fix local time calculation
    [MasterStation.ino, sportidentprotocol.cpp]
2020-11-05 [#99] MS: fix card initialization (clear from last page)
    [BaseStation.ino, MasterStation.ino]
2020-11-08 MS: turn on LED during erasing card Change default buzzer frequency to 4000 Hz
    [MasterStation.ino]
2020-11-08 Clear Station: write card number to EEPROM Changed default buzzer frequency to 4 kHz
    [BaseStation.ino]
2020-11-17 BS: writing backup card impovement Если backup уже записывался на этот чип (номер станции на чипе == номер станции) и чип заполнен полностью, берём номер последнего чипа из последней страницы и переп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
2020-11-25 Change version to v3.8.0 and docs update
    [master-card.ods]
2021-04-12 Autosleep option in Config and disable UART interrupts If the option is set and BS in Wating Mode more 48 h go to Sleep Mode
2021-04-15 BS: check battery every 25 sec in Sleep Mode if battery voltage < 3600 beep SOS
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2021-05-14 v3b PCB (2021-01-01) * TP4056 with leds for Li-ion battery charging * RC522 mini or RC522 boards * Change length to 73 mm
    [sportiduino-base.kicad_pcb, sportiduino-base.sch]
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2021-12-12 MS v1.8.1: fix beep pause for time card
    [MasterStation.ino]
2022-01-04 MS: fix SI Card6 reading emulation
    [MasterStation.ino, sportidentprotocol.cpp]
2022-01-17 MS: fix SI Card6 reading emulation (SI legacy protocol, Winorient 2014)
    [MasterStation.ino, sportidentprotocol.cpp]
2022-01-17 Docs update
    [master-card.ods]
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2022-02-03 Added Base station box (3D model)
    [sportduino-base-rc522-substrate.stl, sportduino-base.FCStd, sportiduino-base.FCStd]
2022-03-22 MS: fix SPORTident card reading
    [MasterStation.ino]
2022-03-22 MS: fix SPORTident card reading (legacy mode)
    [MasterStation.ino]
2022-03-27 Wake up from Sleep mode if RTC alarm doesn't work
    [BaseStation.ino]
2022-03-29 BS fw: new formatn of EEPROM log Write full card number (2 bytes) and full timestamp (4 bytes) in I2C EEPROM
2022-04-02 Fix unclear response at erase log commant
    [BaseStation.ino]
2022-04-03 Fix wakeup condition check
    [BaseStation.ino]
2022-06-15 BS fw: fix building for PCB v1 and v2
    [BaseStation.ino]
2022-06-16 docs: BS variants
    [sportiduino-base-bom.csv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]
2022-09-29 Updated BOM and pos files for BS PCB assembly
    [sportiduino-base-bom.csv, sportiduino-base.kicad_pcb, sportiduino-base.sch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]
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2023-09-17 Rename dir: Images -> img
    [master-card.ods]
2024-01-18 Check RTC if DS3231 not connected or broken beep 2 times at startup
    [BaseStation.ino]
2024-01-18 Check RTC on waking up from sleep (beep 2 times if error)
    [BaseStation.ino]
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2025-01-27 Remove unused function arguments, fix build warnings (Issue #112)
    [BaseStation.ino]
2025-01-28 Don't reset alarm time
    [BaseStation.ino]
2025-01-28 Beep 3 times (time error) at startup and wake-up if year < 2025
    [BaseStation.ino]
2025-02-08 Master station v1.9.1: fix reading a card as empty in the sportident emulation mode
    [MasterStation.ino]
2025-02-16 Fix reading card in sleep mode (#115)
    [BaseStation.ino]
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2025-04-03 Fix docs (#120)
    * Fix docs
    * Fix docs
    [sportiduino-base-bom.csv, sportiduino-base.kicad_pcb, sportiduino-base.sch]
2025-04-08 docs: added passwodrd and auth password master cards
    [master-card.ods]
2025-05-31 fix(ms): write settings debug
    [MasterStation.ino]
2025-12-05 pcb: 1x10 programming connector
    [sportiduino-base-v4.kicad_pcb, sportiduino-base-v4.kicad_sch, sportiduino-base-v4.sch]
2025-12-29 New PCB (wip)
    [sportiduino-base-v4.kicad_pcb, sportiduino-base-v4.kicad_sch]
2025-12-29 pcb wip
    [sportiduino-base-v4.kicad_pcb]
2026-01-29 pcb v3bm update
    [sportiduino-base-v3bm-B_Cu.gbl, sportiduino-base-v3bm-B_Mask.gbs, sportiduino-base-v3bm-B_Paste.gbp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]
